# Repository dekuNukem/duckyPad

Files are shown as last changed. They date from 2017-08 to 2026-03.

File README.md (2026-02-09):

# duckyPad: Do-It-All Mechanical Macropad

[Get duckyPad](https://dekunukem.github.io/duckyPad-Pro/doc/landing.html) | [Official Discord](https://discord.gg/4sJCBx5) | [Getting Started](getting_started.md) | [Table of Contents](#table-of-contents)

----

duckyPad is a 15-key **mechanical macropad** for power users who demand **advanced macro scripting and customisation** beyond the shackles of QMK/VIA.

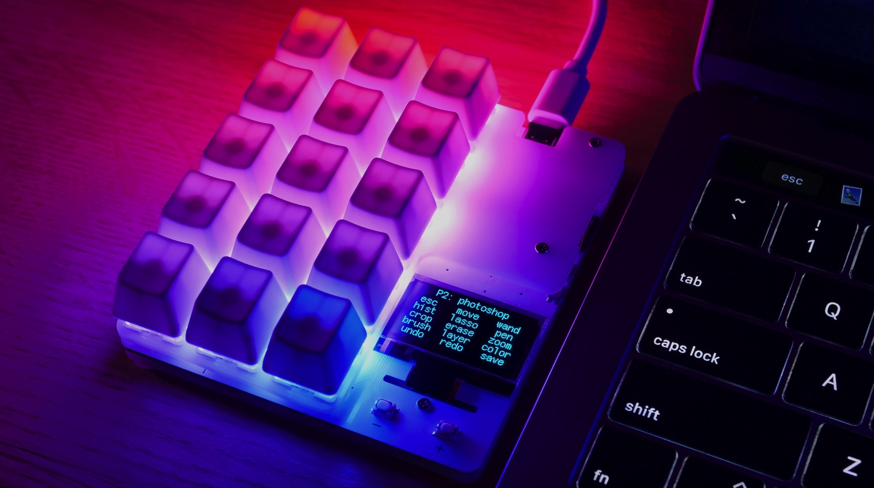
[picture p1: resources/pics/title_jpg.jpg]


Using a [turing-complete scripting language](https://dekunukem.github.io/duckyPad-Pro/doc/duckyscript_info.html), you can automate **any keyboard/mouse input** you want, from **simple combos** to **full-blown programs**.

## Get One

duckyPad was successfully [funded on Kickstarter](https://www.kickstarter.com/projects/dekunukem/duckypad-do-it-all-mechanical-macropad) thanks to the [amazing backers!](kickstarter_backers.md)

* Now Available [on my Tindie Store](https://www.tindie.com/products/dekunukem/duckypad-do-it-all-mechanical-macropad/)

## Highlights

duckyPad has all the basics:

* **Hot-swap**
* Per-key RGB
* Fully **open-source**

But also unique features **not seen anywhere else**:

* Custom **[duckyScript](https://dekunukem.github.io/duckyPad-Pro/doc/duckyscript_info.html)** engine, **NOT QMK/VIA**.
* **Longer and more complex** macros
* **OLED** screen
* **32 profiles** of 15 keys, 480 macros total.
* [Automatic profile switching](https://github.com/dekuNukem/duckyPad-profile-autoswitcher) based on active window.
* microSD storage, move between devices with ease.
* No proprietary drivers, works out-of-box.



## duckyScript vs QMK/VIA

duckyPad uses **duckyScript**, originally designed for [USB Rubber Ducky](https://shop.hak5.org/products/usb-rubber-ducky-deluxe).

Compared to QMK/VIA, you get:

* **Much Longer Macros**
	* [Entire Bee Movie](resources/beemovie.txt) in one macro? Yes please!
	* Up to 480 macros

* **Turing-Complete Scripting**
	* Variables, conditions, loops, functions, and more.
	* Executed on [32-bit Bytecode VM](https://duckypad.github.io/DuckStack/)
	* With **Scratch** and **Non-volatile Memory**

* **Advanced Interactions**
	* Reading Buttons
	* Print to OLED screen
	* Change RGB Color

* **SD Card Storage**
	* Fast Configuration / Backup / Deployment
	* No sketchy drivers or apps
	* No recompiling

While QMK/VIA are great for regular keyboards, they are rather limited at input automations.

duckyScript is a no-brainer for **power users** with more demanding scripting needs.

## 🆕 duckyPad Pro

duckyPad Pro is an updated model with:

* Rotary Encoders
* More Keys
* Bluetooth
* Bigger Display
* More Script Storage
* Expansion Module

👉👉👉 [Purchase Link](https://www.tindie.com/products/37399/) | [More Info](https://dekunukem.github.io/duckyPad-Pro/)

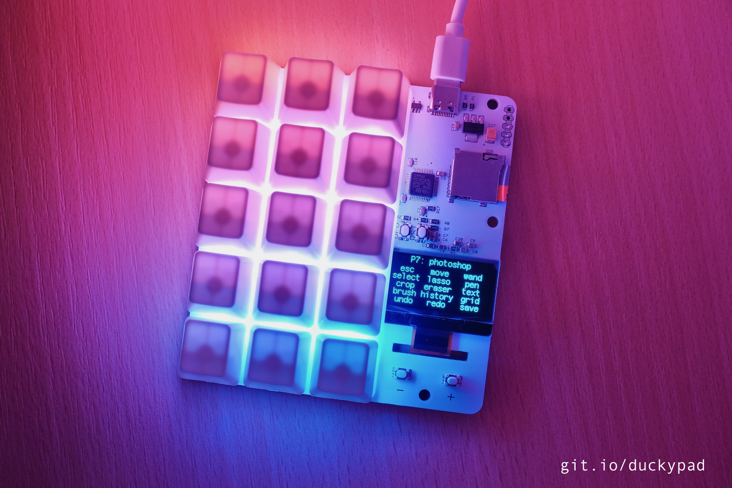
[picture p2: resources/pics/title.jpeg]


## Discord Community

Feel free to join our [Official Discord](https://discord.gg/4sJCBx5) for discussions, questions, sharing scripts, and latest updates!

## How It Works / Showcase

* Create up to **32 profiles**, one for each application.

* Assign up to **15 keys** per profile

* Names are shown on OLED screen

* Write a **duckyScript** for each key

### Easy Start

* **duckyScript** is a language for automating inputs

	* At simplest, you just tell it **what key to press!**

* Such as **key combos** of your favorite app

`CTRL a` , `CTRL +`, etc.



### Up a Notch

* Once familiar, you can write **longer multi-line macros** to further speed up everyday task.

* Such as **filling forms** and typing **boilerplate text** with one keypress.

```
STRING Michael Scott
TAB
STRING United States
ENTER
STRING 5705550100
TAB
STRING michael.scott@dundermifflin.com
TAB
```


Or a simple mouse jiggler:

```
WHILE TRUE
	MOUSE_MOVE $_RANDOM_INT $_RANDOM_INT
	DELAY 100
END_WHILE
```

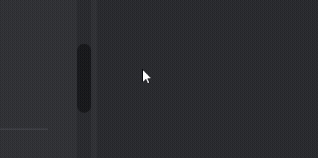
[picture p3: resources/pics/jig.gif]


### Full Potential

* Going all-out, duckyScript is a **Turing-Complete** **general-purpose** language.
* You can use it to:
	* Read Buttons
	* Write to OLED screen
	* Change RGB colors
	* Perform operations with **32-bit variables**, **conditions**, **loops**, **function call**s, and more!
* Write ultra-specific macros for your exact needs

```
RGB_SET 1 128 0 255

OLED_PRINT You are in a maze
OLED_PRINT of twisty little passages

VAR choice = _READKEY

IF choice == 1
    OLED_CURSOR 0 10
    OLED_PRINT It is a dead end.
    OLED_PRINT Something moves
    OLED_PRINT behind you.
END_IF
```

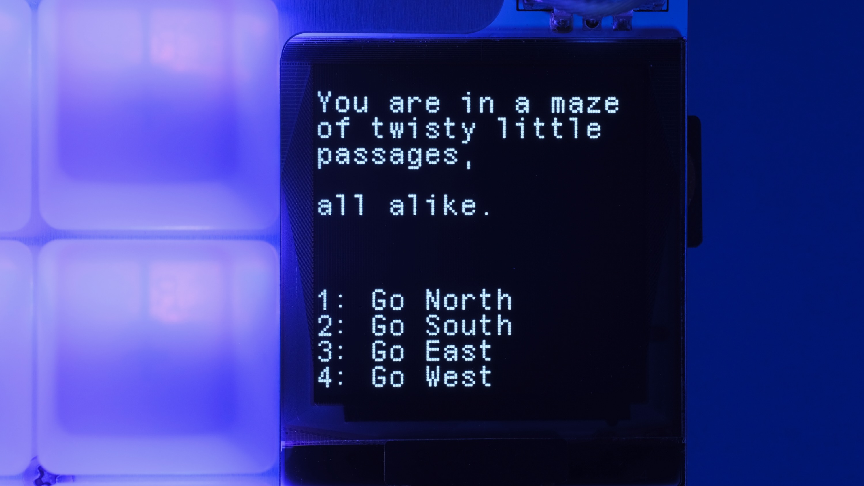
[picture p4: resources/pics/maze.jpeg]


### Hackerman

* Of course, by automating HID inputs, you can take over an entire computer with the push of a button!



* This is known as [BadUSB attack](https://arstechnica.com/information-technology/2014/07/this-thumbdrive-hacks-computers-badusb-exploit-makes-devices-turn-evil/), and was the original purpose of [USB Rubber Ducky](https://shop.hak5.org/products/usb-rubber-ducky-deluxe).

---------

### Nothing Like It

* From **simple shortcuts** to **full-blown programs**, duckyScript can easily achieve what was impossible on QMK/VIA.

* Each macro can contain over **50,000 characters**

* Store **480 macros** in total

* Executed on custom [virtual stack machine](https://duckypad.github.io/DuckStack/)

## Features

### Switches & Keycaps

duckyPad is compatible with Cherry MX-style mechanical switches (3 or 5-pin).

By default, duckyPad comes with blank translucent ABS R4 keycaps:

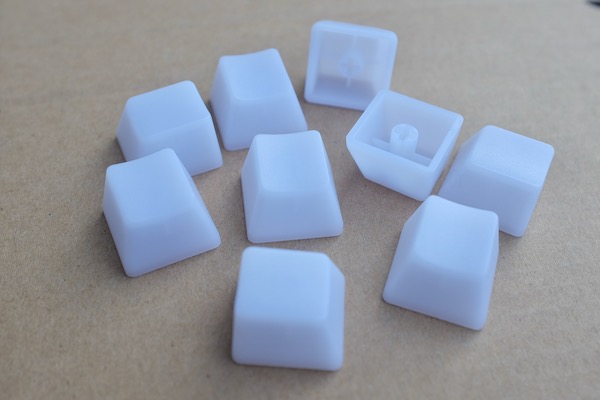
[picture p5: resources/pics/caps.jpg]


You can use your own as well.

### Hot-swap Sockets

duckyPad supports hot-swapping with Kailh sockets.

You can install/remove the switches by hand, **`no soldering needed`**.

### Per-key RGB backlight

Each key on duckyPad has its own RGB backlight. User-configurable colour & brightness.

### OLED screen

duckyPad has an OLED screen. It displays current **`profile and key names`**, so you know what each key does at a glance.

* 128x128
* 1.3 inch
* High contrast with true black
* Burn-in Prevention

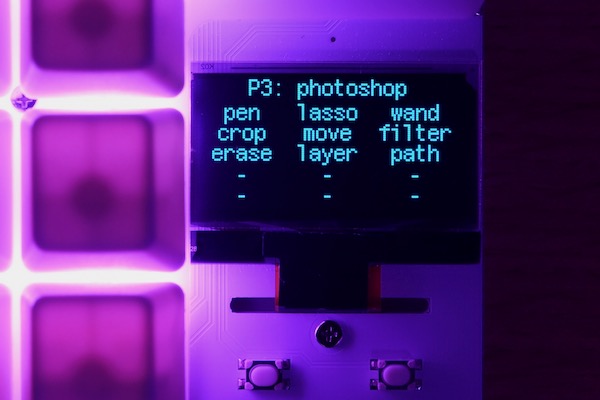
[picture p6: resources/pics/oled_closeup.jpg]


### Companion App

[Use the open-source configurator](https://github.com/duckyPad/duckyPad-Configurator) to set up your duckyPad Pro.

* Windows | Mac | Linux
* No account / subscription needed
* No data collection / telemetry

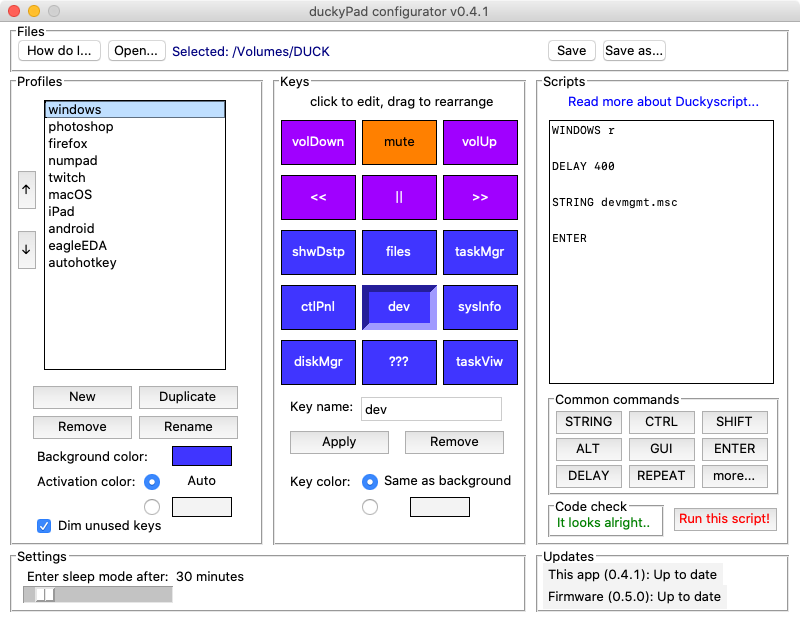
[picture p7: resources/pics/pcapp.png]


## Profile Auto-switching

* [Automatically jump to the appropriate profile](https://github.com/dekuNukem/duckyPad-profile-autoswitcher)
* Based on **current active window**

### USB-C and Device Compatibility

duckyPad uses USB-C connector for maximum device compatibility.

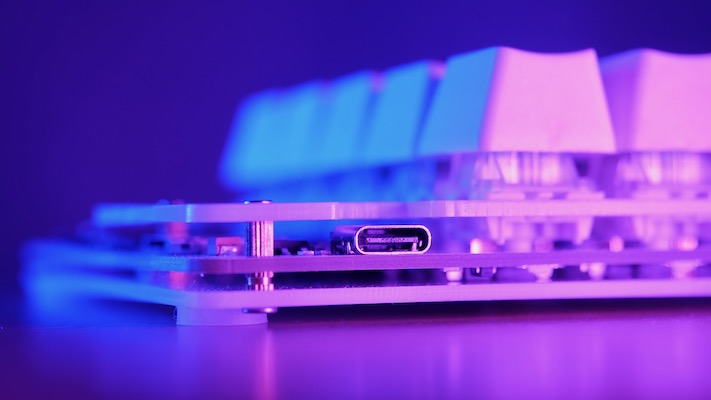
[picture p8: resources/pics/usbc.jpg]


You can use duckyPad out-of-box on pretty much anything that supports USB keyboards, **`no driver needed`**. Examples include:

* PC
* Mac
* Linux
* Raspberry Pi
* iPhone / iPad
* Android phones and tablets
* Chromebooks
* Game consoles

duckyPad’s firmware can also be [easily updated via USB-C](firmware_updates_and_version_history.md) for new features and bug fixes.

### Keyboard Layouts

duckyPad supports multiple keyboard layouts:

* English (US)
* English (UK)
* French
* Belgium
* German
* Dvorak
* ...and more [user-created](keymap_instructions.md) layouts!

### Dimensions

[Click me](pcb/plates) for vector files of front and back plates.

[Click me](resources/pics/dimensions.png) for dimensions drawings.

## Getting Started

Please see [the instruction manual](./getting_started.md) on how to use your duckyPad.

## I Want One!

duckyPad is [now available on Tindie.](https://www.tindie.com/products/21984)

Also consider [joining our discord](https://discord.gg/4sJCBx5) for latest updates and discussions.

## Table of Contents

[Main page](README.md)

[Getting Started Guide](getting_started.md)

[Kit Assembly Guide](kit_assembly_guide.md)

[Using duckyScript](https://dekunukem.github.io/duckyPad-Pro/doc/duckyscript_info.html)

[Common issues / Troubleshooting](troubleshooting.md)

[Firmware Updates and Version History](firmware_updates_and_version_history.md)

[Make Your Own Keymap](./keymap_instructions.md)

[Build a duckyPad Yourself](build_it_yourself.md)

[Kickstarter Backer Acknowledgments](kickstarter_backers.md)

## Questions or Comments?

Please feel free to [open an issue](https://github.com/dekuNukem/duckypad/issues), ask in the [official duckyPad discord](https://discord.gg/4sJCBx5), DM me on discord `dekuNukem#6998`, or email `dekuNukem`@`gmail`.`com` for inquires.

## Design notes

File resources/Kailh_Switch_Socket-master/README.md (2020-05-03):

# Kailh_Switch_Socket
An EAGLE library for the Kailh Switch Socket, allowing you to change your Cherry MX or clone switch from your keyboard without the need of desoldering it.

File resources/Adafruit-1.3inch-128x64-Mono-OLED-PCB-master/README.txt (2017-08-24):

This is the PCB for the Adafruit 128x64 I2C/SPI 1.3" OLED breakout board
Format is EagleCAD schematic and board layout

For more details, check out the product page at

-----> http://www.adafruit.com/products/938

Adafruit invests time and resources providing this open source design, 
please support Adafruit and open-source hardware by purchasing 
products from Adafruit!

Designed by Adafruit Industries.  
Creative Commons Attribution, Share-Alike license, check license.txt for more information
All text above must be included in any redistribution

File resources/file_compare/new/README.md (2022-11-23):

## duckyPad Sample Profiles

To use in duckyPad, copy all the folders here to the root of a FAT32-formatted SD card.

See [this guide](https://github.com/dekuNukem/duckyPad/blob/master/getting_started.md) for more details.

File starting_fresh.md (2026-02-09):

# Starting Fresh with duckyPad (2020)

[Get duckyPad](https://dekunukem.github.io/duckyPad-Pro/doc/landing.html) | [Official Discord](https://discord.gg/4sJCBx5) | [Getting Started](getting_started.md) | [Table of Contents](#table-of-contents)

----

Since its launch in 2020, the original duckyPad has seen several major updates with new features and bug fixes.

This guide shows how to do a **clean upgrade** to the latest version.

## Check Your Duck

This guide is for the **original duckyPad**

* Released in 2020
* Has 15 Keys

## Back up SD Card

* Pop out the SD Card
* Mount on your computer with a card reader
* Copy everything off as-is

## Prepare SD Card

* Format the card in `FAT32`

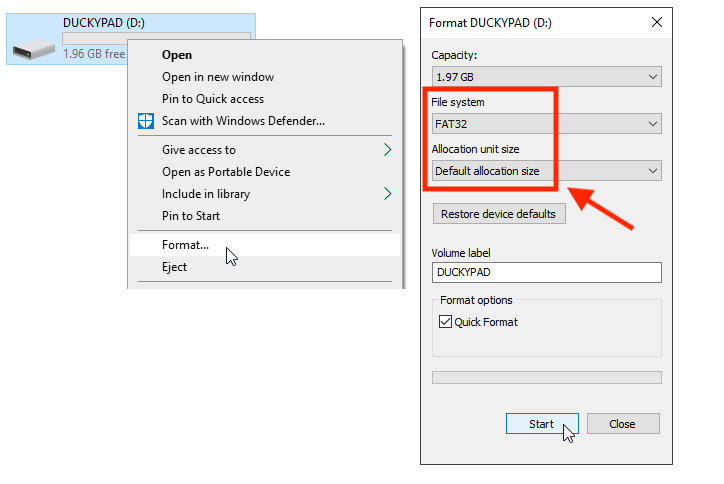
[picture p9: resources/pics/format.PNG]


* Download the [sample profiles](https://github.com/dekuNukem/duckyPad/raw/master/sample_profiles.zip) 

* Unzip and copy everything to the **root of your SD card**:

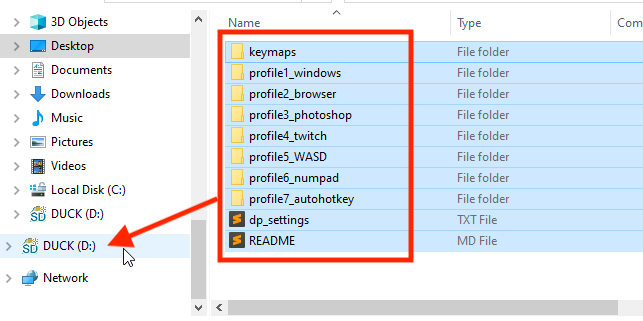
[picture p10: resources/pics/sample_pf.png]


## FW / SW Updates

* Don't touch the SD card for now

* [Follow this guide](https://dekunukem.github.io/duckyPad/firmware_updates_and_version_history.html) to update your duckyPad to latest firmware.

* [Also download the latest configurator](https://github.com/duckyPad/duckyPad-Configurator/releases/latest)

## Try It Out!

* Unmount the SD Card

* Pop it back in duckyPad

* Follow [the latest user guide](https://dekunukem.github.io/duckyPad/getting_started.html) to start using duckyPad again!

## Restore Backup

* If it works with the default sample profiles, you can try to restore the backup.
* Pop out SD card, mount on PC.
* Do another format, copy the backups back.
* Eject, put card back in duckyPad.
* **Load then save again** using the latest configurator.
	* This updates the files on the card
* Try it out!

## Deprecated Commands

If syntax errors pops up, it's likely due to the following changes:

* `HOLD` and `EMUK` command are deprecated
	* Use `KEYDOWN` and `KEYUP` in `on_press` and `on_release` instead.

* [Read more about duckyScript](https://dekunukem.github.io/duckyPad-Pro/doc/duckyscript_info.html)

## How'd It Go?

* If it works, congrats!

* Still wonky? Feel free to ...

	* [Open an issue](https://github.com/dekuNukem/duckypad/issues)
	* Ask in the [official duckyPad discord](https://discord.gg/4sJCBx5)
	* Email `dekuNukem`@`gmail`.`com` .

----

## Table of Contents

[Main page](README.md)

[Getting Started Guide](getting_started.md)

[Kit Assembly Guide](kit_assembly_guide.md)

[Using duckyScript](https://dekunukem.github.io/duckyPad-Pro/doc/duckyscript_info.html)

[Common issues / Troubleshooting](troubleshooting.md)

[Firmware Updates and Version History](firmware_updates_and_version_history.md)

[Make Your Own Keymap](./keymap_instructions.md)

[Build a duckyPad Yourself](build_it_yourself.md)

[Kickstarter Backer Acknowledgments](kickstarter_backers.md)

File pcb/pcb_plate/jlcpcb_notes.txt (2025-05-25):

when making alu PCB:

File top layer is substrate
File bottom layer is bare aluminum

may meed to mirror the design so the correct side is alu

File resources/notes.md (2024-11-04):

http://hackaday.com/2017/05/31/malduino-elite/

15+3+3+4+2+2+1

interrupt add to event queue
main loop get rid of queue item

tangentbord

TODO: TEST 5V LEVEL TRANSLATION OF 74LV125

oh shit the switches might be upside down

card_present low when card is inserted

need to copy hid.c and 2 functions in ff.c

cache profile filename and key filename during load profile

save last profile number to sd card
each key has its own color?

pin 7 should connect to GND
pin 11 BS1 should be high with a resistor
pin 13 15 to GND
add pullup on I2C lines
reset pulled low with resistor

dont forget to add idwg back after everything's done
delay 100ms then reset when card_present changes
tin the under side of the oled ribbon cable

looks like all the probroems were from inconsistent connection between ribbon cable and pcb, tin the pcb thinly as well as the ribbon cable before soldering, use plenty of flux
line up the holes on the pcb with the holes on the ribbon cable, use a small pcb to hold it in place, like exixe 12

i seemlingly solved the ribbon cable connection issue by using low temp solder to wet the underside contacts, remains to be seen how it holds up

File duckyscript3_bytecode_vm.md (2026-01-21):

# duckyScript 3 Bytecode Instruction Set

[Get duckyPad](https://dekunukem.github.io/duckyPad-Pro/doc/landing.html) | [Official Discord](https://discord.gg/4sJCBx5) | [Getting Started](getting_started.md) | [Table of Contents](#table-of-contents)

----
## ⚠️This Page Has Moved!⚠️

👉👉👉👉 [Click Me to See the New Page!](https://dekunukem.github.io/duckyPad-Pro/doc/bytecode_vm.html)

## Table of Contents

[Main page](README.md)

[Getting Started Guide](getting_started.md)

[Kit Assembly Guide](kit_assembly_guide.md)

[Using duckyScript](https://dekunukem.github.io/duckyPad-Pro/doc/duckyscript_info.html)

[Common issues / Troubleshooting](troubleshooting.md)

[Firmware Updates and Version History](firmware_updates_and_version_history.md)

[Make Your Own Keymap](./keymap_instructions.md)

[Build a duckyPad Yourself](build_it_yourself.md)

[Kickstarter Backer Acknowledgments](kickstarter_backers.md)

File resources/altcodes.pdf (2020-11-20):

# ALT CODES REFERENCE SHEET

# Free Download from www.UsefulShortcuts.com (http://www.usefulshortcuts.com/alt-codes)

### Hold down the "Alt" key then enter the code on the numeric keypad with Num Lock on

IM | Numbers | Greek | Currency | ?s and !s | Letters with Accents
Alt 1 | ☺ | Alt 48 - 57 | 0 - 9 | Alt 224 | α | Alt 0164 | ¤ | Alt 33 | ! | Uppercase Lowercase
Alt 2 | ☻ | Basic Operators | Alt 225 | ß | Alt 156 | £ | Alt 19 | ‼ | Alt 0192 À Alt 0224 à
Alt 3 | ♥ | Alt 43 | + | Alt 226 | Γ | Alt 0128 | € | Alt 173 | ¡ | Alt 0193 Á Alt 0225 á
Alt 11 | ♂ | Alt 45 | - | Alt 235 | δ | Alt 36 | $ | Alt 63 | ? | Alt 0194 Â Alt 0226 â
Alt 12 | ♀ | Alt 0215 | × | Alt 238 | ε | Alt 155 | ¢ | Alt 168 | ¿ | Alt 0195 Ã Alt 0227 ã
Alt 13 | ♪ | Alt 0247 | ÷ | Alt 233 | Θ | Alt 157 | ¥ | Brackets | Alt 0196 Ä Alt 0228 ä
Alt 14 | ♫ | Pers | Alt 227 | π | Alt 158 | ₧ | Alt 40 | ( | Alt 0199 Ç Alt 0231 ç
IP | Alt 37 | % | Alt 230 | µ | Alt 159 | ƒ | Alt 41 | ) | Alt 0200 È Alt 0232 è
Alt 0169 | © | Alt 0137 | ‰ | Alt 228 | Σ | Accents | Alt 91 | [ | Alt 0201 É Alt 0233 é
Alt 169 | ® | Bracketing | Alt 229 | σ | Alt 0180 | ´ | Alt 93 | ] | Alt 0202 Ê Alt 0234 ê
Alt 0153 | ™ | Alt Code Symbol | Alt 231 | τ | Alt 0184 | ¸ | Alt 123 | { | Alt 0203 Ë Alt 0235 ë
Filled Arrows | Alt 40 | ( | Alt 232 | Φ | Web Marketing (http://www.profitablewebprojects.com/) | Alt 125 | } | Alt 0204 | Ì | Alt 0236 | ì
Alt 16 | ► | Alt 41 | ) | Alt 237 | φ | by (http://www.profitablewebprojects.com/) | | Editing | | Alt 0205 | Í | Alt 0237 | í
Alt 17 | ◄ | Plus or Minus | Alt 234 | Ω | www.pwp1.com (http://www.profitablewebprojects.com/) | Alt 28 | ∟ | Alt 0206 | Ï | Alt 0238 | î
Alt 254 | ■ | Alt 241 | ± | | | Drawing | | Alt 21 | § | Alt 0207 | Ï | Alt 0239 | ï
Alt 30 | ▲ | Fractions | | Alt 176 | ░ | Alt 200 | ╚ | Alt 20 | ¶ | Alt 165 | Ñ | Alt 164 | ñ
Alt 31 | ▼ | Alt 47 | / | Alt 177 | ▒ | Alt 201 | ╔ | Alt 0134 | † | Alt 0210 Ò Alt 0242 ò
Line Arrows | Alt 0188 | ¼ | Alt 178 | ▓ | Alt 202 | ╩ | Alt 0135 | ‡ | Alt 0211 Ó Alt 0243 ó
Alt 23 | ↨ | Alt 0189 | ½ | Alt 179 | │ | Alt 203 | ╦ | Quotes | Alt 0212 Ô Alt 0244 ô
Alt 24 | ↑ | Alt 0190 | ¾ | Alt 180 | ┤ | Alt 204 | ╠ | Alt 34 | " | Alt 0213 Õ Alt 0245 õ
Alt 25 | ↓ | Alt 46 | . | Alt 181 | ╡ | Alt 205 | ═ | Alt 0139 | ‹ | Alt 0214 Ö Alt 0246 ö
Alt 26 | → | Equality | Alt 182 | ╢ | Alt 206 | ╬ | Alt 0155 | › | Alt 0138 Š Alt 0154 š
Alt 27 | ← | Alt 240 | ≡ | Alt 183 | ╖ | Alt 207 | ╧ | Alt 0145 | ‘ | Alt 0218 Ú Alt 0249 ú
Bullets | Alt 61 | = | Alt 184 | ╕ | Alt 208 | ╨ | Alt 0146 | ’ | Alt 0219 Û Alt 0250 û
Alt 3 | ♥ | Alt 247 | ≈ | Alt 185 | ╣ | Alt 209 | ╤ | Alt 0147 | “ | Alt 0220 Ü Alt 0251 ü
Alt 4 | ♦ | Inequality | Alt 186 | ║ | Alt 210 | ╥ | Alt 0148 | ” | Alt 0217 Ù Alt 0252 ù
Alt 5 | ♣ | Alt 60 | < | Alt 187 | ╗ | Alt 211 | ╙ | Alt 174 | « | Alt 0221 Ý Alt 0253 ý
Alt 6 | ♠ | Alt 62 | > | Alt 188 | ╝ | Alt 212 | ╘ | Alt 175 | » | Alt 0159 Ÿ Alt 0255 ÿ
Alt 7 | • | Alt 242 | ≥ | Alt 189 | ╜ | Alt 213 | ╒ | Alt 0130 | ‘ | Alt 0142 Ž Alt 0158 ž
Alt 8 | ◘ | Alt 243 | ≤ | Alt 190 | ╛ | Alt 214 | ╓ | Alt 0132 | „ | "Extra" Letters
Alt 9 | ○ | Powers | Alt 191 | ┐ | Alt 215 | ╫ | Abbrevs. | Uppercase Lowercase
Alt 10 | ◙ | Alt 251 | √ | Alt 192 | └ | Alt 216 | ╪ | Alt 39 | ' | Alt 0229 å Alt 0197 Å
Alt 11 | ♂ | Alt 252 | ⁿ | Alt 193 | ┴ | Alt 217 | ┘ | Alt 96 | ` | Alt 0140 Œ Alt 0156 œ
Alt 12 | ♀ | Alt 0185 | ¹ | Alt 194 | ┬ | Alt 218 | ┌ | Alt 38 | & | Alt 0254 þ Alt 0222 Þ
Alt 13 | ♪ | Alt 0178 | ² | Alt 195 | ├ | Alt 219 | █ | Alt 64 | @ | Alt 0216 Ø Alt 0248 ø
Alt 14 | ♫ | Alt 0179 | ³ | Alt 196 | ─ | Alt 220 | ▄ | Alt 0198 Æ Alt 0230 æ
Alt 16 | ► | Angles/Trig | Alt 197 | ┼ | Alt 221 | ▌ | Alt 164 | ñ | Alt 165 | Ñ
Alt 17 | ◄ | Alt 227 | π | Alt 198 | ╞ | Alt 222 | ▐ | Alt 0223 ß
Alt 254 | ■ | Alt 248 | ° | Alt 199 | ╟ | Alt 223 | ▀ | Alt 0208 Ð Alt 0240 ð
Alt 30 | ▲ | General Maths | General Punctuation | Coding
Alt 31 | ▼ | Alt 35 | # | Alt 58 | : | Alt 0133 | … | Alt 45 | - | Alt 0166 | ¦ | Alt 92 | \
Alt 23 | ↨ | Alt 236 | ∞ | Alt 59 | ; | Alt 95 | _ | Alt 0151 | — | Alt 40 | ( | Alt 35 | #
Alt 24 | ↑ | Alt 230 | µ | Alt 44 | , | Alt 0175 | ¯ | Alt 22 | ▬ | Alt 41 | ) | Alt 40 | (
Alt 25 | ↓ | Alt 228 | Σ | Alt 46 | . | Alt 124 | | | Alt 42 | * | Alt 94 | ^ | Alt 41 | )
Alt 26 | → | Alt 239 | ∩ | Alt 32 | | Alt 126 | ~ | Alt 47 | / | Alt 60 | < | Alt 64 | @
Alt 27 | ← | | | Alt 255 | | Alt 0168 | ¨ | Alt 92 | \ | Alt 62 | > | Alt 91 | [
Alt 0129 Box | Cardinals | Miscellaneous | Alt 61 | = | Alt 93 | ]
Alt 15 | ☼ | Alt 166 | ª | Alt 65 - 90 | | A to Z | | Alt 249 | · | Alt 42 | * | Alt 123 | {
127 | ⌂ | Alt 167 | º | Alt 97 - 122 | a to z | Alt 250 | · | Alt 47 | / | Alt 125 | }
Alt 18 | ↕ | Interpunct | Alt 244 | ⌠ | Alt 170 | ¬ | Copyright ©2006
Tim Woolfson (http://www.timwoolfson.com/) Alt 29 | ↔ | Alt 0183 | · | Alt 245 | ⌡

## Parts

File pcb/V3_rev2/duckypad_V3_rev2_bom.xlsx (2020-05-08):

Qty | Value | Device | Parts
4 | 1uF | 0805 Capacitor | C3, C4, C6, C28
3 | 2.2uF | 0805 Capacitor | C5, C7, C8
4 | 5.1K | 0805 Resistor | R1, R7, R8, R9
4 | 10K | 0805 Resistor | R2, R4, R5, R17
1 | 47uF | 1210 Tantalum Capacitor | C27
1 |  | 74LVC1G08 | IC3
20 | 100nF | 0805 Capacitor | C1, C2, C9, C10, C11, C12, C13, C14, C15, C16, C17, C18, C19, C20, C21, C22, C23, C24, C25, C29
4 |  | Tactile Switch | SW1, SW2, SW3, SW4
1 | 560K | 0805 Resistor | R3
15 |  | CherryMX-style Key Switch | S1, S2, S3, S4, S5, S6, S7, S8, S9, S10, S11, S12, S13, S14, S15
1 | 3.3V | 1117 Regulator | IC2
1 |  | STM32F072C8T6 | IC1
1 |  | MicroSD Sard Holder | SD1
1 |  | 30 pin FPC Connecter for OLED, Upper Contact | U1
1 |  | USB-C Connector 16Pin | U2
15 |  | SK6812 MINI-E reverse mount RGB LED | LED1, LED2, LED3, LED4, LED5, LED6, LED7, LED8, LED9, LED10, LED11, LED12, LED13, LED14, LED15
15 |  | Kailh Hot-swap Sockets

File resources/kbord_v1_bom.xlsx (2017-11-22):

Part | Value | Device | Package | Description | Link
C1 | 0.1uF | CAP0805 | 0805 | Capacitor
C2 | 0.1uF | CAP0805 | 0805 | Capacitor
C3 | 1uF | CAP0805 | 0805 | Capacitor
C4 | 1uF | CAP0805 | 0805 | Capacitor
C5 | 2.2uF | CAP0805 | 0805 | Capacitor
C6 | 1uF | CAP0805 | 0805 | Capacitor
C7 | 1uF | CAP0805 | 0805 | Capacitor
C8 | 2.2uF | CAP0805 | 0805 | Capacitor
C9 | 0.1uF | CAP0805 | 0805 | Capacitor
C10 | 0.1uF | CAP0805 | 0805 | Capacitor
C11 | 0.1uF | CAP0805 | 0805 | Capacitor
C12 | 0.1uF | CAP0805 | 0805 | Capacitor
C13 | 0.1uF | CAP0805 | 0805 | Capacitor
C14 | 0.1uF | CAP0805 | 0805 | Capacitor
C15 | 0.1uF | CAP0805 | 0805 | Capacitor
C16 | 0.1uF | CAP0805 | 0805 | Capacitor
C17 | 0.1uF | CAP0805 | 0805 | Capacitor
C18 | 0.1uF | CAP0805 | 0805 | Capacitor
C19 | 0.1uF | CAP0805 | 0805 | Capacitor
C20 | 0.1uF | CAP0805 | 0805 | Capacitor
C21 | 0.1uF | CAP0805 | 0805 | Capacitor
C22 | 0.1uF | CAP0805 | 0805 | Capacitor
C23 | 0.1uF | CAP0805 | 0805 | Capacitor
C24 | 0.1uF | CAP0805 | 0805 | Capacitor
C25 | 0.1uF | CAP0805 | 0805 | Capacitor
C27 | 47uF | C-USC1210 | C1210 | Tantalum Capacitor
IC1 | STM32F072C8T6 | STM32F072C8T6 | TQFP48 | ST STM32F072 48pin LQFP
IC2 | REG1117 | REG1117 | SOT223 | LM1117 or AMS1117 or basically any 1117 regulator, 3.3V
IC3 | SN74LVC1G08 | 74LVC1G08 | SOT23-5 | Single 2-input AND gate
JP1 | Pin Header | PINHD-1X5 | 1X05 | PIN HEADER, male, single row
LED1 | SK6812-3535 | SK6812-3535 | LED3535 | SK6812 3535 package
LED2 | SK6812-3535 | SK6812-3535 | LED3535 | SK6812 3535 package
LED3 | SK6812-3535 | SK6812-3535 | LED3535 | SK6812 3535 package
LED4 | SK6812-3535 | SK6812-3535 | LED3535 | SK6812 3535 package
LED5 | SK6812-3535 | SK6812-3535 | LED3535 | SK6812 3535 package
LED6 | SK6812-3535 | SK6812-3535 | LED3535 | SK6812 3535 package
LED7 | SK6812-3535 | SK6812-3535 | LED3535 | SK6812 3535 package
LED8 | SK6812-3535 | SK6812-3535 | LED3535 | SK6812 3535 package
LED9 | SK6812-3535 | SK6812-3535 | LED3535 | SK6812 3535 package
LED10 | SK6812-3535 | SK6812-3535 | LED3535 | SK6812 3535 package
LED11 | SK6812-3535 | SK6812-3535 | LED3535 | SK6812 3535 package
LED12 | SK6812-3535 | SK6812-3535 | LED3535 | SK6812 3535 package
LED13 | SK6812-3535 | SK6812-3535 | LED3535 | SK6812 3535 package
LED14 | SK6812-3535 | SK6812-3535 | LED3535 | SK6812 3535 package
LED15 | SK6812-3535 | SK6812-3535 | LED3535 | SK6812 3535 package
R2 | 10k | RESISTOR0805-RES | 0805 | Resistor
R3 | 560K | RESISTOR0805-RES | 0805 | Resistor
R4 | 10k | RESISTOR0805-RES | 0805 | Resistor
R5 | 10k | RESISTOR0805-RES | 0805 | Resistor
R6 | 300 | RESISTOR0805-RES | 0805 | Resistor
R7 | 4K7 | RESISTOR0805-RES | 0805 | Resistor
R8 | 4K7 | RESISTOR0805-RES | 0805 | Resistor
R17 | 10K | RESISTOR0805-RES | 0805 | Resistor
S1 | MOMENTARY-SWITCH-SPST-LED-PTH-CHERRY | Gateron RGB switch | CHERRY-MX-LED | Momentary Switch (Pushbutton) | https://www.aliexpress.com/store/product/20pcs-Gateron-RGB-Switches-MX-for-DIY-Mechanical-Gaming-Keyboard/914660_32709013852.html
S2 | Gateron RGB switch | Gateron RGB switch | CHERRY-MX-LED | Momentary Switch (Pushbutton)
S3 | Gateron RGB switch | Gateron RGB switch | CHERRY-MX-LED | Momentary Switch (Pushbutton)
S4 | Gateron RGB switch | Gateron RGB switch | CHERRY-MX-LED | Momentary Switch (Pushbutton)
S5 | Gateron RGB switch | Gateron RGB switch | CHERRY-MX-LED | Momentary Switch (Pushbutton)
S6 | Gateron RGB switch | Gateron RGB switch | CHERRY-MX-LED | Momentary Switch (Pushbutton)
S7 | Gateron RGB switch | Gateron RGB switch | CHERRY-MX-LED | Momentary Switch (Pushbutton)
S8 | Gateron RGB switch | Gateron RGB switch | CHERRY-MX-LED | Momentary Switch (Pushbutton)
S9 | Gateron RGB switch | Gateron RGB switch | CHERRY-MX-LED | Momentary Switch (Pushbutton)
S10 | Gateron RGB switch | Gateron RGB switch | CHERRY-MX-LED | Momentary Switch (Pushbutton)
S11 | Gateron RGB switch | Gateron RGB switch | CHERRY-MX-LED | Momentary Switch (Pushbutton)
S12 | Gateron RGB switch | Gateron RGB switch | CHERRY-MX-LED | Momentary Switch (Pushbutton)
S13 | Gateron RGB switch | Gateron RGB switch | CHERRY-MX-LED | Momentary Switch (Pushbutton)
S14 | Gateron RGB switch | Gateron RGB switch | CHERRY-MX-LED | Momentary Switch (Pushbutton)
S15 | Gateron RGB switch | Gateron RGB switch | CHERRY-MX-LED | Momentary Switch (Pushbutton)
S16 | ENCODER-SWITCH | ENCODER-SWITCH | ROTARY_ENC_PLAIN | Rotary Encoder w/ Select Switch
S17 | ENCODER-SWITCH | ENCODER-SWITCH | ROTARY_ENC_PLAIN | Rotary Encoder w/ Select Switch
S19 | TAC_SWITCHSMD | TAC_SWITCHSMD | TACTILE-SWITCH-SMD | Momentary Switch | https://www.sparkfun.com/products/8720
S20 | TAC_SWITCHSMD | TAC_SWITCHSMD | TACTILE-SWITCH-SMD | Momentary Switch
S21 | TAC_SWITCHSMD | TAC_SWITCHSMD | TACTILE-SWITCH-SMD | Momentary Switch
S22 | TAC_SWITCHSMD | TAC_SWITCHSMD | TACTILE-SWITCH-SMD | Momentary Switch
SD1 | MicroSD holder | MicroSD holder | TF-PULL | PUSH-PUSH Micro SD socket | https://www.ebay.co.uk/itm/10pc-8-pin-MICRO-SD-card-TF-Card-Holder-Memory-Card-Slot-Connector-Socket-UK/362049456250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
U1 | OLED | OLED | OLED display | 0.96 or 1.3 inch OLED display with SSD1306 controller, try finding one without a divider in the middle | https://www.ebay.co.uk/itm/0-96-1-3-Inch-IIC-SPI-Serial-128X64-OLED-LCD-Display-SSD1306-Module-for-Arduino/372062929006
X1 | USB-MICROB | USB-MICROB | USB-MICROB | USB Connectors | https://www.mouser.co.uk/ProductDetail/Hirose-Connector/ZX62D-B-5PA830/
 |  |  |  |  | Provided links are for examples only, you dont have to buy from them
 |  |  |  |  | rest of them can be easily found on mouser

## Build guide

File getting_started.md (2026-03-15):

# Getting Started with duckyPad

[Get duckyPad](https://dekunukem.github.io/duckyPad-Pro/doc/landing.html) | [Official Discord](https://discord.gg/4sJCBx5) | [Getting Started](getting_started.md) | [Table of Contents](#table-of-contents)

------

Congratulations on your new toy! Here is a short guide on how to use your duckyPad.

## Join Our Discord!

Feel free to join our [Official Discord](https://discord.gg/4sJCBx5) for discussions, questions, sharing scripts, and latest updates!

## Kit Assembly

👇👇👇👇👇👇👇👇👇👇

[See this guide](./kit_assembly_guide.md) to put your duckyPad together!

☝️☝️☝️☝️☝️☝️☝️☝️☝️☝️

## Quick Start

Plug into your computer, and voilà:

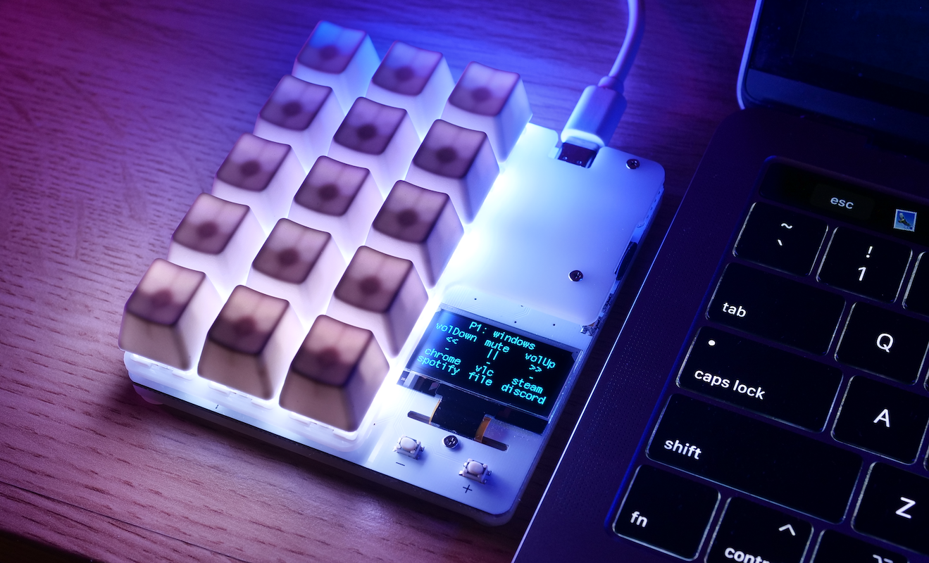
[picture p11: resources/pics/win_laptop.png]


* **`Hold down`** `+` button for settings



* Select the correct **keyboard region**

	* Adjust others to your liking

* To save & exit, **press any unlit key**.

* ⚠️ Start with the `Welcome` profile

	* Press a key to execute script

* Press `+` and `-` to switch profiles.

## Help! It's not working!

Are you using **`AMD motherboard?`** If so, read about the [USB chipset bug here!](https://www.tomshardware.com/uk/news/amd-suggest-possible-fixes-for-usb-connectivity-issues)

Try using a **USB hub**, update chipset drivers, or different ports.

For other issues, check out the [troubleshooting guide](troubleshooting.md).

## Writing Your Own Scripts

After playing with examples and see what duckyPad can do, time to write your own!

### Download Configurator

#### Windows

[Download the latest configurator here](https://github.com/duckyPad/duckyPad-Configurator/releases/latest)

Unzip and launch by clicking `duckypad_config.exe`:



Windows might complain about unsigned app.

Click `More info` and then `Run anyway`.

Feel free to [review the files](https://github.com/duckyPad/duckyPad-Configurator), or run the source code directly with Python.

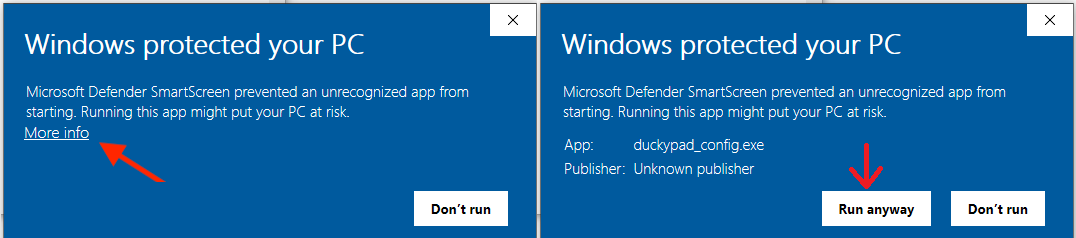
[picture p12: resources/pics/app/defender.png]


#### MacOS & Linux

[See instruction here!](https://dekunukem.github.io/duckyPad-Pro/doc/linux_macos_notes.html)

### Using Configurator

Press the `Connect` button near top left.



Everything should load up in a few seconds.

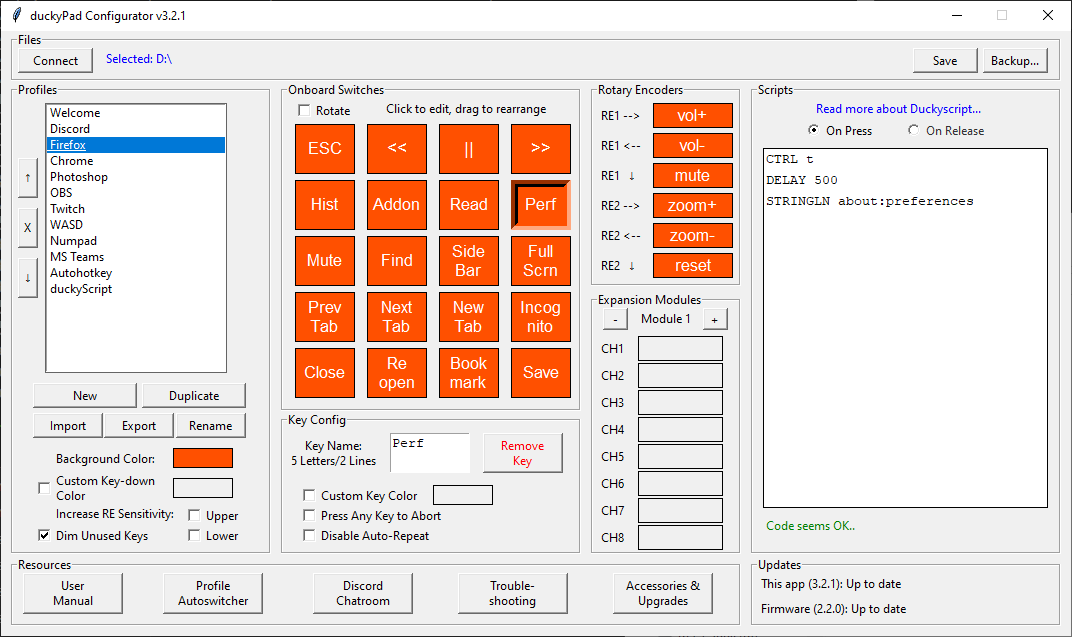
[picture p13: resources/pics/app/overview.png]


It may seem complex at first, let's break it down!

### Profiles

* The leftmost column is for *profiles*.

* You typically create one for **each app** you want to control.

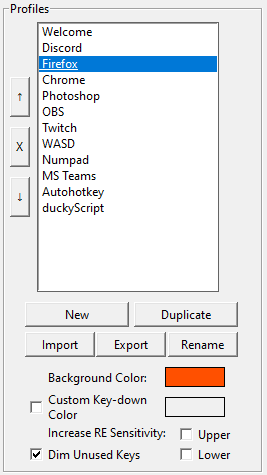
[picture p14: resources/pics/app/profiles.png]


Let's make a new profile!

Click `New` button, give it a name.



* Choose a background color for the RGB backlight.

* Use the `up/down/x` buttons to reorder/delete profiles.

----

* `Keydown color` is the color that a key changes into when you press it.
	* Default is the inverse of background color
	* You can also set your own

### Keys

The middle columns are for *keys*:

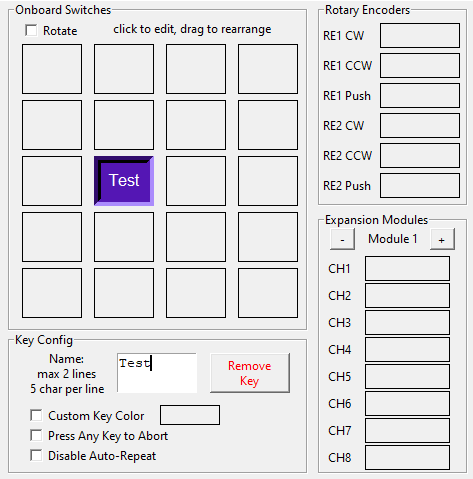
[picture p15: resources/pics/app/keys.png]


* Select an empty key in the `Onboard Switches` section
* Type to give it a name
* Drag to rearrange

---------

* **`Custom Key Color`**: Set an unique color.
* **`Press Any Key to Abort`**: Allow exiting early in long macros.
	* Do not select if you're writing your own button-checking code
* **`Disable Auto-Repeat`**: Macro won't repeat when key is held down.
* Click **`Rotate`** for landscape mode.

### Scripts

Finally, the rightmost column is for *scripts*:

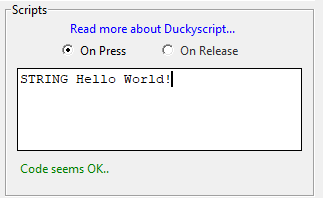
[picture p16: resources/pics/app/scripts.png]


* This shows the **duckyScript** that the key will execute.

	* Can be anything from simple shortcuts to full-blown programs!

	* [**Read about detailed usage here**](https://dekunukem.github.io/duckyPad-Pro/doc/duckyscript_info.html).

	* For this example, put in `STRING Hello World!`

* Separate scripts possible for **On Press** and **On Release**

	* If not sure, just leave **On Release** blank.

* Code check will be performed as you type.

### Remember to Save!

* Press `Save` button to write the changes back to duckyPad.
* Check debug window for progress

### Try It Out!

duckyPad should reboot after saving.

Press `+/-` button to go to the new profile, and press the key.

It should execute the script and type out `Hello World!`:



That's it! Now you know how to customise your duckyPad!

🎉 🎉 Great Job, but we're not done yet!

⚠️⚠️ **Please keep reading** for more useful information!

------------

### Profile Auto-Switching

duckyPad can **switch profiles automatically** based on **current active window**.

[Click me for details](https://github.com/dekuNukem/duckyPad-profile-autoswitcher)

### Careful with Passwords!

It might be tempting to have duckyPad type out passwords, but beware that all scripts are stored as **plain text** on SD card. Not a good idea!

### Automatic backups

* A local backup is created every time you save.
* Press `Backup...` button to access the backups.
* To restore, [format the SD card in FAT or FAT32](resources/pics/app/format.png), then copy everything back.

## Tips and Tricks

### Keyboard Shortcuts

The most obvious use case is putting your commonly used hotkeys on duckyPad!

For many applications, you can find an official list of shortcuts. Just search `app_name shortcuts` on Google. Examples:

[Firefox](https://support.mozilla.org/en-US/kb/keyboard-shortcuts-perform-firefox-tasks-quickly) and [Chrome](https://support.google.com/chrome/answer/157179?co=GENIE.Platform%3DDesktop)

[Windows](https://support.microsoft.com/en-gb/help/12445/windows-keyboard-shortcuts) and [macOS](https://support.apple.com/en-gb/HT201236)

[Word](https://support.microsoft.com/en-us/office/keyboard-shortcuts-in-word-95ef89dd-7142-4b50-afb2-f762f663ceb2), [Excel](https://support.microsoft.com/en-us/office/keyboard-shortcuts-in-excel-1798d9d5-842a-42b8-9c99-9b7213f0040f), [PowerPoint](https://support.microsoft.com/en-us/office/use-keyboard-shortcuts-to-create-powerpoint-presentations-ebb3d20e-dcd4-444f-a38e-bb5c5ed180f4), and other [Office apps](https://support.microsoft.com/en-us/office/keyboard-shortcuts-in-office-e765366f-24fc-4054-870d-39b214f223fd).

[Photoshop](https://helpx.adobe.com/uk/photoshop/using/default-keyboard-shortcuts.html), [Final Cut Pro](https://support.apple.com/en-gb/guide/final-cut-pro/ver90ba5929/mac), and [Premiere Pro](https://helpx.adobe.com/uk/premiere-pro/using/keyboard-shortcuts.html).

### Launching Apps on Windows - Task Bar

Another popular usage is launching apps. The easiest way is using Task Bar:

Find the app, `Right click -> More -> Pin to taskbar`:

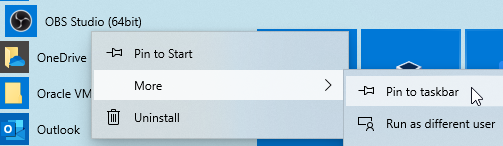
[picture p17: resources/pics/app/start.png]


Now you can use `WIN + number` to launch them:

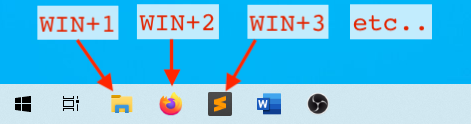
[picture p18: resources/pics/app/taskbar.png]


In duckyScript, it would be `WINDOWS 1`, `WINDOWS 2`, etc.

### Launching Apps on Windows - Shortcuts

This method works with **`ANY FILE`**, not just apps!

`Right click` on any file, select `Create shortcut`.

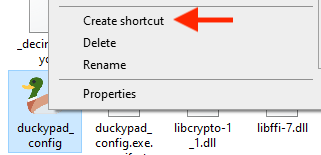
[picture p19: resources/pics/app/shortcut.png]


Find the new shortcut, right click and select `Properties`

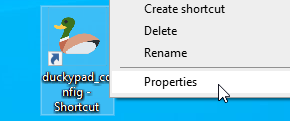
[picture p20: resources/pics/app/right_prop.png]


Set a hotkey in the `Shortcut Key` box:



Then assign the combo on duckyPad!

In this case, the duckyScript would be `CONTROL ALT D`.

### Launching Apps on macOS

Easiest way: Invoke Spotlight and type the application name.

```
COMMAND SPACE
DELAY 500
STRING firefox
ENTER
```

You can also use third-party softwares such as [BetterTouchTool](https://folivora.ai).

### Advanced Scripting with Autohotkey

You can use the free and open-source [Autohotkey](https://www.autohotkey.com) for even more advanced scripting needs.

duckyPad can press a simple combo like `WIN + F1`, which triggers Autohotkey to execute a more complex script on your PC.

* Download and install [Autohotkey](https://www.autohotkey.com)

* Download and save the [sample Autohotkey script](./resources/duckypad_autohotkey_script.ahk) as an `.ahk` file.

* Activate the script by right clicking and select `Run Script`.

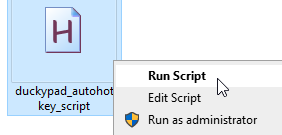
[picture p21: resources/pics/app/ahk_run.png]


* Switch to `Autohotkey` profile, press a key.

* Corresponding message box will appear.

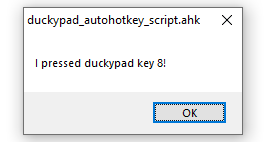
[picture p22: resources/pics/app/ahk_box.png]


* Write your own AHK script!

Check out the [official tutorials](https://www.autohotkey.com/docs/v2/howto/Install.htm), and how to [launch AHK on startup](https://www.autohotkey.com/docs/FAQ.htm#Startup).

## I'm Having Issues!

Please take a look at the [Common issues / Troubleshooting](troubleshooting.md) guide.

If that doesn't help, feel free to contact me by [opening an issue](https://github.com/dekuNukem/duckypad/issues) or ask in the [official duckyPad discord](https://discord.gg/4sJCBx5).

## USB Firmware Updates

You can update duckyPad's firmware for new features and bug fixes. 

[Please see this guide](./firmware_updates_and_version_history.md).

## Table of Contents

[Main page](README.md)

[Getting Started Guide](getting_started.md)

[Kit Assembly Guide](kit_assembly_guide.md)

[Using duckyScript](https://dekunukem.github.io/duckyPad-Pro/doc/duckyscript_info.html)

[Common issues / Troubleshooting](troubleshooting.md)

[Firmware Updates and Version History](firmware_updates_and_version_history.md)

[Make Your Own Keymap](./keymap_instructions.md)

[Build a duckyPad Yourself](build_it_yourself.md)

[Kickstarter Backer Acknowledgments](kickstarter_backers.md)

## Questions or Comments?

Please feel free to [open an issue](https://github.com/dekuNukem/duckypad/issues), ask in the [official duckyPad discord](https://discord.gg/4sJCBx5), DM me on discord `dekuNukem#6998`, or email `dekuNukem`@`gmail`.`com` for inquires.

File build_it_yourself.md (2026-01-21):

# Make a duckyPad Yourself!

[Get duckyPad](https://dekunukem.github.io/duckyPad-Pro/doc/landing.html) | [Official Discord](https://discord.gg/4sJCBx5) | [Getting Started](getting_started.md) | [Table of Contents](#table-of-contents)

------

Unless you have prior experience with PCB assembly and already have the equipments, it is most likely cheaper to just [get one ready-made](https://www.tindie.com/products/21984/), but if you fancy a challenge, read on!

If you are handy with PCBs and surface mount soldering, you can make a duckyPad yourself!

* [PCB files](pcb)

* [BOM](https://docs.google.com/spreadsheets/d/e/2PACX-1vT7gMnYGDWy0Lo6eYjwrsN8QOGCtDGLZ2JMhllytPXIBBvnaAoaImIb5qIXtS9drMGxFIuWi2RhF3QB/pubhtml)

Some things to keep in mind:

## Circuit board

The board is a simple 2-layer board. Don't forget the cutout for the OLED screen in the milling layer!

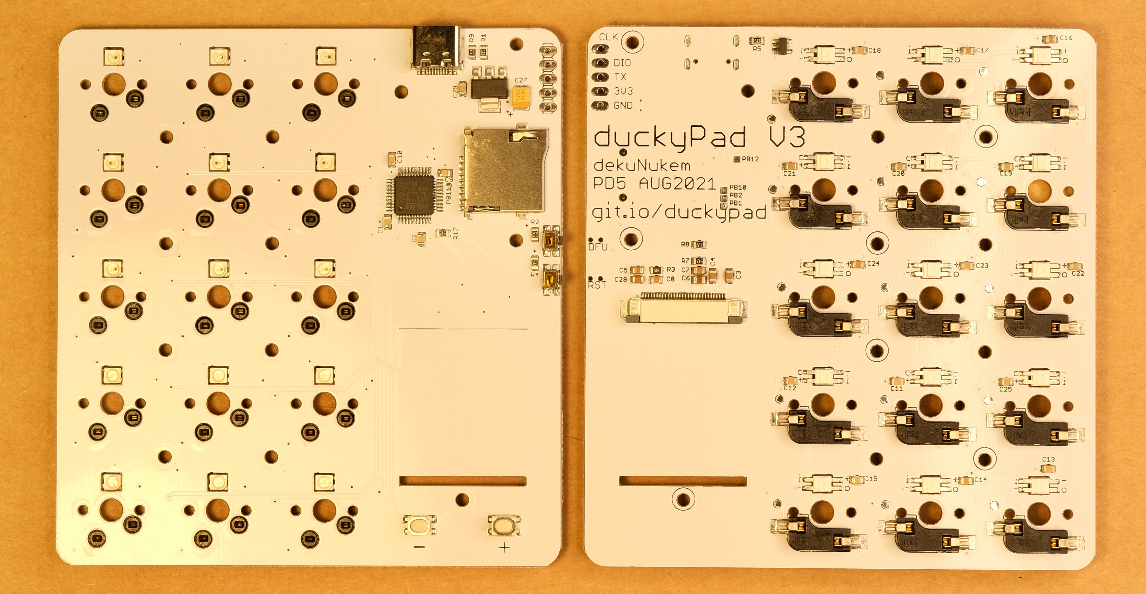
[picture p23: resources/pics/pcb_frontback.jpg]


## RGB LED

The RGB LED is [SK6812 MINI-E](https://hackaday.com/2020/01/28/new-part-day-sk6812-mini-e-a-hand-solderable-neopixel-compatible-led/). 

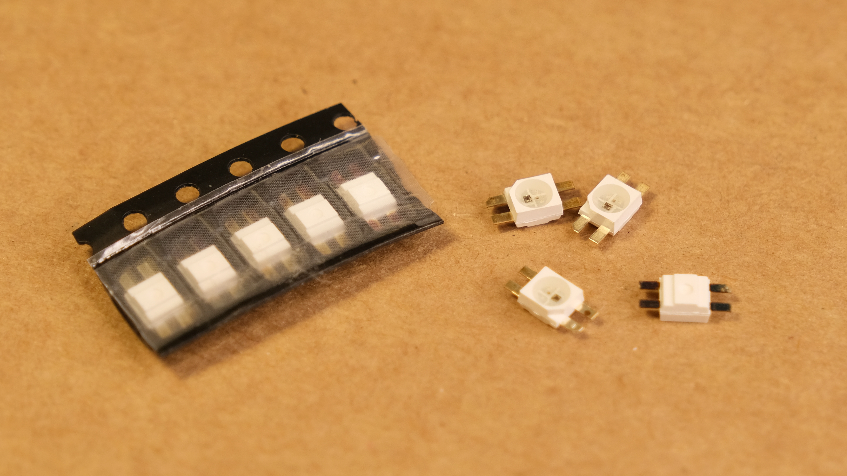
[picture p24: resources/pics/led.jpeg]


It is **reverse mount**, and pay attention to the orientation!

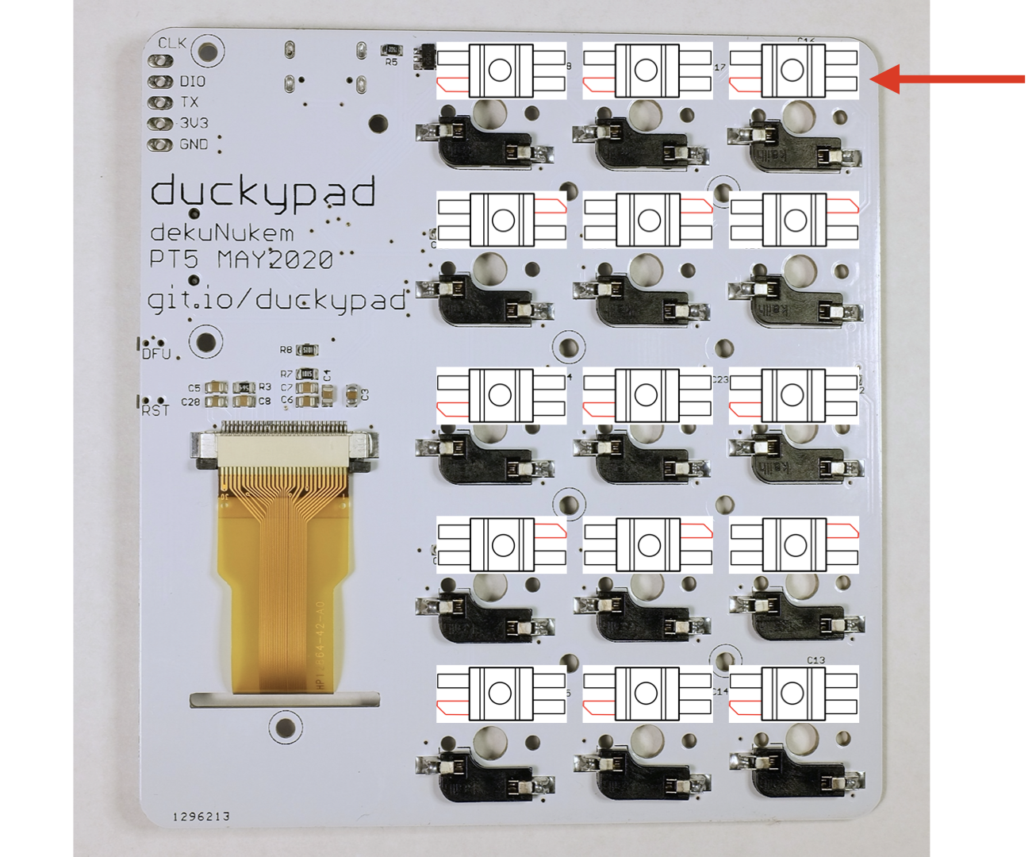
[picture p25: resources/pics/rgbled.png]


## Switches

In theory you can use any cherry MX style switches you like, however, because there are backlights underneath, it's best if you can find one that lets the light shine through.

I've used Gateron RGB and Kalih BOX switches, they are both perfectly designed for this kind of usage, translucent case with large opening for LED. I like them clicky, but there are plenty of colors to choose from.

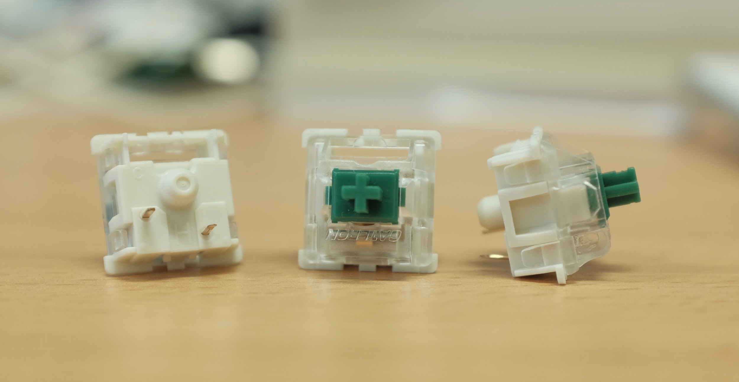
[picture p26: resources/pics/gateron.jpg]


## Hot Swap Sockets

I used Kalih hot-swap sockets for Cherry MX switches:

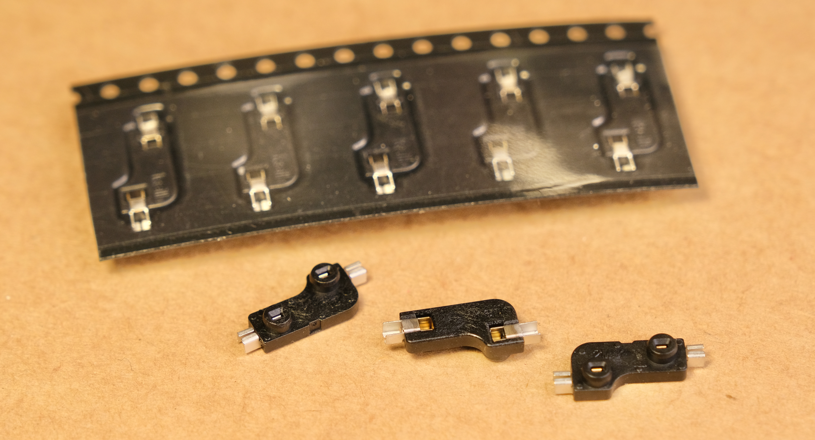
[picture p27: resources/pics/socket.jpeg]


## Mounting Plates

[Click me](pcb/plates) for vector files of front and back plates.

[Click me](resources/pics/dimensions.png) for dimensions drawings.

You can have them made in laser-cut acrylic or metal.

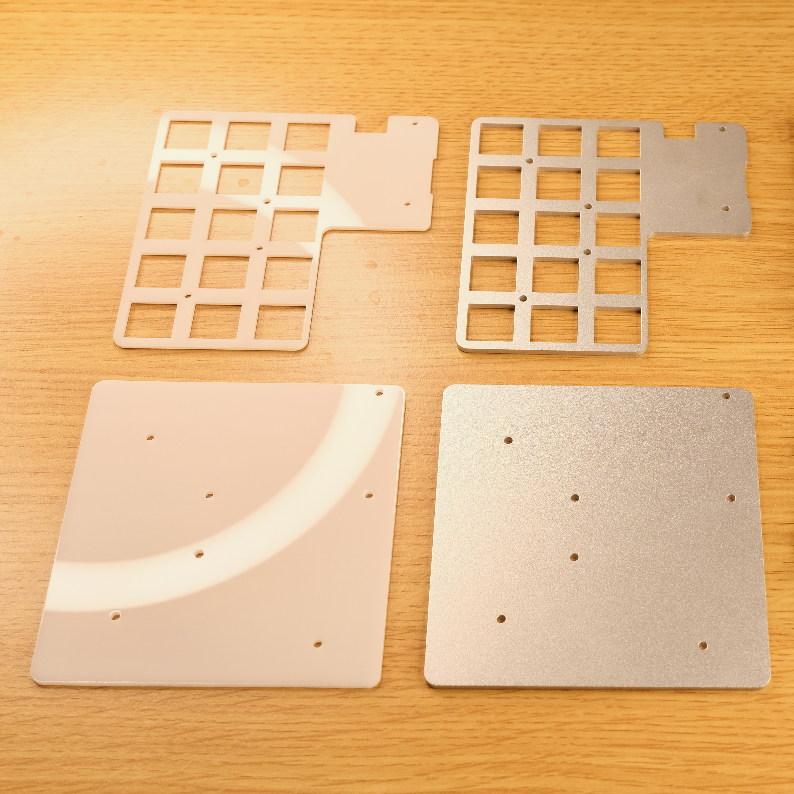
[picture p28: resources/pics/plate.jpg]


## OLED

I used a 1.3 inch OLED display from aliexpress. Make sure the connector is `30pin FPC with 0.5mm pin spacing`.

Note that the FPC connector used here is upper-contact variant. Here are some sample listings (illustration purpose only, you don't have to buy from them):

https://www.aliexpress.com/item/32950730252.html

https://www.aliexpress.com/item/4000350633981.html

Datasheet:

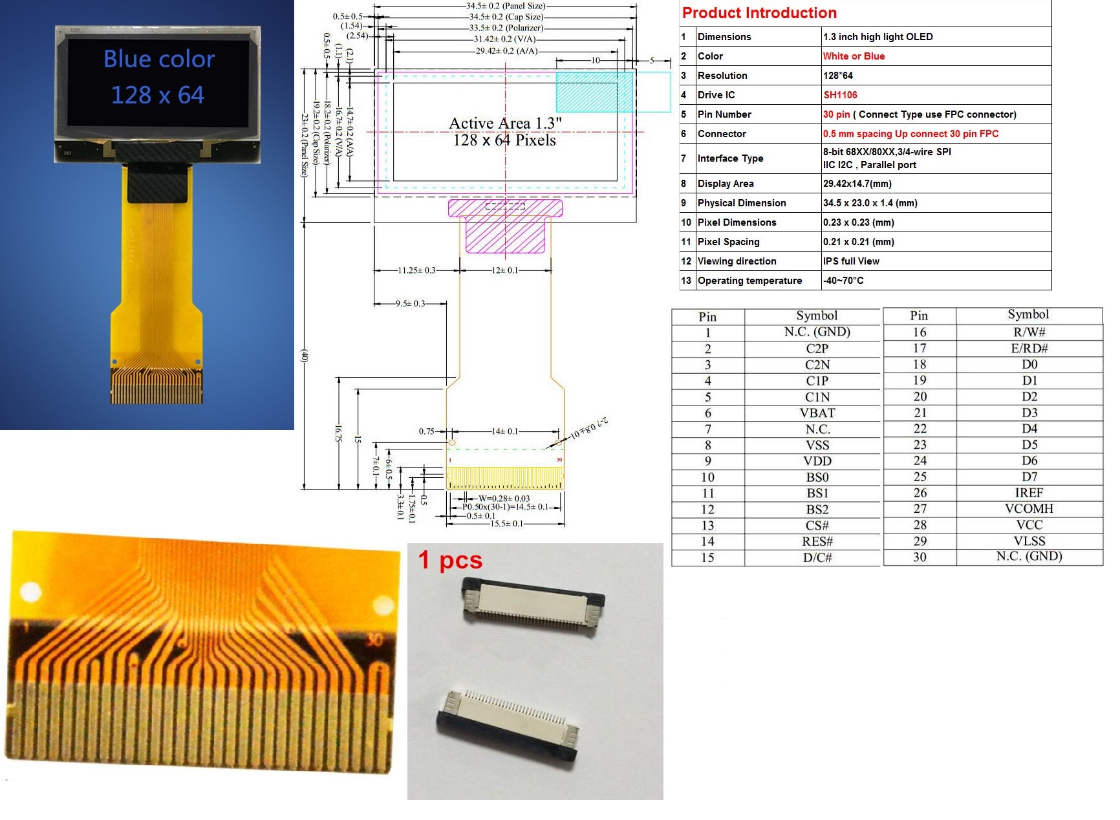
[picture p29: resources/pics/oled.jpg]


## Keycaps

Any Cherry-MX stem keycaps would work.

## USB Type-C connector

Search `USB 16p` on aliexpress for the connector. Should look like this:

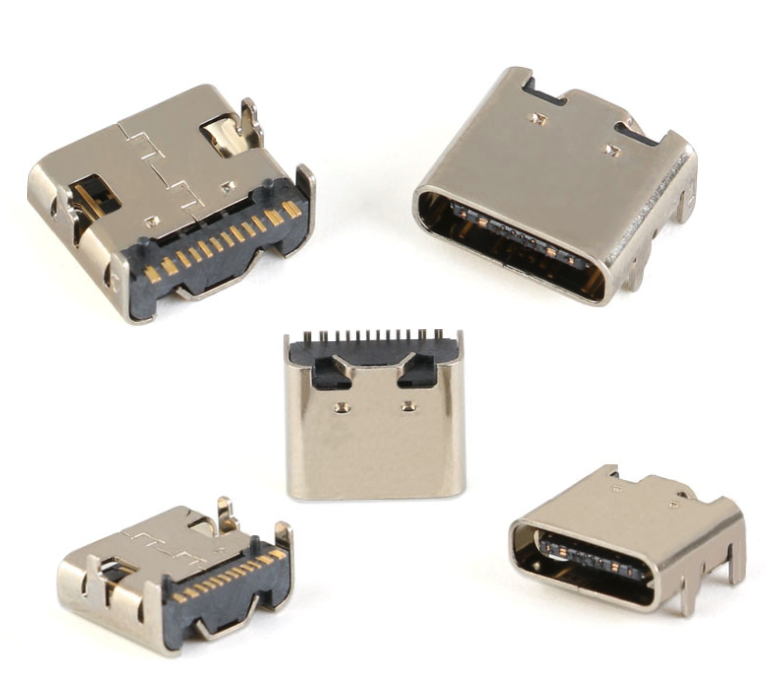
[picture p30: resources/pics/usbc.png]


Datasheet:

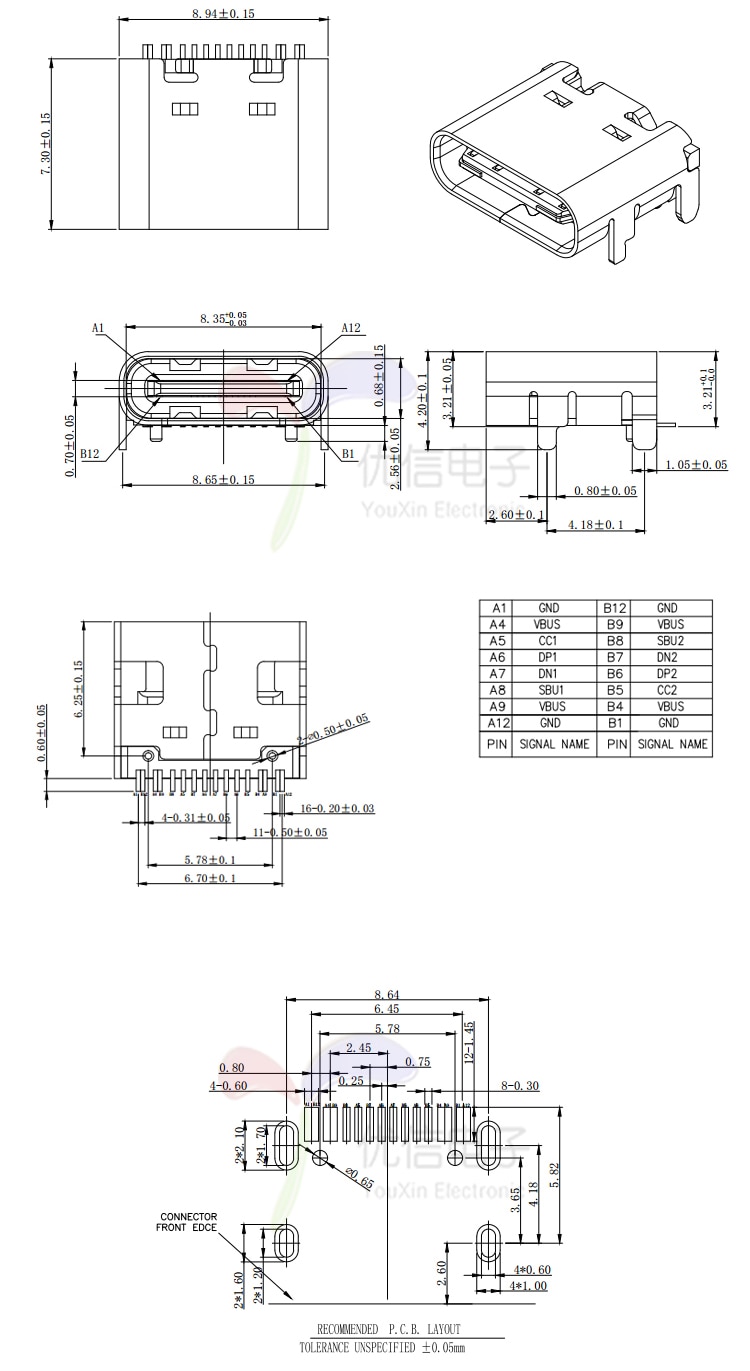
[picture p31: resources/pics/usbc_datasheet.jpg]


## Tactile Buttons

Try searching `3X4X2.5MM White Tactile Button` on aliexpress.

Should look like this:

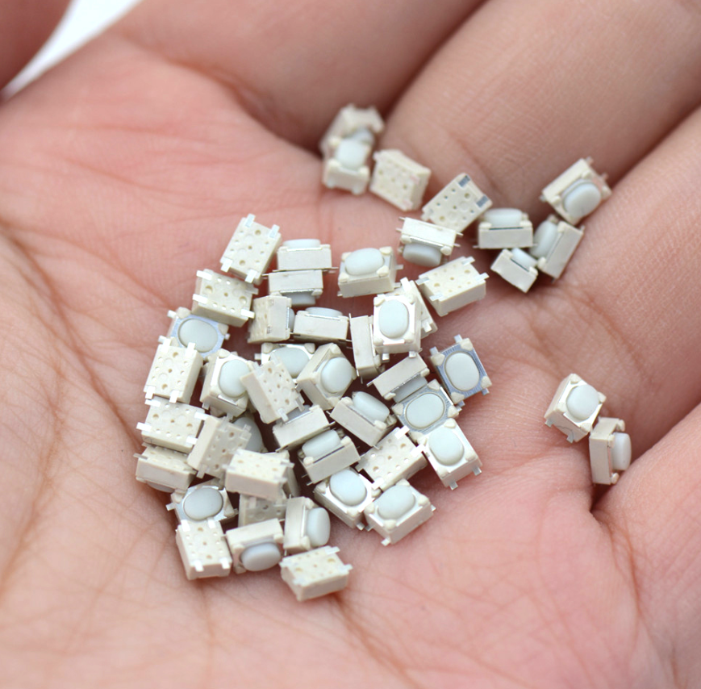
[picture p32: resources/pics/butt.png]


For reset and DFU button, try searching `SMD Side Tact Tactile Push Button`:

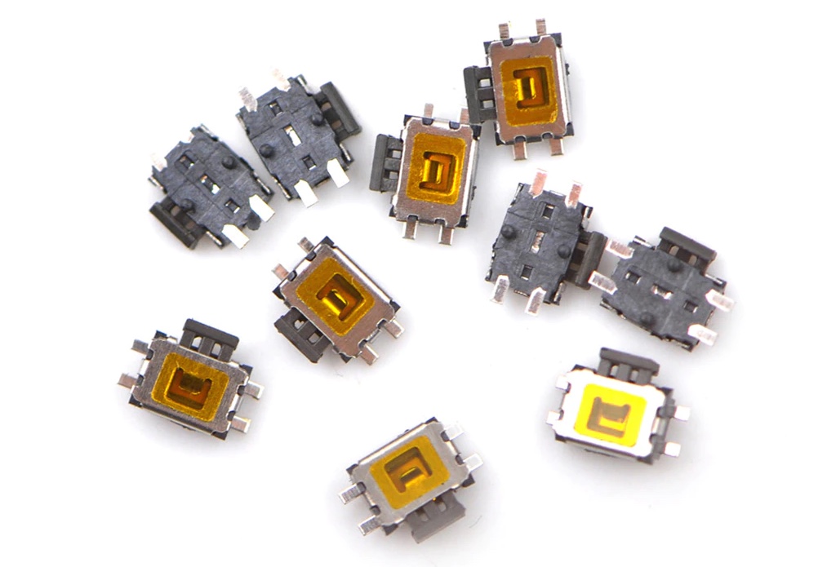
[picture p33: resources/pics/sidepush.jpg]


## Technical notes

The microcontroller used here is a STM32F072C8T6. It is cheaper, has more peripherals, pins, and is faster than any old Aduinos. ST provides a free Keil MDK license for all F0 parts, and there are also completely open source toolchains like arm-gcc.

One interesting design detail is the RGB LED. The WS2812(and its clones) requires a rather high data rate, and Arduino library achieve this by bitbanging in assembly. However the ARM processor in STM32 have some funky pipeline and caches, making asm timing somewhat unreliable. As a result I used SPI for LED control. By selecting the right speed and the right data on the MISO line, you can have the waveform look exactly like what WS2812 requires. In this case sending 0xf8 at 8MHz is bit 1, and sending 0xc0 results in a bit 0. Since SPI is also used by SD card, an AND gate is added to insulate the LED data line when SD card is active.

## Table of Contents

[Main page](README.md)

[Getting Started Guide](getting_started.md)

[Kit Assembly Guide](kit_assembly_guide.md)

[Using duckyScript](https://dekunukem.github.io/duckyPad-Pro/doc/duckyscript_info.html)

[Common issues / Troubleshooting](troubleshooting.md)

[Firmware Updates and Version History](firmware_updates_and_version_history.md)

[Make Your Own Keymap](./keymap_instructions.md)

[Build a duckyPad Yourself](build_it_yourself.md)

[Kickstarter Backer Acknowledgments](kickstarter_backers.md)

## Questions or Comments?

Please feel free to [open an issue](https://github.com/dekuNukem/duckypad/issues), ask in the [official duckyPad discord](https://discord.gg/4sJCBx5), DM me on discord `dekuNukem#6998`, or email `dekuNukem`@`gmail`.`com` for inquires.

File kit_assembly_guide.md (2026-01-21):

# duckyPad Assembly Guide

[Get duckyPad](https://dekunukem.github.io/duckyPad-Pro/doc/landing.html) | [Official Discord](https://discord.gg/4sJCBx5) | [Getting Started](getting_started.md) | [Table of Contents](#table-of-contents)

------

Thanks for getting duckyPad!

Here's how to put everything together.

## Join Our Discord!

Feel free to join our [Official Discord](https://discord.gg/4sJCBx5) for discussions, asking questions, sharing scripts, and latest updates!

## Tools

A small **Phillips-head screwdriver** (`+`shape) should be provided in the package.

A socket bit or **pair of pliers** also helps, but not required.

## Assembly Steps

You should have the following items:

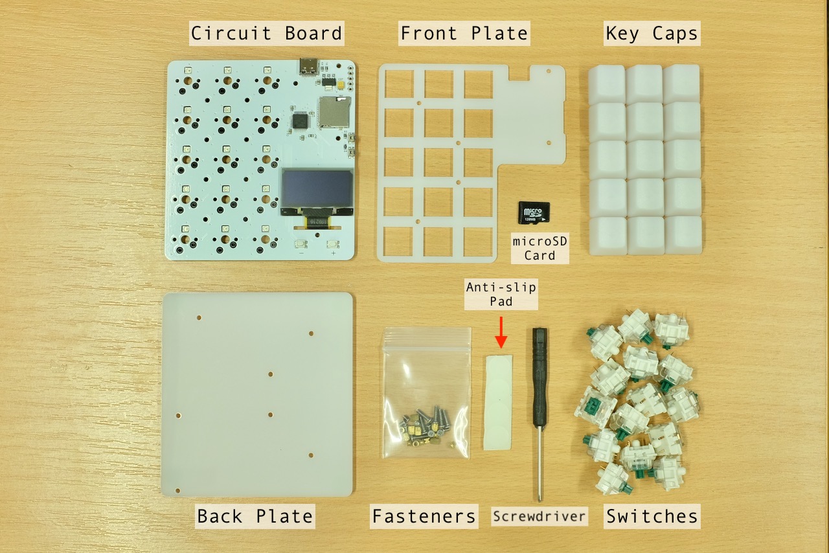
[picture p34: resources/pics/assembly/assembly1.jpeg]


And the following fasteners:

* 6x `8mm Screw`

* 8x `2.8mm Screw`

* 7x `3mm Spacer`

* 6x `4mm Spacer`

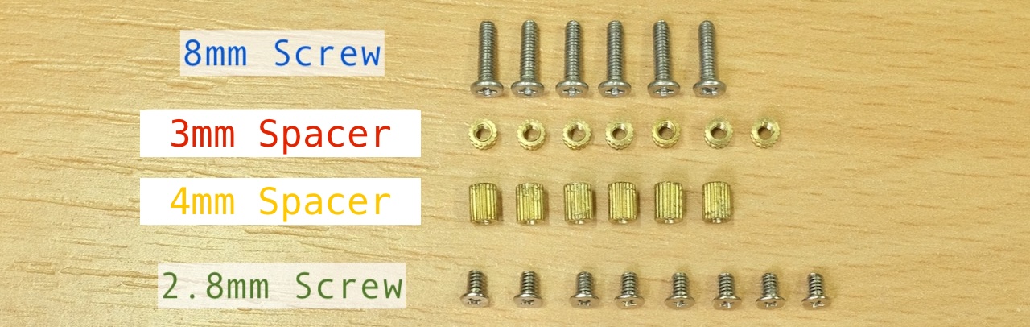
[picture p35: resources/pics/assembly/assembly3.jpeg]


Pay special attention to the **brass spacers**!

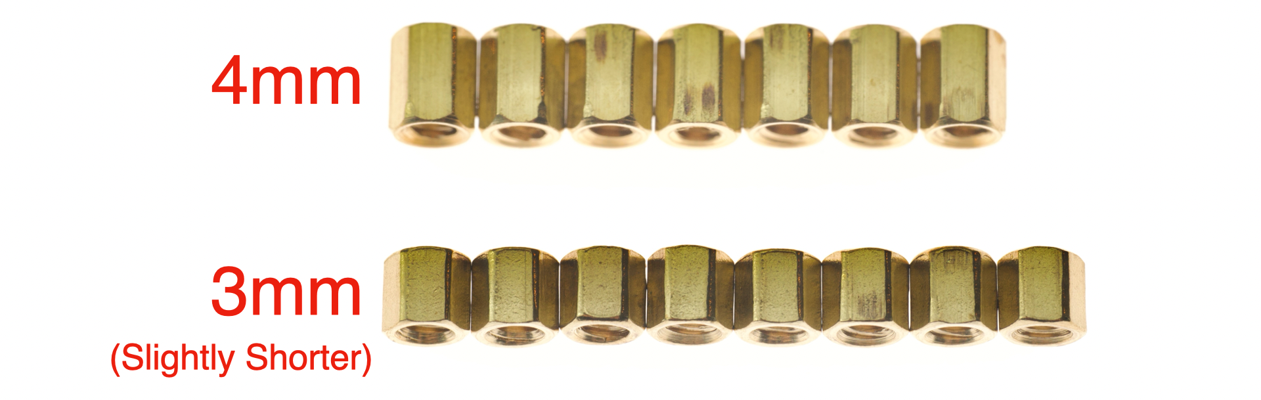
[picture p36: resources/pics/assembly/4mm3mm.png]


* One is **slightly shorter** than the other.

* Separate them out before starting, don't mix them up!

Start by peeling off the protective cover on the front and back plate:

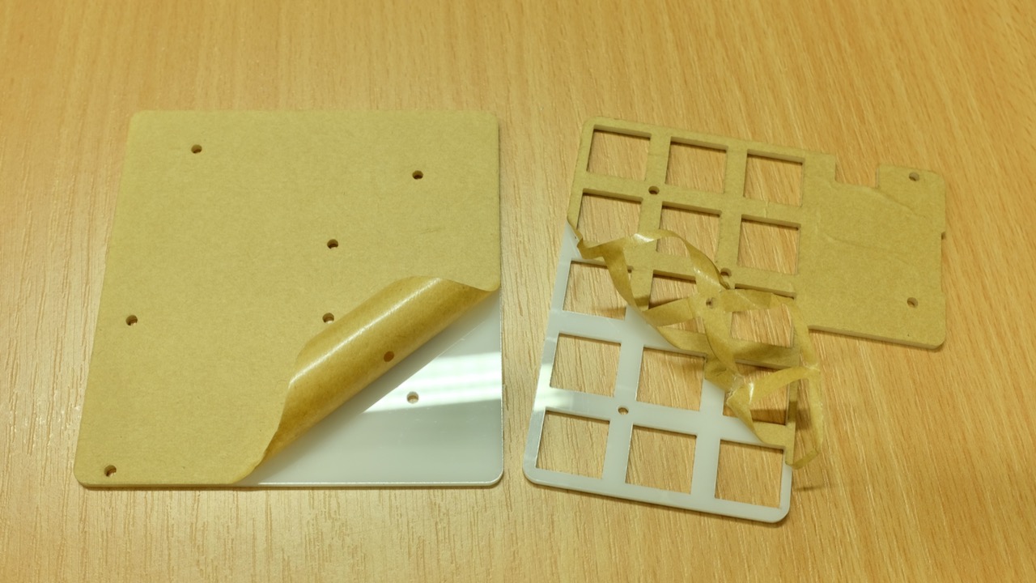
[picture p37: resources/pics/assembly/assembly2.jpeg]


Place the `Back Plate` in front of you like this. Note the orientation of the holes:

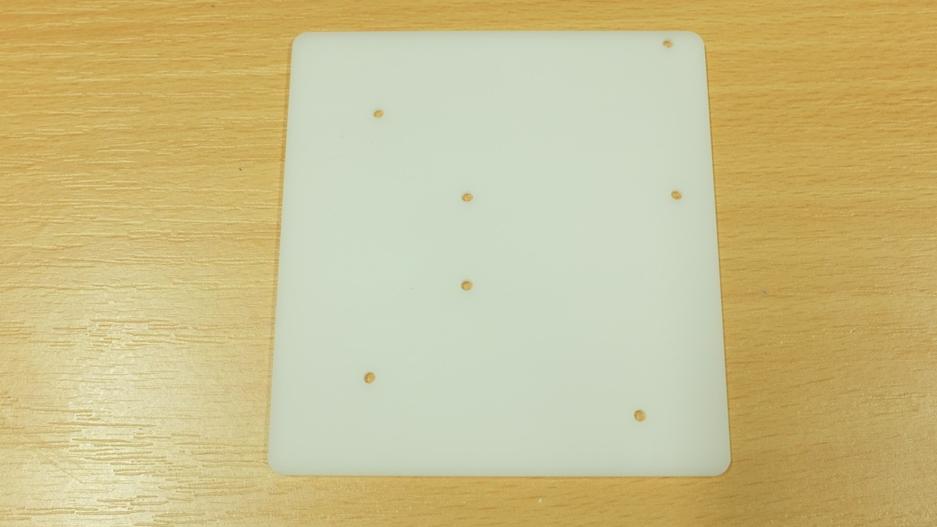
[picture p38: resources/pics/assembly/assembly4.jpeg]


Start from a hole in the middle, put a `8mm Screw` through the back side:

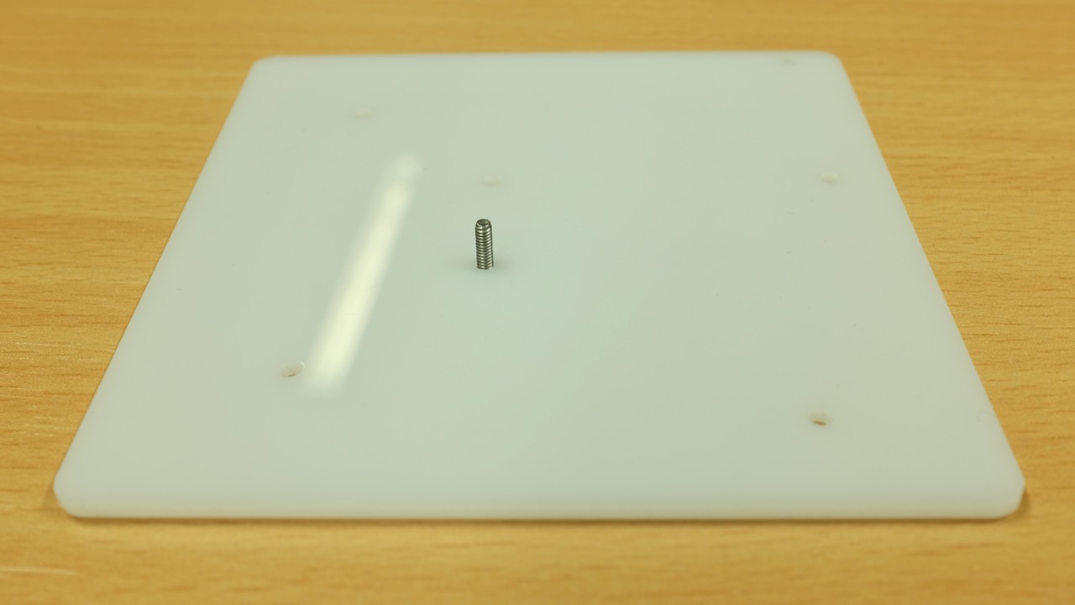
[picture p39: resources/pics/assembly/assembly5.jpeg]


Then screw on the `3mm Spacers`.

Don't over-tighten! Doing so might deform or crack the acrylic plate.

Finger-tight is OK, just make sure it's not loose and doesn't rattle.

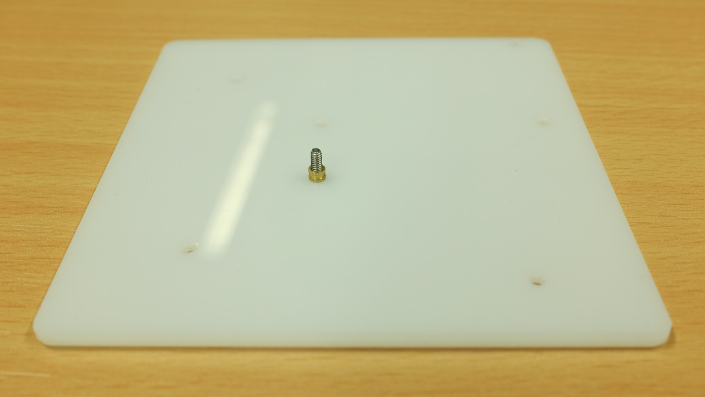
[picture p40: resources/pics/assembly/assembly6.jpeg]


Do the same with all the holes **`EXCEPT the bottom right`**:

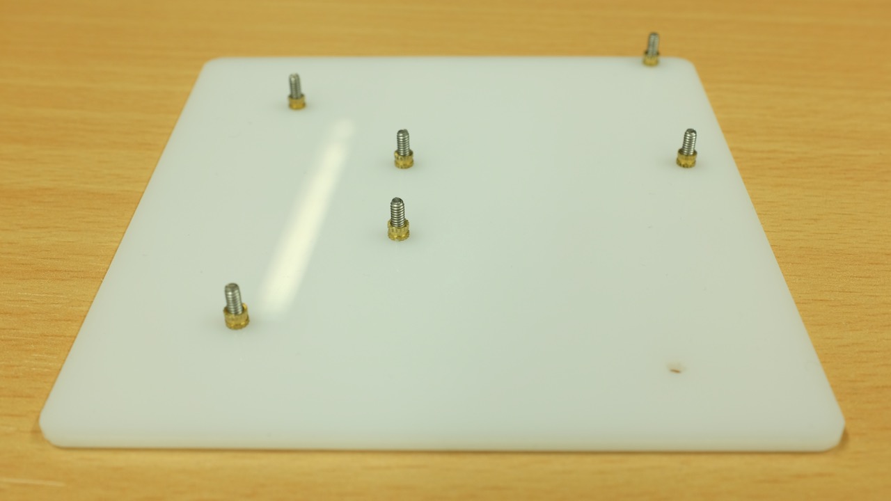
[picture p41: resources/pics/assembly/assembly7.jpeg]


Put a `2.8mm Screw` through that one:

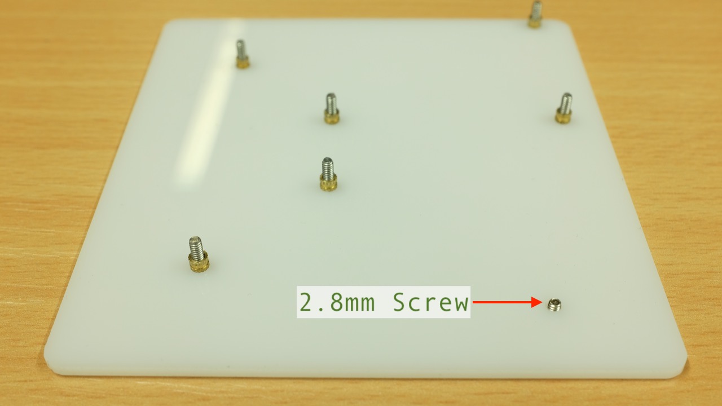
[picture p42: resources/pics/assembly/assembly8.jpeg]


And install the `3mm Spacers`.

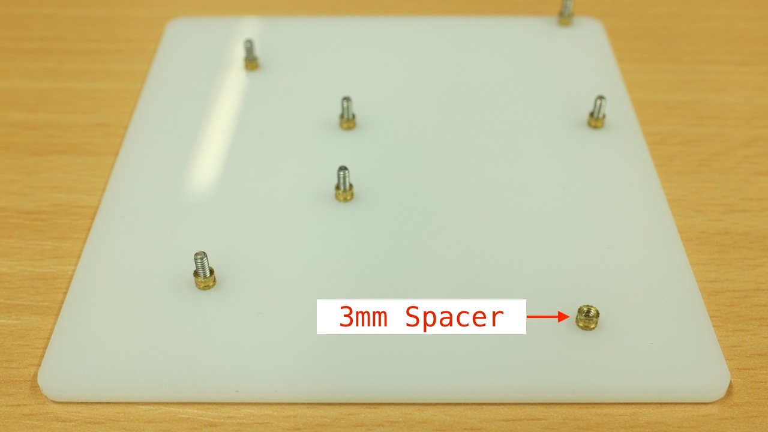
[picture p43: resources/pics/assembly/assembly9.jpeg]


**Wash your hands** to discharge static electricity.

Grab the circuit board by its edge, line up and install as shown:

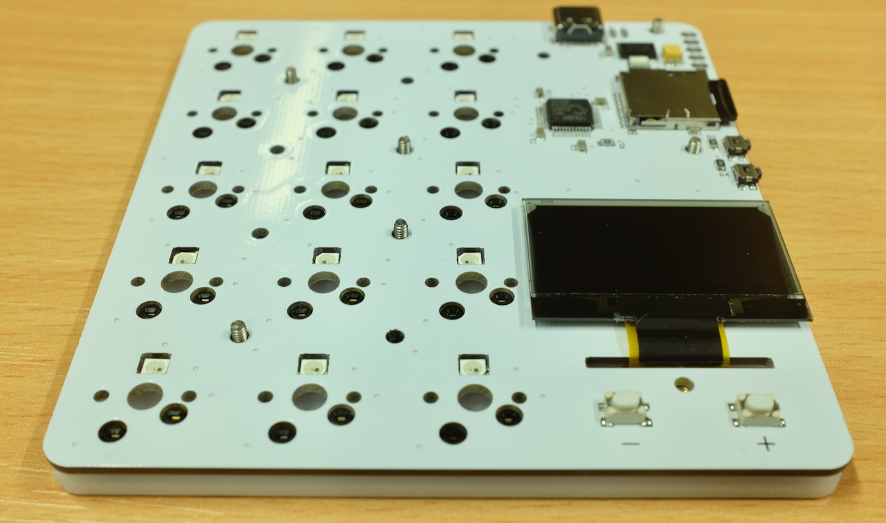
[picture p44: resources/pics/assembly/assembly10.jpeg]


Then install all six `4mm Spacers`, moderately tighten.

Also install the `2.8mm Screw` on the lower right.

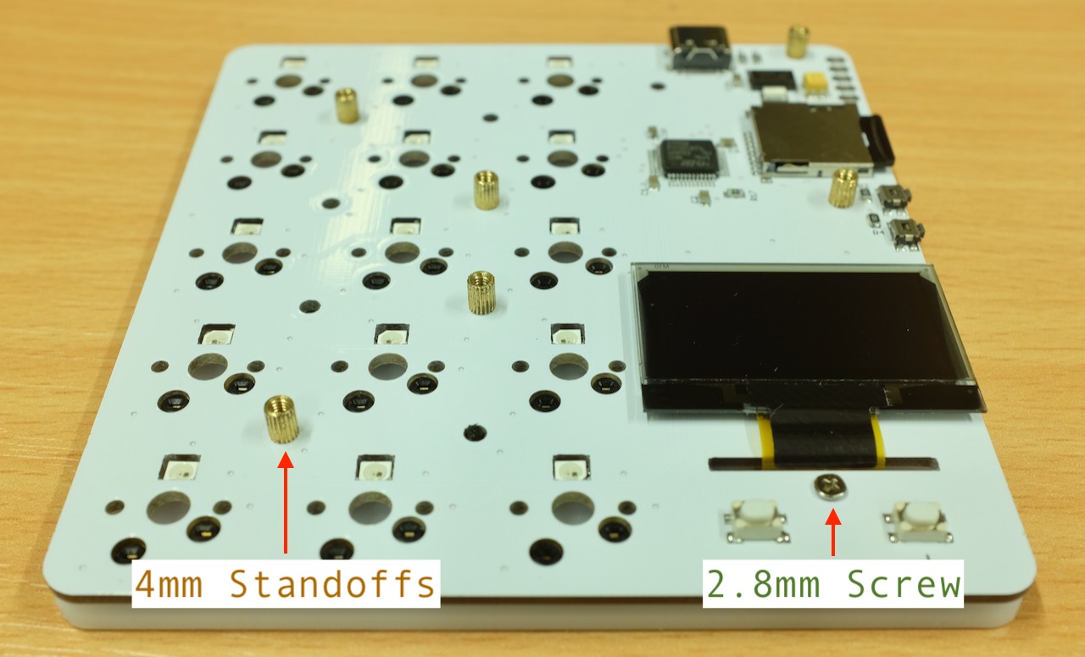
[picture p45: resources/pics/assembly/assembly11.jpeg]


Line up the `Front Plate`, and install the `2.8mm Screws`.

**`DO NOT`** tighten each screw as you install it! Put them all on loosely first, then tighten them one-by-one.

This ensures the plate is properly lined up. Again, don't over-tighten.

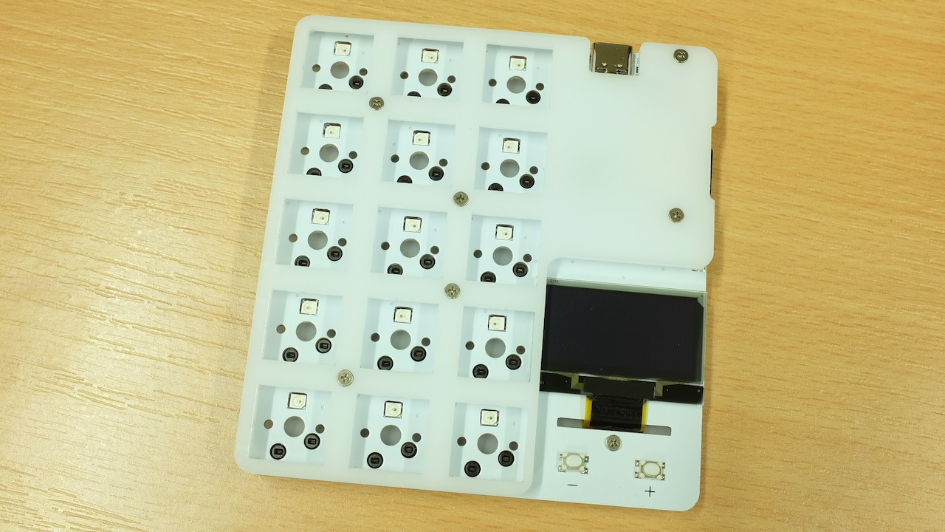
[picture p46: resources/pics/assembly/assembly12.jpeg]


Flip it over, clean the plate with a dry cloth if dirty, and stick on the anti-slip pads on each corner:

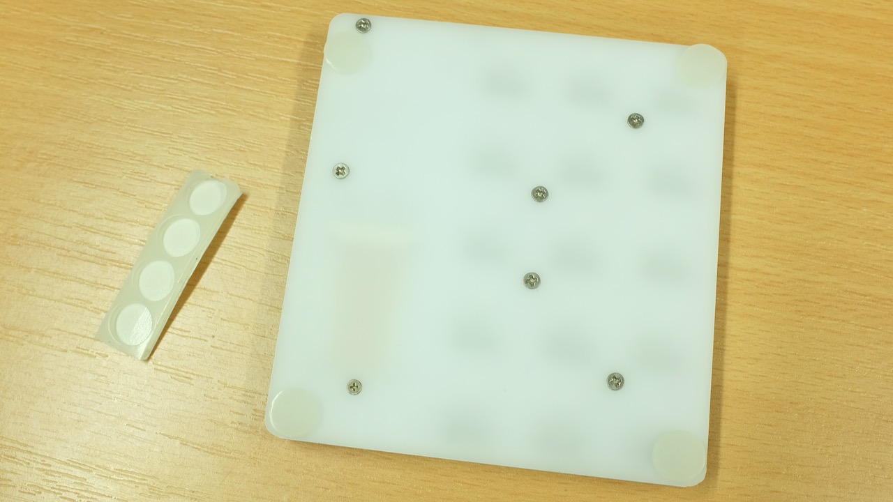
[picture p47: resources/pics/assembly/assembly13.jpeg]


Time to install the switches! duckyPad supports hot-swap, so no soldering is needed. 

* **Make sure the pins are straight!**

* **Make sure the pins are straight!** 

* **Make sure the pins are straight!**, otherwise you might damage the circuit board or the switch itself!

Then **line up with the holes**, and **`gently push straight down`** until it clicks in place:

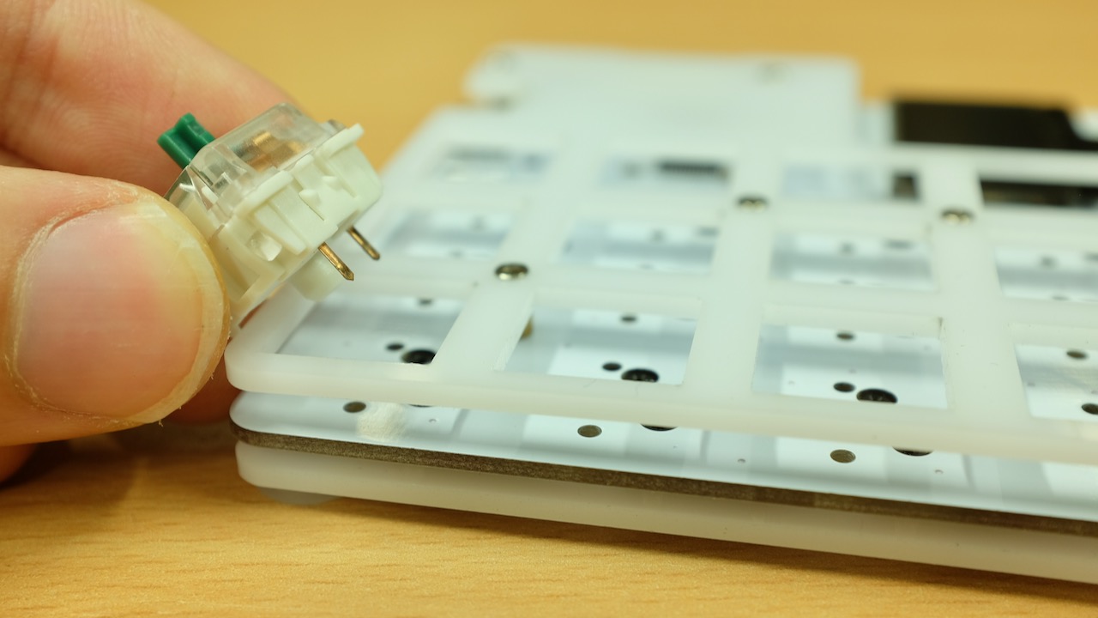
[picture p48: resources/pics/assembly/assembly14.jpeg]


Keycaps next! Note the orientation ("slope" side pointing left in this photo). Just push it down.

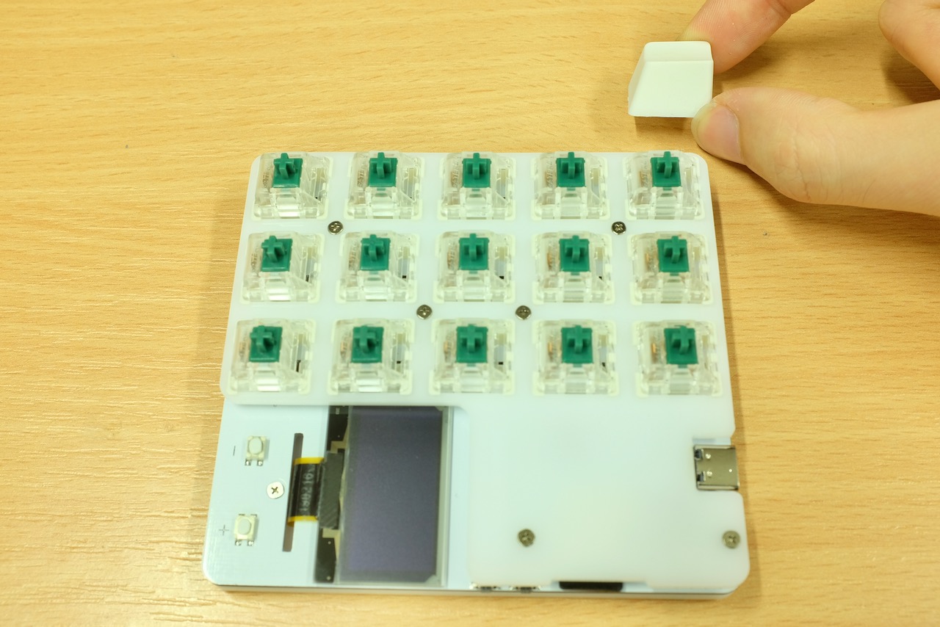
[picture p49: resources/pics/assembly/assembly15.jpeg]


All the keys should be lined up evenly. If not, try push down or wiggle it a little.

Finally, if it hasn't already been done, peel off the protective cover on the OLED screen:

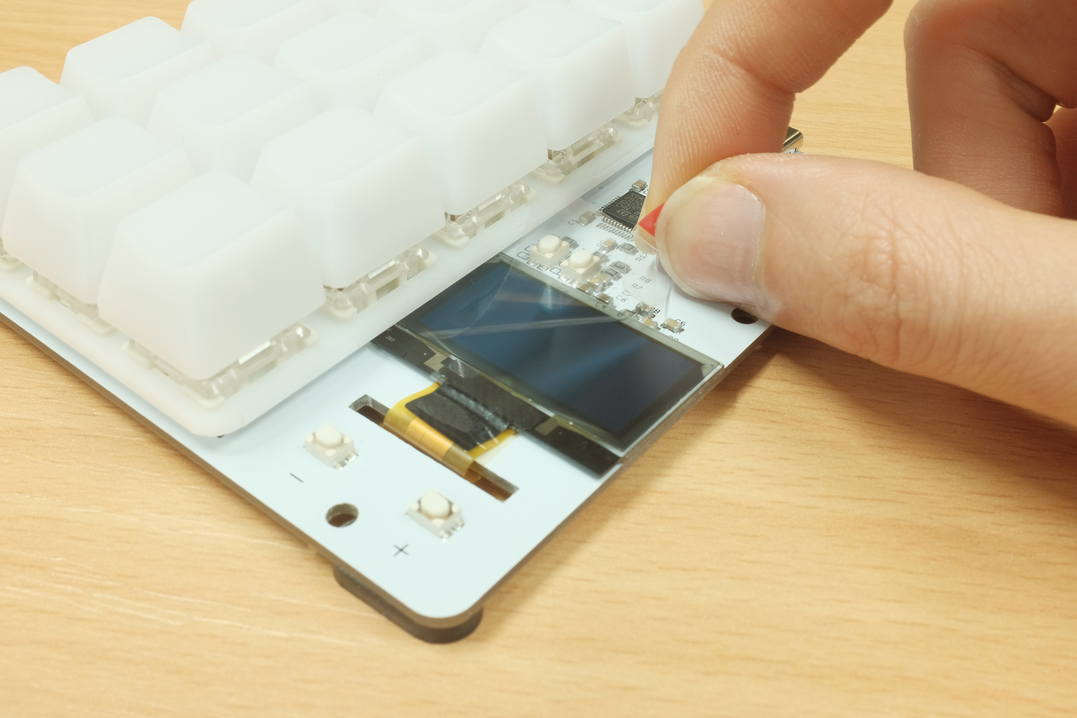
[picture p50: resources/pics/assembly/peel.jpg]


And you're done! Congratulations!

Head on down to the [Quick Start Guide](/getting_started.md) to see how to use it.



## Table of Contents

[Main page](README.md)

[Getting Started Guide](getting_started.md)

[Kit Assembly Guide](kit_assembly_guide.md)

[Using duckyScript](https://dekunukem.github.io/duckyPad-Pro/doc/duckyscript_info.html)

[Common issues / Troubleshooting](troubleshooting.md)

[Firmware Updates and Version History](firmware_updates_and_version_history.md)

[Make Your Own Keymap](./keymap_instructions.md)

[Build a duckyPad Yourself](build_it_yourself.md)

[Kickstarter Backer Acknowledgments](kickstarter_backers.md)

## Questions or Comments?

Please feel free to [open an issue](https://github.com/dekuNukem/duckypad/issues), ask in the [official duckyPad discord](https://discord.gg/4sJCBx5), DM me on discord `dekuNukem#6998`, or email `dekuNukem`@`gmail`.`com` for inquires.

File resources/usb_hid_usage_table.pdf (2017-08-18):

# HID Usage Tables

10/28/2004

### Version 1.12

### Please send comments via electronic mail to: hidcomments@usb.org

# Universal Serial Bus (USB)

©1996-2004 USB Implementers’ Forum—All rights reserved.

ii | Universal Serial Bus HID Usage Tables
Version 1.12 | October 28, 2004

## Contributors

Brian M. Bates – ELO Touchsystems Robert Dezmelyk – LCS/Telegraphics Robert Ingman – Microsoft Corporation Rob Lieb – Symbol Technologies, Inc. Steve McGowan – Intel (Editor)
Kenneth Ray – Microsoft Corporation Steve Schumacher – LCS/Telegraphics Nathan C. Sherman - Microsoft Corporation Don Stern – TV Interactive
Mike Van Flandern – Microsoft Corporation Remy Zimmerman – Logitech International And many others.

Universal Serial Bus HID Usage Tables | iii
Version 1.12 | October 21, 2004

## Revision History

Revision | Issue Date | Comments
1.12rc1 | October 28, 2004 | Incorporate HUT Review Request 20, 21, 22, 23, 24, 25, 27, and 29.
1.11 | June 27, 2001 | Version 1.11 release
1.11rc1 | August 7, 2000 | Incorporate HUT Review Request 1, 2, 3, 4, 5, 6, 7, 8, 9, 11, 13, 14, 15,16, 17, and 18.
1.1 | April 8, 1999 | Version 1.1 release
1.1rc3 | February 16, 1999 | Correct barcode Usage Page ID. Corrected page numbering.
1.1rc2 | January 21, 1999 | Incorporate HID Review Request 51.
1.1rc1 | October 13,1998 | Incorporate Keyboard Usage Table from the 1.0 HID Specification and HID Review Requests 16, 34, 38, 40, 41, 42, 43, 45, 46, 48 and 49.
1.0 | October 30, 1997 | Version 1

iv | Universal Serial Bus HID Usage Tables
| Copyright © 1996-2004, USB Implementers Forum All rights reserved.

INTELLECTUAL PROPERTY DISCLAIMER THIS SPECIFICATION IS PROVIDED “AS IS” WITH NO WARRANTIES WHATSOEVER INCLUDING ANY WARRANTY OF MERCHANTABILITY, FITNESS FOR ANY PARTICULAR PURPOSE, OR ANY WARRANTY OTHERWISE ARISING OUT OF ANY PROPOSAL, SPECIFICATION, OR SAMPLE.
A LICENSE IS HEREBY GRANTED TO REPRODUCE AND DISTRIBUTE THIS SPECIFICATION FOR INTERNAL USE ONLY. NO OTHER LICENSE, EXPRESS OR IMPLIED, BY ESTOPPEL OR OTHERWISE, TO ANY OTHER INTELLECTUAL PROPERTY RIGHTS IS GRANTED OR INTENDED HEREBY.
AUTHORS OF THIS SPECIFICATION DISCLAIM ALL LIABILITY, INCLUDING LIABILITY FOR INFRINGEMENT OF PROPRIETARY RIGHTS, RELATING TO IMPLEMENTATION OF INFORMATION IN THIS SPECIFICATION. AUTHORS OF THIS SPECIFICATION ALSO DO NOT WARRANT OR REPRESENT THAT SUCH IMPLEMENTATION(S) WILL NOT INFRINGE SUCH RIGHTS.
All product names are trademarks, registered trademarks, or service marks of their respective owners.

Please send comments via electronic mail to hidcomments’at’usb.org, us the @ sign for ‘at’.

Universal Serial Bus HID Usage Tables | v

## Table of Contents

vi Universal Serial Bus HID Usage Tables

### 7 SPORT CONTROLS PAGE (0X04) | 45

7.1 | STICK DEVICES | 46
7.2 | EXERCISE MACHINES | 47

### 8 GAME CONTROLS PAGE (0X05) | 48

8.1 | 3D GAME CONTROLLER | 49
8.2 | PINBALL DEVICE | 50
8.3 | GUN DEVICE | 50
8.4 | GAMEPADS | 51
8.4.1 | Gamepad Button Collections | 51

### 9 GENERIC DEVICE CONTROLS PAGE (0X06) | 52

### 10 KEYBOARD/KEYPAD PAGE (0X07) | 53

### 11 LED PAGE (0X08) | 61

11.1 KEYBOARD INDICATORS | 63
11.2 TELEPHONY INDICATORS | 63
11.3 CONSUMER INDICATORS | 64
11.4 MEDIA TRANSPORT INDICATORS | 64
11.5 PRINTER INDICATORS | 65
11.6 GENERAL DEVICE INDICATORS | 65

### 12 BUTTON PAGE (0X09) | 67

### 13 ORDINAL PAGE (0X0A) | 68

### 14 TELEPHONY DEVICE PAGE (0X0B) | 69

14.1 TELEPHONY DEVICES | 71
14.2 TELEPHONY KEY PAD USAGES | 71
14.3 CALL CONTROL | 72
14.4 SPEED DIAL CONTROLS | 73
14.5 VOICE MAIL CONTROLS | 73
14.6 LOCALLY GENERATED TONES | 73

### 15 CONSUMER PAGE (0X0C) | 75

15.1 GENERIC CONSUMER CONTROL DEVICE | 85
15.2 NUMERIC KEY PAD | 85
15.3 GENERAL CONTROLS | 86
15.4 MENU CONTROLS | 86
15.5 DISPLAY CONTROLS | 86
15.6 SELECTION CONTROLS | 87
15.7 TRANSPORT CONTROLS | 88
15.8 SEARCH CONTROLS | 89
15.9 AUDIO CONTROLS | 89
15.9.1 | Volume | 89
15.9.2 | Balance | 90
15.9.3 | Bass | 90
15.9.4 | Treble | 90
15.9.5 | Other | 91
15.10 | SPEED CONTROLS | 91
15.11 | HOME AND SECURITY CONTROLS | 91

Universal Serial Bus HID Usage Tables | vii
15.12 | SPEAKER CHANNELS | 92
15.12.1 | Audio Channels | 92
15.13 | PC THEATRE | 94
15.14 | PROGRAMMABLE BUTTONS | 94
15.15 | APPLICATION LAUNCH BUTTONS | 94
15.16 | GENERIC GUI APPLICATION CONTROLS | 98

### 16 DIGITIZERS (0X0D) | 103

16.1 DIGITIZER DEVICES | 104
16.2 DIGITIZER TRANSDUCER COLLECTION USAGES | 105
16.3 DIGITIZER REPORT FIELD USAGES | 105
16.3.1 | Digitizer-Specific Fields | 105
16.3.2 | Tilt Orientation | 106
16.3.3 | Azimuth-Altitude Orientation | 106
16.4 DIGITIZER SWITCH USAGES | 107

### 17 UNICODE PAGE (0X10) | 108

### 18 ALPHANUMERIC DISPLAY PAGE (0X14) | 109

18.1 ALPHANUMERIC DISPLAY | 111
18.1.1 | Flags | 111
18.1.2 | Display Control | 113
18.1.3 | Scrolling | 114
18.1.4 | Character Transfers | 114
18.1.5 | Display Status | 115
18.1.6 | Cursor Control | 115
18.1.7 | Font Loading | 117
18.1.8 | Character Formats | 118
18.2 BITMAPPED DISPLAY | 120
18.2.1 | Display Attributes Report | 121
18.2.2 | Orientation | 123
18.2.3 | Palette Report | 124
18.2.4 | Blit Report | 125
18.2.5 | Soft Button Report | 125

### 19 MEDICAL INSTRUMENT PAGE (0X40) | 126

19.1 ULTRASOUND DEVICES | 127
19.2 ACQUISITION CONTROLS | 127
19.3 SIGNAL MODULATION | 128
19.4 ACQUISITION AND DISPLAY MODE CONTROLS | 128
APPENDIX A: USAGE EXAMPLES | 130
A.1 | VOLUME CONTROL | 130
A.1.1 | Up/Down Buttons | 130
A.1.2 | Knob | 130
A.2 | TAPE JOG WHEEL | 130
A.3 | RADIO BUTTONS | 131
A.3.1 | Mechanically Linked Radio Buttons | 131
A.3.2 | Radio Buttons with No Mechanical Linkage | 131
A.4 | NAMED ARRAY FIELD | 131
A.5 | MULTIPLE INSTANCES OF A CONTROL | 132
A.6 | MULTIPLE INSTANCES OF A MULTI-MODE LED | 132
A.7 | DESKTOP TABLET EXAMPLE | 134

viii | Universal Serial Bus HID Usage Tables
A.8 | A DEVICE WITH A DISPLAY | 137
A.9 | REMOTE CONTROL | 141
A.10 | TELEPHONE | 142
A.11.1 | Multi-Line Snippet | 145
A.12 | JOYSTICK | 145
A.13 | GAME PAD | 147
A.14 GRAPHIC EQUALIZER | 148
19.5 SAMPLE BITMAPPED DISPLAY DEVICE | 150
19.5.1 Example Bitmapped Display Report Descriptor | 151
APPENDIX B: DELIMITER EXAMPLE | 154
APPENDIX C: PHYSICAL DESCRIPTOR EXAMPLE | 156
USAGE INDEX | 160

Universal Serial Bus HID Usage Tables | ix

## List of Tables

Table 1: Usage Page Summary | 14
Table 2: Usage Types (Controls) | 17
Table 3: Usage Types (Data) | 18
Table 4: Usage Types (Collection) | 20
Table 5: HID Sublanguage IDs | 24
Table 6: Generic Desktop Page | 26
Table 7: Simulation Controls Page | 36
Table 8: VR Controls Page | 43
Table 9: Sport Controls Page | 45
Table 10: Game Controls Page | 48
Table 11: Generic Device Controls Page | 52
Table 12: Keyboard/Keypad Page | 53
Table 13: LED Usage Page | 61
Table 14: Button Usage Page | 67
Table 15: Ordinal Usage Page | 68
Table 16: Telephony Usage Page | 69
Table 17: Consumer Usage Page | 75
Table 18: Digitizer Page | 103
Table 19: Alphanumeric Display Usage Page | 109
Table 20: ASCII Display Character Set | 111
Table 21: Example 7-Segment Font values for Hex digits | 119
Table 22: Medical Instrument Page | 126
Table 23: Graphic Equalizer Usage Descriptors (HID LANGID - 0x04FF) ... 149
Table 24: Example Stereo Graphic Feature Report | 150

x Universal Serial Bus HID Usage Tables

## List of Figures

Figure 1: String Descriptor | 22
Figure 2: LANGID Format | 23
Figure 3: GetDescriptor(String) Request | 23
Figure 4: Usage Data Descriptor | 24
Figure 5: Vendor Defined Descriptor | 25
Figure 6: System Power States | 32
Figure 7: Graphic Equalizer Data Descriptor | 85
Figure 8: Audio Channels | 92
Figure 9: 7-Segment Direct Mapping Data | 112
Figure 10: 14-Segment Direct Mapping Data | 113
Figure 11: Matrix Character Segment Mapping | 118
Figure 12: 7-Segment Character Segment Mapping | 119
Figure 13: 14-Segment Font Data | 120
Figure 14: 14-Segment Character Segment Mapping | 120
Figure 15: Display Orientation and Writing Order | 124
Figure 16: LED Report fields | 133
Figure 17: Example Digitizer 2-Button Stylus Input Report | 136
Figure 18: Example Digitizer 16-Button Puck Input Report | 136
Figure 19: Example Digitizer Pressure Stylus Input Report | 136
Figure 20: Example Display Attributes Feature Report | 139
Figure 21: Example Display Device Input Report | 139
Figure 22: Example Display Device Display Position Feature Report | 140
Figure 23: Example Display Device Character Feature Report | 140
Figure 24: Example Display Device Font Load Output Report | 140
Figure 25: Example Remote Control Input Report | 142
Figure 26: Example Telephony Device Input Report | 144
Figure 27: Example Telephony Device Output Report | 145
Figure 28: Example Joystick Input Device Report | 146
Figure 29: Example Game Pad Input Device Report | 147
Figure 30: Example Display Layout | 151
Figure 31: Joystick Button Layout | 156

Universal Serial Bus HID Usage Tables | 11

## 1 Introduction

Usages are part of the HID Report descriptor and supply an application developer with information about what a control is actually measuring or reporting. In addition, a Usage tag can be used to indicate the vendor’s suggested use for a specific control or group of controls. While most of the items within a Report descriptor describe the format of the data—for example, three 8-bit fields—the Usage tags define what should be done with the data—for example, x, y, and z input. This feature allows a vendor to ensure that the user sees consistent function assignments to controls across applications. It is also the key feature within HID Report descriptors that allows system or application software to know the meaning of data items, or collections of data items, so the data items can be correctly interpreted or routed to the system or application software that consumes them.

## 1.1 Scope

This document is the most current and complete list of currently defined usages. With the exception of the Keyboard/Keypad Page (0x07), this document is a superset of the usages defined in the USB Device Class Definition for Human Interface Devices (HID), also called the HID Specification. Keyboard/Keypad Page usages are listed in the HID Specification, and are not repeated in this document due to length. Usages for other pages listed in the HID Specification (Generic Desktop, LED, and Button pages) are repeated in this document with additional information. In case of a discrepancy, this document takes precedence over the HID Specification for those usages.
Usage definitions for Monitor, Power, Bar Code Scanner, and Point of Sale devices are in process as of this publication date and are not covered in this document. For details about those usages, see the device class specifications for those devices.

## 1.2 Purpose

This document defines constants that can be interpreted by an application to identify the purpose and meaning of a data field in a HID report.
Usages are also used to define the meaning of groups of related data items. This is accomplished by the hierarchical assignment of usage information to collections. Usages identify the purpose of a collection and the items it contains. Each Input, Output, Feature, and/or Collection data item within a Collection item can be assigned a purpose with its own usage item. Usages assigned to a collection apply to the items within the collection.
In some cases a usage applied to a collection can redefine the meaning of the usages it contains. An example of this is the Usage Selected Indicator on the LED page.
Usages are also used to specify the meaning of each element within an Array data item.

### 12 Universal Serial Bus HID Usage Tables

## 1.3 Related Documents

Universal Serial Bus Specification, 1.0 Version (also referred to as the USB Specification)
USB PC Legacy Compatibility Specification
Universal Serial Bus Device Class Definition for Human Interface Devices (HID) (also referred to as the HID Specification)
USB Device Class Definition for Monitor Devices
USB Device Class Definition for Power Devices
USB Device Class Definition for Bar Code Scanners
USB Device Class Definition for Point of Sale Devices
USB Device Class Definition for Physical Interface Devices
Unicode Standard, version 1.1
International Character Encoding Standard, ISO/IEC10646-1 UCS-2 Open Arcade Architecture Device Data Format Specification

## 1.4 Terms and Abbreviations

Application | A software program that consumes the data generated by the HID device Input reports, or that controls the HID device through Feature or Output reports. Applications can be games or other programs used by end users or system software components.
Array field | The bit field created by an Input, Output, or Feature main item which is declared as an Array. An array field contains the index of a usage, not the usage value.
Control | A control is used to operate or regulate a particular aspect of a device. In this document a control refers broadly to the physical entity on the device that the usage identifies.
Field | The Input, Output, and Feature main items create a bit field in a report. The Report Size determines the field’s width and the associated usage determines the field’s purpose. The offset of a field in a report is determined by the fields that are declared before it.
Pad | If a field is marked as a constant and there is no usage associated with it, the field will be treated as pad bits and ignored by host software.
| Note: Fields created by Main items that do not have usages attached to them might not be accessible by applications. Whether such access is possible depends on the implementation of the HID device driver.
Usage | Defines the purpose or meaning of an item.

Universal Serial Bus HID Usage Tables | 13

## 2 Management Overview

This document provides lists of usages and their descriptions that significantly extend the list of usages provided in the HID Specification. A HID usage communicates the intended function or meaning of a particular control. Usages provide a description of the data items in a HID device’s Input, Output, and Feature reports. The existence of a defined usage does not guarantee that system or application software will recognize or utilize the data item. Although usages can be very powerful, there is a potential for misuse. The detail provided in this document will help minimize the misuse or misinterpretation of usages when they are applied by a device developer.
Usages have been organized into pages of related controls. Each usage has a usage ID, usage name and a detailed description. The usage names are mnemonics, not definitions. To avoid misleading interpretations based on the usage name, it is very important that a developer review a usage’s description in detail to ensure that it properly identifies the purpose of the control or device that the usage is attached to.
In theory, a usage can be attached to any type of HID control, variable, array, collection, and so forth. In reality, usages only make sense when they are attached to particular controls and used in certain ways. A relatively small set of usage types have been defined to help the application software developer better understand what to expect when a particular usage is found. Each usage has a usage type associated with it. The usage type identifies the item types, flag settings and bit fields organizations that are found with a particular usage.
Usages can also identify functional devices as a whole, thus providing an easy method for an application to identify devices that provide functions of interest. Such usages are found attached to application collections that are wrapped around all the items that describe a particular functional device, or a particular function in a complex device. Generally an application will query the HID driver for all application collection usages that it knows pertain to it. For example, a gaming device driver might look for Joystick and Game Pad usages, while a system mouse driver might look for Mouse, Digitizer Tablet and Touch Screen usages.
As a general rule, the usages selected by a device developer should be specific enough to dissuade inappropriate use by applications while remaining general enough to allow applications to take advantage of device features if they can. If uncertain, favor the more general usage to encourage broader application support for your device. An alternative is to use delimiters to define multiple usages associated with a single control or a device. For details, see Appendix B, “Delimiter Example.”
Some usage pages that are in the HID Specification are also found in this document. They are included here because either additional text has been provided to clarify how the usages are to be used , new usages have been added to the page, or both. No changes have been made to the usage values assigned in the HID Specification.

### 14 Universal Serial Bus HID Usage Tables

## 3 Usage Pages

The following table lists the currently defined usage pages and the section in this document or the specification where each page is described.

Table 1: Usage Page Summary

Page ID | Page Name | Section or Document
00 | Undefined
01 | Generic Desktop Controls | 4
02 | Simulation Controls | 5
03 | VR Controls | 0
04 | Sport Controls | 7
05 | Game Controls | 8
06 | Generic Device Controls | 9
07 | Keyboard/Keypad | 10
08 | LEDs | 11
09 | Button | 12
0A | Ordinal | 13
0B | Telephony | 14
0C | Consumer | 15
0D | Digitizer | 16
0E | Reserved
0F | PID Page | USB Physical Interface Device definitions for force feedback and related devices.
10 | Unicode | 17
11-13 | Reserved
14 | Alphanumeric Display | 18
15-3f | Reserved
40 | Medical Instruments | 19
41-7F | Reserved
80-83 | Monitor pages | USB Device Class Definition for Monitor Devices
84-87 | Power pages | USB Device Class Definition for Power Devices
88-8B | Reserved
8C | Bar Code Scanner page | USB Device Class Definition for Point of Sale Devices
8D | Scale page
8E | Magnetic Stripe Reading (MSR) Devices
8F | Reserved Point of Sale pages
90 | Camera Control Page | USB Device Class Definition for Image Class Devices

Universal Serial Bus HID Usage Tables | 15
Page ID | Page Name | Section or Document
91 | Arcade Page | OAAF Definitions for arcade and coinop related Devices
92-FEFF | Reserved
FF00-FFFF | Vendor-defined

A bold usage definition in the following sections identifies a collection. Non-bold definitions are specific features related to a device that would be applied to individual controls that generate data. In many cases, specific usages can be used by a number of device types.

## 3.1 HID Usage Table Conventions

Usage ID 0 should always be reserved.
Usage ID 1 through 0x1F are reserved for “top level” collections. These usage IDs are not necessarily application-level but are used to identify general device types.
Usage page values are limited to 16 bits.
Usage ID values are limited to 16 bits.
Usages are 32-bit identifiers, where the high order 16 bits represents the usage page and the low order 16 bits represents the usage ID. To allow more compact Report descriptors, Usage Page items can be declared to specify the high order bits of the Usage item and the Usage items can declare only the ID portion of the usage, as follows:
- If the bSize field of the Usage item equals 1 or 2, the entire 1- or 2-byte data portion of the item is interpreted as a usage ID.
- If the bSize field equals 3, bits 16-31 of the 4-byte data portion of the item are interpreted as a usage page, and bits 0-15 of the data portion are interpreted as a usage ID. This interpretation of usages applies to Usage, Usage Minimum, and Usage Maximum items.
The notation for a 32-bit usage (sometimes called an extended usage) in the examples is
Usage(Usage Page: Usage ID).

## 3.2 Handling Unknown Usages

If a usage is unknown to an application then the application should ignore it.
If the usage attached to a collection is unknown to an application, then the application should ignore the collection and all usages contained in the collection. A collection can be used to modify the meaning of the usages that it contains, therefore “known” usages within an unknown collection may not represent their original meaning. An example of this is the Usage Selected Indicator on the LED page.
System software provides capabilities for parsing HID Report descriptors. In some cases the usage associated with the top level application collection can be used by the system software as a key to load an application-specific driver or a mapping driver for legacy compatibility.

### 16 Universal Serial Bus HID Usage Tables

## 3.3 Usages and Units

For usages that declare data items as a measurement of time, distance, force, and so forth, an application must look at the units to properly interpret the value defined by a usage, unless:
1. The usage specifically declares Units as optional.
2. The usage description defines the units in which the value will be presented.
If Units are set to Optional or set to None (have not been declared) then an application can assume the usage represents a dimensionless value. Any application that ignores Units does so at its own risk.
A usage that declares itself to be a measurement of time would specify whether it was seconds or milliseconds by declaring Units and Unit Exponent prior to the respective Main item declaration. An example of this is the Flash On Time usage on the LED page, which is described as the duration that the indicator is illuminated in flash mode. The duration would be qualified by the values of Units and Unit Exponent.
When declaring Units for a main item, the Logical Minimum, Logical Maximum, Physical Minimum, Physical Maximum, and Unit Exponent items must also be declared.

In many cases the coordinate system assumes that the values can vary both positively and negatively from zero (0).

## 3.4 Usage Types

Usages define a wide variety of device features. However, the way an application treats the data that they generate falls into a relatively small set of categories. This section provides descriptions of frequently used types of usages, primarily to save redundant text throughout this document. This list is not an exhaustive list of the possible usage types. Individual usage pages can declare their own usage types.
Each usage type describes how an application should treat the data generated by the Main item that the usage is attached to.
Usage type names are followed by an abbreviation that is used in the detailed usage description to identify the default type of a usage. In some cases usage types do not apply and the detailed description will identify how the usage is to be interpreted.
There are three basic types of information that are described by usages: controls, collections, and data. In this context, controls are identified with the state of a device (on/off, enable/disable, and so forth), collections group related controls and data together, and data comprises the remaining information that is passed between a device and the host.

Usage types are always considered to be the recommended method of handling a usage. Consult the usage’s definition to determine whether alternative usage types may apply.

Note

Note

Universal Serial Bus HID Usage Tables | 17

### 3.4.1 Usage Types (Controls)

The following table summarizes the control related usage types.

Table 2: Usage Types (Controls)

Control Type | Logical Min | Logical Max | Flags | Signal | Operation
Linear Control (LC) | –1 | 1 | Relative, Preferred State | Edge | 1 increments the control’s value. –1 decrements the control’s value.
| –Min | Max | Relative, Preferred State | Level | n increments the control’s value. –n decrements the control’s value.
| Min | Max | Absolute, Preferred State | N/A | The value reported by the control is used directly by the host.
On/Off Control (OOC) | -1 | 1 | Relative, No Preferred | Edge | 1 asserts an On condition. –1 asserts an Off condition.
| 0 | 1 | Relative, Preferred State | Edge | A 0 to 1 transition toggles the current On/Off state.
| 0 | 1 | Absolute, No Preferred | Level | 1 asserts an On condition. 0 asserts an Off condition.
Momentary Control (MC) | 0 | 1 | Absolute, Preferred State | Level | 1 asserts a condition. 0 deasserts the condition.
One Shot Control (OSC) | 0 | 1 | Relative, Preferred State | Edge | A 0 to 1 transition triggers an event. A 1 to 0 transition must occur before another event can be triggered.
Re-trigger Control (RTC) | 0 | 1 | Absolute, Preferred State | Level | 1 triggers an event. When an event completes, if the value is 1 then the event will be triggered again.

### 3.4.1.1 Linear Control (LC)

In many cases, a control of a linear value is implemented as a pair of increment/decrement buttons, a jog wheel, or a linear control such as a knob or a slide.
When implemented as an increment/decrement control, the two buttons must be translated into a single, 2-bit signed value and declared as a Relative Main item with a Report Size equal to 2, where –1 decrements the value, +1 increments it, and no change occurs when 0 is asserted.
A jog wheel is normally implemented as a spring-loaded knob that returns to a fixed center position when released. This control reports a single value of two or more bits which are reported as a signed value and declared as a Relative Main item where –n decrements the value, +n increments it, and no change occurs when 0 is asserted. A jog wheel control is implemented with a resolution of +/–n, where the offset of the knob from the center position is proportional to the reported value. The Report Size must be declared large enough to contain the signed value n.
When implemented as a linear knob or slide, the control must be declared as an Absolute Main item. For an example, see Section A.1, “Volume Control,” in Appendix A, “Usage Examples.”

### 18 Universal Serial Bus HID Usage Tables

### 3.4.1.2 On/Off Control (OOC)

An On/Off Control can be implemented in any of the following ways:
- Two buttons, On and Off. The two buttons are encoded into a 2-bit signed value and declared as a Relative, No Preferred Main item with Logical Minimum and Logical Maximum of –1 and 1, respectively. The transition from 0 to –1 generates an Off condition and the transition from 0 to +1 generates an On condition. No change occurs when 0 is asserted.
- A single button that toggles the On/Off state each time it is pressed. (single throw momentary switch The single button is encoded into a 1-bit unsigned value and declared as an Relative, Preferred Main item with a Logical Minimum and Logical Maximum of 0 and 1, respectively. The transition from 0 to 1 toggles the current On/Off state. No change occurs on the 1 to 0 transition.
- A toggle switch that maintains the On/Off state mechanically. (toggle switch) This control is encoded into a 1-bit unsigned value and declared as an Absolute, No Preferred Main item with a Logical Minimum and Logical Maximum of 0 and 1, respectively. The assertion of 1 generates an On condition and the assertion of 0 generates an Off condition.

### 3.4.1.3 Momentary Control (MC)

A Momentary Control is a basic push button. A Momentary Control is encoded into a 1-bit value and declared as an Absolute, Preferred Main item with a Logical Minimum and Logical Maximum of 0 and 1, respectively. A value of 1 generates an asserted condition and 0 generates a non-asserted condition. An example is a mouse button.

### 3.4.1.4 One Shot Control (OSC)

A One Shot Control is a push button that triggers a single event or action. A One Shot Control is encoded into a 1-bit value and declared as a Relative, Preferred Main item with a Logical Minimum and Logical Maximum of 0 and 1, respectively. A 0 to 1 transition initiates an event. Nothing occurs on a 1 to 0 transition but it is required before another event can occur. An example is degauss.

### 3.4.1.5 Re-Trigger Control (RTC)

A Re-Trigger Control is a push button that triggers a repeating event as long as it is asserted. A Re-Trigger Control is encoded into a 1-bit value and declared as an Absolute, Preferred Main item with a Logical Minimum and Logical Maximum of 0 and 1, respectively. A 0 to 1 transition initiates the first event. When each event terminates, if the control is still asserted (1) then another event will occur. An example is an auto-repeat fire button.

### 3.4.2 Usage Types (Data)

The following table summarizes the data-related usage types.

Table 3: Usage Types (Data)

Type | Flags | Description
Selector (Sel) | Array | Contained in a Named Array (NAry).
Static Value (SV) | Constant, Variable, Absolute | A read-only multiple-bit value.
Static Flag (SF) | Constant, Variable, Absolute | A read-only single-bit value.
Dynamic Value (DV) | Data, Variable, Absolute | A read/write multiple-bit value.
Dynamic Flag (DF) | Data, Variable, Absolute | A read/write single-bit value.

Universal Serial Bus HID Usage Tables | 19

### 3.4.2.1 Selector (Sel)

Selectors come in three forms:
- One selection of a set. Radio buttons are a mechanically linked set of buttons where one selection is always valid. This is a perfect example of the “one selection of a set” form. A radio button set is defined by a Main item with the Array flag set and the Report Count set to 1. The index returned in the array field corresponds to the pressed button (or selection). A usage must be declared for each selection. The array field never returns an index of NULL because one usage is always valid. An example is Stat Not Ready on the Alphanumeric Display page.
- N selections of a set. More than one selection (button) can be valid at a time. Multiple selections can be returned to the system at one time in a multi-byte array. The “n selections of a set” form is defined by a Main item with the Array flag set and the Report Count set to n, where n is the number of selections that can be reported in a single report. An example is a keyboard.
- Any selection of a set. The control is implemented as a set of bit fields in which each bit represents a single selection. This control is defined by a Main item with the Variable flag set and the Report Size equal to 1. The Report Count will be equal to the number of selections in the set.
Selectors therefore can be implemented in a number of ways: Array[1] (one selection of a set), Array[n] (n selections of a set), or bitmap (any selection of a set).
Optionally, the array field or set can be named by wrapping a set of Selectors in a logical collection with a usage attached to it. For details, see Section 3.4.3.1, “Named Array (NAry).”

### 3.4.2.2 Static Value (SV)

Static values are used to declare a fixed features in a device. They are defined as Constant and treated as read-only information. Therefore, asserting this field in a Set_Report command has no defined effect.

### 3.4.2.3 Static Flag (SF)

Static flags are used to declare the existence of a fixed feature in a device. If a Static Flag usage is found in a Report descriptor then the field must be read to determine whether the feature identified by the flag exists. A value of 1 indicates existence and a value of 0 indicates non-existence. The absence of a Static Flag usage implies that the flag is false or the feature defined by the flag is not supported by the device. A Static Flag must be declared as a Constant. To be accessible by applications, a Static Flag must have a usage assigned to it.
Static Flags are typically declared in a Feature report as a single-bit field where the value is always read as
1. Attempting to modify this field in a Set_Report command has no effect on a Static Flag.

### 3.4.2.4 Dynamic Flag (DF)

Dynamic Flags are used to declare the existence of a host-controllable feature in a device. The absence of a Dynamic Flag usage implies that the flag is false or the feature defined by the flag is not supported by the device.
Dynamic Flags are typically declared in a report as a single-bit field, where a value of 1 returned by the device indicates that the feature is enabled. The assertion of 1 by the host will cause the feature to be evoked and the assertion of 0 indicates that the feature is to be disabled or ignored if the feature is a one-time event (such as Degauss or Clear Display). A Dynamic Flag Main item must be declared as Data.

### 20 Universal Serial Bus HID Usage Tables

### 3.4.2.5 Dynamic Value (DV)

A Dynamic Value is an n-bit field that contains a value associated with a control. The associated Main item will have the Data and Variable flags set. A Dynamic Value Main item must be declared as Data.

More advanced devices may allow a usage declared as a Static type to be Dynamic. Always check the Constant/Data flag in an Input, Output or Feature Main item.

### 3.4.3 Usage Types (Collection)

The following table summarizes the collection-related usage types.

Table 4: Usage Types (Collection)

Type | Collection Type | Definition
Named Array (NAry) | Logical | A collection that encompasses an array definition, naming the array set or the field created by the array.
Application Collection (CA) | Application | Applies a name to a top level collection which the operating system uses to identify a device and possibly remap to a legacy API.
Logical Collection (CL) | Logical | A logical collection of items.
Physical Collection (CP) | Physical | A physical collection of items.
Usage Switch (US) | Logical | Modifies the purpose or function of the usages (controls) that it contains.
Usage Modifier (UM) | Logical | Modifies the purpose or function of the usages (controls) that contains it.

### 3.4.3.1 Named Array (NAry)

To simplify for an application the process of finding a set of selectors, whether defined as an Array Field or a bitmap, the set of selectors can be named by wrapping them in a logical collection and applying a usage to the collection. Usages applied in this way are called Named Array usages. For an example, see Section A.4, “Named Array Field,” in Appendix A, “Usage Examples.”

### 3.4.3.2 Collection Application (CA)

The Collection Application usage type identifies usages that are used only in application-level collections. An application collection identifies a HID device or a functional subset of a complex device. An operating system uses the usage associated with this collection to link the device to its controlling application or driver. Common examples are a keyboard or mouse. A keyboard with an integrated pointing device could contain two different application collections.

Data reports cannot span application collections.

### 3.4.3.3 Collection Logical (CL)

The Collection Logical usage type identifies a usage applied to a logical collection. Logical collections can be used to further define the purpose of the items or controls that they contain.

Note

Note

Universal Serial Bus HID Usage Tables | 21

### 3.4.3.4 Collection Physical (CP)

The Collection Physical usage type identifies a usage applied to a physical collection, usually a collection of axes. A physical collection is used for a set of data items that represent data points collected at one geometric point. This is useful for sensing devices that may need to associate sets of measured or sensed data with a single point. It does not indicate that a set of data values comes from one device, such as a keyboard. In the case of a device that reports the position of multiple sensors, physical collections are used to show which data comes from which sensor.

### 3.4.3.5 Usage Switch (US)

The Usage Switch usage type identifies a usage applied to a logical collection that modifies the purpose of the usages in that collection. An example is indicators. To avoid having to define a usage for every control that could possibly use an indicator (for example, Play/Play Indicator, etc.) a Usage Switch collection can be wrapped around a usage (Play) to create a indicator for the same function. Usage Switches often modify the type of the contained usage as well.

### 3.4.3.6 Usage Modifier (UM)

The Usage Modifier usage type identifies a usage applied to a logical collection. This logical collection is always contained in another logical collection. The purpose and possibly the type of the usage attached to the encompassing collection is modified. For instance the usage attached to the encompassing collection may not normally be defined as a collection. For an example, see Section A.6, “Multiple Instances of a Multi-Mode LED,” in Appendix A, “Usage Examples.”

### 3.4.4 Alternate Types

Usage types are a guide, not the rule. The flags, Logical Minimum and Logical Maximum values, and other Main item attributes must be evaluated by applications and system software to determine the true purpose, meaning, or interpretation of a control.
In many cases, a usage can take on the attributes of a usage type other than its default type. The alternate type can be declared by a collection in which the usage is found or implied by the way it is declared in a Report descriptor. For example, Usage In Use Indicator from the LED page is an example of an alternate usage type being applied to a usage. When a usage is wrapped in a Usage In Use Indicator collection, it becomes an On/Off Control (OOC).
In other cases, a usage can be declared as either a Static Value (SV) or a Dynamic Value (DV). For example, in a screen saver, the Screen Saver Delay might be fixed on one device and variable on another. The same thing can happen with usages declared as Static Flag (SF) or Dynamic Flag (DF).
Another example is a usage that is declared as either an On/Off Control (OOC) or a Selector (Sel). A device that can support a variety of operational modes will declare individual bits as On/Off Controls to identify which modes are enabled. However, when the device is running, only one mode will be in effect at a time. The device would then declare the same usage as a Selector and report this in a Named Array field to identify the mode associated with the current data. For example, a tape transport could have three states: Stopped, Paused, and Playing. This could be implemented as three individual bits where only one bit is true at a time, or as a 2-bit field in which 0 = Stopped, 1 = Paused, and 3 = Playing.

### 22 Universal Serial Bus HID Usage Tables

## 3.5 System Controls

Applications look at the usage applied to top-level application collections to identify devices. System software that supports keyboards, mice, and joysticks follow the same conventions. If a device vendor wants a device to be recognized by the system software as one of these devices, then the device must follow the conventions described in this section.

### 3.5.1 Keyboard

Typical system software will search for application collections tagged with either a Keyboard or a Keypad usage. When found, the usages contained in these collections will be treated as standard system keyboard input. All devices that use these declarations will have their output routed to the same destination. That is, typing on any device will affect the active application.

### 3.5.2 Mice

Typical system software will search for application collections tagged with either a Mouse or a Pointer usage. When found, the usages generated by these collections will be treated as standard system pointer input. All devices that use these declarations will have their output routed to the same destination. That is, moving any mouse will affect the system pointer.

### 3.5.3 Joysticks

Typical system software will search for application collections tagged with either a Joystick or a Game Pad usage. When found, the usages generated by these collections will be treated as standard system joystick (gaming device) input. Devices that use these declarations will have their output routed to separate destinations, allowing multiple-player applications.

## 3.6 HID LANGIDs

This section identifies a set of conventions that allow static data to be associated with individual controls. These conventions are an extension of the string descriptors that can currently be attached to controls.
The first two bytes of a USB string descriptor define the length and type of the descriptor, respectively. The byte wide length field allows a "string" to be up to 253 bytes long. The second byte of a string is always the "String" descriptor type (0x03). These bytes are followed by 16-bit UNICODE characters.

Figure 1: String Descriptor

Part | Offset/Size (Bytes) | Description | Sample Value
bLength | 0/1 | Size of this descriptor in bytes. | 0x06
bDescriptorType | 1/1 | String (assigned by USB). | 0x03
bString | 2/bLength-2 | UNICODE encoded string | 0x0041, 0x0042 = ("AB")

Strings on a HID device are accessed using a Language ID (LANGID) and a string index. The LANGID is a 16-bit value where the low order 10 bits are "Primary Language ID" and the high order 6 bits are the "Sublanguage ID". The Primary Language ID 0xFF has been permanently assigned to the HID class for it's use. The Sublanguage IDs are defined in Table 5. The String Index, String Minimum and String Maximum local items allow string indices to be associated with individual main items.

Universal Serial Bus HID Usage Tables | 23

Figure 2: LANGID Format

15 | 14 | 13 | 12 | 11 | 10 | 9 | 8 | 7 | 6 | 5 | 4 | 3 | 2 | 1 | 0
Sublanguage ID Assigned by HID | | | | | | Primary Language ID 0x0FF (HID)

Individual usages define which HID LANGIDs they support and any support information the LANGID may require.

### Remarks:

- If a device declares LANGID's other than HID LANGID then return an empty string if there is no valid Unicode representation for it.
- All values are transmitted with little-endian byte alignment and in packed structures unless otherwise stated in the Usage description.
HID LANGIDs define how their associated string data is to be interpreted.
String descriptors are global to a device and assumed to be static, therefore cacheable. If a device requires that the Private Data varies as a function Configuration or Interface settings then a device must use non-overlapping indices to ensure that string caches do not need to be invalidated,
To implement HID LANGIDs the following steps are required:
1) String index 0 always defines a list of the LANGIDs supported by the HID device. A HID LANGID must be included in the list.
2) Any main item that utilizes HID LANGIDs must have a string index attached to it, using String Index, String Minimum or String Maximum local items.
3) A "string" must be returned by the device, which contains the data identified by the LANGID.
To access a HID LANGID string associated with a control, the host will send a GetDescriptor(STRING_DESCRIPTOR, HID_LANGID, String Index) request to the device, where STRING_DESCRIPTOR = 0x03, the HID_LANGID is defined in table ??, and the String Index is defined the String local item associated with the control.
Figure 3: GetDescriptor(String) Request
Part | Offset/Size (Bytes) | Description | Sample Value
bmRequestType | 0/1 | Device to Host, Standard, Device | 10000000B
bRequest | 1/1 | GET_DESCRIPTOR | 0x06
WValue (High) | 2/1 | STRING_DESCRIPTOR | 0x03
WValue (Low) | 3/1 | String Index
wIndex | 4/2 | HID(Usage Defined)
wLength | 6/2 | Length of string

See the Consumer Control:Equalizer Gain usage for an example that employs a HID LANGID.

### 24 Universal Serial Bus HID Usage Tables

Table 5: HID Sublanguage IDs
Sublanguage ID | LANGID Name | Description
0x00 | | Reserved
0x01 | Usage Data Descriptor | Allows a usage to define a data structure that is specific to the usage.
0x02 - 0x3B | | Reserved
0x3C | Vendor Defined HID LANGID 1
0x3D | Vendor Defined HID LANGID 2
0x3E | Vendor Defined HID LANGID 3
0x3F | Vendor Defined HID LANGID 4

### 3.6.1 Usage Data Descriptor (0x01)

This HID LANGID allows a usage to define a private descriptors. A usage that requires private data must define the format of the block of data associated with the usage. The first two bytes of the table are identical to those defined in a standard USB string descriptor: bLength and bDescriptorType. The size and number of remaining fields depends on the Usage.

Figure 4: Usage Data Descriptor

Part | Offset/Size (Bytes) | Value | Description
bLength | 0/1 | Number | Size of this descriptor in bytes
bDescriptorType | 1/1 | Constant | String (assigned by USB)
Field 1 | 2/Field 1 size | Usage Dependent | Usage defined fields
Field 2 | Field 1 offset + Field 1 size /Field 2 size | Usage Dependent
Field 3 | Field 2 offset + Field 2 size /Field 3 size | Usage Dependent
… | … | Usage Dependent
Field n | Field n-1 offset + Field n-1 size /Field n size | Usage Dependent

### 3.6.2 Vendor Defined HID LANGID (0x3C - 0x3F)

Four HID LANGIDs are reserved for vendor specific use. The first two bytes of the table are identical to those defined in a standard USB string descriptor, and up to 253 bytes of data can be defined by the vendor. Note that Vendor Defined HID LANGIDs allow a vendor to associate additional data with a standard usage. For Vendor Defined usages, the Usage Descriptor LANGID may also be used, since the definition of the Usage Descriptor depends on the Vendor Defined usage.
The data types supported by Usage Descriptors can expand on those already supported by standard USB descriptors. These can include 64-bit signed and unsigned integers, 32, 64 and 128-bit IEEE format floating

Universal Serial Bus HID Usage Tables | 25

point, etc. The Usage Descriptor defined by the usage will provide detailed information about the data types that are used.
Figure 5: Vendor Defined Descriptor
Part | Offset/Size (Bytes) | Value | Description
bLength | 0/1 | Number | Size of this descriptor in bytes
bDescriptorType | 1/1 | Constant | String (assigned by USB)
Vendor Defined Data | 2/n (n <= 253) | Vendor Defined | Vendor defined fields

### 26 Universal Serial Bus HID Usage Tables

## 4 Generic Desktop Page (0x01)

Table 6: Generic Desktop Page

Usage ID | Usage Name | Usage Type | Section
00 | Undefined
01 | Pointer | CP | 4.1
02 | Mouse | CA | 4.1
03 | Reserved
04 | Joystick | CA | 4.1
05 | Game Pad | CA | 4.1
06 | Keyboard | CA | 4.1
07 | Keypad | CA | 4.1
08 | Multi-axis Controller | CA | 4.1
09 | Tablet PC System Controls | CA | 4.1
0A-2F | Reserved
30 | X | DV | 4.2
31 | Y | DV | 4.2
32 | Z | DV | 4.2
33 | Rx | DV | 4.2
34 | Ry | DV | 4.2
35 | Rz | DV | 4.2
36 | Slider | DV | 4.3
37 | Dial | DV | 4.3
38 | Wheel | DV | 4.3
39 | Hat switch | DV | 4.3
3A | Counted Buffer | CL | 4.6
3B | Byte Count | DV | 4.6
3C | Motion Wakeup | OSC | 4.3
3D | Start | OOC | 4.3
3E | Select | OOC | 4.3
3F | Reserved
40 | Vx | DV | 4.3.1
41 | Vy | DV | 4.3.1
42 | Vz | DV | 4.3.1
43 | Vbrx | DV | 4.3.1
44 | Vbry | DV | 4.3.1
45 | Vbrz | DV | 4.3.1
46 | Vno | DV | 4.3.1
47 | Feature Notification | DV,DF | 4.8

Universal Serial Bus HID Usage Tables | 27
Usage ID | Usage Name | Usage Type | Section
48 | Resolution Multiplier | DV
49-7F | Reserved
80 | System Control | CA | 4.5
81 | System Power Down | OSC | 4.5
82 | System Sleep | OSC | 4.5.1
83 | System Wake Up | OSC | 4.5.1
84 | System Context Menu | OSC | 4.5
85 | System Main Menu | OSC | 4.5
86 | System App Menu | OSC | 4.5
87 | System Menu Help | OSC | 4.5
88 | System Menu Exit | OSC | 4.5
89 | System Menu Select | OSC | 4.5
8A | System Menu Right | RTC | 4.5
8B | System Menu Left | RTC | 4.5
8C | System Menu Up | RTC | 4.5
8D | System Menu Down | RTC | 4.5
8E | System Cold Restart | OSC | 4.5.1
8F | System Warm Restart | OSC | 4.5.1
90 | D-pad Up | OOC | 4.7
91 | D-pad Down | OOC | 4.7
92 | D-pad Right | OOC | 4.7
93 | D-pad Left | OOC | 4.7
94-9F | Reserved
A0 | System Dock | OSC | 4.5.1
A1 | System Undock | OSC | 4.5.1
A2 | System Setup | OSC | 4.5.1
A3 | System Break | OSC | 4.9
A4 | System Debugger Break | OSC | 4.9
A5 | Application Break | OSC | 4.9
A6 | Application Debugger Break | OSC | 4.9
A7 | System Speaker Mute | OSC | 4.5.1
A8 | System Hibernate | OSC | 4.5.1
A9-AF | Reserved
B0 | System Display Invert | OSC | 4.10
B1 | System Display Internal | OSC | 4.10
B2 | System Display External | OSC | 4.10
B3 | System Display Both | OSC | 4.10
B4 | System Display Dual | OSC | 4.10
B5 | System Display Toggle Int/Ext | OSC | 4.10

### 28 Universal Serial Bus HID Usage Tables

Usage ID | Usage Name | Usage Type | Section
B6 | System Display Swap Primary/Secondary | OSC | 4.10
B7 | System Display LCD Autoscale | OSC | 4.10
B8-FFFF | Reserved

## 4.1 Application Usages

Pointer | CP – A collection of axes that generates a value to direct, indicate, or point user intentions to an application.
Mouse | CA – A hand-held, button-activated input device that when rolled along a flat surface, directs an indicator to move correspondingly about a computer screen, allowing the operator to move the indicator freely in select operations or to manipulate text or graphics. A mouse typically consists of two axes (X and Y) and one, two, or three buttons.
Joystick | CA – A manual control or cursor device. A joystick minimally consists of two variable axes (X and Y) and two buttons. A joystick is typically a rotational motion sensor. However, for legacy reasons, it is defined using linear axes.
| Traditionally, a joystick driver applies its own scaling to values returned from a joystick. That is, the driver simply linearizes and translates the range of values generated by the stick into normalized values between 0 and 64K, where 32K is centered. The application (game) then interprets the normalized values as necessary. Because of this, joysticks normally do not declare Units or Physical Minimum and Physical Maximum values for their axes. Depending on the driver, these items may be ignored if they are declared.
Game Pad | CA – A manual control or cursor device. A game pad minimally consists of a thumb-activated rocker switch that controls two axes (X and Y) and has four buttons. The rocker switch consists of four contact closures for up, down, right, and left.
Keyboard | CA – The primary computer input device. A Keyboard minimally consists of 103 buttons as defined by the Boot Keyboard definition. For details, see Appendix A of the HID Specification.
Keypad | CA – Any keyboard configuration that does not meet the minimum requirements of the Boot Keyboard. Keypad often refers to a supplementary calculator-style keyboard.
Multi-axis Controller | CA - An input device used to orient eyepoints and or objects in 3 dimensional space. A Multi-axis Controller typically consists of six, variable axes (X, Y, Z, Rx, Ry and Rz) and is used by CAD/digital content creation applications for model manipulation and visualization in 3D space. The device may incorporate zero or more buttons.
Tablet PC System Controls | CA – System controls on Tablet PCs. This collection is not intended to contain display or audio data nor touchscreen input. Appropriate controls might be buttons, wheels, or simple indicators. This collection is intended to be opened by the operating system in exclusive mode and is not meant for

Universal Serial Bus HID Usage Tables | 29

application developers to open directly.

## 4.2 Axis Usages

For X, Y, Z, Rx, Ry, and Rz, the declaration of Units is optional. If Units is None or not declared, these values should be considered as dimensionless.
X | DV – A linear translation in the X direction. Report values should increase as
the control’s position is moved from left to right.
Y | DV – A linear translation in the Y direction. Report values should increase as
the control’s position is moved from far to near.
Z | DV – A linear translation in the Z direction. Report values should increase as
the control’s position is moved from high to low (Z).
Rx | DV – A rotation about the X axis. Angular position report values follow the
righthand rule.
Ry | DV – A rotation about the Y axis. Angular position report values follow the
righthand rule.
Rz | DV – A rotation about the Z axis. Angular position report values follow the
righthand rule.

## 4.3 Miscellaneous Controls

Slider | DV – A linear control for generating a variable value, normally in the form of
a thumb slide in a slot. Report values should increase as controls are moved from near to far.
Dial | DV – A rotary control for generating a variable value, normally in the form of
a knob spun by the index finger and thumb. Report values should increase as controls are spun clockwise. This usage does not follow the HID orientation conventions.
Wheel | DV – A rotary control for generating a variable value, normally rolled, unlike
a dial. Report values should increase as controls are rolled forward, away from the user. This usage does not follow the HID orientation conventions.
Hat Switch | DV – A specialized mechanical configuration of switches generating a
variable value with a null state. The switches are arranged around a springloaded knob. When the knob is tilted in the direction of a switch, its contacts are closed. A typical example is four switches that are capable of generating information about four possible directions in which the knob can be tilted. Intermediate positions can also be decoded if the hardware allows two switches to be reported simultaneously.
Motion Wakeup | DF – Enables the generation of a USB remote wakeup when the device
detects motion. Motion Wakeup is always enabled after a USB Reset event is detected by the device. Then host can also assume that the state of the Motion Wakeup flag is maintained while the device is suspended.

### 30 Universal Serial Bus HID Usage Tables

For example, a mouse may generate a remote wakeup when a button is pressed or when it is moved. For some implementations, a laptop user may want to disable the wakeup on motion because it draws more power.
Start | OOC - Session start button. Initiates a session within an application .
Select | OOC - Application option select button. Selects application configuration
options.
Resolution Multiplier DV - DV Defines a Resolution Multiplier for a Control

### 4.3.1 Resolution Multiplier

A HID device describes the resolution of a control by using the methods described in the HID Specification, v1.11, section 6.2.2.7 “Global Items – Remarks”. However, the resolution of a control in this model is static. If a device has the capability to vary the resolution of one or more of its controls, the resolution of those controls can be set by defining an associated Resolution Multiplier control.
The Resolution Multiplier control must be contained in the same Logical Collection as the control(s) to which it is to be applied. If no Resolution Multiplier is defined, then the Resolution Multiplier defaults to 1. If more than one control exists in a Logical Collection, the Resolution Multiplier is associated with all controls in the collection. If no Logical Collection is defined, the Resolution Multiplier is associated with all controls in the report.
The Resolution Multiplier is applied after all the normal resolution calculations have been performed for an affected control. The Resolution Multiplier is calculated as below:
( | ) | UnitExponent PMax PMin | PMin

### LMax LMin

RMV LMin EffectiveResolutiuonMultiplier | * | 10*⎟
⎟
⎠

⎞ ⎜
⎜
⎝
⎛ | ⎟ + ⎠
⎞ ⎜
⎝
⎛ | − −

− =

where RMV = Resolution Multiplier Value, LMin = Logical Minimum, LMax = Logical Maximum, PMin = Physical Minimum, and PMax = Physical Maximum
For example, if a Wheel Control is defined as below:
Usage Page Generic Desktop (0x01)
Usage (Wheel) (0x38)
Logical Minimum -127
Logical Maximum 127
Report Count 1
Report Size 8
Input (Data, Var, Rel)

then the Wheel control delivers one count per “detent” via a 1-byte field of an Input Report. However if a Resolution Multiplier feature is included in the report with the Wheel as below: Collection (Logical)
Usage Page Generic Desktop (0x01) Usage Resolution Multiplier (0x48) Logical Minimum 0
Logical Maximum 15
Physical Minimum 1
Physical Maximum 16
Report Size 4
Report Count 1
Feature (Data, Var, Abs)

Universal Serial Bus HID Usage Tables | 31

Usage Page Generic Desktop (0x01) Usage (Wheel) (0x38)
Logical Minimum -127
Logical Maximum 127
Report Count 1
Report Size 8
Input (Data, Var, Rel)
End Collection

...then the Effective Resolution Multiplier for the Wheel may vary from 1 to 16 depending on the setting of the Resolution Multiplier feature. If the Resolution Multiplier feature is set to 7, then the Effective Resolution Multiplier is 8, meaning that the resolution of the Wheel control is 8 counts per detent. Negative Effective Resolution Multipliers may be used to reverse the sense of a control.
Because OS implementations will generally divide the control's reported count by the Effective Resolution Multiplier, designers should take care not to establish a potential Effective Resolution Multiplier of zero. This may be done by ensuring that Physical Min and Physical Max are nonzero and have the same sign. The Resolution Multiplier is a scalar (unitless) multiplier. It may not be used to convert units from one system to another.

## 4.4 Vector Usages

For the usages Vx, Vy, Vz, Vbrx, Vbry, Vbrz, and Vno, Units are always required to determine the meaning of the vector. Rotational vectors are also identified by Units. These usages are used when declaring velocity, acceleration, force, electric field, and similar kinds of vectors in the respective direction and frame of reference.
Vx | DV – A vector in the X direction. Report values should increase as the vector
increases in the positive X direction (from left to right). Negative values represent vectors in the negative X direction.
Vy | DV – A vector in the Y direction. Report values should increase as the vector
increases in the positive Y direction (from far to near). Negative values represent vectors in the negative Y direction.
Vz | DV – A vector in the Z direction. Report values should increase as the vector
increases in the positive Z direction (from high to low). Negative values represent vectors in the negative Z direction.
Vbrx | DV – A vector in the X direction relative to the body of an object. Report
values should increase as the vector increases in the positive X direction (forward). Negative values represent vectors in the negative X direction. X is the “forward” axis for an object.
Vbry | DV – A vector in the Y direction relative to the body of an object. Report
values should increase as the vector increases in the positive Y direction (to the right from an observer facing forward on the object). Negative values represent vectors in the negative Y direction.
Vbrz | DV – A vector in the Z direction relative to the body of an object. Report
values should increase as the vector increases in the positive Z direction (down from an observer facing forward on the object). Negative values represent vectors in the negative Z direction.
Vno | DV– A non oriented vector or value. The units define a physical measurement
not related to a specific axis or orientation. An example would be pressure or

### 32 Universal Serial Bus HID Usage Tables

temperature.

## 4.5 System Controls

System controls are a special category of usages that affect the system as a whole. They are pulled together in a System Control collection to make them easy for system software to identify.
System Control | CA – A application-level collection that contains system-software-specific usages. System software will search specifically for this collection for those controls that affect the system globally.
System Context Menu | OSC – Evokes a context-sensitive menu.
System Main Menu | OSC – Evokes the OS main-level selection menu.
System App Menu | OSC – Displays an application-specific menu.
System Menu Help | OSC – Displays the help menu.
System Menu Exit | OSC – Exits a menu.
System Menu Select | OSC – Selects a menu item.
System Menu Right | RTC – Menu select right.
System Menu Left | RTC – Menu select left.
System Menu Up | RTC – Menu select up.
System Menu Down | RTC – Menu select down.

### 4.5.1 Power Controls

Power controls can step the system through the following states: Full Power, Low Power, and Power Down. The state diagram is shown in the following figure.
Figure 6: System Power States

Power control usages found in a System Control collection affect system level power. Those declared outside of a System Collection affect device level power.

Universal Serial Bus HID Usage Tables | 33
System Power Down | OSC – Asserted when the intended action is to initiate system-wide power down now from Full Power or Sleep states.
System Sleep | OSC – Asserted when the intended action is to initiate system-wide low power mode now. If the system is already in the Low Power state, there is no effect.
System Wake Up | OSC – Asserted when the intended action is to initiate system-wide Full Power state now. If the system is already in the Full Power, there is no effect.
System Cold Restart | OSC – Asserted when the intended action is to restart the system at the most primitive level, similar to at Power Up
System Warm Restart | OSC – Asserted when the intended action is to restart the operating system but not necessarily the lowest level functions such as BIOS enumeration and RAM checks.
System Dock | OSC – Asserted when the intended action is to prepare a portable system for docking with a docking station.
System Undock | OSC – Asserted when the intended action is to prepare a portable system for removal from a docking station.
System Setup | OSC – Asserted when the intended action is to enter the BIOS-level system setup program
System Speaker Mute | OSC – Asserted when the intended action is to mute the system speaker.
System Hibernate | OSC – Asserted when the intended action is to place the system in a "deeper" sleep state than System Sleep

## 4.6 Buffered Bytes

The following usages provide a standard way of defining the operation of a buffered-byte field where the number of valid bytes in the field is less than the total number of bytes in the field and the vendor does not define a NoOp value to mark unused bytes.
When declaring a buffered-byte field, the global item Report Size should always be set to 8 (for byte cells), and the Report Count should be equal to the maximum size of the buffer to be transferred.
Counted Buffer | CL – Used with buffered –byte data to indicate the number of valid bytes in the buffered-byte field. This collection always contains two field declarations: Byte Count and a usage that names the purpose of the buffered-byte field. The Main item associated with the purpose usage will always have the Buffered Bytes attribute set.
Byte Count | DV – Defines a report field that indicates the number of meaningful data bytes in an associated buffered-byte field.

## 4.7 Direction Pads

A Direction Pad or D-Pad control is mechanically identical to a hatswitch, however for legacy reasons their data is interpreted as X and Y axes rather than as an angular direction.
D-pads are typically defined as a pair of X and Y axes that are contained in a logical Pointer collection. There are cases where an application may be interested in the raw D-pad data. The following usages are

### 34 Universal Serial Bus HID Usage Tables

defined in a report descriptor as single bit fields that identify the current state of the position switches in the D-pad.
Note: A device may declare a Pointer collection with X and Y axes, and D-pad usages for the same control. An application can determine which data format best suits it's needs.
D-pad Up | OOC – Indicates that top of a Direction Pad is pressed
D-pad Down | OOC – Indicates that bottom of a Direction Pad is pressed
D-pad Right | OOC – Indicates that right side of a Direction Pad is pressed
D-pad Left | OOC – Indicates that left side of a Direction Pad is pressed

## 4.8 Feature Notifications

It may be useful to alert the host that the contents of a Feature report have changed without redundantly declaring a usage in an Input report, especially is the changes are only occasional. The Feature Notification usages provides a mechanism for doing this.
Feature Notification | DV – This usage is declared in an Input report and is used as a notification to the host that the contents of a specific Feature report has changed.
| If Report IDs are declared in the device's report descriptor then the Report Size of the Feature Notification must be greater than 1, and the Feature Notification field contains the Report ID of the Feature report that whose contents have changed. A zero value indicates that no Feature reports have changed. Multiple Feature report IDs can be reported in a single Input report by declaring the Report Count to be greater than 1.
| If Report IDs are not declared in the device's report descriptor then the Report Size of the Feature Notification equals 1, and the Input report field equals 1 if the Feature report contents have changed. A zero value indicates that no Feature reports have changed.
| When a valid Feature Notification is received, the host must issue a GetReport(Feature) request to the device with the appropriate report ID.

## 4.9 Software Flow Controls

The following usages provide standard controls to break into the current operation of the system.
System Break | OSC – Asserted when the intended action is to acquire the attention of the operating system in order to control applications. This operation could interrupt all running applications.

System Debugger Break OSC - Asserted when the intended action is to break into the operating
| system debugger. If no OS debugger is running, the control is ignored.
Application Break | OSC - Asserted when the intended action is to acquire the attention of an application. This operation interrupts only the foremost running application.

Application Debugger Break
| OSC - Asserted when the intended action is to break into the application debugger. If no application debugger is running, the control is ignored.

Universal Serial Bus HID Usage Tables | 35

## 4.10 System Display Controls

Many systems currently support multiple displays. Of special note are portable systems with captive displays that may be connected to external displays. The following usages provide standard controls for common display control functions:
System Display Invert OSC - Causes the display to render in inverted colors.
System Display Internal OSC - Causes the system to use the captive display as the primary display. System Display External OSC - Causes the system to use the external display as the primary display.
System Display Both | OSC - Causes the system to use both internal and external displays as the primary display
System Display Dual | OSC - Causes the system to use both internal and external displays as primary and secondary displays.

System Display Toggle Int/Ext Mode
| OSC - Causes a system to step between the modes as described above: System Display Internal System Display External System Display Both

System Display Swap Pri/Sec
| OSC - Causes a system using two displays in dual mode to swap the primary and secondary displays.

System Display Toggle LCD Autoscale
| OSC - Causes a system with a non-scaleable geometry, such as an LCD, to scale the display image to fit the physical geometry of the display.

### 36 Universal Serial Bus HID Usage Tables

## 5 Simulation Controls Page (0x02)

This section provides detailed descriptions of the usages employed by simulation devices.

Table 7: Simulation Controls Page

Usage ID | Usage Name | Usage Type | Section
00 | Undefined
01 | Flight Simulation Device | CA | 5.2
02 | Automobile Simulation Device | CA | 5.3
03 | Tank Simulation Device | CA | 5.4
04 | Spaceship Simulation Device | CA | 5.2
05 | Submarine Simulation Device | CA | 5.5
06 | Sailing Simulation Device | CA | 5.5
07 | Motorcycle Simulation Device | CA | 5.6
08 | Sports Simulation Device | CA | 5.1
09 | Airplane Simulation Device | CA | 5.2
0A | Helicopter Simulation Device | CA | 5.2
0B | Magic Carpet Simulation Device | CA | 5.7
0C | Bicycle Simulation Device | CA | 5.6
0D – 1F | Reserved
20 | Flight Control Stick | CA | 5.2
21 | Flight Stick | CA | 5.2
22 | Cyclic Control | CP | 5.2
23 | Cyclic Trim | CP | 5.2
24 | Flight Yoke | CA | 5.2
25 | Track Control | CP | 5.4
26 –AF | Reserved
B0 | Aileron | DV | 5.2
B1 | Aileron Trim | DV | 5.2
B2 | Anti-Torque Control | DV | 5.2
B3 | Autopilot Enable | OOC | 5.2
B4 | Chaff Release | OSC | 5.2
B5 | Collective Control | DV | 5.2
B6 | Dive Brake | DV | 5.2
B7 | Electronic Countermeasures | OOC | 5.2
B8 | Elevator | DV | 5.2
B9 | Elevator Trim | DV | 5.2
BA | Rudder | DV | 5.2
BB | Throttle | DV | 5.2
BC | Flight Communications | OOC | 5.2

Universal Serial Bus HID Usage Tables | 37
Usage ID | Usage Name | Usage Type | Section
BD | Flare Release | OSC | 5.2
BE | Landing Gear | OOC | 5.2
BF | Toe Brake | DV | 5.2
C0 | Trigger | MC | 5.2
C1 | Weapons Arm | OOC | 5.2
C2 | Weapons Select | OSC | 5.2
C3 | Wing Flaps | DV | 5.2
C4 | Accelerator | DV | 5.3
C5 | Brake | DV | 5.3
C6 | Clutch | DV | 5.3
C7 | Shifter | DV | 5.3
C8 | Steering | DV | 5.3
C9 | Turret Direction | DV | 5.4
CA | Barrel Elevation | DV | 5.4
CB | Dive Plane | DV | 5.5
CC | Ballast | DV | 5.5
CD | Bicycle Crank | DV | 5.6
CE | Handle Bars | DV | 5.6
CF | Front Brake | DV | 5.6
D0 | Rear Brake | DV | 5.6
D1-FFFF | Reserved

## 5.1 Sports Simulation Device

Usages employed by Stick Devices and Exercise Machines are defined on the Sports Controls page. For details, see Section 7, “Sport Controls Page (0x04).”
Sports Simulation
Device

CA – This usage definition allows a device to be generally classified as one that uses standard controls found on a sports simulation device.

## 5.2 Flight Simulation Devices

Flight Simulation
Device

CA – This usage definition allows a device to be generally classified as one that uses the standard controls found on an airplane.
Spaceship Simulation
Device

CA – This usage definition allows a device to be generally classified as one that uses standard controls found on a spaceship.
Airplane Simulation
Device

CA – This usage definition allows a device to be generally classified as one that uses standard controls found on an airplane.
Helicopter Simulation
Device

CA – This usage definition allows a device to be generally classified as one that uses standard controls found on a helicopter.

### 38 Universal Serial Bus HID Usage Tables

Aileron | DV – An aileron is one of two movable flaps on the wings of an airplane that can be used to control the plane’s rolling and banking movements. In the zero position the ailerons are centered, positive values will move the right aileron up and the left aileron down, and negative values will have the opposite effect on the ailerons.
Aileron Trim | DV – Allows fine adjustment of the Aileron position. The zero position is the nominal position, positive values will move the right aileron up and the left aileron down, and negative values will have the opposite effect on the ailerons.
Anti-Torque Control | DV – This control mechanically behaves the same as rudder pedals; as one is pushed forward, the other pushes back. In a helicopter, this controls the pitch of the tail blade to spin the helicopter in place. The zero position is centered, positive values rotate right, and negative values rotate left.
Autopilot Enable | OOC – This control enables or disables an airplane’s autopilot. This should be a toggle switch, but it is typically implemented as a pushbutton.
Chaff Release | OSC – Chaff is strips of metal, foil, or glass fiber with a metal content, cut into various lengths and having varying frequency responses. It is used to reflect electromagnetic energy as a radar countermeasure. These materials, usually dropped from aircraft, also can be deployed from shells or rockets. Typically this a pushbutton that initiates a release of a fixed amount of material.
Collective Control | DV – This control is specifically for a helicopter. It controls the vertical acceleration or lift of the helicopter. The zero position is centered (level flight), positive values accelerate up, and negative values accelerate down.
Cyclic Control | CP – This control is specifically for a helicopter. A cyclic control is a stick between the pilot’s legs that moves in two axes. It controls the swash plate, which in turn controls horizontal acceleration of the helicopter. The zero position is centered, positive Y values accelerate forward, and negative Y values accelerate backward. Positive X values accelerate right, and negative X values accelerate left. This collection will contain X and Y axes.
Cyclic Trim | CP – This control is specifically for a helicopter. Cyclic Trim allows fine adjustment of the cyclic position in two dimensions. The zero position is the nominal position, positive values adjust the baseline acceleration right or forward, and negative values adjust the baseline acceleration left or backward, respectively. This collection will contain X and Y axes.
Dive Brake | DV – A flap that can be extended on an aircraft to increase drag and reduce the speed of descent. It is typically implemented as a lever that generates a dimensionless value between no braking (0) and full braking.
Electronic Countermeasures | OOC – A pushbutton that enables electronic countermeasures. This is typically active radar jamming; however Chaff (radar) or Flare (infrared) can be invoked.
Elevator | DV – A movable control surface, usually attached to the horizontal stabilizer of an aircraft, that is used to produce motion up or down. The zero position is centered, positive values raise the elevator, and negative values lower the elevator.

Universal Serial Bus HID Usage Tables | 39
Elevator Trim | DV – Elevator Trim allows fine adjustment of the Elevator position. The zero
position is the nominal position, positive values are elevator offset up, and negative values are elevator offset down.
Flight Communications OOC – In combat aircraft, a communication (comm) button is usually positioned under the index finger. Typically this is a two-position pushbutton where the first position enables communications with the crew and the second position enables the transmitter for communication external to the plane.
Flare Release | OSC – A flare is a device that produces a bright light for signaling,
illumination, identification, or heat for infrared missile countermeasures. Typically this is a pushbutton that releases a fixed number of flares.
Flight Control Stick CA – A Flight Control Stick controls the Pitch and Roll of an airplane. It looks like a joystick. The stick may be pushed forward or pulled back to move the tail elevator down or up, respectively. Pushing forward causes the plane to nose down. Tilting the stick right and left alters the position of the ailerons. In the zero position the ailerons are centered, tilting the stick to the right will move the right aileron up and the left aileron down, and tilting the stick to the left direction will have the opposite effect on the ailerons. Mechanically, a stick presents two degrees of rotational freedom with approximately a +/–45° range. However, these axes are represented as Generic Desktop Page translational axes X (Roll) and Y (Pitch).
Flight Stick | CA – A Flight Stick defines a class of device commonly used for flight
simulator games. For a device to qualify as a Flight Stick, it must support at least two axes (Pitch and Roll), a trigger button, three additional buttons, and a hat switch. A Flight Stick is a functional subset of a Flight Control Stick.
Landing Gear | OOC – A control for raising or lowering an airplane’s landing gear. This
should be a toggle switch, but it is typically implemented as pushbutton.
Rudder | DV – The zero position is centered, positive values turn right, and negative
values turn left.
Toe Brake | DV – A device for slowing or stopping the motion of an airplane when it is
on the ground. Typically, Toe Brakes consist of two foot pedals that affect the left and right brakes, respectively. Control of the Toe Brakes can allow steering of the plane as well as braking when it is on the ground. An analog Toe Brake generates a dimensionless value between 0 and full scale. In some implementations, the Toe Brake can simply be a pushbutton (full on or off).
Throttle | DV – A valve that regulates the flow of a fluid, such as the valve in an
internal-combustion engine that controls the amount of vaporized fuel entering the cylinders. A lever or pedal controlling such a valve generates a dimensionless value between 0 and full scale.
Trigger | MC – A lever pressed by the finger to release or activate a mechanism,
typically used to discharge a firearm. However, a Trigger can be used for many devices. In combat airplanes the Trigger is usually positioned under the thumb; for a gun it would be positioned under the index finger. Typically this is implemented as a pushbutton.
Weapons Arm | OOC – This device is normally a covered toggle switch that must be selected
to enable the weapons system.

### 40 Universal Serial Bus HID Usage Tables

Weapons Select | OSC – This device can either be a pushbutton that steps through the available weapons or a radio button that selects them individually.
Wing Flaps | DV – Wing flap controls are usually powered either hydraulically or by electric motors, and are used for low-speed control of an airplane. A flap generates a value between 0 and full extension.
Flight Yoke | CA – A flight yoke (also called a control wheel) controls the pitch and roll of an airplane. It looks like a bow tie grasped by both hands. The yoke at which the pilot sits may be pushed forward or pulled back to move the tail elevator down or up, respectively. In the zero position the elevator is centered for level flight. Pushing forward on the yoke causes the plane to nose down and generates negative values. Pulling back on the yoke causes the plane to nose up and generates positive values.
| Rotating the yoke alters the position of the ailerons. In the zero position the ailerons are centered. Rotating the yoke in a clockwise direction will move the right aileron up and the left aileron down and generate incrementing values. Rotating the yoke in the counterclockwise direction will have the opposite effect on the ailerons and generate decrementing values.

## 5.3 Automobile Simulation Devices

Automobile Simulation Device | CA – This usage definition allows a device to be generally classified as one that uses the standard controls found in an automobile or truck.
Accelerator | DV – A device, especially the gas pedal of a motor vehicle, for increasing speed. An Accelerator is a dimensionless single degree-of-freedom dynamic value, where the range of values is from zero to maximum acceleration.
Brake | DV – A device for slowing or stopping motion, as of a vehicle, especially by contact friction. A Brake can be an On/Off Control or a dimensionless single degree-of-freedom dynamic value, where the range of values is from zero to maximum braking.
Clutch | DV – A device for disengaging the transmission of a vehicle to allow shifting of gears. A Clutch can be a generic button or a dimensionless single degree- of-freedom dynamic value, where the range of values is from zero to maximum clutch actuation.
Shifter | DV – A device for shifting gears in a vehicle. A Shifter is a specialized mechanical configuration of a radio button. A zero value is returned when the shifter is in the neutral position. Positive values indicate the forward gear and negative values indicate the reverse gear that the device is in.
Steering | DV – A steering wheel is a single degree-of-freedom device that rotates about an axis. The zero position is always the neutral or “straight ahead” position, with positive values turning clockwise and negative values turning counterclockwise. If the Coordinate Values Wrap attribute is set, the steering wheel can be turned past 360 degrees.

Universal Serial Bus HID Usage Tables | 41

## 5.4 Tank Simulation Devices

Tank Simulation
Device

CA – This usage definition allows a device to be generally classified as one that uses standard controls found in a tank or a treaded vehicle.
Track Control | CP – A device for controlling the direction and velocity of a vehicle that is
driven by tracks. There can be either two sticks with one degree of freedom or a single stick with two degrees of freedom:
In the two-stick case, the neutral position is when the stick is centered (zero). Pushing the stick forward causes forward acceleration (positive values), and pulling it back causes reverse acceleration (negative values). The righthand and lefthand controls will affect the corresponding side of the vehicle.
In the one-stick case, forward/backward acceleration works the same as in the two-stick case. However, right or left movement of the stick determines the amount of power applied to the respective track. When the stick is centered horizontally, equal amounts of power are applied to both tracks, generating a zero output value. Moving the stick to the right will generate positive values, and moving the stick to the left will generate negative values. A Tank Track Control is a dimensionless analog entity.
Turret Direction | DV – This control determines the right-to-left positioning of the tank turret. A
value of zero maintains the current orientation of the turret. A positive value turns the turret to the right and a negative value turns the turret to the left.
Barrel Elevation | DV – This control determines the elevation of the gun barrel in a turret. A
value of zero maintains the current orientation of the barrel. A positive value raises the barrel and a negative value lowers the barrel.

## 5.5 Maritime Simulation Devices

Submarine Simulation
Device

CA – Allows a device to be generally classified as one that uses the standard controls of a submarine.
Dive Plane | DV – Dive planes control the vertical ascent or descent of the submarine
under power. A zero value indicates level travel. Positive values indicate ascent, and negative values indicate descent. A Dive Plane is a dimensionless analog entity.
Ballast | DV – Ballast controls the vertical ascent or descent of the submarine. A zero
value indicates level travel. Positive values indicate ascent, and negative values indicate descent. A Ballast is a dimensionless analog entity.
Sailing Simulation
Device

CA – Allows a device to be generally classified as one that uses the standard controls of a sailboat.

### 42 Universal Serial Bus HID Usage Tables

## 5.6 Two-wheeled Simulation Devices

Motorcycle
Simulation Device

CA – Allows a device to be generally classified as one that uses the standard controls of a motorcycle.
Bicycle Simulation
Device

CA – Allows a device to be generally classified as one that uses the standard controls of a bicycle.
Bicycle Crank | DV – A foot-operated assembly of pedals attached to a crank that is used for powering a bicycle. The reported value is the rate that the crank turns per minute.
Handle Bars | DV – A steering control, held in both hands, for a motorcycle or bicycle. A zero output value indicates that the direction of travel is straight ahead. Pulling back on the right side turns the vehicle to the right and generates a positive output. Pulling back on the left side turns the vehicle to the left and generates a negative output.
Front Brake | DV – Engages the front brake of the motorcycle to slow the vehicle. A Front Brake can be a generic button or a dimensionless single degree-of-freedom analog entity, where the range of values is from zero to maximum braking.
Rear Brake | DV– Engages the rear brake of the motorcycle to slow the vehicle. A Rear Brake can be a generic button or a dimensionless single degree-of-freedom analog entity, where the range of values is from zero to maximum braking.

## 5.7 Miscellaneous Simulation Devices

Magic Carpet Simulation Device | CA – Allows a device to be generally classified as one that uses the standard control of a magic carpet. This control is a bar, grasped by both hands, that controls the Yaw, Pitch and Roll of the carpet.
| The bar, at which the pilot sits, may be pushed forward or pulled back to cause the carpet to dive or rise, respectively. In the zero position, the carpet is in level flight. Pushing forward on the bar causes the carpet to nose down and generates negative values. Pulling back on the bar causes the carpet to nose up and generates positive values.
| Turning the bar turns the carpet. In the zero position, the carpet travels straight ahead. Pulling back on the right side turns the carpet to the right and generates positive values. Pulling back on the left side turns the carpet to the left and generates negative values.
| Rotating the bar rolls the carpet. In the zero position, the carpet travels level. Rotating the bar in a clockwise direction rolls the carpet to the right and generates positive values. Rotating the bar in the counterclockwise direction rolls the carpet to the left and generates negative values.

Universal Serial Bus HID Usage Tables | 43

## 6 VR Controls Page (0x03)

Virtual Reality controls depend on designators to identify the individual controls. Most of the following are usages are applied to the collections of entities that comprise the actual device.

Table 8: VR Controls Page

Usage ID | Usage Name | Usage Type
00 | Unidentified
01 | Belt | CA
02 | Body Suit | CA
03 | Flexor | CP
04 | Glove | CA
05 | Head Tracker | CP
06 | Head Mounted Display | CA
07 | Hand Tracker | CA
08 | Oculometer | CA
09 | Vest | CA
0A | Animatronic Device | CA
0B-1F | Reserved
20 | Stereo Enable | OOC
21 | Display Enable | OOC
22-FFFF | Reserved
Belt | CA – A Belt wraps around the user’s waist. A tracker would be centered in the small of the user’s back to identify the orientation of the user’s hips.
Body Suit | CA – Generally classifies a device as one that uses the standard controls found in a Body Suit. A Body Suit typically has a large number of position sensors typically fixed to the major joints of the body, such as the ankles, knees, hips, shoulders, elbows, wrists and head, for measuring the angle and movement of the wearer’s joints and limbs.
Flexor | CP – A Flexor describes the angle of bend of a joint or limb in the body. The designator is used to determine which joint a specific Flexor entity represents.
Glove | CA – A Glove reports the positions of the fingers. Up to 20 angular values can be reported. Designators are used to determine the degrees of freedom that the Glove device is capable of reporting.
Head Tracker | CP – A Head Tracker represents the position and/or orientation of the head in space. The axes are oriented such that, in the zero position, the user is looking from the positive Z axis to the negative Z axis. The positive Y axis is extends vertically from the top of the user's head.
Head Mounted Display | CA – A Head Mounted Display (HMD) presents the following parameters to the user: Vbrx, Vbry, and Vbrz. Stereo Enable and Display Enable are optional usages that can be included in an HMD collection.

### 44 Universal Serial Bus HID Usage Tables

Stereo Enable | OOC – Selects the display mode of the HMD. A value of 0 selects monoscopic mode and 1 selects stereoscopic mode.
Display Enable | OOC – Enables the HMD video output. A value of 0 turns off the display and 1 turns it on.
Hand Tracker | CA – A Hand Tracker represents the position of the hand in space. A Hand Tracker attaches to the back of the hand. In the zero position, it is assumed that the hand is held upright with the extended thumb parallel to the Y axis and the fingers pointing in the negative Z direction
Oculometer | CA – An Oculometer identifies the direction in which the eye is looking in rotation about the X and Y axes. The designator for an Oculometer is always Eye.
Vest | CA – A Vest wraps around the user’s chest and abdomen. A tracker would be placed on the user’s back between the shoulder blades.
Animatronic Device | CA – An input device for the animation of mechanical or Computer Graphic Image “electronic” puppets. An animatronic device is engineered to fit a puppeteer’s or performer’s body (and/or head and/or face) and comfortably allow a wide range of physical freedom.
| An Animatronic Device measures the angle and movement of the wearer’s joints and limbs, which are then translated into the motion of a puppet, allowing the puppet to mimic the wearer’s movements. There is not necessarily a 1:1 mapping of human to puppet controls. A puppeteer’s arm may be used to control the movement of an elephant’s trunk, or hand controls may be used to control facial expressions. Designators are used to determine which puppeteer joint is being tracked. The controlling application will map these inputs to the electronic or mechanical device.

Universal Serial Bus HID Usage Tables | 45

## 7 Sport Controls Page (0x04)

Table 9: Sport Controls Page

Usage ID | Usage Name | Usage Type | Section
00 | Unidentified
01 | Baseball Bat | CA | 7.1
02 | Golf Club | CA | 7.1
03 | Rowing Machine | CA | 7.2
04 | Treadmill | CA | 7.2
05-2F | Reserved
30 | Oar | DV | 7.2
31 | Slope | DV | 7.2
32 | Rate | DV | 7.2
33 | Stick Speed | DV | 7.1
34 | Stick Face Angle | DV | 7.1
35 | Stick Heel/Toe | DV | 7.1
36 | Stick Follow Through | DV | 7.1
37 | Stick Tempo | DV | 7.1
38 | Stick Type | NAry | 7.1
39 | Stick Height | DV | 7.1
3A-4F | Reserved
50 | Putter | Sel | 7.1
51 | 1 Iron | Sel | 7.1
52 | 2 Iron | Sel | 7.1
53 | 3 Iron | Sel | 7.1
54 | 4 Iron | Sel | 7.1
55 | 5 Iron | Sel | 7.1
56 | 6 Iron | Sel | 7.1
57 | 7 Iron | Sel | 7.1
58 | 8 Iron | Sel | 7.1
59 | 9 Iron | Sel | 7.1
5A | 10 Iron | Sel | 7.1
5B | 11 Iron | Sel | 7.1
5C | Sand Wedge | Sel | 7.1
5D | Loft Wedge | Sel | 7.1
5E | Power Wedge | Sel | 7.1
5F | 1 Wood | Sel | 7.1
60 | 3 Wood | Sel | 7.1
61 | 5 Wood | Sel | 7.1

### 46 Universal Serial Bus HID Usage Tables

Usage ID | Usage Name | Usage Type | Section
62 | 7 Wood | Sel | 7.1
63 | 9 Wood | Sel | 7.1
64-FFFF | Reserved

## 7.1 Stick Devices

Stick devices are used in applications in which the user swings one object to make contact with another. Typical examples are a baseball bat and a golf club. These devices sense various quantities at the point of impact to determine the direction that the target (struck) object will go. The target object is a sphere. The Stick usages Speed, Face Angle, Heel/Toe, Follow Through, Tempo, and Height identify the measurement quantities.
Baseball Bat | CA – Primary input device for baseball simulation applications. Normally consists of a collection of Stick usages.
Golf Club | CA – Primary input device for golf simulation applications. Normally consists of a collection of Stick usages.
Stick Speed | DV – The velocity with which the stick strikes the target object. This can be expressed as collection of velocity values to provide a direction, or as an absolute magnitude where the Stick Face Angle provides the direction.
Stick Face Angle | DV – The direction in which the stick strikes the target object. In a golf simulation, this will be the horizontal angle and the vertical angle will be determined by the Stick Type. For Baseball Bats and other stick devices the direction is expressed as a three-dimensional vector.
Stick Heel/Toe | DV – Identifies the contact point relative to the striking surface. This helps to identify the “sweet spot.” This is reported as a relative value where zero is the sweet spot, positive values are away from the user, and negative values are towards the user.
Stick Follow Through | DV – In a golf simulation, the user strikes the ball, swings the club forward over the shoulders, then brings the club back to the tee. Stick Follow Through is a measure of the time that this process takes. Other stick devices may provide this parameter as well.
Stick Tempo | DV – In a golf simulation, the user starts the swing at the ball, swings the club back over the shoulders, then strikes the ball. Stick Tempo is a measure of the time that this process takes. Other stick devices may provide this parameter as well.
Stick Type | NAry – An array that identifies the type of golf club used.
Irons 1 – 11, Woods 1, 3, 5, 7, 9, Sand Wedge, Loft Wedge, Power Wedge, and Putter | Sel – Golf club stick types. Stick type determines the stick face angle.
Stick Height | DV – Height of contact point above the ground for stick device.

Universal Serial Bus HID Usage Tables | 47

## 7.2 Exercise Machines

Bicycles can be found in Section 7.1 .

Rowing Machine | CA – An exercise device that simulates rowing a boat. Usages typically found
in this collection are Oars and Rate. Rate is typically expressed in strokes per minute.
Oar | DV – Rowing repetition rate in strokes per minute. Left, right and two-
handed oars are distinguished with designators.
Treadmill | CA – An exercise device consisting of an endless moving belt on which a
person can walk or jog while remaining in one place. Usages typically found in this collection are Slope and Rate. The Rate is typically expressed in strokes per minute.
Rate | DV – Rate in miles per hour.
Slope | DV – Slope is measured in degrees. Positive angles are uphill, negative
angles are downhill, and 0° is level.

### 48 Universal Serial Bus HID Usage Tables

## 8 Game Controls Page (0x05)

Table 10: Game Controls Page

Usage ID | Usage Name | Usage Type | Section
00 | Undefined
01 | 3D Game Controller | CA | 8.1
02 | Pinball Device | CA | 8.2
03 | Gun Device | CA | 8.3
04-1F | Reserved
20 | Point of View | CP | 8.1
21 | Turn Right/Left | DV | 8.1
22 | Pitch Forward/Backward | DV | 8.1
23 | Roll Right/Left | DV | 8.1
24 | Move Right/Left | DV | 8.1
25 | Move Forward/Backward | DV | 8.1
26 | Move Up/Down | DV | 8.1
27 | Lean Right/Left | DV | 8.1
28 | Lean Forward/Backward | DV | 8.1
29 | Height of POV | DV | 8.1
2A | Flipper | MC | 8.2
2B | Secondary Flipper | MC | 8.2
2C | Bump | MC | 8.2
2D | New Game | OSC | 8.2
2E | Shoot Ball | OSC | 8.2
2F | Player | OSC | 8.2
30 | Gun Bolt | OOC | 8.3
31 | Gun Clip | OOC | 8.3
32 | Gun Selector | NAry | 8.3
33 | Gun Single Shot | Sel | 8.3
34 | Gun Burst | Sel | 8.3
35 | Gun Automatic | Sel | 8.3
36 | Gun Safety | OOC | 8.3
37 | Gamepad Fire/Jump | CL | 8.4.1
39 | Gamepad Trigger | CL | 8.4.1
3A-FFFF | Reserved

Universal Serial Bus HID Usage Tables | 49

## 8.1 3D Game Controller

The following controls support first-person games or those that are played through the eyes of the character that represents the player in the 3D world.
3D Game Controller | CA – A collection of 3D movement usages.
Point of View | CP – A collection of rotational axes (Rx, Ry, and Rz) that represent the
orientation of the user’s head in 3D space. If applied to a Hat Switch, only the Rz (Yaw) axis will be controlled.
Turn Right/Left | DV – Identifies the horizontal facing direction of the player’s hips (Rz =
Yaw). Turn Right/Left is a relative value where 0° is straight ahead, positive values turn right, and negative values turn left. The rate of rotation is determined by the application.
Pitch
Forward/Backward

DV – Identifies the vertical facing direction of the player’s hips (Rx = Pitch). Pitch Right/Left is a relative value where 0° is a vector pointing up from the players hips to the players head, positive values bend back, and negative values bend forward. The rate of rotation is determined by the application.
Roll Right/Left | DV – Identifies the vertical facing direction of the player’s hips (Ry = Roll).
Roll Forward/Backward is a relative value where 0° is a vector pointing up from the players hips to the players head, positive values lean left, and negative values lean right. The rate of rotation is determined by the application.
Move Right/Left | DV – This control allows the player to sidestep or move right and left without
changing the orientation of the hips. Move Right/Left is a relative value where 0 is no lateral motion, positive values move right, and negative move left. The rate of movement is determined by the application.
Move
Forward/Backward

DV – This control allows the player to move forward and backward in the direction (yaw) the hips are facing. Move Forward/Backward is a relative value where 0 is no motion, positive values move backward, and negative move forward. ¹ The rate of movement is determined by the application.
Move Up/Down | DV – This control allows the player to move up and down. It is assumed that
the player can fly, is swimming, or is at a ladder or a climbable wall. Move Up/Down is a relative value where 0 is no motion, positive values move down, and negative move up.¹
The rate of movement is determined by the application.
Lean Right/Left | DV – This control allows the player to lean right and left from the hips,
without changing the orientation of the hips, for example, to look around a corner. Lean Right/Left is a relative value where 0 is no lateral motion, positive values move right, and negative move left. The rate of movement is determined by the application.
Lean
Forward/Backward

DV – This control allows the player to lean forward and backward from the hips in the direction (yaw) the hips are facing. Lean Forward/Backward is a relative value where 0 is no motion, positive values move backward, and negative move forward.¹
The rate of movement is determined by the application.

1
These directions may appear counter-intuitive but they are consistent with the HID orientation conventions.

### 50 Universal Serial Bus HID Usage Tables

Height of POV | DV – This control allows the player to stand, squat, and crawl. Height of POV is a relative value where 0 is the normal standing position and positive values lower the player’s Point Of View. The maximum value as indicated by Logical Maximum is the crawling position, the median positive value is the squatting position, and negative values indicate the player is standing on tiptoes or flying. ¹

## 8.2 Pinball Device

Pinball is a game played on a device in which the player operates a plunger to shoot a ball down or along a slanted surface that has obstacles and targets.
Pinball Device | CA – A collection of usages representing the controls of a pinball game.
Flipper | MC – A button that actuates a bar that swings around a pivot to change the direction of the ball. A pair of right and left flippers normally resides at the near end of the table.
Secondary Flipper | MC – A button that actuates a bar that swings around a pivot to change the direction of the ball. Secondary flippers normally reside on the sides halfway up the table.
Bump | MC – A control that indicates that the flipper assembly has been shoved by the player to change the direction of the ball. This can be as simple as a switch or as complex as a 3D force vector.
New Game | OSC – A button that terminates any current game and reinitializes for a new game.
Shoot Ball | OSC – A control that indicates that the player has placed the ball into play. This can be as a switch or a force vector.
Player | OSC – A button that cycles through the number of players supported by the game.
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

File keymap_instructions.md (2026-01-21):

# Making Your Own Keymap

[Get duckyPad](https://dekunukem.github.io/duckyPad-Pro/doc/landing.html) | [Official Discord](https://discord.gg/4sJCBx5) | [Getting Started](getting_started.md) | [Table of Contents](#table-of-contents)

This guide describes how keymap works, and how to write your own.

Note that I'm no expert on keyboard technicalities, I barely got this thing to work! So [feel free to correct me](#questions-or-comments) if you spot anything wrong.

## (Short Story of) HID Usage ID

When you press a key, the keyboard sends a **`USB HID Usage ID`** to the computer, to let it know which key was pressed.

Each key has a unique HID Usage ID, you can [find a list here](https://gist.github.com/MightyPork/6da26e382a7ad91b5496ee55fdc73db2).

duckyPad works by acting as a regular USB keyboard, and sending HID Usage IDs to simulate keypresses.

## Keyboard Layouts

The kicker is, HID Usage ID corresponds to the `PHYSICAL LOCATION` of a key on the keyboard, NOT what it says on the key itself!

For example, here is a `ANSI QWERTY keyboard (US)`, popular in US and other parts of the world.

* The red number is the HID Usage ID (in hexadecimal) that will be sent when pressed.



Now let's see what happens on a `Dvorak (US layout)` keyboard:



Notice how the **HID Usage ID stays the same** while **labels on the key change!**

Therefore, it is important to understand that the keyboard only tells `WHERE` a key is pressed, and it's **`up to the operating system`** to determine **`what character`** the key should produce.

In modern OSs, you can set multiple keyboard layouts:



## Keymap Madness

This creates an issue when it comes to input automation on duckyPad. Consider this command:

`STRING fox`

duckyPad will simply types out `fox`, but *what code should it send?*

Remember that HID Usage ID (red numbers) corresponds to the `PHYSICAL LOCATION` of a key. So if we assume `English (US)` layout, it should send out `0x09, 0x12, 0x1b`:



However, if the OS is set to `Dvorak`, it will interpret `0x09, 0x12, 0x1b` as the keys at the `SAME LOCATION`, which comes out as `URQ`. Not good!



To type `fox` on `Dvorak`, duckyPad needs to send `0x1c, 0x16, 0x05` instead:



See the problem here? We now need to send **different codes** for the **same characters**! And there are *dozens* of keyboard layouts, each with their own minute quirks and differences.

To make sure everything works, we need a way to **`map a character to its HID Usage ID`** (and therefore the physical location on the keyboard) so duckyPad knows what code to send for different keyboard layouts.

And thus, the keymap is born.

## duckyPad Keymaps

Keymap for duckyPad is a simple text file mapping **`256 ASCII characters to HID Usage Codes`**.

### Examples

I have written a few myself, so [check it out here](sample_profiles/keymaps).

Here is a snippet from [`Dvorak (US)`](sample_profiles/keymaps/dpkm_Dvorak%20(US).txt) keymap:

```
.........
0x61 0x0004 // a
0x62 0x0011 // b
0x63 0x000c // c
0x64 0x000b // d
0x65 0x0007 // e
.........
```

### Basic Rules

* The file name must start with `dpkm_` and end with the extension of `.txt`.

* Inside, it should contain lines of **two hexadecimal numbers** (plus optional comments) like above.

* The first **2-digit hexadecimal number** is the [ASCII code of a character](https://www.ascii-code.com/).

* The second **4-digit hexadecimal number** is called a `duckcode`, explained below.

### duckcode

duckcode is an `unsigned 16-bit number` containing the HID Usage Code and some other information:



* The `lower 8 bits` is the `HID Usage ID` of the key that you want to press.
	* Shown on the [keyboard diagrams above](#keyboard-layouts)
* `Bit 8` is `SHIFT`, set to 1 to press it alongside the key.
	* For upper-case and symbols.
* `Bit 9` is `Alt Gr`, produces additional characters on European keyboards.
	* Works the same way.
* `Top 4 bits` are for `Dead Keys`.
	* They do nothing on their own, but adds accents on the base keys.



## Making Your Own Keymap: Step-by-Step

### Download the templates

A good idea would be starting from templates.

[Click me to download the svg template](resources/keyboard_layout_graphics/ANSI_template.svg) for ANSI-style keyboard:



[Click me to download the svg template](resources/keyboard_layout_graphics/ISO_template.svg) for ISO-style keyboard:



* You can use [Inkscape](https://inkscape.org/) to open and edit svg files.

* There are multiple layers in the svg file, you can show or hide them.

* There are a few more svg files of different layouts, [check them out here](resources/keyboard_layout_graphics).

### Overlay the template

You can probably find a diagram of your desired keyboard layout [on Wikipedia](https://en.wikipedia.org/wiki/Keyboard_layout).

When you do, overlay the template over the layout to visualise the HID Usage Codes.

Let's say you want to make a keymap for `AZERTY Belgium` layout:



### Modify keymap entries

You can start from an [empty keymap](https://raw.githubusercontent.com/dekuNukem/duckyPad/master/sample_profiles/keymaps/keymap_template_empty.txt), or from the [default `English (US)` keymap](https://raw.githubusercontent.com/dekuNukem/duckyPad/master/sample_profiles/keymaps/keymap_template_eng_us.txt), or from a [similar existing layout](sample_profiles/keymaps). Either way, download and open in a text editor.

For this example, we'll be starting from [`English (US)` keymap](https://raw.githubusercontent.com/dekuNukem/duckyPad/master/sample_profiles/keymaps/keymap_template_eng_us.txt).

Start from the top left key:



In `AZERTY Belgium` layout, when we press this key, it will print out `²` character.

Now we need to find it in the keymap file, and map it to the corresponding HID code.

Search `²` in the file, we find it at [line 194](sample_profiles/keymaps/keymap_template_eng_us.txt#L194). Its ASCII code is `0xb2`, and right now it looks like this:

`0xb2 0x0000 // ²`

The duckcode here is 0x0000, which means unmapped, since we don't have this key on US keyboards.

To map `²` to this key, make a duckcode as [described above](#duckcode). In this case, the HID code is `0x35` (shown on the key), and we don't need anything else, so the duckcode is `0x0035`. Change the line into:

`0xb2 0x0035 // ²`

That's it for this character!

---

However, we're not done yet! When you press this key with `SHIFT`, `³` is printed out.

As before, find `³` in the file, which is at [line 195](sample_profiles/keymaps/keymap_template_eng_us.txt#L195):

`0xb3 0x0000 // ³`

It is also unmapped. Since we need to press `SHIFT` to get this character, the second digit should be `1`, so the duckcode would be `0x0135`. Note how the HID Usage ID part stays the same.

So we change the line into:

`0xb3 0x0135 // ³`

Now this key is done! We mapped two characters to HID Usage IDs. Now duckyPad will know what code to send when it encounters those characters.

---

As another example, let's move on to the next key:



When you press this key, `&` will be printed out. Yes that's right, it is inverted in this layout!

It should be clear that duckcode for `&` is `0x001e`.

As usual, go find `&` in the file, and set the duckcode:

`0x26 0x001e // &`

When you press this key with `SHIFT`, `1` is printed out. Therefore its duckcode should have the `SHIFT` set, which is `0x011e`. The line therefore should be:

`0x31 0x011e // 1`

However, we have a *third* character on this key! `|` is printed by pressing the `AltGr` key. So we need to set the `AltGr` in duckcode for this character, which would be `0x021e`.

Again, find the line and update the duckcode:

`0x7c 0x021e // |`

---

That's pretty much it! Now you just have to go through each key and check and modify the keymap lines!

Don't forget to set `SHIFT` bit for letter keys too, to distinguish between upper and lower cases.

### Dead Keys

To further complicate things, a lot of european keyboards include `Dead Keys`. They don't generate a character by themselves, but modify the appearance of the character typed immediately after.

In our Belgium keyboard example, there are 4 dead keys, identified with `red marking`.



If you press the top-left key marked with `^`, nothing will happen, but if you then press letter `a`, `â` will be generated instead.

If you want duckyPad to type characters with dead keys, you can specify them in the beginning of the keymap file like this:

```
dk_grave_accent 0x0232
dk_acute_accent 0x0234
dk_circumflex 0x002f
dk_tilde 0x0238
dk_diaeresis 0x012f
dk_cedilla 0x0000
```

The hexadecimal number is the duckcode for the dead key, and some of them will need `SHIFT` or `AltGr`.

If a dead key doesn't exist, set it to 0x0000.

Afterwards, [set the dead key in duckcode](#duckcode) with HID code of regular letters to get those letters with accents: 

```
0xd2 0x1112 // Ò
0xd3 0x2112 // Ó
0xd4 0x3112 // Ô
0xd5 0x4112 // Õ
0xd6 0x5112 // Ö
.....
0xf2 0x1012 // ò
0xf3 0x2012 // ó
0xf4 0x3012 // ô
0xf5 0x4012 // õ
0xf6 0x5012 // ö
```

To type symbols on the dead keys themselves, set the appropriate dead key along with HID code `0x2c` (space):

```
0x60 0x102c // `
0xb4 0x202c // ´
0x5e 0x0223 // ^
0x7e 0x402c // ~
0xa8 0x502c // ¨
```

Note that `^` has its own key, so you can use that instead.

You can take a look at the [completed `AZERTY Belgium` keymap here](sample_profiles/keymaps/dpkm_Belgium.txt).

## Test It Out!

Here are some duckyScript to test if your keymap is working properly.

Make sure to set the same keyboard layout on both duckyPad and your OS!

Check to see if duckyPad types everything out **exactly as it appears in the script**. If not, you might have made a mistake on that particular character.

### Letters and Numbers

```
STRING the quick brown fox jumps over the lazy dog
ENTER
STRING THE QUICK BROWN FOX JUMPS OVER THE LAZY DOG
ENTER
STRING 0123456789
ENTER
```

### ASCII Symbols

```
STRING !"#$%&'
ENTER
STRING ()*+,-./
ENTER
STRING :;<=>?@
ENTER
STRING [\]^_`
ENTER
STRING {|}~
ENTER
```

### Extended ASCII Characters

```
STRING €¡¢£¤¥¦§¨©ª«¬­®¯°±²³´µ¶·¸¹º»¼½¾¿ÀÁÂÃÄÅÆÇÈÉÊËÌÍÎÏÐÑÒÓÔÕÖ×ØÙÚÛÜÝÞßàáâãäåæçèéêëìíîïðñòóôõö÷øùúûüýþÿ
ENTER

```

Only characters that exists on the current keyboard layout will be typed out.

For example, if you run this on default `English (US)` layout, nothing will appear. Since none of those characters are on that keyboard layout.

## Good luck!

If you made a keymap for a new keyboard layout, feel free to sumbit a pull request or [contact me](#questions-or-comments), and I'll add it for everyone to use!

## Table of Contents

[Main page](README.md)

[Getting Started Guide](getting_started.md)

[Kit Assembly Guide](kit_assembly_guide.md)

[Using duckyScript](https://dekunukem.github.io/duckyPad-Pro/doc/duckyscript_info.html)

[Common issues / Troubleshooting](troubleshooting.md)

[Firmware Updates and Version History](firmware_updates_and_version_history.md)

[Make Your Own Keymap](./keymap_instructions.md)

[Build a duckyPad Yourself](build_it_yourself.md)

[Kickstarter Backer Acknowledgments](kickstarter_backers.md)

## Questions or Comments?

Please feel free to [open an issue](https://github.com/dekuNukem/duckypad/issues), ask in the [official duckyPad discord](https://discord.gg/4sJCBx5), DM me on discord `dekuNukem#6998`, or email `dekuNukem`@`gmail`.`com` for inquires.

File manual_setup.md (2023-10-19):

# Configure duckyPad Manually

[Get duckyPad](https://www.tindie.com/products/21984/) | [Official Discord](https://discord.gg/4sJCBx5) | [Getting Started](getting_started.md) | [Table of Contents](#table-of-contents)

------

If you don't trust or unable to run the software, you can also configure duckyPad manually with a text editor.

### Step 1: Preparing Profiles

A *Profile* contains a group of scripts corresponding to the keys on the duckyPad. Usually you want to set up one profile per program you want to control.

Profiles are created as folders at the **root level** of the SD card. They have naming conventions like `profile#_name`, where `#` is the profile number, and `name` being the name of the profile.

If you mount the SD card on your computer, you might see some examples like these:



[Existing examples](https://github.com/dekuNukem/duckypad/raw/master/sample_profiles.zip) are an excellent starting point of making your own profiles and scripts.

Up to 32 profiles are supported.

### Step 2: Preparing Scripts

Now you're ready to write some scripts inside the profile folders. The script used in this project is Duckyscript, [read more about it here](duckyscript_info.md).

Each key has its own script file, named like `key#.txt`, where `#` is the key number(top left is 1, bottom right is 15). 

Here are some examples:



* Might be helpful to take a look at the [sample profiles](https://github.com/dekuNukem/duckypad/raw/master/sample_profiles.zip) before writing your own

### Step 3: Key Names and Optional Parameters

Create a file named `config.txt` in a profile folder like this:



#### Key Names

In the `config.txt`, list the names of your keys like this:

```
z1 prev
z2 next
z3 close
z4 reopen
....
z15 save
```
* The screen will only display the **first 7 characters** of the key name, so keep it short!

#### Loop Flag

If a key uses [`LOOP` command](https://github.com/dekuNukem/duckyPad/blob/master/duckyscript_info.md#loop-experimental), add a line like this:

`s4 3`

In this case, `4` is the key number, and `3` is the total number of actions. This tells duckyPad to look for the `LOOP` command instead of executing the script right away.

#### Backlight Colors

To set your custom background color, add the following line:

```
BG_COLOR 255 100 0
```

The number should be between 0 and 255, in the order of R-G-B.

* Can't decide? Use [this website](https://www.w3schools.com/colors/colors_picker.asp) to try some out. Use the `rgb()` value of each colour.

If unspecified, the default background color would be light purple.

#### Key-down Colors

To set the color of a key to change into when pressed, add the following line in `config.txt`:

```
KEYDOWN_COLOR 100 0 255
```

If unspecified, the default key-down color would be the inverse of background color.

#### Dim Unused Keys

By default unused keys are dimmed. If you want everything to light up, add the following line in `config.txt`:

```
DIM_UNUSED_KEYS 0
```

#### Individual Key Colors

You can also assign colors to individual keys, this will override the background color above.

Just add lines in `config.txt` for the keys you want like this:

```
SWCOLOR_1 148 0 211
SWCOLOR_2 148 0 211
SWCOLOR_3 148 0 211
SWCOLOR_4 0 0 255
SWCOLOR_5 0 0 255
SWCOLOR_6 0 0 255
SWCOLOR_7 0 255 0
SWCOLOR_8 0 255 0
SWCOLOR_9 0 255 0
SWCOLOR_10 255 255 0
SWCOLOR_11 255 255 0
SWCOLOR_12 255 255 0
SWCOLOR_13 255 0  0
SWCOLOR_14 255 0  0
SWCOLOR_15 255 0  0
```

### Step 4: Run it!

Just like before, make sure the SD card is in FAT32 format, copy all the profile folders to the root of the SD card (if they are not already there), insert it in your duckyPad, and power on.

duckyPad should start up and display the profile names and key names, as well as the background color.

Press the corresponding keys to execute the scripts, if there is an error it will show up on the screen.

Press +/- button to change profiles.

## Table of Contents

[Main page](README.md)

[Getting Started Guide](getting_started.md)

[Kit Assembly Guide](kit_assembly_guide.md)

[Using duckyScript](duckyscript_info.md) | [duckyScript 3 Info](duckyscript3_instructions.md)

[Common issues / Troubleshooting](troubleshooting.md)

[Firmware Updates and Version History](firmware_updates_and_version_history.md)

[Make Your Own Keymap](./keymap_instructions.md)

[Build a duckyPad Yourself](build_it_yourself.md)

[Kickstarter Backer Acknowledgments](kickstarter_backers.md)

## Questions or Comments?

Please feel free to [open an issue](https://github.com/dekuNukem/duckypad/issues), ask in the [official duckyPad discord](https://discord.gg/4sJCBx5), DM me on discord `dekuNukem#6998`, or email `dekuNukem`@`gmail`.`com` for inquires.

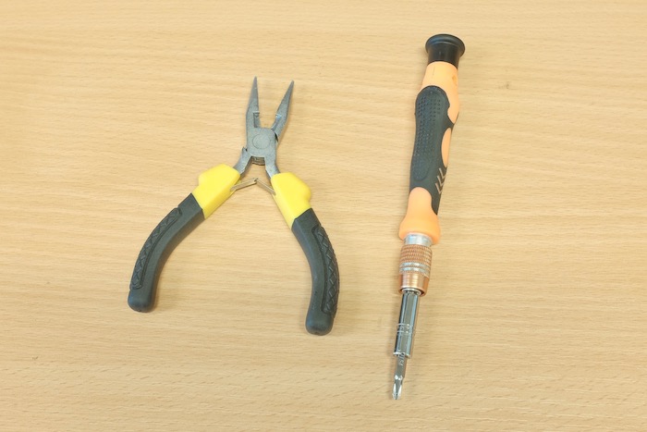
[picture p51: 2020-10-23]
resources/pics/assembly/tools.jpg

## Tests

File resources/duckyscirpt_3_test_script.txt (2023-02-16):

DEFAULTCHARDELAY 25
DEFAULTDELAY 25

WINDOWS R
DELAY 1000
STRINGLN notepad
DELAY 1000

STRINGLN Welcome to duckyScript 3 beta test!
STRINGLN Here's a quick demo.
ENTER

STRINGLN Variables and operations:
VAR $spam = 10
$spam = $spam * 4 + 2
STRINGLN     Spam is: $spam
ENTER

//---------------
STRINGLN Conditions and loops:

$spam = 0
$_RANDOM_MIN = 1
$_RANDOM_MAX = 10

WHILE $spam < 4
    VAR $this_number = $_RANDOM_INT
    STRING     Random number: $this_number

    IF $this_number > 5 THEN
        STRINGLN , it's more than 5!
    ELSE IF $this_number == 5 THEN
        STRINGLN , exactly 5!
    ELSE
        STRINGLN , it's less than 5!
    END_IF

    $spam = $spam + 1
END_WHILE
ENTER

//--------OLED screen--------

STRINGLN Printing to OLED screen
STRINGLN Look at the screen!

// fill all LED with color
SWC_FILL 128 0 255

OLED_CLEAR
OLED_CURSOR 20 0
OLED_PRINT Hello World!
OLED_CURSOR 20 12
OLED_PRINT Press a key!
OLED_CURSOR 10 52
OLED_PRINT Press + to exit
OLED_UPDATE

WHILE 1
    VAR $this_key = $_READKEY

    OLED_CURSOR 10 31
    IF $this_key != 0 THEN
        OLED_PRINT I pressed key $this_key!
    ELSE
        OLED_PRINT                           
    END_IF

    IF $this_key == 17 THEN
        LBREAK
    END_IF

    OLED_UPDATE
    DELAY 50
END_WHILE

//------- mini menu ----------

OLED_CLEAR
OLED_CURSOR 5 20
OLED_PRINT You can use it to
OLED_CURSOR 0 32
OLED_PRINT make mini sub-menus!
OLED_UPDATE
DELAY 4000

SWC_FILL 0 0 0
SWC_SET 1 128 0 0
SWC_SET 2 128 0 0
SWC_SET 3 128 0 0
SWC_SET 4 128 0 0
SWC_SET 5 128 0 0

BCLR

OLED_CLEAR
OLED_CURSOR 10 0
OLED_PRINT Example Sub-Menu
OLED_CURSOR 5 12
OLED_PRINT Action 1
OLED_CURSOR 5 22
OLED_PRINT Action 2
OLED_CURSOR 5 32
OLED_PRINT Action 3
OLED_CURSOR 5 42
OLED_PRINT Action 4
OLED_CURSOR 5 52
OLED_PRINT Action 5
OLED_UPDATE

WHILE 1
    VAR $selection = $_READKEY

    IF $selection > 0 && $selection <= 5 THEN
        LBREAK
    END_IF

    DELAY 50
END_WHILE

OLED_CLEAR
OLED_CURSOR 0 30
IF $selection == 1 THEN
    OLED_PRINT I selected Option 1!
ELSE IF $selection == 2 THEN
    OLED_PRINT I selected Option 2!
ELSE IF $selection == 3 THEN
    OLED_PRINT I selected Option 3!
ELSE IF $selection == 4 THEN
    OLED_PRINT I selected Option 4!
ELSE IF $selection == 5 THEN
    OLED_PRINT I selected Option 5!
END_IF
OLED_UPDATE
DELAY 3000

//------- light show ---------

OLED_CLEAR
OLED_CURSOR 10 20
OLED_PRINT Bonus lightshow!
OLED_CURSOR 15 35
OLED_PRINT Anykey to exit
OLED_UPDATE

BCLR

VAR $red = 0
VAR $green = 0
VAR $blue = 0

VAR $count = 0

DEFINE UP 0
DEFINE DOWN 1

VAR $direction = UP
WHILE 1

    IF $_READKEY != 0 THEN
        LBREAK
    END_IF

    IF $direction == UP && $count == 250 THEN
        $direction = DOWN
    ELSE IF $direction == DOWN && $count == 0 THEN
        $direction = UP
    END_IF

    $red = $count / 3
    $green = $count / 2
    $blue = $count 

    SWC_FILL $red $green $blue
    DELAY 2

    IF $direction == UP THEN
        $count = $count + 1
    ELSE IF $direction == DOWN THEN
        $count = $count - 1
    END_IF

END_WHILE

// restore all RGB LED to default colors
SWC_RESET 99

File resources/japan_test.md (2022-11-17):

# duckyPad JIS Keyboard Layout Test

## Install new firmware

* **[Updated 2022-11-17]**[Click me to download the beta 0.20.5 firmware](https://github.com/dekuNukem/duckyPad/raw/master/firmware/beta_0.20.5.dfu)

* [Follow this guide](firmware_updates_and_version_history.md) to flash it into your duckyPad, use the above file.

## Set up SD card

* Pop out the SD card, mount it on the computer with the included card reader

* [If you want] Copy everything off to make a backup

* Format the card in FAT32 or FAT



* Download this [zip file](https://github.com/dekuNukem/duckypad/raw/master/japan_test.zip), copy everything inside to the **root** of SD card

* Eject the card and put it back in duckyPad

## Try it out

* **Make sure your system is in Japanese input mode**

* Try the sample profiles and see if everything works

* Especially **Profile 4: Japan**

* Try the top six input mode keys and see if they work

* Open a text editor, and try the bottom 3 keys.

* It will type out some texts and symbols

* The `letter` and `symb` key output should look EXACTLY like below. Let me know if it doesn't.

```
the quick brown fox jumps over the lazy dog
THE QUICK BROWN FOX JUMPS OVER THE LAZY DOG
0123456789

!"#$%&'
()*+,-./
:;<=>?@
[\]^_`
{|}~
```

* `more` key should type out some extended ASCII symbols. Let me know how it looks!

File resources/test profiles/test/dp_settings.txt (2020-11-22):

sleep_after_min 25
bi 4
kbl dpkm_English (UK).txt

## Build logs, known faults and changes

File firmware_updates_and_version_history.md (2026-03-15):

# duckyPad Firmware Updates and Version History

[Get duckyPad](https://dekunukem.github.io/duckyPad-Pro/doc/landing.html) | [Official Discord](https://discord.gg/4sJCBx5) | [Getting Started](getting_started.md) | [Table of Contents](#table-of-contents)

-----

## Latest Firmware

### v3.0.4

15 Mar 2026

* 🐞 Increased Anykey-to-Abort Check Frequency
* 🆕 **"Turing Complete" Mega-update**
	* 👉 [**Full Details**](https://dekunukem.github.io/duckyPad-Pro/doc/beta_test.html)

----------

👇👇👇👇👇👇👇👇👇👇

* [Download Firmware](https://github.com/dekuNukem/duckyPad/raw/master/firmware/duckypad_v3.0.4.dfu)

☝️☝️☝️☝️☝️☝️☝️☝️☝️☝️☝️

## USB Firmware Update

### Enter DFU Mode

Locate the **`DFU`** button:

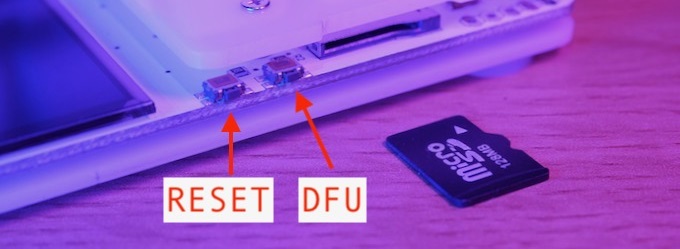
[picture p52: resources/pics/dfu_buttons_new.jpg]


* Make sure duckyPad is unplugged.

* **`Hold down DFU button`** while plugging it into a computer.

* Once plugged in, you can release the button.

If it went well, **the backlight and display should stay off**.

### Windows

Download and install the [STM32 DfuSe tool](resources/en.stsw-stm32080_stm32_DfuSe.zip) from this repo.

(Also available from [official website](https://www.st.com/en/development-tools/stsw-stm32080.html), but requires account sign-up.)

Launch `DfuSeDemo`:

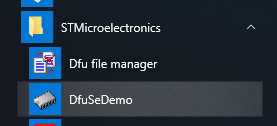
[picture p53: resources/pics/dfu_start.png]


In `Available DFU Devices`, you should see a `STM Device in DFU Mode`.

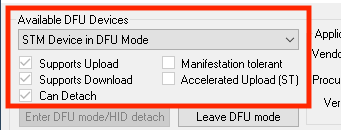
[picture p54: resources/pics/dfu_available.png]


* **⚠️ If nothing shows up**, you might need to install a driver.

	* [Click me for details](https://github.com/dekuNukem/daytripper/blob/master/dfu_driver_install.md)

* Press `Choose...` button

* Select the firmware file you just downloaded. Shoud be in `.dfu` format .



Press `Upgrade` button to start uploading.

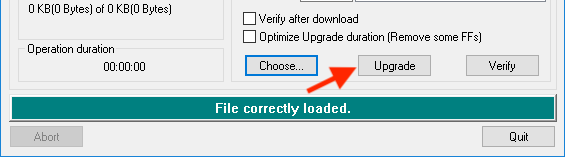
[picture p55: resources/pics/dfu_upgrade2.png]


**It should only take a few seconds!** **`Try using a USB hub`** if it is particularly slow.



After completion, press **`RESET`** button (or power-cycle) to start using the new firmware. 

### macOS / Linux

Using terminal, install [dfu-util](http://dfu-util.sourceforge.net/) with a package manager. For macOS you can use [Brew](https://brew.sh/):

`brew install dfu-util`

Hold DFU button and connect duckyPad, then run:

`dfu-util --device ,0483:df11 -a 0 -D /path/to/duckypad_firmware.dfu`

After completion, press **`RESET`** button (or power-cycle) to start using the new firmware. 

---------------------

## Firmware Version History

### v3.0.3 (5 Mar 2026)

* 🐞 Fixed `GOTO_PROFILE` not working

### v3.0.2 (Feb 9 2026)

* 🆕 **"Turing Complete" Mega-update**
	* **32-bit** Overhaul
	* Proper **Function Calls**
	* **Print Format** Specifiers
	* **Horizontal** Mouse Scrolling
	* **New Commands**, Bug Fixes, and much more!
* 👉 [**Full Details & Changelog**](https://dekunukem.github.io/duckyPad-Pro/doc/beta_test.html)

### 2.3.2 (July 9 2025)

🆕 Increased Persistent Global Variable count to 32

🆕 Added support for **reading and writing PGVs from a computer**. [Details](https://github.com/duckyPad/duckyPad-Profile-Autoswitcher/blob/master/HID_details.md)

🐞 Fixed a bug that caused PGVs to not work

🐞 Fixed a bug where HID buffer was not properly cleared causing ghost inputs

🐞 Fixed a bug that increased chance of SD card corruption

### 2.1.0 (May 24 2025)

🆕 Reduced latency by caching recent keypresses

⚠️ Make sure to use the [Latest Configurator](https://github.com/duckyPad/duckyPad-Configurator/releases/latest)

### 2.0.0 (Apr 7 2025)

🆕 Backported **all new firmware features/improvements** from [duckyPad Pro](https://dekunukem.github.io/duckyPad-Pro/) to OG duckyPad (2020)!

🆕 Unified Configurator that works with BOTH models

🆕 Improved data transfer protocol that reduces read/write time

⚠️ Make sure to **load & save** with the [Latest Configurator](https://github.com/duckyPad/duckyPad-Configurator/releases/latest)

⚠️ `EMUK` command has been deprecated, use `KEYDOWN` and `KEYUP` in `on_press` and `on_release` panels.

### 1.3.3 (Dec 2 2024)

🐞 Fixed a bug where RGB brightness gets dimmer after reloading

🐞 Fixed a bug where `MOUSE_WHEEL` command can be unresponsive

### 1.3.0 (July 2 2023)

🆕 Added `_TIME_S` reserved variable

🐞 Fixed laggy `EMUK`

🐞 Fixed `EMUK` n-key rollover not working

🐞 Fixed crashing when changing profile under certain circumstances

### 1.2.0 (May 3 2023)

🆕 **duckyScript 3** support! 

🆕 Variables, IF statements, WHILE loops, functions, and more.

🆕 Print to OLED screen

🆕 Read button status

🆕 Improved performance

🐞 Assorted bug fixes

💭 As usual, [Let me know](#questions-or-comments) if you encounter any issues.

### 0.21.0 (Nov 23 2022)

🆕 Renamed `HOLD` to `EMUK` for compatibility with duckyScript 3

🆕 Added Japanese input mode keys

🆕 Added JIS keymap

🐞 Minor bug fixes

### 0.20.2 (Oct 28 2022)

🆕 Added `STRINGLN` command. Same as `STRING` but presses enter key at the end.

🐞 Fixed a bug that causes unresponsive keys.

### 0.20.1 (Jul 21 2022)

🆕 `LOOP` state and RGB LED color is now persistent across profile switches and reboots!

🆕 Added `LCR` command to reset loop counter.

🆕 Shortened profile switching animation even more!

### 0.19.8 (Dec 23 2021)

🆕 Shortened profile switching animation, feels much more snappy now!

🆕 Added sleep status byte in [HID info packet](https://github.com/dekuNukem/duckyPad-profile-autoswitcher/blob/master/HID_details.md#info-0x00).

🆕 Added a [new HID command](https://github.com/dekuNukem/duckyPad-profile-autoswitcher/blob/master/HID_details.md#sleep-0x15) to put duckyPad to sleep

🐞 Fixed a configuration error that prevented F13-F24 keys from working under Linux.

### 0.19.1

🆕 Configure duckyPad via USB **WITHOUT taking out SD card!** [Click me for details.](https://github.com/dekuNukem/duckyPad/blob/master/getting_started.md#using-duckypad-configurator)

🆕 Added `KEYUP` and `KEYDOWN` commands for holding keys

### 0.18.0

🆕 **Mouse support!** [Click me for details.](https://github.com/dekuNukem/duckyPad/blob/master/duckyscript_info.md#mouse-buttons)

🆕 **Profile auto-switching** support! [Switch profiles automatically](https://github.com/dekuNukem/duckyPad-profile-autoswitcher) based on currently active window!

🆕 [Two-way HID communication](https://github.com/dekuNukem/duckyPad-profile-autoswitcher/blob/master/HID_details.md) support! Write your own software to control duckyPad!

### 0.17.0

* `LOOP` counter will no longer reset during sleep.

* Key colour changes will also now persist through sleep.

* `MENU` key now works properly.

### 0.16.0

* Added `COMMAND` and `OPTION` aliases for macOS. 

* Added support for right-side modifier keys, such as `RCTRL`, `RSHFIT`, `RALT`, etc.

* [Click me](https://github.com/dekuNukem/duckyPad/blob/master/duckyscript_info.md#special-keys) to learn more.

### 0.15.0

* Added `DP_SLEEP` command to make duckyPad to go sleep.

* Added `PREV_PROFILE`, `NEXT_PROFILE`, and `GOTO_PROFILE` commands for profile switching.

* Fixed a bug, `F13 - F24` keys should work properly now.

### 0.14.0

* Added attributions and metadata in keymap files, updated firmware to handle them.

* Added support for cedilla deadkey in keymaps.

### 0.13.0

* Added `SWCOLOR` command to change the colour of a key inside a script.

* Read about its usage [here](https://github.com/dekuNukem/duckyPad/blob/master/duckyscript_info.md#swcolor-experimental).

### 0.12.1

* Fixed an issue of key sticking with `HOLD` command.

### 0.12.0

* Added an **experimental** `LOOP` command, allowing cycling through different actions on the same key.

* Read about its usage [here](https://github.com/dekuNukem/duckyPad/blob/master/duckyscript_info.md#loop-experimental).

### 0.11.3

* Fixed a bug that prevented `HOLD` command from working on the very first press.

### 0.11.2

* Fixed a bug in keymap parser to allow `SHIFT` and `AltGr` to be pressed simultaneously.

### 0.11.1

* Increased maximum simultaneous key presses to 6.

* Now you can type [alt codes](resources/altcodes.pdf) like `ALT KP_0 KP_1 KP_9 KP_7`.

* Using duckyPad as a WASD gamepad with [`HOLD` command](https://github.com/dekuNukem/duckyPad/blob/master/duckyscript_info.md#hold-experimental) becomes more viable too.

### 0.11.0

🆕 Added keymap file support for multiple keyboard layouts.

* Instead of hard-coded keyboard layouts, you can now download up to 8 keymap files to the SD card and use them on duckyPad.

* See [the updated guide](https://github.com/dekuNukem/duckyPad/blob/master/getting_started.md#using-the-duckypad-configurator) about loading keymaps to your duckyPad.

* See [this guide](https://github.com/dekuNukem/duckyPad/blob/master/keymap_instructions.md) about making your own keymaps.

🆕 Added extended ASCII character support.

* Now `STRING` command can type out characters like `§²µ¤³°ß` if they exist on the current keyboard layout.

🆕 Added support for dead keys.

* `STRING` command can now also use dead keys to type out characters with accents such as `òóôõö`.

🆕 Added German keyboard layout.

🆕 Added `F13` to `F24` keys.

🆕 Added `POWER` key.

### 0.10.0

* Improved `HOLD` command performance

### 0.9.0

* Added profile quickswitching

* **`Hold down`** `+` button and jump between profiles

### 0.8.0

* Added `HOLD` command, where duckyPad will hold a key when you press it, and release only when you release it.

* See [this guide](https://github.com/dekuNukem/duckyPad/blob/master/duckyscript_info.md) for details. 

* This command makes it behave more like a traditional keyboard.

* You can use this command to turn duckyPad into a WASD game pad for example.

* Adjusted configuration file structure. You might need to set your keyboard layout again.

### 0.7.0

* Added support for numpad keys. See [this guide](https://github.com/dekuNukem/duckyPad/blob/master/duckyscript_info.md) for details. 

### 0.6.0

* Added support for `AZERTY (French)`, `AZERTY (Belgium)`, and `Dvorak` layout.

* **`HOLD DOWN TOP LEFT KEY`** while **`PLUGGING IT IN`** to switch layouts.

* Some behind-the-scene optimisation

### 0.5.0

* Added RGB LED brightness adjustment

* Hold down +/- button to change brightness

### 0.4.0

* Added support media keys (volume up/down, play/pause, mute, prev/next track, etc)

* [More details](duckyscript_info.md).

### 0.3.0

* Added support for `MENU` key (the 'right click' key on windows keyboard that no one uses).

* Increased max number of profiles to 32.

### 0.2.1

* duckyPad now store its firmware version on SD card, so PC app can check for updates.

### 0.2.0

Major update. New features and optimisations.

* You can now use symbols like `?*<>/\` in key names.

* Significantly increased profile switching speed.

* Added sleep mode. Your duckyPad can now turn off after a configurable delay. Press any key to wake it up.

* Other minor fixes

### 0.1.0

Initial Release

## Table of Contents

[Main page](README.md)

[Getting Started Guide](getting_started.md)

[Kit Assembly Guide](kit_assembly_guide.md)

[Using duckyScript](https://dekunukem.github.io/duckyPad-Pro/doc/duckyscript_info.html)

[Common issues / Troubleshooting](troubleshooting.md)

[Firmware Updates and Version History](firmware_updates_and_version_history.md)

[Make Your Own Keymap](./keymap_instructions.md)

[Build a duckyPad Yourself](build_it_yourself.md)

[Kickstarter Backer Acknowledgments](kickstarter_backers.md)

## Questions or Comments?

Please feel free to [open an issue](https://github.com/dekuNukem/duckypad/issues), ask in the [official duckyPad discord](https://discord.gg/4sJCBx5), DM me on discord `dekuNukem#6998`, or email `dekuNukem`@`gmail`.`com` for inquires.

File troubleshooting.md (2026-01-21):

# Common Issues / Troubleshooting

[Get duckyPad](https://dekunukem.github.io/duckyPad-Pro/doc/landing.html) | [Official Discord](https://discord.gg/4sJCBx5) | [Getting Started](getting_started.md) | [Table of Contents](#table-of-contents)

----

A couple of commonly encountered issues are explained here.

Click a question below to jump to the answer!

* [I press a key and nothing happens!](#i-press-a-key-and-nothing-happens)
* [Letters and symbols come out wrong!](#letters-and-symbols-come-out-wrong)
* [F13 - F24 keys doesn't work!](#f13---f24-keys-doesnt-work)
* [My duckyPad stopped working on latest firmware!](#my-duckypad-stopped-working-on-latest-firmware)
* [My script behaves inconsistently!](#my-script-behaves-inconsistently)
* [I want to use my own SD card!](#i-want-to-use-my-own-sd-card)
* [RGB backlight is flickering slightly](#rgb-backlight-is-flickering-slightly)
* [RGB backlight is too bright](#rgb-backlight-is-too-bright)
* [The OLED screen isn't working properly!](#the-oled-screen-isnt-working-properly)
* [Numpad keys doesn't work!](#numpad-keys-doesnt-work)
* [SD Card doesn't work on mac!](#sd-card-doesnt-work-on-mac)
* [USB configuration / Autoswitcher isn't working on macOS!](#usb-configuration--autoswitcher-isnt-working-on-macos)

## Join Our Discord!

If you have some issues that's not in this list, feel free to join our [Official Discord](https://discord.gg/4sJCBx5) to ask about it! We also have discussions, script sharing, and latest updates!

----

## I press a key and nothing happens!

First, make sure the key has a valid script mapped to it. If in doubt, use one of the sample profiles.

### Just updated firmware?

Use the [latest configurator](https://github.com/dekuNukem/duckyPad/releases/latest), press `Connect` to load up the data, then press `Save` button to save it back. It should work afterwards.

### If *none* of the keys work

* Check that the cable is plugged all the way in.

* Try a different cable.

* Try a different USB port.

* Try plugging it directly into a computer instead of through a USB hub.

* Try a different computer.

### If a certain key doesn't work

Take off the switch and inspect the pins, chances are one of them is bent:

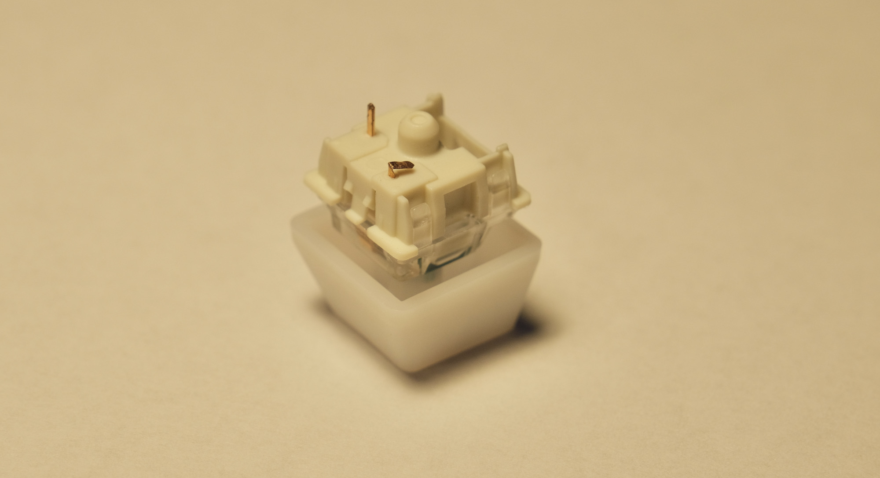
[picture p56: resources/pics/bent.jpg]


If so, straighten it up with a pair of pliers, then insert again. Make sure the **pins are straight** and aim for hot-swap socket holes.

## Letters and symbols come out wrong!

You need select the correct keyboard layout.

* **`HOLD DOWN TOP LEFT KEY`** while **`plugging it in`**.

* Select a keyboard layout.

* Read more about [adding keyboard layouts](getting_started.md#keyboard-layouts) and [writing keymaps](keymap_instructions.md).

## F13 - F24 Keys doesn't work!

Please [update your duckyPad to the latest firmware](https://github.com/dekuNukem/duckyPad/blob/master/firmware_updates_and_version_history.md) to fix this issue.

## My duckyPad stopped working on latest firmware!

If your duckyPad fails to work after updating to latest firmware (0.18.0+), you are most likely affected by a USB chipset bug on recent AMD motherboards.

[Take a look at this article for possible solutions](https://www.tomshardware.com/uk/news/amd-suggest-possible-fixes-for-usb-connectivity-issues). You can also plug it in through a USB hub, which should work.

## My script behaves inconsistently!

duckyPad might be typing too fast for your computer.

You can slow it down by using `DELAY` commands.

* `DELAY n` adds an arbitrary delay in milliseconds.

* `DEFAULTDELAY n` sets the amount of time to wait between **`each line`** of command.

* `DEFAULTCHARDELAY n` sets the amount of time to wait between **`each keystroke`**.

* [More info here](duckyscript_info.md#defaultdelay)

## I want to use my own SD card!

* (Optional) Make a backup of the contents of the original SD card.

* Format the new SD card in `FAT or FAT32`:



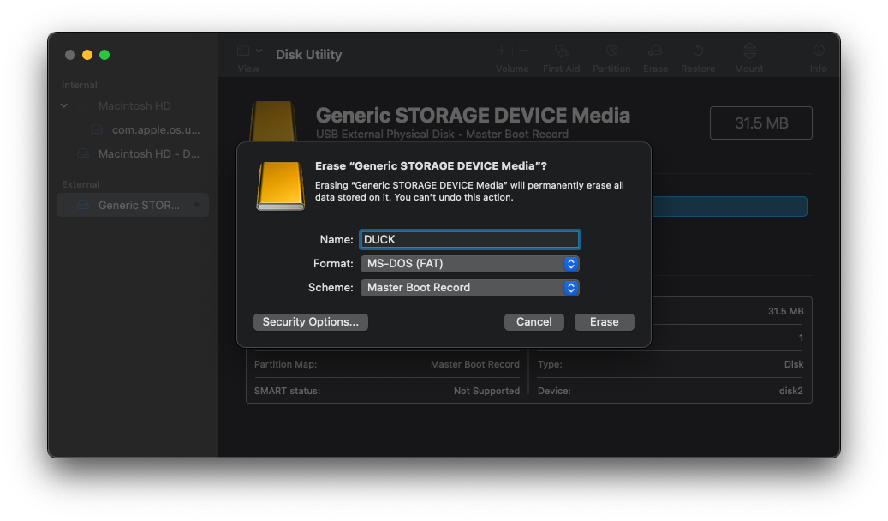
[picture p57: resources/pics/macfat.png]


* Copy all the files back.

* You can also download the [sample profiles](https://github.com/dekuNukem/duckyPad/raw/master/sample_profiles.zip) and copy everything to the **root of your SD card**:



## RGB backlight is flickering slightly

* Make sure the USB port can provide enough power.

* Try plugging it directly into the computer, instead of through a USB hub.

* Also try a different cable if possible.

## RGB backlight is too bright

* You can adjust the brightness by **holding down `-` button**.

## The OLED screen isn't working properly!

If your OLED screen is acting weird, you might want to try to re-seat its ribbon cable.

* Disassemble until you can remove the circuit board. You can [follow this in reverse](kit_assembly_guide.md).

* Locate the tabs on the ribbon cable connector:

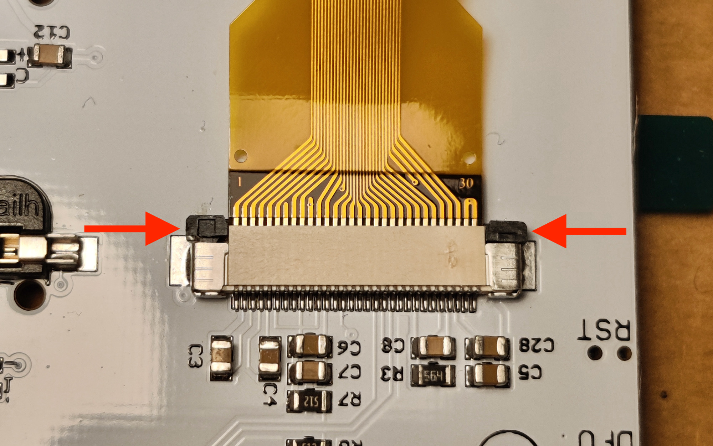
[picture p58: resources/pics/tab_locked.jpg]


* Push it outwards **gently** to loosen the tab:

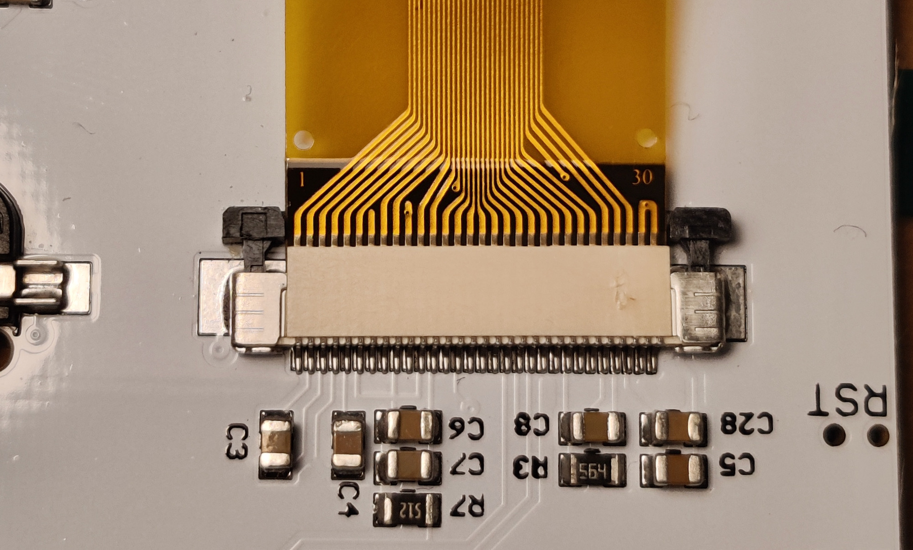
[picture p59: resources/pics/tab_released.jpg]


* Pull out the ribbon cable, and wipe the golden contacts with a dry cloth.

* Use a **DRY** toothbrush (or similar) and gently clean the pins on the connector. 

* Insert the ribbon cable back, make sure it is even and all the way in. Look at the above photos for reference.

* Push the tab back in to lock in place.

* Try it out, if it still doesn't work, [let me know](#questions-or-comments)!

## Numpad keys doesn't work!

Make sure your `NUM LOCK` is on.

## SD Card doesn't work on mac!

If macOS doesn't like your SD card, you can reformat it in FAT/FAT32 in macOS itself, then it should work.

Click `Initialize...`:

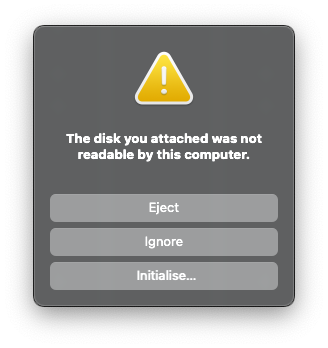
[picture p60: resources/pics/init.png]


In `Disk Utility`, select `Erase`, then `MS-DOS (FAT)`:



Now the card should be readable in both macOS and duckyPad.

If you want, you can copy the [sample profiles](https://github.com/dekuNukem/duckyPad/raw/master/sample_profiles.zip) back to the root of the SD card.

## USB configuration / Autoswitcher isn't working on macOS!

[See instruction here!](https://dekunukem.github.io/duckyPad-Pro/doc/linux_macos_notes.html)

## Table of Contents

[Main page](README.md)

[Getting Started Guide](getting_started.md)

[Kit Assembly Guide](kit_assembly_guide.md)

[Using duckyScript](https://dekunukem.github.io/duckyPad-Pro/doc/duckyscript_info.html)

[Common issues / Troubleshooting](troubleshooting.md)

[Firmware Updates and Version History](firmware_updates_and_version_history.md)

[Make Your Own Keymap](./keymap_instructions.md)

[Build a duckyPad Yourself](build_it_yourself.md)

[Kickstarter Backer Acknowledgments](kickstarter_backers.md)

## Questions or Comments?

Please feel free to [open an issue](https://github.com/dekuNukem/duckypad/issues), ask in the [official duckyPad discord](https://discord.gg/4sJCBx5), DM me on discord `dekuNukem#6998`, or email `dekuNukem`@`gmail`.`com` for inquires.

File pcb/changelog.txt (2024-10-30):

PD4 May 2021

slightly increased LED cutout size 
slightly increased LED pin length
added test points for unused pins
updated silkscreen
adjusted FPC connector trace

---------------

PD5 2021-08-17

Added test point for each key
increased trace width from socket to test point
updated silkscreen
adjusted FPC restrict areas

-----------
duckyPad(2020) v4
2024 10 28

removed PCB mounting hole between +/- buttons
removed unused screw hole
changed +/- button to more sturdy kind
adjusted trace routing
added vias on hot swap pads for more strength
added spare header for BOOT0 button

---------------

8 M2 2.8mm flathead screw
6 M2 4mm standoff
7 M2 2mm standoff
6 M2 8mm flathead screw

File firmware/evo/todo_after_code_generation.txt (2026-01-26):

USBD_CUSTOMHID_OUTREPORT_BUF_SIZE set to 63
CUSTOM_HID_EPIN_SIZE set to 63
CUSTOM_HID_EPOUT_SIZE set to 64

1000hz polling:
CUSTOM_HID_HS_BINTERVAL to 0x04
CUSTOM_HID_FS_BINTERVAL to 0x01

32.768KHz instead of 40KHz
hrtc.Init.AsynchPrediv = 99;
hrtc.Init.SynchPrediv = 399;
---------

go into Middlewares\ST\STM32_USB_Device_Library\Class
replace customHID files

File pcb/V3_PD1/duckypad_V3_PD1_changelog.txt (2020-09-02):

adjust silkscreen
adjusted resistor values to reduce parts count

8 M2 2.8mm flathead screw
6 M2 4mm standoff
7 M2 2mm standoff
6 M2 8mm flathead screw

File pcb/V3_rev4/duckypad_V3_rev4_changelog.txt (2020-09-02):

lined up exposed screws
adjust copper cutout area for screwheads
slightly enlarged reverse-mount LED cutout and hot-swap socket holes for easier machine assembly
moved the screen down 2mm
moved OLED passives to the backside
rerouted FPC GND traces so it's easier to spot solder bridges
added markers on screw holes
updated plate design

assembly layout:

2.8mm screw
top plate
4mm standoff
pcb
2mm standoff
bottom plate
8mm screw

smaller screwdriver

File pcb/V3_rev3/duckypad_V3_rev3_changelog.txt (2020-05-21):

added key plate mounting points, moved Reset / DFU buttons to side. designed new mounting plate that cover more of the circuit board.

curved corners:
https://graphicdesign.stackexchange.com/questions/27465/breaking-polygons-into-paths-in-inkscape

https://graphicdesign.stackexchange.com/questions/111047/inverse-round-corners-with-inkscape

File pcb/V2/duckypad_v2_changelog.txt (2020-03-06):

DONE:
moved header to board edge for easier programming
the 5-pin header is compatible with daytripper pogo board
removed rotary encoder
added gate enable signal pulldown to prevent LED flickering during programming
moved SD card inwards and upwards
added OLED ribbon cable connector, no need to solder the flexible PCB anymore
changed to USBC connector
small button for RST and DFU
moved the screen up a bit
OLED_RESET is now on PA0
BUTTON1 and BUTTON2 are now on PA1 and PA2 respectively
added stabilizer holes to cherry MX switch footprints
used a new button with plastic cap to prevent ESD
cleaned up error screens, print project url on error screen
added instruction on error screen
might have fixed bad boot
use the same white button of DFU/RST for plus minus
remember last selected profile
dim OLED after 2 minutes to prevent burn-in
key aliases in ducky script now supported
no longer needs back plate, rubber feet on PCB, insulating tape over OLED ribbon cable
changed name to duckyPad

reboots when SD card is inserted or removed while powered on
turns off all backlights when starting
repeats the script if key is held down
fixed a few parsing bugs
added dim unused keys option
added individual key colors option
added inverte colour keydown by default

TODO:
add APP/MENU button support
find a logo to put on the front of PCB
find blank keycap with indent?

NOTES:
oled socket midpoint: 7.25mm
oled socket pos (mil): 2860 1890

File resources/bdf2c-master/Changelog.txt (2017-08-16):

User johns
Date Fri Sep 24 15:55:08 CEST 2010

    Initial official release.

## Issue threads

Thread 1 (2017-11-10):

Purchase kit or maybe online bill of materials

sammcj, 2017-11-10:
Neat project!

Not a big fan of the LEDs but love the design.

Any chance of selling some kits with everything needed to make one?

I’d not - perhaps one of those fancy online sites where you could enter the bill of materials and people then links to a cart to buy the parts from somewhere?

Thanks!

nicopastorello, 2017-11-10:
I could buy this kit, I found it incredible

RBM-PITT, 2017-11-12:
What is the budget for the project? Where can i get details on the stencil/oven for soldering - I do not have background in that and need some guidance.

dekuNukem, 2017-11-13:
Well currently I'm not planning to produce kits of this project, it's a lot of work and I don't have time at this moment. However I do still have some empty PCBs left over so if any of you want I can sell one to you. I'll also put together a BOM and put it in the repo this week.

RBM-PITT, 2017-11-14:
I'd like a board. how much?

Cabalist, 2017-11-15:
I'd also like a board.  :)

dekuNukem, 2017-11-15:
I dug around the pile of leftovers a bit, and put together this:

https://i.imgur.com/aqwWSpI.jpg

* one empty circuit board
* one translucent diffuser keyboard plate
* one clear acrylic back plate(it looks translucent because of the protective cover, peel it off and it's clear)
* M3 nuts, screws and standoffs 10 each
* 4 anti slip rubber foot

I'm thinking about $20 for the lot, and I have 3 of those bundles available.

It's not an easy undertaking though. You will need to source the other components, and know how to do surface mount soldering to put them together. Technically you can upload the firmware through USB DFU mode without a programmer by holding down the DFU button while plugging it in. Though it's nice to have a st-link programmer just in case, and some experience with Keil STM32 development would be helpful as well.

Anyway, if you still want to go ahead please contact me on dekunukem gmail com and I'll mail them out once payment is received.

Ill finish writing the BOM before the end of this week.

Cabalist, 2017-11-17:
Hey I sent you an email.  Would love to get your kit* if it is still available.

* Fully aware of the limitations and requirements. :)

sammcj, 2018-02-24:
I take it that by closing the issue - the kit isn’t available?

dekuNukem, 2018-02-26:
I closed this issue as part of my GitHub housekeeping. Currently I don't have a plan for a complete kit, but I do have one last partial set as described in my comment above.

Closed 2018-02-24.

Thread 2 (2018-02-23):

How to load firmware

killboxalpha, 2018-02-23:
In the video you show some jumpers on the header and a loading bar. Could you elaborate? I have build one and I've hit a wall on how to load anything on the chip. This is the first time I've programmed a chip outside of some Atmegas and I just use a arduino board with a socket.

dekuNukem, 2018-02-23:
I did write a short guide on how to upload firmware in another repo, take a look:

https://github.com/dekuNukem/exixe/blob/master/making_some.md

Closed 2018-02-23.

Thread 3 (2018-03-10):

Unexpected error

killboxalpha, 2018-03-10:
After fighting with the cheaper ST-link V2 i bought the proper one and can connect to the board. I see the memory of the STM32 and it is all blank, but when ever I try to program it i get a "unexpected error" and the board resets.

problems with the hex files?

killboxalpha, 2018-03-11:
we used the VDD instead of VDP

Closed 2018-03-11.

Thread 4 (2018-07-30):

I would like to order PCB's for this project

Avery17, 2018-07-30:
I'm trying to order PCB's so I can build this myself. I went to order through OSH Park but it says someone else owns the project files and has not shared them. Would you be able to share them so I can order them for print?

Thanks

dekuNukem, 2018-07-30:
I haven't used oshpark myself, but to me it looks like you just need to upload the [.brd](https://github.com/dekuNukem/kbord/blob/master/pcb/lul.brd) file on its main page. Anyway, personally I use https://jlcpcb.com/ for all my PCBs, they are faster and much cheaper at the same time.

Right now you can get 10 PCBs for $2 made in 2 days, a much better deal than oshpark.

Avery17, 2018-07-30:
I tried to upload the .brd file but it seems to have some copy protection built in and won't let me order it since it seems someone else has already. I'll try jlcpcp though! Thanks!

Closed 2018-08-01.

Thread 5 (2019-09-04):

Rotary Encoders does not work.

barbaroskucuk, 2019-09-04:
I could not get rotary encoders to work. I believe its software related. Any help?

dekuNukem, 2019-09-04:
Hi barbaroskucuk:

You're right, I didn't find rotary encoder particularly useful in my usage, so I didn't write code for it in the firmware. They were removed in the new board revision too.

Still, they are connected to the microcontroller, so if you want you can write something yourself, there are many tutorials on this subject, here's one:

https://howtomechatronics.com/tutorials/arduino/rotary-encoder-works-use-arduino/

Best Regards,

Allen

barbaroskucuk, 2019-09-04:
Thanks so much for the quick response. While you are here i want to ask another question too. Is it possible to change the language in the firmware. What i mean is when my keyboard language is set to english it works perfectly but when i switch to turkish, it does not work properly.

dekuNukem, 2019-09-05:
when you say "not work properly", what does it do that's wrong?

barbaroskucuk, 2019-09-30:
Since i have Turkish layout in my physical keyboard, for example i have " ç " but in English layout its a different letter or a symbol so it does " :" instead of " ç ".  What i'm guessing is that ASCII characters are different for English and Turkish. Is there any way to change the characters or make it language changeable?

LordMayonyies, 2020-08-06:
> I could not get rotary encoders to work. I believe its software related. Any help?

Hii! Did you manage to make it work? I'm looking forward to buy one and I would like to put a pair of rotary encoders. If you manage to make it work, can you share some info please? Thanks in advance!

Closed 2020-09-12.

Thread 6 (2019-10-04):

Build details

disfenoid, 2019-10-04:
Hi, i would like to try to build kbord. As i can see, version described in readme is different from current version of the board. So i have a few questions:
* Is current version of the board is working, or i should use version from specific commit?
* I noticed that now usb type-c used instead of micro, is there any other changes in BOM?
* I'm not a big fan of rgb, will the board work if i will just not solder them?

dekuNukem, 2019-10-04:
Hi disfenoid:

The new version of the board is fully working, I have been using one myself.

As for the BOM, USB connector is different, the four pushbuttons are different, and rotary encoders are removed. I think everything else is the same. I'll take a photo of the new board and update the BOM later today.

The board will work fine if you don't solder the RGB LEDs

dekuNukem, 2019-10-04:
Here are the photos of the current version:

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

I'll update the BOM tomorrow.

disfenoid, 2019-10-05:
Great, thank you!

dekuNukem, 2019-10-05:
BOM is here: https://github.com/dekuNukem/kbord/blob/master/pcb/kbord_v2_bom.xlsx

NeverMinde, 2019-11-13:
> BOM is here: https://github.com/dekuNukem/kbord/blob/master/pcb/kbord_v2_bom.xlsx

Hi, I am trying to build kbord but I got some questions about oled screen connector in 2nd version of your PCB. The 30pin wire bus of 0.96" oled screen have  got 1mm step but PCB pads have got 0.5mm step. So finally question:
How do you solve this problem?
Can you attach some photo of backside with connected screen?

disfenoid, 2019-11-21:
@Ep1quell, I ordered this display and connector: aliexpress.com/item/4000375678671.html, but didn't try yet (still waiting for delivery).

Ep1quell, 2019-11-22:
@disfenoid , with your help I found one more link, here it is: https://s.click.aliexpress.com/e/bd6hKgeO
The main difference is driver IC. In first version of BOM deku said that he using oled with ssd1306 so I think that this will be better cause there is SH1106 in your link

dekuNukem, 2019-11-22:
This one looks like the OLED that I used:

https://www.aliexpress.com/item/32950730252.html

1.3 inch, 30pin FPC connecter, SSH1106 controller.

dekuNukem, 2019-11-22:
this listing comes with the FPC connector as well, and also detailed drawings:

https://www.aliexpress.com/item/4000350633981.html

make sure the 30-pin FPC connector is top-contact type,

kow, 2020-01-10:
do you have any details on the new buttons and usb connector?

dekuNukem, 2020-01-14:
you can find it here:

https://github.com/dekuNukem/kbord/blob/master/build_it_yourself.md

I significantly updated build details today, hope that helps!

Closed 2020-01-14.

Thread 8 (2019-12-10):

switch plate thickness

irongu, 2019-12-10:
Hi, I'm trying to build a kbord, how thick material should I use when making the switch plate?

And I noticed that you changed the model of oled in version 2, but the new model was not described in the bom, which made me buy the wrong oled. After I got the parts, I found there was a problem, and I didn't know the information of the new oled until I came back to see issues. So I hope to add a description of the new oled in the bom so that the people behind will not make mistakes again. Thank you.

ftrrarr, 2020-01-14:
MX plates are usually 1.5 mm

dekuNukem, 2020-01-14:
I used a 2mm acrylic plate and it's fine. I guess 1.5mm works too.

dekuNukem, 2020-01-14:
I have also updated the documentation significantly today with much more build details, hope that helps!

Closed 2020-01-14.

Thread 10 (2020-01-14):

kbord does not work if 3.3V pin not connected to STLink

ftrrarr, 2020-01-14:
I had a board made, flashed it using the instructions and I get nothing from connecting it to USB C, but if I connect the 3.3V Stlink pin, it works fine. What could be going on here?

dekuNukem, 2020-01-14:
I would make sure that the pins on the USB connecter are properly soldered and not touching each other. Also make sure all the pins on the microcontroller is properly soldered and has contact with the pad, sometimes they look like they are soldered but isn't actually touching.

And if there is nothing when plugged into USBC but works when 3.3V is provided, there might be something going on with the power regulator, so check that it is getting power and outputting the proper voltage, also check the decoupling capacitors are not soldered backwards.

ftrrarr, 2020-01-15:
What are the designators for the decoupling capacitors? That's probably the culprit since I thought SMD capacitors were unpolarized.

dekuNukem, 2020-01-15:
The smaller 0805 ceramic capacitor are unpolarized, however the big tantalum capacitor is.

It is C27 near the top right corner:

https://raw.githubusercontent.com/dekuNukem/kbord/master/resources/pics/pcb_front.jpg

The side with a brown band is the positive side.

ftrrarr, 2020-01-15:
Can you link to one like that? I am having trouble finding one with the specs on the BOM. I am so close.

dekuNukem, 2020-01-15:
Here's one:

https://www.ebay.com/itm/20pcs-1210-25V-22uF-226E-B-type-3528-SMD-tantalum-capacitors/292219373942

You can search "1210 tantalum capacitors" on ebay and there are a bunch of them.

ftrrarr, 2020-01-15:
I think there's something wrong on the BOM? It says 47 uF 1220 tantalum cap but I think it should be 22uF 1210 tantalum cap?

dekuNukem, 2020-01-15:
The exact value of C27 doesn't matter that much, anything above 10uF would do. Its just to stabilize the input to the regulator, you might even be able to leave it off, but it's not recommended.

The 1220 is indeed a typo though, should be 1210.

ftrrarr, 2020-01-15:
I've removed the cap but I still have the same problem where I can't get it to work without connecting the 3.3V pin. Would adding the polarized one fix it or is there other troubleshooting I can do?

dekuNukem, 2020-01-15:
Take a look at the pinout of the 1117 voltage regulator (page 3):

http://www.ti.com/lit/ds/symlink/lm1117.pdf

if you have a multimeter, measure the input and output voltage of the regulator. The input should be at USB voltage of 5V, and output should be 3.3V.

ftrrarr, 2020-03-05:
I finally got to measure the regulator, the input gives me 4.77 V which should be fine? But the output is reading at 1.26 V.  One with C27 removed is 1.26V but one with an unpolarized cap on C27 gives me 1.5 V as the output. Is this due to the lack of the tantalum cap? Or what could be the issue? I used REG1117 for the voltage regulator

dekuNukem, 2020-03-05:
Are you sure the 1117 regulator is a 3.3V variant? They have all kinds of different output voltages and 1.2V is one of them.

ftrrarr, 2020-03-11:
That was it. It works now. This was fun! thanks for the project and the help, it's very much appreciated.

Closed 2020-03-11.

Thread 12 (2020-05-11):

Internationalization

simonCor, 2020-05-11:
duckyPad works fine - as long as you have an english keyboard layout. The problem is briefly discussed here: https://github.com/dekuNukem/duckyPad/issues/5

The problem is, that the OS assumes a keyboard layout (and that the USB HID spec not just allows UTF-8). Therefore when e.g. a german keyboard layout is set, the scancodes are interpreted differently.

The keyboard firmware QMK has already a solution in place for this, see https://github.com/qmk/qmk_firmware/blob/master/quantum/keymap_extras/

It is a bit clumsy because then it is necessary to configure the layout used in the firmware but IMHO it is the most practicable solution.
I suggest to modify keyboard.c/.h and to port the QMK solution to duckyPad.

Any comments on that? Others already working on that?

simonCor, 2020-05-20:
This shows the first attempt on my blackpill port:
https://github.com/simonCor/poor-mans-ducky-pad/commit/cd960a5336f6534f1f1e5d817e6d8283d3e78115

Should be useable 1:1 on the original.

This only fixes the ascii characters in different languages - adding more non-ascii characters (äöüß) is not as trivial - then we also have to discuss input format (e.g. UTF-8) and how far we want to go by translating this to keycodes...

dekuNukem, 2020-10-22:
I have added support for AZERTY and Dvorak keyboard layout in a recent update, thanks for the tip!

dekuNukem, 2021-08-19:
Let me do some testing and report back. Do you have a sample script that you would like me to test with?

M-14K, 2021-08-20:
of course, i will let you my profile test examples

[example.txt](https://github.com/dekuNukem/duckyPad/files/7021878/example.txt)

[dp_settings.txt](https://github.com/dekuNukem/duckyPad/files/7021884/dp_settings.txt)
[dp_stats.txt](https://github.com/dekuNukem/duckyPad/files/7021885/dp_stats.txt)
[README.md](https://github.com/dekuNukem/duckyPad/files/7021886/README.md)
[key2.txt](https://github.com/dekuNukem/duckyPad/files/7021887/key2.txt)
[config.txt](https://github.com/dekuNukem/duckyPad/files/7021888/config.txt)

dekuNukem, 2021-08-21:
It seems to work fine on mine, here's a short video:

https://www.youtube.com/watch?v=0jcJJhw7vBk

I would suggest make sure Windows 10 is set to French keyboard layout, and also select French layout on duckyPad, make sure it is on [latest firmware](https://github.com/dekuNukem/duckyPad/blob/master/firmware_updates_and_version_history.md) too.

M-14K, 2021-08-21:
I tryied to downgrade and then upgrade to the last firmware, changed the software too..

My set is on french layout only but i tryed to add us and sadly the error stil persist

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

i took a shot to show you how it works in both of my 3 operating systems... ( all on french only)
https://youtu.be/qBAS8buCyC8

dekuNukem, 2021-08-22:
I seem to remember another user with similar issue solved by using a different USB port for some reason.

It would be helpful if you can test it out on a different computer as well, just to rule it out.

dekuNukem, 2021-08-22:
You can also try clear the keymaps:

Mount the SD card on the PC, delete the `keymaps` folder.

With the SD card still mounted, launch config app, load the SD card, select keymap again, and save. See if it works.

dekuNukem, 2021-08-22:
you can also give this beta firmware a try:

https://github.com/dekuNukem/duckyPad/raw/master/firmware/beta_0.19.6.dfu

I adjusted how keystrokes are sent, so it might be a bit more compatible.

M-14K, 2021-08-22:
"You can also try clear the keymaps:
Mount the SD card on the PC, delete the keymaps folder.
With the SD card still mounted, launch config app, load the SD card, select keymap again, and save. See if it works."

It works but there is a catch, i dont know why but after doing this step i just mounted the SD card again
I created a new profile test and wrote " STRING Câble" to test the "â"  letter.
It worked, but when i just put the old profiles on the SD card the problem apears again i dont lnow why..
Some of them just apeard blank

I guess that i will need to build the profiles 1 by 1 again to bypass this issue

Anyway thanks for your precious time, at least i know that i can make it work again :)

Closed 2020-10-22.

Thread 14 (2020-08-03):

Link to BOM 404's

nsapse, 2020-08-03:
Please fix link or re-upload BOM.

dekuNukem, 2020-08-03:
done

Closed 2020-08-03.

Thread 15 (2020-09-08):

duckypad configurator 0.13 Linux compatibility

simonCor, 2020-09-08:
Hi i just tried the configurator on linux.

It almost works. The only problem is, that you use the color name "SystemButtonFace".

This is not available on Linux. Therefore the only thing you have to be linux compatible is either replace by e.g. "grey" or use a os switch on linux.

Regards

dekuNukem, 2020-09-09:
Thanks for letting me know! Should be a quick fix, I'll do it this week.

dekuNukem, 2020-09-12:
done

Closed 2020-09-12.

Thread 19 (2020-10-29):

Instructions for flashing duckypad on macOS/linux etc

madwort, 2020-10-29:
The duckypad can now be flashed from macOS using http://dfu-util.sourceforge.net/ which can be installed using https://brew.sh/

```bash
$ brew install dfu-util
```

hold DFU button & connect duckypad, then run:

```bash
$ dfu-util --device ,0483:df11 -a 0 -D /path/to/duckypad_v0.8.0.dfu
```

dekuNukem, 2020-10-30:
thanks for the contribution! I'll add it later today.

Closed 2020-10-30.

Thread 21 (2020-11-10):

Keys using HOLD getting stuck on

madwort, 2020-11-10:
Having some issues with the `HOLD` functionality - if I hold for a brief period it works great, if I hold for a longer time it appears to key wedged on. It doesn't seem to be a mechanical issue - unplugging & replugging the duckypad resets it and the key is no longer held on. Using firmware `0.8.0`.

EDIT: also happening with firmware `0.9.0`

dekuNukem, 2020-11-10:
Thanks for letting me know. I'll look into this and do more testing.

madwort, 2020-11-10:
Thanks!

dekuNukem, 2020-11-10:
A couple of quick questions 😅

Does the `HOLD` command issue happens with every key?

How long do you have to hold it for the issue to appear?

Which operating system are you using?

Could you provide a sample script?

madwort, 2020-11-10:
The `HOLD` issue happens with at least two keys, I haven't tested any others yet.

I don't have to hold very long for it to appear.

This was whilst using macOS. However, the button in question is yellow normally and goes blue when I press it (then fades back to yellow). When it gets stuck the light is also stuck on blue, which makes me think the duckypad is stuck not the OS.

This issue was observed with these two scripts:

`HOLD MK_VOLDOWN`
`HOLD MK_VOLUP`

madwort, 2020-11-10:
Hmm, weird - it reproduced consistently earlier, but now I can't get it to reproduce!

madwort, 2020-11-10:
Weird, I could trigger this issue consistently earlier, but I'm trying again now & I can't make it do it.

dekuNukem, 2020-11-10:
Actually I was able to reproduce with volume up/down. Those media keys have different hold and release mechanisms, and maybe I missed something. I'll look into it.

In the meantime, don't use `HOLD` with media keys.

You can invoke them regularly and hold the key down. It will still repeat.

dekuNukem, 2020-11-10:
Check discord for new firmware.

madwort, 2020-11-11:
Loaded `0.10.0`, now to see if I can make it break...

madwort, 2020-11-11:
I've not managed to make it stick, hopefully it's sorted! Thanks!

dekuNukem, 2020-11-11:
That's great to hear! If you have time try out the other profiles and keys as well, hopefully I didn't break something else.

Closed 2020-11-11.

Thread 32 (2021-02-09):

Doesnt turn on

Chieis, 2021-02-09:
I was leaving my macropad to chill and then it suddenly turned off. I tried plugging the USB-C connector to different slots and they all produced the same results. TLDR; it wont turn on.

dekuNukem, 2021-02-10:
Hi Chieis:

Try using a different cable, also try power it on without the SD card and see if the screen lights up.

If it was indeed the hardware I can send you another one.

Allen

Chieis, 2021-02-20:
I have tried to do these but it still doesnt turn on.

Ive used the cable provided in my backing and another one that my friend had owned as well. It does not turn on.

Can you provide your email so I can send you my address?

Thank you.

dekuNukem, 2021-02-21:
sure! it's dekunukem gmail com

Closed 2021-04-04.

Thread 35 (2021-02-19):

LOOP: Lost of counter increment after waking up from sleep mode

TheBigFudge, 2021-02-19:
Hey @dekuNukem

I received my DuckyPad from the Kickstarter campaigna few days ago and I am really excited. I only noticed one small problem:

Currently I using the experimental LOOP function to track if the button was pressed the first time or the second time. To trigger different actions each time.
Unfortunately I noticed that after the DuckyPad was in sleep mode, the counter for the loop starts again at 0 and does not keep the last value.

Is it possible to reload or keeping the old counter value for the loop after waking up?

dekuNukem, 2021-02-19:
Nicely spotted! It does reset everything once it goes to sleep, I'll look into this issue in the next firmware update.

TheBigFudge, 2021-02-22:
Great to hear that :)
the same thing seems to happen when you switch between profiles. But I don't know if it is possible here to save the counter variable persistently, when you are switching between modes

dekuNukem, 2021-04-04:
fixed in the latest firmware update, feel free to try it out!

TheBigFudge, 2021-04-06:
seems to work very well. Thanks a lot :)

Closed 2021-04-04.

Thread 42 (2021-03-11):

Switching profile based on focused application

harryjubb, 2021-03-11:
Hi, really cool project!

Wanted to ask if it is possible to switch the selected profile based on the active application?

A use case example:

> As a programmer, I want duckyPad to be able to switch to a specific profile for VSCode snippets when I switch to VSCode, so that I can instantly have access to the macros that I need to insert snippets

dekuNukem, 2021-03-12:
Not at the moment, but I do want to look into it in the near future.

It would be a bit tricky programming-wise, and there isn't much space left on the microcontroller, but I'll see what I can do.

dekuNukem, 2021-06-01:
Added! try it out here:

https://github.com/dekuNukem/duckyPad-profile-autoswitcher

harryjubb, 2021-06-01:
Amazing! Will do: thank you!

Closed 2021-06-01.

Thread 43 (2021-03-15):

DuckyPad won't turn on

MorganaMan, 2021-03-15:
My duckypad decided to just randomly turn off today and it won't turn back on. I unplugged it and plugged it back in, nada. I've tried a bunch of different cables but no luck. Except, it did flicker on for a second but then went back to not working again

MorganaMan, 2021-03-15:
Don't mind all the errors lmao, I hit enter on accident which was kinda awkward but shh

dekuNukem, 2021-04-04:
It sounds like the cable, maybe try a different one, and I can give you a partial refund if thats the case :)

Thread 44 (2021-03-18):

Temporary layer keys

jasonmhite, 2021-03-18:
Would it be possible to add something that behaves like `GOTO_PROFILE` but it returns to the original layer after the next  (subsequent) key press? This would let us emulate having something like QMK layers so that we could quickly switch between different groups of shortcuts for complicated apps that have a lot of shortcuts.

I'm thinking something like my IDE with a ton of complicated hotkeys. I would have a primary profile with the most common shortcuts, and on that maybe the bottom row of keys are mapped to swap to different profiles with more specialized commands. I could press a swap key and it would shift to the specialized profile, then I press the command I want and it would return to the original layer. This would be a very powerful addition, I think.

I know you're busy and thank you for all the work thus far!

jose1711, 2023-03-11:
You may achieve similar feature with the current beta firmware, note however that in fact you will not be switching to a profile but instead emulating it inside duckyscript. Upon execution DP will show a legend for upper row, then it will start listening on a subsequent keypress. As soon as a user input is detected it executes the action.
```
VAR $k = 0
OLED_CLEAR
OLED_CURSOR 0 0
OLED_PRINT foo    bar    baz
OLED_UPDATE
WHILE $k == 0
    $k = $_READKEY
    DELAY 50
END_WHILE

IF $k == 1 THEN
  STRINGLN foo
ELSE IF $k == 2 THEN
  STRINGLN bar
ELSE IF $k == 3 THEN
  STRINGLN baz
END_IF
```

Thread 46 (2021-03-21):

Bug in dpkm_german.txt

ExitThroughTheWire, 2021-03-21:
Hi,
I had some issues with the character ö and the german keyboard layout. It seems to be a little bug in line 260 of the dpkb_german.txt.

https://github.com/dekuNukem/duckyPad/blob/5889e752dba7bbff93237c88db0a680a2631baf3/sample_profiles/keymaps/dpkm_German.txt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

The correct duckcode for `0xf6` should be `0x0033`, as it is a standad character of the german keyboard layout.
May you'd like to update it in the next version.

And by the way, thanks for this really cool project!

Edit
Some typos

dekuNukem, 2021-03-27:
Well spotted! I have updated it :)

Closed 2021-03-27.

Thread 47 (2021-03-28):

Difficulty updating firmware on Mac

elstamey, 2021-03-28:
Similar to #45, but I am using the correct path.

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

I followed the DFU boot instructions.  But the dfu-util doesn't see it at the address in the command provided.  I don't know how to find it.

When I boot normally, there is no attached ducky, so I don't know where to direct the configurator to test any change.  Am I supposed to do this with the micro sd reader?  the leds respond when I press keys, but even characters like numbers and letters do not type.  I would like to update the firmware to see if that fixes it.

dekuNukem, 2021-03-29:
Sorted in discord, turned out to be a faulty USB cable :)

Closed 2021-03-29.

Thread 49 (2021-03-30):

WIN10 home "Unknown USB Device"

Olfried2, 2021-03-30:
Hallo,
after the update yesterday, windows doesn't like the duckypad anymore. In device manager the pad will be (not) recocgnized
as "Unknown USB Device (Device descriptor request failed)"
OS-Info
Version 2004
OS build 19041.867
Experience Windows feature experience pack 120.2212.551.0

Duckypad FW 0.16.0

Any ideas how to get it back to work ?
Thanks in advance

dekuNukem, 2021-03-30:
Hi there! It looks more like a cable issue than the pad itself. Here's a few things to try out:

* Try a different USB cable

* Make sure it's plugged in all the way

* Plug it directly into the computer instead of through a USB hub

* Try it on a different computer

Let me know how it goes!

dekuNukem, 2021-03-30:
By the way, it is not possible to brick the device, so you can always go through the procedure flash any version of the firmware you like.

Olfried2, 2021-03-30:
It seems that a different cable will do the job, I'll investigate further behaviour.

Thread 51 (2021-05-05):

Single key port doesn't work (not bent pins)

dayne, 2021-05-05:
I have a single key that doesn't work on the DuckyPad I recently received.

I double/triple checked for bent pins and swapped keys even.  Decided to by-pass the whole "switch" and jump the contacts with a wire.  I verified the working keys work with the contact jump method but the single key does not work that way.

Any insight on where to begin the next phase of debugging would be apricated.

dekuNukem, 2021-05-05:
Hi there! Have you tried jumping the metal parts of the hot-swap socket from the backside like this?

https://i.imgur.com/GkvqPQW.png

If it works, the socket should be fine. If not, the check if the socket has lifted from its pad. let me know how it goes.

dayne, 2021-05-18:
@dekuNukem Thanks for the response. Sorry for lag on my side.

Finally dug out the keypad and tried this test at those specific metal parts of the hotswap socket section. Sadly still didn't work.

Recommendations for next steps?  I was thinking getting out the soldering iron but I want to make sure I'm point in a healthy direction before messing up something that can be easily fixed.

dekuNukem, 2021-05-18:
hey no problem! If that's the case I can send you another circuit board, feel free to DM me on [duckyPad discord](https://discord.gg/4sJCBx5), or email dekuNukem^gmail com, and we can discuss the details.

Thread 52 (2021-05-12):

DuckyPad config v0.12.0 win10 failed to start

DikUl, 2021-05-12:
v0.11.0 working great, v0.12.0 doesn't start at all.

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

dekuNukem, 2021-05-12:
I just fixed it 😅 try 0.12.1:

https://github.com/dekuNukem/duckyPad/releases/tag/0.12.1

DikUl, 2021-05-12:
> I just fixed it 😅 try 0.12.1:
>
> https://github.com/dekuNukem/duckyPad/releases/tag/0.12.1

That was quick 😅

Closed 2021-05-12.

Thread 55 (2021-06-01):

OLED out

jeaous21, 2021-06-01:
Suddenly my OLED screen went out.
The key backlight works, a works, and the DFU function works.
(I updated firmware)
I tried changing the cables and it still doesn't work.
What can I do? (Can I fix it? or replace new OLED?)

dekuNukem, 2021-06-01:
Hi there! Give this a try if you haven't already: https://github.com/dekuNukem/duckyPad/blob/master/troubleshooting.md#the-oled-screen-isnt-working-properly

If that doesn't work, I can arrange a replacement :)

TheBigFudge, 2021-06-21:
Had the same issue, after using it a couple of months. But re-seating the OLED ribbon cable solved the issue for me :)

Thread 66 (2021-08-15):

Windows 10 + Zen 3 not recognising FW 18.0 or higher

amck1nnon, 2021-08-15:
I have kind of fixed this issue for myself now, but I thought I should probably document that here since there was a fair bit of trial and error - and the solution was different for two machines. Apologies for the stream-of-consciousness style. Between the two machines, there was a decent amount of work to figure out what was going on.

This _might_ be related to the B550/X570 USB issues listed in the release notes... But as far as I can see
- that doesn't seem to have an open issue thread already
- troubleshooting associated with the fix *might have* worked on one of the machines, but it did not contain hardware that is known to be affected by the reported USB chipset bugs
- the issue itself wasn't really consistent with the other AMD chipset/USB issues experienced by myself and others on the internet, wherein there seems to be some kind of sporadic signalling issues that cause devices to occasionally stutter/drop out etc. In my case the device failed to be recognised by Windows in any way - it acted as if it was not plugged in at all

Machine 1: Asus ROG Flow X13 - Ryzen 7 5800H (Zen 3 Mobile)
- Device functioned as expected on firmware 17.0
- No longer lit up or powered on at all following upgrade to 18.0, and Windows did not even seem to acknowledge something had even been plugged in
- Issue not resolved by BIOS update (to be expected - I don't believe any AGESA updates are being issued to address this for Zen 3 Mobile, as it doesn't seem to be affected. As noted above, the most common theory is that it's PCIe 4.0 related - which the mobile variant of Zen 3 doesn't support)
- Appeared resolved following AMD chipset driver update, device then recognised and functioned as expected - but in hindsight (troubleshooting on each device was easily at least 2-3 weeks apart) and considering how it was fixed for my other machine - it may have actually been the change from a USB A port to a USB C port, which presumably the laptop may treat as a different hub?

Machine 2: Asus ROG Strix X570 - Ryzen 7 5800X (Zen 3)
- Device functioned as expected on firmware 17.0
- No longer lit up or powered on at all following upgrade to 18.0, and Windows did not even seem to acknowledge something had even been plugged in
- Issue not resolved by BIOS update (latest beta revision for my motherboard contains AGESA 12.0.3B)
- Issue not resolved by latest AMD chipset drivers
- Issue not resolved by the first of two USB hubs I tried (in this case - the hub built into my monitor. Standard USB 2.0 hub)
- Issue not resolved by disabling all PCIe 4.0 support, disabling global C States, disabling XHCI handoff
- NOTE: is was about here amongst the many reboots I noticed that it still worked perfectly in the BIOS, and would turn off partway through the Windows loading screen
- Issue not resolved by disabling driver signature enforcement, safe mode or a Windows repair
- Issue not resolved by trying other USB ports (front panel, CPU controlled, chipset controlled etc)
- Issue finally resolved by plugging into a more advanced USB 3.0 hub with HDMI/Ethernet/other junk; at which point Windows notified me that it was installing drivers for 'duckyPad(2020)' and then functioned as expected
- Following the detection by Windows and the installation/updating of drivers, the device is now detected and functional without the hub, on all USB ports, regardless of AGESA version and the other settings (have since rolled back to last non-beta version)

I don't know enough about USB to say for sure, but having now flicked through everything; it seems like it might come down to some kind of Zen 3 + Windows 10 specific USB driver/configuration issue?

LeoBoost, 2021-09-12:
Working fine here with Firmware 0.19.1, running on a Ryzen 7 5800X on an ASUS Prime X470-Pro - I don't know what kind of conclusions one could draw from that, but I also never encountered the other USB related bugs with this setup.

vdcorduroy, 2022-01-12:
I had same the issue as amck1nnon with Ryzen 3700x & MSI x570 MPG Edge, running Windows 10 on NVME drive with PCIE 4.0.
I tried all of the mentioned as OP, the only thing that finally helped was trick with USB hub. Connecting DuckyPad through hub triggered installation of drivers and it was recognized almost immediately.

Closed 2023-05-08.

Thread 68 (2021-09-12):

Unicode Support

kj4ezj, 2021-09-12:
## What
With duckyPad firmware `v0.19.1` and duckyPad Configurator `v0.13.3`, [Unicode](https://en.wikipedia.org/wiki/Unicode) is not supported.

Specifically, I am unable to:
1. Set a profile name with Unicode characters
   - Example: [`pīnyīn`](https://en.wikipedia.org/wiki/Pinyin)
1. Set a key name with Unicode characters
   - Example: `ˉ`, a [macron](https://en.wikipedia.org/wiki/Macron_(diacritic))
1. Send Unicode characters using the `STRING` operator in duckyScript
   - Example:
     ```duckyscript
     STRING ā
     ```

From the host computer's perspective, non-ASCIII<sup>[1]</sup> characters are stripped from the string. In cases where that results in an empty string, the operation fails or is a no-op. If you inspect the contents of the SD card then you'll find the Unicode characters from the macros are in the `*.txt` config files, but they are not sent to the host.

Worse more, there is no mention of Unicode (or lack thereof) in the [README](https://github.com/dekuNukem/duckyPad/blob/ea8681f502395711e48f4435a333ae9958318c29/README.md), [Kickstarter](https://www.kickstarter.com/projects/dekunukem/duckypad-do-it-all-mechanical-macropad), [Tindie](https://www.tindie.com/products/dekuNukem/duckypad-do-it-all-mechanical-macropad), [Writing duckyScript](https://github.com/dekuNukem/duckyPad/blob/ea8681f502395711e48f4435a333ae9958318c29/duckyscript_info.md), or [Common Issues / Troubleshooting](https://github.com/dekuNukem/duckyPad/blob/ea8681f502395711e48f4435a333ae9958318c29/troubleshooting.md) pages.

## Why
[All languages](https://stackoverflow.com/questions/702899/need-a-list-of-languages-that-are-supported-completely-by-ascii-encoding) besides _maybe_ English and traditional Latin require non-ASCII characters. Even English speakers rely on Unicode to type emoji, arrows, mathematical symbols, and other special characters. For the duckyPad to be inclusive and useful, Unicode support is crucial.

## How
There would be three parts to this work:
1. Supporting Unicode in duckyScript
1. Supporting Unicode on the OLED
1. Supporting Unicode in the "configurator" app

Adding support for the [UTF-8](https://en.wikipedia.org/wiki/UTF-8) Unicode would probably be easiest and make the most sense due to backwards-compatibility and filesystems support. Using UTF-8 string libraries adding maps to `font.c`, and UTF-8 strings in duckyScript would get us much of the way there. I wondered if it is even possible for a keyboard to send Unicode characters to a host, but [QMK seems to have figured it out](https://beta.docs.qmk.fm/using-qmk/software-features/feature_unicode), so the answer must be "yes."

### Memory
This might be more work than I thought when I started writing this issue. -_-

The biggest obstacle is the memory of the STM32F072C8T6 micro [we're using](https://github.com/dekuNukem/duckyPad/blob/ea8681f502395711e48f4435a333ae9958318c29/build_it_yourself.md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). [Digikey](https://www.digikey.com/en/products/detail/stmicroelectronics/STM32F072C8T6/5051281) and [Mouser](https://www.mouser.com/ProductDetail/STMicroelectronics/STM32F072C8T6?qs=4b8myOmUP%252BsnybMOCvNZeA%3D%3D) spec the SoC out at 16 kB RAM and 64 kB ROM, which is not enough for full Unicode support. The font map alone would be 2<sup>21</sup> * 6 * 10 = 120 MB if all codepoints were supported and used. We could cut it down to 4 MB or so to support languages using the first 16 bits, plus all emoji.

We could:
1. Page in Unicode fonts from the SD card
1. ~~Try to compress the font map~~
1. Use the configuration tool to load only the Unicode characters in-use by the OLED for the current set of profiles onto the micro, since most characters won't be used by any given customer profile set, but this will make manual configuration harder
1. Bump the SoC to something that has enough RAM for future orders, but this won't help existing customers

### OLED
I spent a brief amount of time making sure the OLED supports Unicode. I can't read German, but an OLED equivalent to the one [we use](https://github.com/dekuNukem/duckyPad/blob/ea8681f502395711e48f4435a333ae9958318c29/build_it_yourself.md#oled) for sale on [Adafruit](https://www.adafruit.com/product/5228) supports writing arbitrary characters or pixels. In the code, it looks like [`print_keymap()`](https://github.com/dekuNukem/duckyPad/blob/ea8681f502395711e48f4435a333ae9958318c29/firmware/code/Src/my_tasks.c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) is calling [`ssd1306_WriteString()`](https://github.com/dekuNukem/duckyPad/blob/ea8681f502395711e48f4435a333ae9958318c29/firmware/code/Src/ssd1306.c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), which calls [`ssd1306_WriteChar()`](https://github.com/dekuNukem/duckyPad/blob/ea8681f502395711e48f4435a333ae9958318c29/firmware/code/Src/ssd1306.c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), which is capable of [writing arbitrary pixel arrays](https://github.com/dekuNukem/duckyPad/blob/ea8681f502395711e48f4435a333ae9958318c29/firmware/code/Src/ssd1306.c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) given as fonts. We're passing [`Font_6x10`](https://github.com/dekuNukem/duckyPad/blob/ea8681f502395711e48f4435a333ae9958318c29/firmware/code/Src/my_tasks.c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) from [`font.c`](https://github.com/dekuNukem/duckyPad/blob/ea8681f502395711e48f4435a333ae9958318c29/firmware/code/Src/fonts.c), so adding new characters to this map should be sufficient to support UTF-8.

## Notes
1. Technically the subset of ASCII characters listed in [fonts.c](https://github.com/dekuNukem/duckyPad/blob/ea8681f502395711e48f4435a333ae9958318c29/firmware/code/Src/fonts.c).
1. **Why can't you use duckyScript to enter Unicode characters as shortcuts?**
   I can, but this isn't portable. Furthermore, not all hosts support this for any given character I might want to type. For example, macOS does not seem to support writing all characters needed for [pīnyīn](https://en.wikipedia.org/wiki/Pinyin) without changing keyboard layouts.
1. **Why don't you compile the project with a font map including all the characters _you_ are trying to use?**
   I probably will, I haven't gotten that far. But that isn't a realistic solution for most people.
1. I am very exited about my duckyPad as-is, grateful for an opportunity to contribute by opening an issue, and hopeful that I can contribute code soon.

## See Also
- [Issue 12](https://github.com/dekuNukem/duckyPad/issues/12) - Internationalization
- [The Absolute Minimum Every Software Developer Absolutely, Positively Must Know About Unicode and Character Sets (No Excuses!)](https://www.joelonsoftware.com/2003/10/08/the-absolute-minimum-every-software-developer-absolutely-positively-must-know-about-unicode-and-character-sets-no-excuses/)

I look forward to hearing feedback on this.

dekuNukem, 2021-09-13:
Hi there!

Thank you very much for the feedback! I do agree that unicode support is very important to the internationalization of duckyPad. However, as you pointed out, it would be quite a lot of work to get it implemented properly. And I have a few observations of my own:

* On the current firmware, the RAM is 98% full, and ROM is 85% full, so there probably won't be too much new features to squeeze in without extensive rewrite and optimization.

* duckyPad OLED support the first 128 ASCII characters, and duckyScript itself supports the full 256 extended ASCII characters. The vast majority of duckyPad users are in North America and Europe, where this coverage is sufficient.

* duckyPad emulates a regular USB keyboard and send scan codes to emulate key presses, and I don't think there are unicode keys on keyboards. You can type them out with ALT codes and other shortcuts, but you can do it with duckyScript too.

* I took a look at the QMK support, and it’s a bit clunky to be honest. You’ll need to change the configuration file, edit the source code, re-compile, and still have to do system-level changes to get it to work. Different systems handle unicode inputs differently, so that's another thing to worry about.

In the end, I feel that unicode is a rabbit hole that I'm a bit reluctant to go down at the moment. Although it might be a good idea to add an option in the configurator to convert unicode characters to ALT codes should the user want. It is definitely on the table should I make an updated version of duckyPad with a more powerful processor though.

uckfayer, 2022-03-12:
Due to the USB HID Spec sending actual Unicode characters is impossible and the only workaround is using an OS specific Input Method like Alt Codes or the Compose Key.
One helpful workaround could be a script, website, or modification to the Configuratior to automatically convert Unicode characters to Duckyscript for the the equivalent Alt Code.

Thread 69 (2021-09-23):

Feature request: random input

tnorthcutt, 2021-09-23:
First off: I _love_ my duckyPad! It's fantastic and saves me tons of time.

One of my common use cases is for manual UI testing while I'm doing software development. In these situations, it would be very useful to have some way of randomizing the typing – for instance, I often need to fill out the same form over and over, but with a different name, email address, or other details each time.

In one software application I've used in the past that provides text expansion triggered by a shortcut, I've accomplished this by having it type the current UNIX timestamp, for instance, as a unique string.

Is it possible to expand duckyScript to allow for some sort of random character output, or executing user-defined functions, or something else that would solve this use case?

dekuNukem, 2021-10-03:
Hi there! Random input is a bit of a niche feature, so it's not very high on my to-do list right now. However, you can easily use a input scripting tool like autohotkey or pyautogui to achive what you want, and use a hotkey on duckyPad to trigger it.

tnorthcutt, 2021-10-04:
@dekuNukem That certainly makes sense, thank you for the suggestion! Leaving this open in case you want it as a placeholder for the feature request but I understand if you choose to close it.

Closed 2023-02-07.

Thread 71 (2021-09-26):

Is it possible to press alpha keys simultaneously?

Nascentes, 2021-09-26:
Trying to create a macro that combines various alpha keys but cannot get them to register as simultaneous presses without millisecond delays.

I've tried:

```
DEFAULTDELAY 1
STRING a b
```

```
DEFAULTDELAY 1
KEYDOWN a b
KEYUP a b
```

Not really sure how else to try it.

dekuNukem, 2021-09-26:
First of all, `DEFAULTDELAY` is the number of milliseconds to wait between **each line** of code. 1ms is way too short for the computer to catch up, the default is around 18ms, and it's better to stick to that for now.

I think `KEYDOWN` and `KEYUP` only work with one key, so try this

```
KEYDOWN a
KEYDOWN b
KEYUP b
KEYUP a
```

Let me know how it goes!

Nascentes, 2021-09-26:
Wow that was quick! No joy on that. Heck, even if I test using modifiers and do...

`CTRL RCTRL` for inputs, it still registers CTRL prior to RCTRL and not simultaneously

dekuNukem, 2021-09-26:
I tried out `CTRL RCTRL` on mine, and it seems to work fine, here is the key history in autohotkey:

```
A2  01D         d    2.61    LControl
A3  11D         d    0.01    RControl
A3  11D         u    0.02    RControl
A2  01D         u    0.03    LControl
```
I think on a keyboard it's not possible to press two keys "simultaneously", there's always a first and second, just with a tiny delay in between. The computer acts when the second key is pressed while the first is still held down.

Anyway, if you want, feel free to tell me more about what you want to achieve, and maybe I can see what is the best approach.

Nascentes, 2021-09-26:
That makes sense to me. I'll see about pursuing some other options. Mostly trying to set up an accessibility profile for a friend to be able to play some fighter games on PC. May need to pursue using a virtual controller and/or AHK

Nascentes, 2021-09-26:
Can confirm I was able to accomplish this via AHK. Just in case anyone else Googles upon this, here is what ended up working for AHK & DuckyPad:

```
#NoEnv
; #Warn
SendMode Input
^1::
  {
	Send, {a down}{b down}
	Sleep, 20
	Send, {a up}{b up}
  }
return
```

With my Duckypad key being simply `CTRL 1`

Closed 2021-09-26.

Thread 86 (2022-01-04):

Problem with a key color

mobily, 2022-01-04:
Hello @dekuNukem! I found a pretty strange issue, one key has a different color, it's green, but in the duckyPad configurator, it's set to red. Do you know what may cause this problem?

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

dekuNukem, 2022-01-04:
That's very strange indeed!  I wonder if the red element of that RGB LED is damaged, maybe try a few more colours and see if there is any red element on that LED at all. Maybe try a different SD card too to rule out the possibility of file corruption too.

If it is indeed a hardware issue, I can arrange a replacement.

mobily, 2022-01-04:
@dekuNukem it started working correctly again, apparently, an SD card reformat has helped 🚀 thank you, keep it up, I love duckyPad! ❤️

mobily, 2022-01-04:
@dekuNukem it seems to be a problem with the red element of that RGB LED, and yes, it might be damaged 😢

- works when the color is set to cyan:

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

- works when it's set to blue:

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

- works when the color is to green:

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

- doesn't work when the color is set to white, brown, purple, or red:

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

dekuNukem, 2022-01-04:
yeah that does look like the case, let me know your order number and I can send you another one for free.

mobily, 2022-01-04:
thank you so much, I really appreciate that! ❤️ here's the order number: 300063

dekuNukem, 2022-01-04:
Sure! I'll send it out tomorrow :) Same address?

mobily, 2022-01-04:
yup, same address 😊 thank you once again!

dekuNukem, 2022-01-06:
I have dropped it off, and it should arrive in the usual time :)

mobily, 2022-01-19:
hey @dekuNukem, I got the new board you sent me, thanks for that! ❤️ however, seems it might be broken as well, after connecting to my mac, the SD card isn’t visible, as well as `dfu-util` doesn’t see it, keys don’t react on pressing, and the RGB backlight doesn’t work too

I have tried to use a different either USB-C cable or USB port, and literally, nothing works 😢 although, it boots up!

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

dekuNukem, 2022-01-19:
Hi there! Sorry to hear about the issue, it is rather unusual to have 2 of them be faulty in a row. I would suggest try holding `+` button on the duckyPad, it should go into quickswitch mode, and LEDs should be all white, see if that works. You can also try [re-formatting the SD card and copy back the sample profiles](https://github.com/dekuNukem/duckyPad/blob/master/troubleshooting.md#i-want-to-use-my-own-sd-card), or even try one of your own SD cards. It would also be helpful to try it on a different computer, a PC perhaps, or even a phone or tablet.  Let me know how it goes!

mobily, 2022-01-19:
> it is rather unusual to have 2 of them be faulty in a row.

that's what I initially thought as well, it's simply impossible to have that bad luck 😆

the old board → seems everything works fine, I can connect with the board via the configurator app, `dfu-util` recognizes the device, the RGB backlight works as well (excluding that one key backlight) and when I press a key, a specific action is performed on my mac

the new board → I can't connect with the board via the configurator app, `dfu-util` doesn't recognize the device, the RGB backlight is off all the time, nothing happens when I press a key, however, I can switch profiles with `+` and `-` buttons and go into the quickswitch mode

both boards are using FW 0.19.8, is there any other way to flash FW if `dfu-util` doesn't recognize the device?

(here's the photo with both boards, the old board is on the left side, the new one is on the right)

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

mobily, 2022-01-19:
the new board isn't listed in the connected HID devices
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
and the old one:
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

dekuNukem, 2022-01-20:
It seems that the new duckyPad isn't getting data through, that's why it is not recognised by the PC. Perhamp you can try cleaning the pins on the USB connector as well as the pins on the microcontroller chip using a dry clean toothbrush or somthing, make sure nothing is stuck between the pins. Maybe try a different able too, but I'm sure you already did that.

Anyway, I can keep sending you more boards until it works 😅 but let's make sure first

Closed 2022-01-04.

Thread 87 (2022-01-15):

HOLD works only one time correctly

benjaminaigner, 2022-01-15:
Dear @dekuNukem ,

I got a duckyPad as a present from my colleague and now I'm adapting it to my personal needs.

Following behaviour I noticed with the HOLD functionality:

**Expected**
I want to switch between windows via `ALT+TAB` (opening the overview), step through the windows
with `LEFT` / `RIGHT`. To keep the selection opened, `ALT` should be hold with the one button, switching
the windows is done with two other buttons.
Following script is used for the `ALT+TAB`:
```
HOLD ALT
TAB
```

**Current behaviour**
The first time it is working, `ALT` is pressed, `TAB` is pressed & released, `ALT` is released on button release.
But the second time, the `ALT` key is still hold, but no `TAB` is sent.

THX for this nice piece of hardware!

dekuNukem, 2022-01-15:
Hi there! Please use `KEYUP` and `KEYDOWN` for this use case. You can [read more about it](https://github.com/dekuNukem/duckyPad/blob/master/duckyscript_info.md#KEYDOWN--KEYUP) here.

benjaminaigner, 2022-01-16:
@dekuNukem

THX for your suggestion, but I'm not sure if this works as expected:

```
KEYDOWN ALT
TAB
KEYUP ALT
```
Would be my suggestion to use KEYUP/DOWN. Unfortunately, this doesn't work.
To open the window overview, the firmware should press the ALT key as long as I hold the button.

Each time I switch the profile, it works with HOLD as expected, but only one time. Then a profile switch is needed to have it working again.

dekuNukem, 2022-01-16:
`HOLD` command makes a key behave like a regular keyboard key, aka it stay pressed when you press it, and releases only when you release. It can be used for push-to-talk, or WASD gamepad and the like.

`HOLD` command is supposed to be only used by itself, and only with one or two keys. Mixing this command with others will cause unintended behaviour as you mentioned.

What happens is that `HOLD` command caches the key into memory so it won’t have to read the SD card every time you press the key, reducing the latency. So it goes through the script the first time, then it executes from cache only from then on.

For what you want to do, you can probably try something like this:

```
KEYDOWN ALT
KEYDOWN TAB
LEFT
LEFT
KEYUP TAB
KEYUP ALT
```

Might need some delay inbetween, but that should be the gist of it, feel free to try it out and let me know how it goes!

benjaminaigner, 2022-01-17:
THX for the clarification!

Maybe another way to implement this key combination:
Would it be possible to introduce a `WAIT_RELEASE` command which stops the button script execution until the button is released again?
(just a suggestion)

In this case, a script could look like:
```
KEYDOWN ALT
TAB
WAIT_RELEASE
KEYUP ALT
```
Anyway, I will try different ways to solve my problem.

benjaminaigner, 2022-11-23:
@dekuNukem THX, I'll update my pad!

Closed 2022-11-23.

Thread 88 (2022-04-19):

No timeout set on firmware/release check

Nick-Watton, 2022-04-19:
Hello!

OS: Windows 10
Using included USB-C cable

Today there was an issue with GitHub codespaces, which impacted the duckyPad configurator application.
Upon clicking Connect, the application would hang for 2 minutes while it checked for new releases and firmware, I assume a default of 1 minute per call.
Once the timeouts had finished, I was able to configure as normal. However saving changes proved a bit problematic - it did update the pad but I also encountered this error during saving.
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

I see you implemented a timeout in `is_internet_available()`  in `check_update.py` but not for the GitHub checks.
I would say the same probably needs to be implemented for these other checks so that the application can function normally without GitHub if necessary.

dekuNukem, 2022-04-19:
good catch! I didn't really expect github would go down like this. I'll add it.

As for the error, looks like it didn't find duckyPad. Was it able to connect and load profiles in the first place?

Nick-Watton, 2022-04-19:
After the timeouts it loaded the profiles correctly, yes.
Saving did not immediately update the board. It went though "Saving.." to "Saved!" in the text next to the connect button, but the board did not update for ~55 seconds after initially clicking save (and only sometimes throws the save-error). Only then did the text update to "done". I'm not sure if there are more calls to GitHub during the autobackup (I can see one [here](https://github.com/dekuNukem/duckyPad/blob/master/pc_software/duckypad_config.py#L1261) but I haven't thoroughly checked the impl), but I think it's probably related to the GitHub issues and would likely be resolved by implementing a timeout on those calls.
Thank you for such a prompt response!

Closed 2022-11-23.

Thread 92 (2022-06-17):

DIY not connecting to pc

VelocityK9, 2022-06-17:
I decided to go to DIY route and made one myself. After soldering everything and plugging into the pc to flash it nothing happens. Holding the dfu button on powerup by my testing just sets the TX and clk to 3.3V

dekuNukem, 2022-06-23:
Hi there! Make sure the chip is in the correct orientation, and all the pins are connected with no solder bridges between them.

If you have a ST-Link programmer you can try hooking it up to the header on top-right of the PCB and see if it connects. Steps are below:

https://github.com/dekuNukem/STM32_tutorials/tree/master/lesson0_intro_blinkLED#hookup

Also, if you got the STM32F072C8T6 chip from ebay or aliexpress or similar, it might have been re-badged from a similar but different part. I once had a STM32F072C8T6 that is actually STM32F071C8T6, which is almost the same but does not have USB functionality, and therefore does not work with USB DFU.

VelocityK9, 2022-06-26:
I'll order a ST-Link and see if I can do anything with it. Since it was ordered from Aliexpress theres a high chance its a "fake". If so do you know where I can buy them in eu or salvage them from boards similar to [this](https://www.aliexpress.com/item/1005003880238896.html?).

dekuNukem, 2022-11-23:
Cleaning up the issues, let me know if you have any further questions!

Closed 2022-11-23.

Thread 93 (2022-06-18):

DuckyPad OLED screen freezed when starting up PC

SnailMango, 2022-06-18:
Hello! My DuckyPad started having this issue since a couple of months.
When I startup my PC, it lights up normally, but when I try to switch profile using the - and + buttons, the screen is freezed on the first functions list. In order to make it work again, I have to disconnect and reconnect the USB cable. If I push the reset button on the side, the screen turns off and it won't work anymore if I don't disconnect and re-connect the cable.
I already tried re-flashing latest firmware and changing cable but the problem is still the same.
What can I do? I'm attaching a video of the problem.

https://user-images.githubusercontent.com/64862343/174437614-ad5e09dc-cf4d-406d-bfab-43790c2fdb29.MOV

dekuNukem, 2022-06-18:
Hi there! Looks like the OLED screen is acting up a bit, re-seating the ribbon cable usually fixes it, you can find the instruction here:

https://github.com/dekuNukem/duckyPad/blob/master/troubleshooting.md#the-oled-screen-isnt-working-properly

let me know how it goes!

SnailMango, 2022-10-26:
Sorry for the super old reply but I just logged back into Github and realized I forgot to reply! However it really looks that reseating the ribbon cable fiexd the screen text problem! Thanks!

Closed 2022-10-26.

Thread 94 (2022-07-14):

Closing duckypad config while saving causes partial shortcut loss

fechu, 2022-07-14:
Hi all,

I just had the case where I was saving scripts to the duckypad via duckypad config. I thought I had moved my focus to the browser where I wanted to close the current tab with CMD+W. That closed duckypad config. After opening again and loading the config part of the scripts are missing now.

Suggested solution:
Show confirmation dialog when closing duckypad config if a saving operation is running.

@dekuNukem If you think this is a good improvement I'm happy to dig into the code and implement it. What do you think?

null0byte, 2022-07-15:
+1 up vote for this fix. I closed the Config app forgetting it was saving and lost some minor changes. No massive issue but good UI fix if implemented.

dekuNukem, 2022-11-23:
added in the latest update

Closed 2022-11-23.

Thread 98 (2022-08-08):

Duckypad OLED went out suddenly (FW 0.20.1)

Kaos9111, 2022-08-08:
I had a strange problem today:

While I was changing the profile several times (minus button), the display suddenly went off. the buttons still worked (plus, minus and the macro buttons).

I had restarted the duckypad several times using the reset button and the usb cable. - without success

I then checked the display cable. I also unplugged it and plugged it back in. - without success

I then flashed the frmware 0.20.1 again. without success

I thought the ducky pad was broken :(

So I flashed the firmware 0.20.0 and the display suddenly went back on. after the update to 0.20.1 everything is ok.

I have tried several times to reproduce the error, I have not succeeded.

dekuNukem, 2022-11-23:
The OLED ribbon cable sometimes gets loose, re-seating it usually fix the problem. No need to do anything if it is working though!

Closed 2022-11-23.

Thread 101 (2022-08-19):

DEFAULTCHARDELAYFUZZ doesn't run correctly on duckyPad configurator v0.13.3 (Windows)

conceptual-perception, 2022-08-19:
Trying this script:

```
DEFAULTCHARDELAYFUZZ 1000
STRING Stuff I want to type
```

Testing it with "Run This script!" the inter-character-delay isn't modified.

conceptual-perception, 2022-08-19:
Looks like this isn't implemented.

https://github.com/dekuNukem/duckyPad/search?q=defaultchardelayfuzz

```
pc_software/autogui.py

DEFAULTDELAYFUZZ = "DEFAULTDELAYFUZZ ";
DEFAULTCHARDELAYFUZZ = "DEFAULTCHARDELAYFUZZ ";

ignored_but_valid_commands = ["UARTPRINT ", "LCR", DEFAULTDELAYFUZZ, DEFAULTCHARDELAYFUZZ, cmd_HOLD, cmd_REM, "SWCOLOR_", "SWCOLOR ", 'DP_SLEEP', 'PREV_PROFILE', 'NEXT_PROFILE', 'GOTO_PROFILE ']
```

Closed 2022-11-23.

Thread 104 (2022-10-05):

Middle key not working after profile switch

EthanDarling8, 2022-10-05:
- Issue:
    - After switching between my two profiles the middle key quits working completely.
    - No other key has this issue, only the middle key (3rd row from the top and 2nd column from the left).
    - Currently the hotkey is ALT KP_7. Usually when using a numpad hotkey with duckypad it will type a symbol into any text input. I noticed that when the issue happens no symbol is typed; other keys that use numpad hotkeys will type a symbol.
- What I have tried:
    - Changing the hotkey that that middle key runs.
    - Checking that the key is seated correctly and the pins are not bent.
    - Switching profiles manually and switching profiles using auto switcher. Both have the same results.
    - Adding delay in various ways.
    - Updating to the latest firmware, updating the duckypad config application, and updating the duckypad auto profile switcher.
- What seems to fix it:
    - Not using the middle key. This is obviously not a good fix.
    - After switching profiles and seeing that the middle key is not working if the reset button is pressed (the 2nd button down on the right side of the duckypad) the middle key starts working again. This is not a good fix because the reset button has to be pressed every time a profile is switched.

Any help is appreciated, let me know if you need more information.

dekuNukem, 2022-10-05:
Hi there! That's a rather strange behaviour, since the middle key works on the first try, I think there’s nothing wrong with the hardware.

I would suggest reformat the SD card and copy the files back. If you have a spare SD card try using it just to make sure.

[See this guide](https://github.com/dekuNukem/duckyPad/blob/master/troubleshooting.md#i-want-to-use-my-own-sd-card) for steps. "I want to use my own SD card!" Section.

Let me know how it goes!

spants, 2022-10-14:
i had a middle key problem but noticed that one contact leg on the key was shorter than the other. I must have broken when installed. I soldered a short wire on that leg and it works again!

EthanDarling8, 2022-10-14:
Thanks for the help. I tried reformatting the SD card and also tried using a different SD card. Still getting the same behaviour. It's definitely not hardware related, even put in a different switch to test that. Maybe getting rid of the profile and making a new one will fix it. I will try that.

dekuNukem, 2022-10-14:
Actually, you can also try going back to an eariler firmware, maybe it was a bug in the new firmware.

The instructions are below, scroll down and use the 0.19.8 version.

https://github.com/dekuNukem/duckyPad/blob/master/firmware_updates_and_version_history.md

EthanDarling8, 2022-10-14:
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

I'll give that a shot as well.

EthanDarling8, 2022-10-21:
Downgrading to 0.19.8 fixed the issue. I'll try upgrading to 0.20.1 just to verify that it is the new firmware but it seems to be fixed now.

dekuNukem, 2022-10-28:
I was able to reproduce the bug, and it was (hopefully) fixed in the latest firmware.

EthanDarling8, 2022-10-30:
> I was able to reproduce the bug, and it was (hopefully) fixed in the latest firmware (0.20.2).
>
> Try it out here: https://github.com/dekuNukem/duckyPad/blob/master/firmware_updates_and_version_history.md

Awesome, thanks! I'll give it a go and let you know if it works.

EthanDarling8, 2022-10-31:
Looks like the 0.20.2 release fixed it. Thanks!

Closed 2022-10-31.

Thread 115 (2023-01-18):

Duckypad not working on Windows 11 - RESOLVED - seems to be an AMD issue, try EVERY USB port.

V22rook, 2023-01-18:
I recently purchased a Duckypad and have it working on a computer with Windows 10. However, when I connect it to a computer running Windows 11, it doesn't power on. It will occasionally flash "Please insert SD CARD", even though the card is fully seated. If I plug it back into the Windows 10 computer, it works immediately. Can anyone provide any advice?

V22rook, 2023-01-18:
Additional Information: While restarting the Windows 11 computer, the duckypad came alive (all profiles, switches glowing, etc), but as soon as Windows 11 booted up, the duckypad went dark again. So it's not an issue with the pad or USB port... it's definitely something with Windows 11.

V22rook, 2023-01-18:
Post by amck1nnon helped resolve the issue. https://github.com/dekuNukem/duckyPad/issues/66

My computer with Windows 11 is a Corsair One with an AMD chipset, a Ryzen 9 5950X.

I had already tried plugging the duckypad into all of the front USB ports, and the rear upper USB 3.0 and USB-C 3.2 ports. No joy. After reading amck1nnon's post I tried the other USB ports on the back. I don't know why but it worked- the duckypad came to life. The computer didn't seem to be loading any drivers, but I left it a lone for a few minutes. After giving it some time, I unplugged it, and swapped it to the other USB ports, which now all work fine. No problems recognizing the pad.

Everything seems to be working fine now

Closed 2023-01-18.

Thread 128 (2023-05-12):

Issue Updating to Firmware 1.2.0

nokternlix, 2023-05-12:
I downloaded the latest firmware version 1.2.0 from github and followed the instructions on how to update. I put the duckypad into DFU Mode. I used the command dfu-util --device ,0483:df11 -a 0 -D /path/to/duckypad_firmware.dfu (changing the path of course) and it went through fine. No errors parsing the file and dfu-util said everything completed successfully. I unplugged the USB-C cable and plugged it back in to reboot the device. The keypad lit up and it showed my profiles. i could even cycle through the profiles and the screen changed appropriately along with the colors of the keypad. the problem was, none of the script files that were bound to the keys actually executed. There were no errors, just nothing happened. I verified that dfu-util could see my duckpad. It showed the same usb device id that is listed in the update command.

This happened both times i tried to update the firmware on my duckpad

I'm running Linux Mint 21.1 with all the updates dfu-util version 0.9-1.

dekuNukem, 2023-05-12:
hi there! this major update changed how script is executed, so you need to use the latest configurator to load and then save again. then it should work!

you can find it here: https://github.com/dekuNukem/duckyPad/releases/tag/1.3.0

nokternlix, 2023-05-12:
welp, i feel pretty dumb. i guess i was too impatient to let the configurator detect the duckypad as it didn't appear to be doing anything and i couldn't click on the 'connect' button at the time. i apologize for bothering you with my stupidity. thank you for your  quick response though, i really appreciate your help.

dekuNukem, 2023-05-12:
no problem! glad it's sorted out!

lukasgierth, 2023-07-03:
I was just updating my duckypad and am running into the same problem. Is there a way to resave the script without the configurator app? I'm using Fedora Silverblue and using the configurator is not really an easy option, i'm doing all configuration by hand in the text files. So what exactly needs to be done?
@dekuNukem

dekuNukem, 2023-07-06:
Hi there! Duckyscript 3 introduced a lot of advanced features such as variables and flow control statements, so with the new update, the scripts are now now compiled into a binary file to be executed on a virtual machine on duckyPad itself.

First of all, if you don't need the new features, you can always go back to [0.21.0](https://github.com/dekuNukem/duckyPad/blob/master/firmware_updates_and_version_history.md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), and everything would be like before.

However, if you do want to use the new features, you'll need to compile the scripts into `.dsb` files and include them along with the original `.txt` files. The [instructions are here](https://github.com/dekuNukem/duckyPad/blob/master/duckyscript3_bytecode_vm.md), and you can take a look at the [sample profiles](https://github.com/dekuNukem/duckyPad/raw/master/sample_profiles.zip) as an example.

That does mean you'll need to execute a python script though. If it's not possible on your distro, then you would need to use a different comptuer.

lukasgierth, 2023-07-07:
Thanks for your answer! I see, ok.
Then i will for now keep using the old version without DS3 support and maybe upgrade later when i want to use the newer functions (and compile the dsb files manually).

Yeah,  it's not that convenient to run the python configurator in Silverblue. Fedora Silverblue has an immutable root filesystem so i either need to overlay the needed extra python modules or install them locally with pip. And tkinter is the culprit here since the version installed with pip doesnt work as intended and i dont want to overlay it only for the configurator to configure my stuff once ;) But the manual dsb file creation works for me just fine.

Closed 2023-05-12.

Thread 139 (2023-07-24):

Ducky stopped working?

dekiblue, 2023-07-24:
Hi,
After being disconnected for a few months my Ducky stopped working but weirdly, it light up, the LED display shows all the text I configured but whichever key I press nothing happens.
It's updated to latest firmware 1.30 and when I connect it to latest configurator I have to configure it via micro SD card, it does not see the device.
I tried it on 2 other PC's and it's the same,
What can I do?

EDIT: I tried other USB cables, various ports and computers. I only haven't changed the micro SD card

dekiblue, 2023-07-24:
Solved... well have 3 USB-C cables that DuckyPad does not like. With the 4th cable all is good.

Closed 2023-07-24.

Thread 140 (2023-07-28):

Converting to wireless

rafcio39, 2023-07-28:
is it possible to convert it to wireless control? adding a battery and the ability to charge it?

mpieper, 2023-08-24:
This details just the basics to get a wireless solution

https://www.youtube.com/watch?v=o-wbPVkkyWg

To actually fork the project over to wireless would involve a uC port to a different stm-chip w/ bluetooth, some reconsiderations over battery consumption / display selection, adding lipo-charging circuitry and some semblance of short circuit protection / fire mitigation, redoing the casing / enclosure, and then firmware changes for pairing / interfacing with the bluetooth module.  That's a good (squints, licks thumb and holds it at contractor's arms length) 3 months worth of work if you know what you're doing.  A veritable purgatory if you don't.

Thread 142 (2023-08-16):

No keys working on my duckypad

IcyPenguinCube, 2023-08-16:
I updated the firmware to version 1.3.0, and the app on my computer to version 1.4.0, and my duckypad no longer functions when i press a key. If i change it to a firmware that is 0.9.0 or older, it works, but a lot of the keys give error messages that did not used to.

dekuNukem, 2023-08-16:
Hi there! Use the latest firmware and configurator, load up the profiles in the configurator, then click `Save` to write it back.

It will write some new files to duckyPad and make it work again!

IcyPenguinCube, 2023-08-16:
I am currently using the newest of both, and clicking save crashes the configurator. Thanks

dekuNukem, 2023-08-16:
does it print out debug messages in the terminal window when it crashes?

IcyPenguinCube, 2023-08-16:
it says "first pass OK!
second pass OK!" but then stops

IcyPenguinCube, 2023-08-16:
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
Here are the images of the configurator and terminal windows.

dekuNukem, 2023-08-16:
hmm that's strange, looks like it completely hangs. it's 5am in UK right now, so I'll be going to bed soon and get back to it later today.

In the meantime, maybe you can try making a backup by copying everything off the SD card, and format it in FAT/FAT32, and start fresh, see if it works that way.

IcyPenguinCube, 2023-08-16:
ok, thanks. I will try that and let you know if it works.

IcyPenguinCube, 2023-08-16:
I backed up all of the files, wiped the drive, added them back with a FAT format, and the keys on my duckypad still do nothing.

IcyPenguinCube, 2023-08-16:
clicking the save button gives the same result in the configurator. I tried using the FAT32 format, and nothing happens. I am still able to cycle through the different profiles, but the animations are gone, and pressing a key does nothing.

dekuNukem, 2023-08-16:
i meant making a backup, format the card, don't copy anything back and start fresh. See if the configurator works this way.

IcyPenguinCube, 2023-08-17:
it works after i did that. I will add all of my profiles back. Thanks!

IcyPenguinCube, 2023-08-17:
I copied and pasted a profile from the old backup, then it stopped working again. I wiped the SD card and formatted it again, but now the configurator crashes whenever i click connect, and leaves nothing in the terminal.

dekuNukem, 2023-08-17:
Are you using AMD motherboard by any chance? they have rather buggy USB chipsets.

If so, try using a USB hub, or try a few different USB ports. Also maybe try a different cable or a different comptuer as well with the empty SD card.

IcyPenguinCube, 2023-08-17:
My laptop has an Intel chip, so i dont think so. I have tried using it on another computer and with a different cable and i get the exact same results.

dekuNukem, 2023-08-17:
in that case the final possiblity is that the SD card might have corrupted. if you have a spare micro SD card, try format it the same way and see if it works.

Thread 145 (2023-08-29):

Add Multiple key support back in EMUK (or reviving the HOLD)

jupiterbjy, 2023-08-29:
## Suggestion

Either of this suggestions would make my duckypad usable again, or I might need to downgrade firmware (hope it works!)

1. Add back `HOLD`'s 2 (or more the better) key support in `EMUK`
    - Might break compatibility?

3. Allow use of multiple `EMUK` lines in single button

5. Revive deleted `HOLD`

---

## Encountering issue

I was delaying update of firmware and just recently updated, and found out `HOLD SHIFT SPACE` is now `EMUK SHIFT SPACE` and syntax is no longer valid.

Previously `HOLD` command could held up to 2 keys:
https://github.com/dekuNukem/duckyPad/blob/a2531bf4b8fe2d8dca877a265897d728ad84f521/duckyscript_info.md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

Now, since `EMUK` don't support this and even worse there can't be 2 `EMUK` in a button, I have no way of setting `Shift` + `Space` hold down hotkey for arbitrary canvas rotation action, which looks like this:

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

One could edit the hotkey in software they use but there's some softwares that does not allow this - and it doesn't sounds right to rely on AutoHotkey to reassign it just to make it reassigned on duckypad.

---

## Attempted workaround

Since now Variables are added, I tried using variable & loop:
```
KEYDOWN SHIFT
KEYDOWN SPACE

WHILE $_READKEY != 0
    DELAY 50
END_WHILE

KEYUP SHIFT
KEYUP SPACE
```

Which actually does not work, as issue indicated on #144 I can't maintain the loop.

jesusfchavarro, 2024-09-13:
a little late but you can assign a button to do:
```
KEYDOWN SHIFT
KEYDOWN SPACE
```
and other to do
```
KEYUP SHIFT
KEYUP SPACE
```

jupiterbjy, 2024-09-14:
@jesusfchavarro sadly but surely that isn't an option.

Try using shift key like that in everyday use, using one key as press and other key as unpress or making it as toggle button - it will be fairly obvious you can't unconsciously use it. This hotkey, is just as frequent, short bursted thing that should only work during pressed.

dividium, 2024-09-17:
I second this. In my case I would like to use PowerToy's Push-to-talk and it requires (in my config) WINDOWS SHIFT Z.

I've tried this:
```
KEYDOWN WINDOWS
KEYDOWN SHIFT
KEYDOWN Z
EMUK Z
KEYUP Z
KEYUP SHIFT
KEYUP WINDOWS
```
But the commands beyond the EMUK do not run. After the first press (that behaves correctly), subsequent presses treat is as just Z.

I also tried using a WHILE loop, but it seems as though the script repeats anyways if the key is held down.

A nice flexible approach would be the ability to switch to running one script on KEYDOWN and another on KEYUP. That method would afford a lot of flexibility and might be easier to implement? Might also need the ability to disable key repeat.

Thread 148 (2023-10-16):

Release 1.6.1 does not support macOS ARM

noinfo, 2023-10-16:
The latest release shows "INTEL" and "x86" for macOS architectures. That should be the same and "ARM" is missing...

...or it is just named wrong.

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

dekuNukem, 2023-10-17:
good catch! I have changed the name

Closed 2023-12-06.

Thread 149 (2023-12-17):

Can't connect to DuckyPad on Windows 10 - duckyPad configurator shows "Not responding" after pressing Connect button

raleighlittles, 2023-12-17:
I just assembled my duckyPad and connected it to my Windows 10 PC via the USB-c cable. The screen turns on and shows the message:

> Please Insert SD Card
> For instructions, see duckyPad.com
> FW V1.3.0

(I found this to be odd since there's already a microSD card in the device, as I installed it when I was assembling it.)

 I then downloaded duckyPad configurator v1.63 (the latest), then clicked "Connect" in the application. Nothing happens after several seconds and the window shows "Not responding". The debug log also doesn't show anything.

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

dekuNukem, 2023-12-17:
Hi there! If the screen shows "please insert SD card", then it means the SD card isn't detected.

I would suggest use the SD card reader and give the card a full format and see if it is recongised.

You can also use your own SD card if you have a spare.

For detailed steps, please take a look at `I want to use my own SD card!` section of this guide:

https://github.com/dekuNukem/duckyPad/blob/master/troubleshooting.md#i-want-to-use-my-own-sd-card

raleighlittles, 2023-12-17:
@dekuNukem Thank you for the quick response, I'll try formatting the SD card and then re-running the steps.

Also just a heads up, there is a small issue with the Linux installation script, it looks like the file endings were corrupted by Windows:

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

This is the error I got when I tried to run the script on Linux.

> zsh: ./linux_install.sh: bad interpreter: /bin/bash^M: no such file or directory

After running `dos2unix` on the file, it was fixed.

raleighlittles, 2023-12-17:
@dekuNukem Formatting the SD card worked, so I'll close the issue now, thank you!

Closed 2023-12-17.

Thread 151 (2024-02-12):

Duckypad won't connect

harkfujow, 2024-02-12:
My Duckypad has stopped working. The screen says "Please insert SD Card" and the firmware is V1.3.0. I have the exact same issue as in [#149 ](https://github.com/dekuNukem/duckyPad/issues/149l). I think the SD card is dead. I tried reformatting it, but it failed in Windows and it's detected at all in Linux.  Replacing it with a new, and freshly formatted card didn't work. On Linux (Manjaro), it might as well not be connected. On Windows 10, the card is detected in the configuration app, but the Duckypad itself remains inaccessible. I've replaced the cable and also connected the Duckpad directly to the Linux PC and the Windows PC. No dice. I'm now at a loss as to how to proceed.

dekuNukem, 2024-02-12:
Sorry to hear about the issue, is the duckypad not recognising the new SD card? What does the screen say with the new card inserted?

harkfujow, 2024-02-12:
It says the same thing as if the old card or no card was inserted: "Please insert SD Card. For instructions, see duckyPad.com. FW V1.3.0"

dekuNukem, 2024-02-12:
Make sure it is formatted in FAT32, see the "I want to use my own SD card" section here: https://github.com/dekuNukem/duckyPad/blob/master/troubleshooting.md#i-want-to-use-my-own-sd-card

duckypad might be a bit picky as well, try a few different card if you have some.

let me know how it goes!

harkfujow, 2024-02-12:
Well, I can't format the spare card. There are two partitions on the 128GB card. My options are NTFS and exFAT on the larger partition and FAT16 on the smaller one. Looks like I'm buying a new card.

harkfujow, 2024-02-13:
So, nothing is working. I tried manually re-flashing the firmware. I was able to do so. Unfortunately, it made no difference. The duckypad is still stuck on "Please Insert SD Card." I'm at a loss and thinking the duckypad is irreparably broken.

dekuNukem, 2024-02-13:
I would suggest try a few different SD cards first, lower capacity (under 32GB), one partition in FAT/FAT32. If that doesn't work, I'm happy to send you a new circuit board for free!

harkfujow, 2024-02-13:
Unfortunately, I have only one spare 32GB card, and that is the original card from my pi-hole. I kept it as backup in case my pi-hole SSD bites the dust. The card that came with the duckypad appears to be dead. It doesn't show up when I plug the adaptors (I have a few) into the PC. My other spare cards are 128GB+. Looks like I'm headed to Amazon for lower capacity cards.

dekuNukem, 2024-02-13:
sure, go for 8 or 16gb if its not too expensive. if that works i can reimburse you the cost. if still doesn’t work, i can send you a new circuit board.

harkfujow, 2024-02-20:
No luck. I tried multiple SD cards to no avail. I think it's dead.

dekuNukem, 2024-02-20:
well, I can send you a new PCB then! Let me know your tindie order number. Same address as last time?

harkfujow, 2024-02-20:
It was order #421914. No change to my address. Thanks!

dekuNukem, 2024-02-20:
I'll send it out later today!

harkfujow, 2024-02-20:
Thanks!

harkfujow, 2024-02-28:
I received the new board and everything seems to be working. I copied one of my backups onto the SD card and we're good to go. I will say that the LEDs seem brighter.

Thanks for all of your help.

Closed 2024-02-28.

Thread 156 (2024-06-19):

PC does not see duckypad as an input device.

poonmelissa, 2024-06-19:
Hi, I was trying to use Duckypad on my new Laptop and it only sees Duckypad as other devices, not an input device.
Under device manager, Duckypad is under Universal Serial Bus Devices, can not find STM32 Bootloader.

Not sure what is missing for the Duckpad to work.
Please help.

Thanks
Melissa

dekuNukem, 2024-06-19:
Hi Melissa! Does it work on other PCs? Try a few different ports and cables. Also does the RGB backlight change when you press a key?

poonmelissa, 2024-06-19:
I have not been updating the firmware since I brought it years ago, V0 19 1
Tried to update but not successful with DfuSe , STM32 ....
I followed what was on your post but not successful

dekuNukem, 2024-06-19:
i do think it's a good idea to update it to the latest firmware. the guide is here:

https://github.com/dekuNukem/duckyPad/blob/master/firmware_updates_and_version_history.md

When you plug it in DFU mode, the light and screen should stay off, is that the case?

if so, what shows up in the device manager?

poonmelissa, 2024-06-19:
Not showing up on the Device Manager.

poonmelissa, 2024-06-19:
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

poonmelissa, 2024-06-19:
I have a USB Card reader for the SD card, Can you send me updated files and I tried to upload to the card and  let me know what am I missing on my laptop to it to recognise the duckypad as an input device,
I am not sure if I messed up anything when I tried to use DfuSE Demo to update firmware and it got frozen not responding and I had to restart to get out of that.

dekuNukem, 2024-06-19:
it does show up, so that means it is working.

Here are the sample profiles:

https://github.com/dekuNukem/duckyPad/raw/master/sample_profiles.zip?raw=1

mount the SD card on PC, copy files off if you want, do a format in FAT32, unzip and copy the sample profiles to the card, see if it works better.

if Dfuse demo doesn't work on your laptop, maybe try a different computer if possible, also make sure to enter DFU mode properly, the screen and RGB LED should be off.

poonmelissa, 2024-06-20:
did all that and was sure it si in DFU Mode, led is off. After hitting upgrade the operation duration started to count but no movement on the progress bar

dekuNukem, 2024-06-20:
ah, I've heard that before, usually happens with AMD motherboards.

Try plug it in through a cheap USB hub, that usually fixes it.

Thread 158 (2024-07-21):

Duckypad worked two years ago - but no longer

dabrams, 2024-07-21:
I last used my Duckypad in 2022.  I hooked it up again today and it just displays "Please insert SD card..."  My USB manager shows it as USB device but neither the 0.13.3 or 1.6.3 configurator can connect.  I tired to flash the firmware - it goes into STM Bootloader mode just fine - but the "Available DFU Devices" dropdown is empty.  Windows says I have the latest driver.  I have tried three different USB ports and three different USB cables.  I also rewrote the SD card from my last good back up and also tried rewriting the SD card with the original data.  Not sure what to try next?

David
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

dekuNukem, 2024-07-21:
there has been a lot of updates since 2022, so it is a good idea to update to the latest firmware!

Have you tried reinstalling the driver? Take a look at this guide: https://github.com/dekuNukem/daytripper/blob/master/dfu_driver_install.md

dabrams, 2024-07-22:
> Have you tried reinstalling the driver? Take a look at this guide: https://github.com/dekuNukem/daytripper/blob/master/dfu_driver_install.md

Yes, I removed the driver and reinstalled it as well.

dabrams, 2024-07-22:
Ok, I was able to update the firmware to 1.3.0 but still not able to get it working. The duckyPad is seen as a USB Input Device by Windows so it is there.

I tried a different micro SD card but that made no difference.  It acts as though it cannot see the SD card and just sits there with the "Insert SD Card" message. The configuration utility (V1.6.3) never connects (it doesn't time out but the connect button stays down and nothing happens) but if I remove the SD card it pops up a "duckyPad not found" error dialog" so the board is aware when the SD card is removed.  My computer gives a USB dis/connect beep when I remove the SD card as well.

Anything else I can try?

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

dekuNukem, 2024-07-22:
that's good progress! Take a look at the `I want to use my own SD card` section of this guide: https://github.com/dekuNukem/duckyPad/blob/master/troubleshooting.md#i-want-to-use-my-own-sd-card

Maybe try a few different card too! Let me know how it goes

dabrams, 2024-07-23:
I have tried several SD cards with no luck.  Does the error message mean the software does not detect an SD card or that the card does not have the correct files on it/cannot read them ?

dekuNukem, 2024-07-23:
that message means the firmware can't detect a valid SD card. A different message is shown if it detects the card but the card is empty.

i would suggest try some smaller capacity cards (under 16GB), and make sure they are formatted in FAT32.

Also try it on a different PC if possible, some AMD motherboards have USB compatibility issues.

Maybe also clean out the slot with some compressed air, something might have gotten inside.

If nothing works, then it might be a hardware issue, and I'm happy to send you a new PCB!

dabrams, 2024-07-24:
Thanks.   I cleaned the SD slot with contact cleaner a few days ago and I just blew it out with compressed air with no change.  It does not seem to be PC motherboard related, since it occurs also when plugged into a USB C power adapter.  (I also tried it with my surface which is an Intel microprocessor.)  I will try to find a smaller SD card (everything I have tried so far is 32g or larger - but they are formatted w/ FAT32) and let you know how it goes.

dabrams, 2024-07-24:
Thanks. I cleaned the SD slot with contact cleaner a few days ago and I just blew it out with compressed air with no change. (I looked in SD slot with a light and magnifier and the contacts look clear.) It does not seem to be PC motherboard related, since it occurs also when plugged into a USB C power adapter.

I found a 2Gig microSD, formatted it for FAT32 and copied the sample_profiles to it, then tried it in my Surface which has a Intel i7 processor.  Still shows the “Insert SD” message and the config utility cannot connect to it. I also reflashed the firmware with verify checked just to be sure.

Happy to pay for a new PCB, I just would prefer not to buy a whole kit again.

Just so you know, the reset button is broken but I checked and the pullup on the reset side (NRST) is at 3.3V (and I would assume the error message would not display if reset was asserted).

David

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

dekuNukem, 2024-07-24:
Looks like a hardware issue then!

I'm happy to send you a new PCB for free, no need to pay! Let me know your Tindie order number so I can look it up.

dabrams, 2024-07-24:
Well, that doesn’t seem fair.  I bought it more than two years ago. I should pay something.

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

dekuNukem, 2024-07-25:
don't worry about it! it's my hobby project so I dont have to nickel and dime the customers! let me know the order number and I'll send you a new PCB!

dabrams, 2024-07-26:
#304973 <https://www.tindie.com/orders/purchases/304973/>

04 Jan 2022

DuckyPad: Do-It-All Mechanical Macropad <https://www.tindie.com/products/dekunukem/duckypad-do-it-all-mechanical-macropad/>

Review Now <https://www.tindie.com/reviews/create/dekunukem/duckypad-do-it-all-mechanical-macropad/>

Shipped
2022/01/06
Royal Mail (No Tracking)

$98.96

Ok, Thanks.

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

dekuNukem, 2024-07-26:
I have dropped it off! It should arrive in the usual time!

dabrams, 2024-07-26:
Thanks – do you want the  old one back?

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

Closed 2024-07-26.

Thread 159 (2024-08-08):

traceback error on save

msx2plus, 2024-08-08:
i'm currently having an issue with the duckypad configurator in which the first profile seems to write all of its files before throwing a catastrophic error that corrupts the SD card. i've attached a screenshot of the error since i'm not sure if there's a log saved.

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

dekuNukem, 2024-08-08:
hi there! was the pad working before or is it like this out of the box?

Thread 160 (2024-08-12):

Please Insert SD Card

fisherbt, 2024-08-12:
My DuckyPad just started showing and Error to Please Insert SD Card, but I tested the SD card on another DuckyPad on the same computer and it works fine. Trying the SD card from the other DuckyPad in the suspect DuckyPad does resolve the issue. I'm on the latest firmware 1.3.0. Is there a hard reset or anything I can do to get this working again?

dekuNukem, 2024-08-12:
Hi there! I would try giving the SD card a full format in FAT32 and copy the files back.

You can also try your own SD card if you have a spare.

See `I want to use my own SD card!` section of this guide: https://github.com/dekuNukem/duckyPad/blob/master/troubleshooting.md#i-want-to-use-my-own-sd-card

fisherbt, 2024-08-12:
Dang, okay, yep. That worked. Thanks for the help.

fisherbt, 2024-08-15:
Unfortunately, this issue is back.  I've even purchased a new SD card formatted it and added my files to it. It will work for a little while after the card has been formatted and then it will go back to saying "Please Insert SD Card" it seems like something beyond the SD card. What else can I try?

dekuNukem, 2024-08-15:
hmm thats unusual. how many times has that happened? maybe I can send you a new PCB if it keeps happening.

fisherbt, 2024-08-15:
It's been happening a couple times per day for the last few days, since I opened the original issue.

dekuNukem, 2024-08-15:
no problem, I'll send you a new PCB with some extra SD cards for free! Let me know your Tindie order number.

fisherbt, 2024-08-15:
Thanks, so much! My order number is 441920.

dekuNukem, 2024-08-15:
Got it! Same address as before?

fisherbt, 2024-08-15:
Yes, thanks. I appreciate you handling this.

dekuNukem, 2024-08-16:
I have dropped it off! it should arrive in the usual time.

fisherbt, 2024-08-16:
Thank you so much for taking care of this.

Closed 2024-08-12.

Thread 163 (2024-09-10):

Feature Request: Ability to revert to a backup version via DuckyPad Configurator

richardgaunt, 2024-09-10:
At the moment the only way to restore a backup is to connect the SD micro card to your computer and then manually copy across the backup. This is a problem for me as I don't have a SD Card reader.

I would like to know whether it would be possible to implement this via the application.

Optimally it would be great to see changes between the different versions even if that means the actual macro are stored as text strings of their actual commands rather than the number sequences they are currently (not sure what format).

dekuNukem, 2024-09-10:
A workaround is:

* Connect to duckyPad on the configurator
* Press `x` button and delete all the existing profiles
* Press `import` button, go to backup folder, and select the backup you want
* It will load it up, then you can write it back

An SD card reader should be included in the package as well, maybe see if its still there?

richardgaunt, 2024-09-11:
Nice thanks that is a great workaround appreciate it

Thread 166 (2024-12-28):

Hotkey combination from PC keyboard to change profiles

pingusix, 2024-12-28:
Hi, I've managed to snap off the buttons on my duckypad (crammed in awkwardly into a small pouch on a work trip).
Is there any way to assign a hotkey combination on my laptop keyboard to cycle through keyboard profiles? Alternatively could anyone point me at a code sample to try to knock something up? Cheers

dekuNukem, 2024-12-28:
Hi there! You can use `PREV_PROFILE` and `NEXT_PROFILE` command to cycle through profiles, assign to one of the mechanical switches and it should work just like before!

pingusix, 2024-12-28:
Thanks! I did try that but when when I moved to the next/prev profile it obviously didn't have the binding any more so I'd need to add it to all profiles which is a loss of two keys on each one which is a shame. I may have a look at the profile auto-switcher code otherwise I may just have to dust off the soldering iron and get a couple of micro-switches as a worst case.

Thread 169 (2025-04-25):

No/unstable connection with FW 2.0.0 for DP 2020

wellmeyer, 2025-04-25:
After flashing 2.0.0 onto DP 2020 it looks fine and working on the DP screen, but there are major connection problems.
Directly connected to a Windows 11 laptop the new configurator (3.1.0) found it one time and was able to load the profiles.
Also, the Autoprofile 1.0.0 works from time to time, but pressing keys on DP 2020 has no effect.

When connected via a dock nothing works. DP 2020 shows the profiles on the display, but both configurator and autoprofile don't find it and also here pressing keys has no effect.

After I flashed back to 1.3.3 everything again works as expected, directly connected and also via the same dock as above.

The DP Pro works fine with the new FW and the the new programs.

Would be great if this could be solved some when. Thank you.

dekuNukem, 2025-04-25:
that's a bit strange, the 2.0.0 firmware is bascially a total re-write with most of the code backported from the DPP, and there are a lot of differences under the hood.

Ideally you should load the profile in the latest configurator and then write it back for everything to work. maybe try it on a different PC? I hope it's not like that on every computer, it seems to work fine on my 2 PCs and 1 mac.

wellmeyer, 2025-04-27:
Hi dekuNukem,
I have an update for you after trying again, paying attention to load and save (after removing EMUKs) in configurator 3.1.0.
I've (probably) the same results as before, but now more detailed:
It works connected via USB C to USB C cable, both directly and via the dock (after switching to dock (or between TB/USB C ports on the dock), sometimes I have to press reset to get it working).
It works directly connected via USB A to USB C cable to the laptop.
It doesn't work connected via USB A to USB C cable to the dock (same cable).

Please note that I tried different USB A ports on the dock and that with FW 1.3.3 it works flawlessly with the same cable and same port and did it from the beginning. So it's definitely FW 2.0.0 that makes the difference.
BTW, DPP is working fine with same USB A to USB C cable at the same port on the dock.
It's a Lenovo TB4 dock (40B00135).

Now that DP 2020 works connected to the dock, it's less urgent, but it would be great getting back the original cable configuration eventually, just because of my personal cable and port availability.

That said, still I want to thank you for the great work that you did with both DPs!

Have a nice weekend.

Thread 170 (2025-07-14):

Issues with FW >= 2.x and new/dedicated configurator app

4ch1m, 2025-07-14:
Hi there,

I'm a happy duckyPad user for about four years now. It's an indispensable time-saver. Thanks! :+1:

In the past, all firmware (and configurator app) updates worked without a flaw.

However, with the latest update(s) my duckyPad refuses to work. :cry:

Until recently I was running FW `1.2.0` and the ["old" configurator app](https://github.com/dekuNukem/duckyPad/tree/master/resources/duckyscript%201%20fw%20and%20app/duckyscript1) from the main repo.

Once I found out that the configurator app now moved to a dedicated [repo](https://github.com/duckyPad/duckyPad-Configurator), I just gave it a try.

* I followed the provided [instructions for Linux](https://dekunukem.github.io/duckyPad-Pro/doc/linux_macos_notes.html); and successfully started the new app. :heavy_check_mark:
* A connection to the duckyPad seems to have been established; and I was informed that I had to upgrade to firmware greater/equal `2.0` in order to use the new app. ✔️
* So, as usual, I downloaded the latest firmware ([2.3.2](https://github.com/dekuNukem/duckyPad/blob/master/firmware/duckypad_v2.3.2.dfu)); and flashed it to the duckyPad. No errors. :heavy_check_mark:

After turning the duckyPad off/on the display stated that there are no profiles present.
And after closing/re-opening the new configurator app (and clicking the connect button) I just got this message on the display:

```
FATAL ERROR: 10
```

Using the "old" configurator app with the new firmware also didn't work. (It simply wouldn't connect to the duckyPad anymore.)

I've tried several things (completely wiping/initializing the sd-card, etc.).
Without success.

After downgrading the firmware to `1.3.3` and using the "old" configurator everything is working back again. :relieved:

I hope these issues with the new FW/configurator can be resolved.
Let me know if there's anything I can provide for debugging.

Thanks.

dekuNukem, 2025-07-14:
Hi there! Sorry to hear about the issue. Please try out this guide and let me know how it goes!

https://dekunukem.github.io/duckyPad/starting_fresh.html

4ch1m, 2025-07-17:
Thanks for the response.

Unfortunately the issues still remain.

I closely followed the instructions ("Starting Fresh with duckyPad (2020)"):

* unplugged the duckypad
* removed the SD card
* formatted another fresh SD card with FAT32; copied all files from `sample_profiles.zip` to it
* updated the firmware (as described to) v2.3.2
* put the SD card into the duckypad
* unplugged/replugged the duckypad

As for these steps, imho everything worked just fine.
The duckypad boots; all profiles appear on the screen and are switchable/usable.

However, the new configurator-app seems to have issues.

I'm using this (custom) `run.sh` script to directly run the app:

```
#!/bin/bash
cd "$(dirname $(realpath "${0}"))" && \
  python3 -m venv .venv && \
  source .venv/bin/activate && \
  pip install -r src/requirements.txt && \
DUCKYPAD_UI_SCALE=2 \
python src/duckypad_config.py
```

The app starts without a problem.

But once I hit the "CONNECT" button, I get this error dialog:

```
Empty HID response!

Try a different USB Port Or a USB Hub
```

The stdout shows this:

```
user selected: {'fw_version': '2.3.2', 'dp_model': 20, 'serial': '********', 'hid_path': b'1-8:1.0', 'hid_msg': [4, 0, 0, 2, 3, 2, 20, 30, 111, 40, 120, 1, 0, 0, 0, 0, 0, 0, 0, 0, 0, 0, 0, 0, 0, 0, 0, 0, 0, 0, 0, 0, 0, 0, 0, 0, 0, 0, 0, 0, 0, 0, 0, 0, 0, 0, 0, 0, 0, 0, 0, 0, 0, 0, 0, 0, 0, 0, 0, 0, 0, 0, 0, 0]}
DP20 this: (2, 3, 2)
remote: (2, 3, 2)
```

And the duckypad-screen shows this:
```
File Access Mode
```

Note:
When downgrading the firmware to < 2.x (and using the "old" configurator app) everything works again; with the same hardware-setup.

Any clues?

Can anyone confirm that the "classic duckypad" still works with FW 2.3.2 and the new configurator app **on Linux**?

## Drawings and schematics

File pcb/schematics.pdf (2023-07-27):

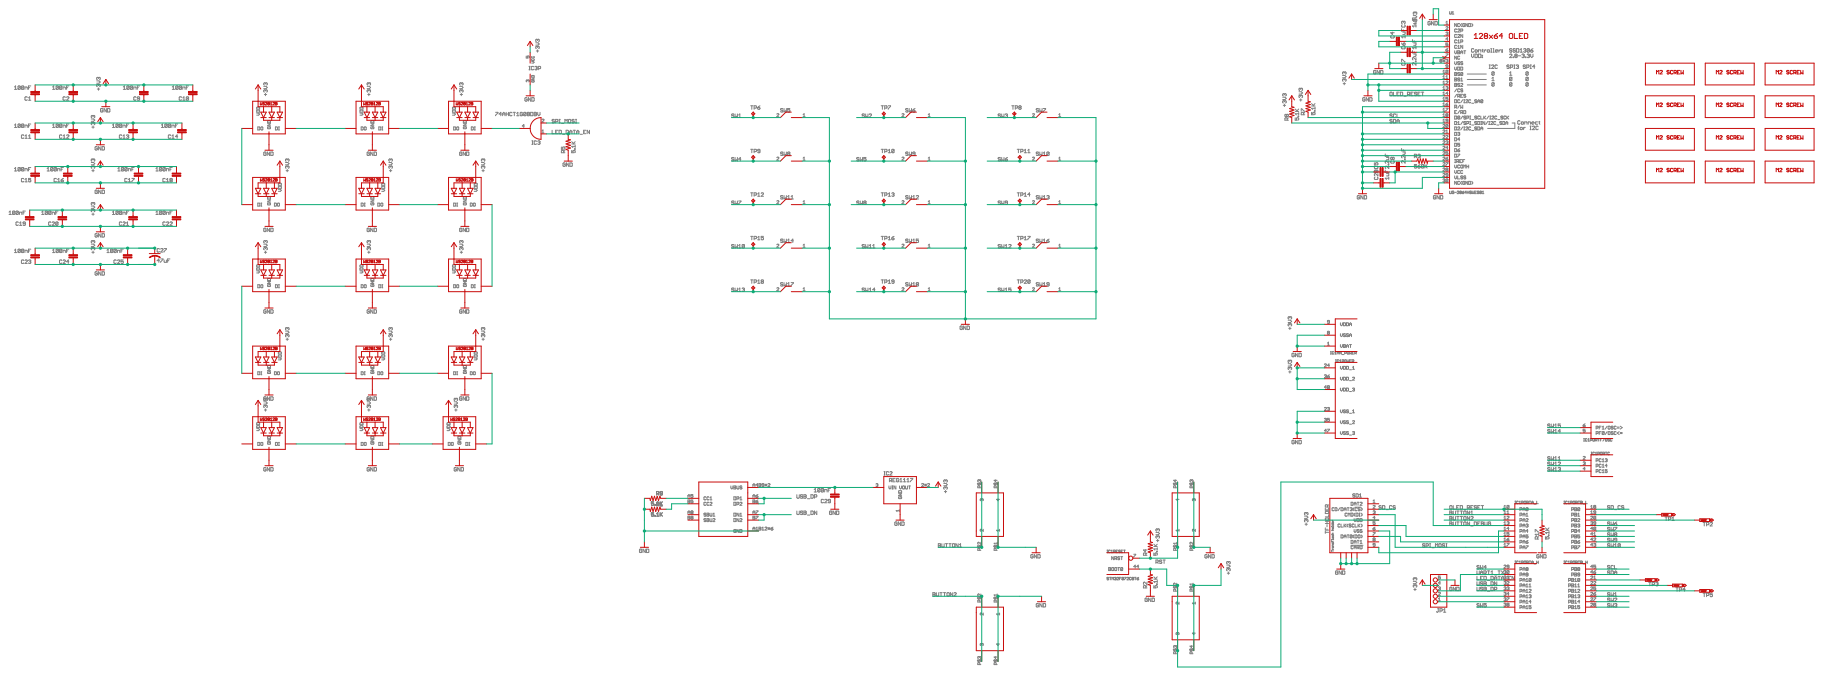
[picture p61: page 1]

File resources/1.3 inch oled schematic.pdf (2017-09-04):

# 淘宝地址：http://shop73023976.taobao.com/?spm=a1z10.1.0.0.byBTLt&v=1

# 中景园电子1.3寸OLED显示屏模块原理图

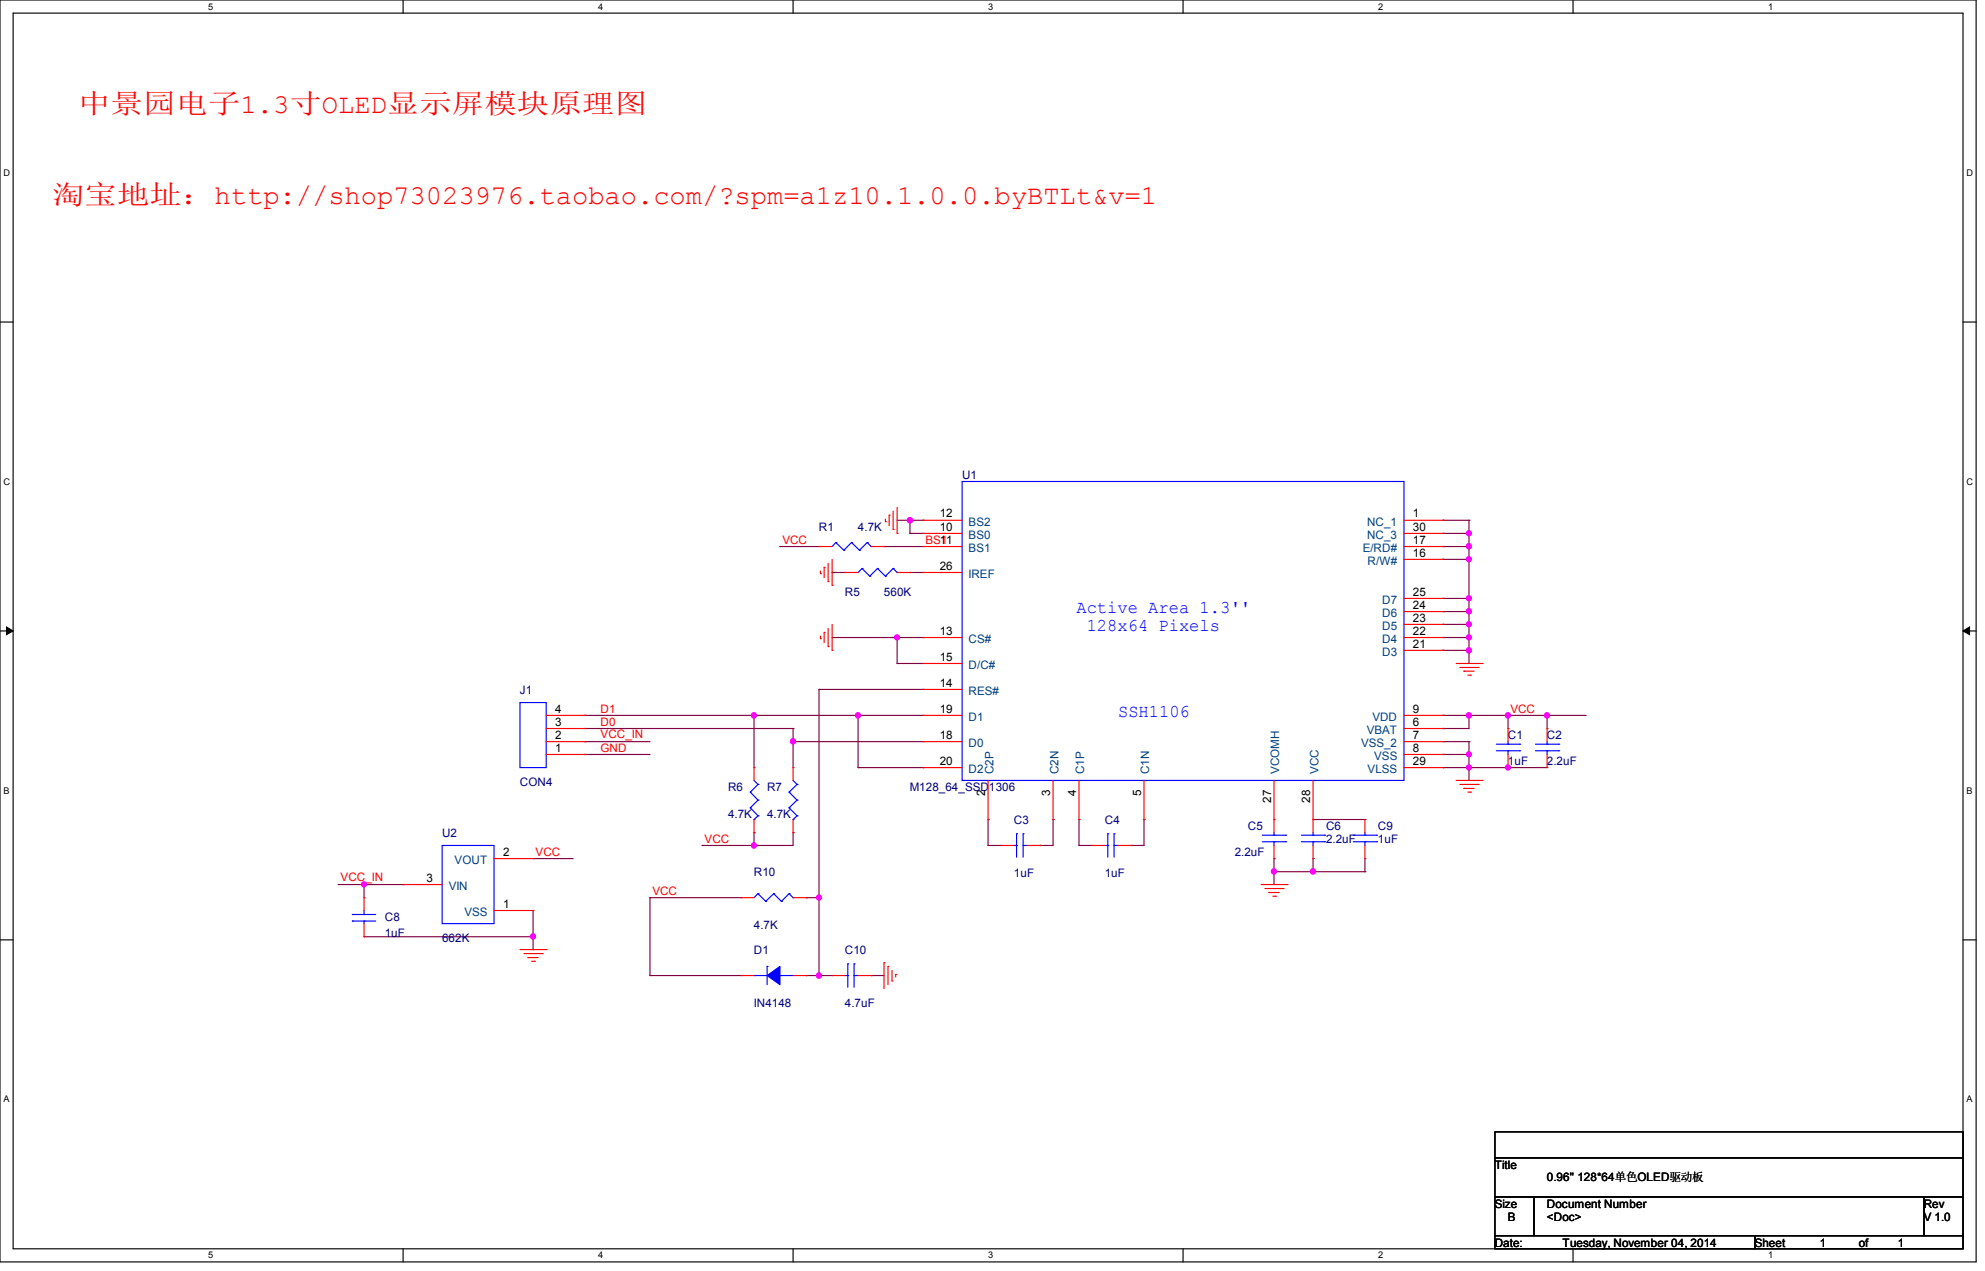
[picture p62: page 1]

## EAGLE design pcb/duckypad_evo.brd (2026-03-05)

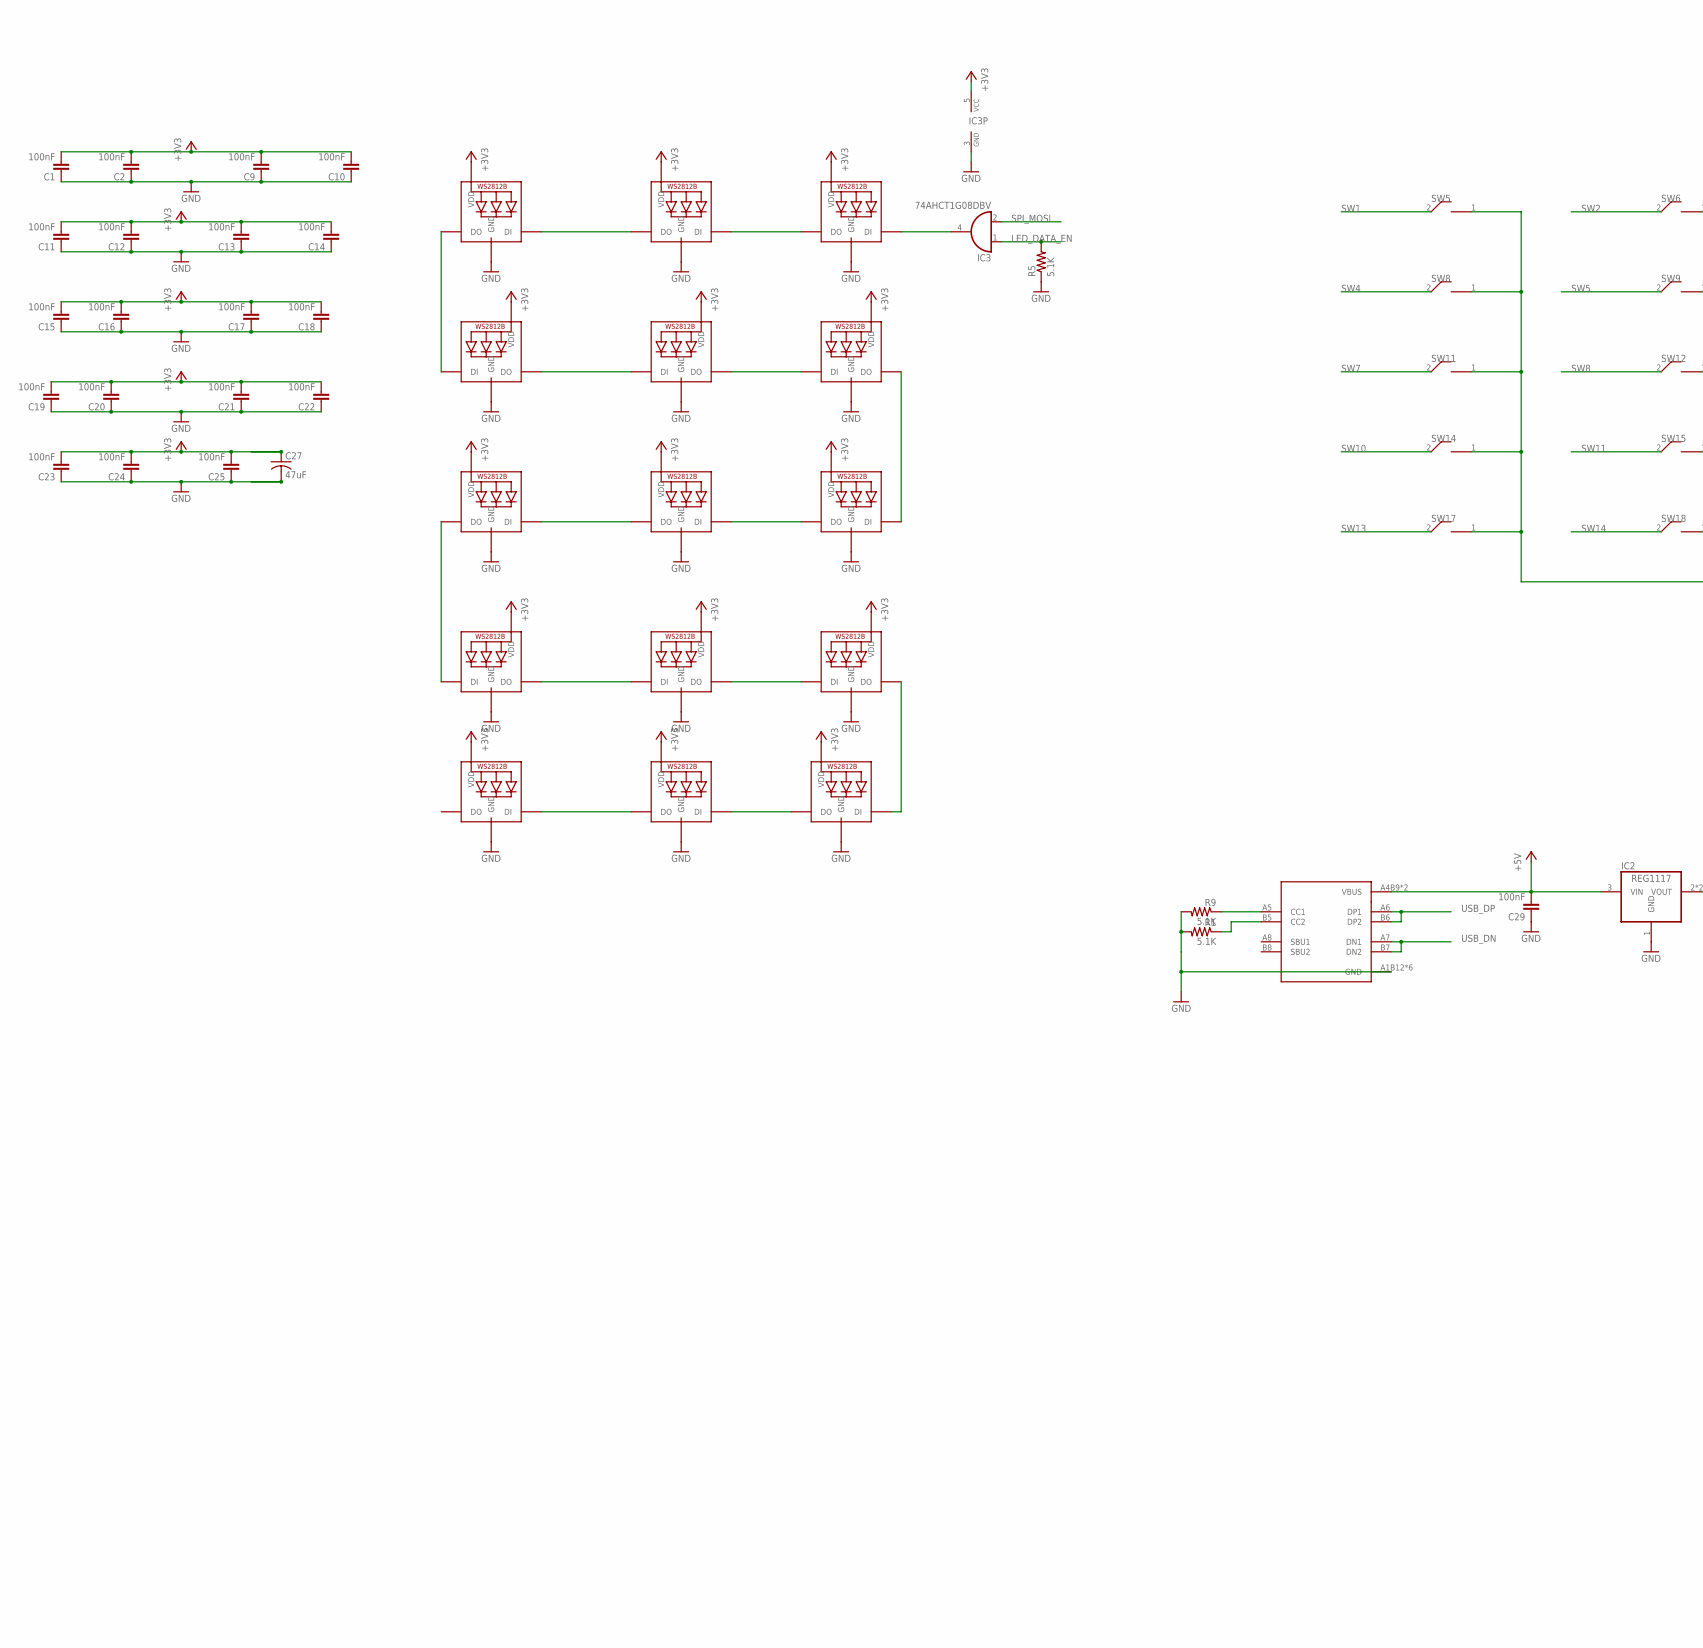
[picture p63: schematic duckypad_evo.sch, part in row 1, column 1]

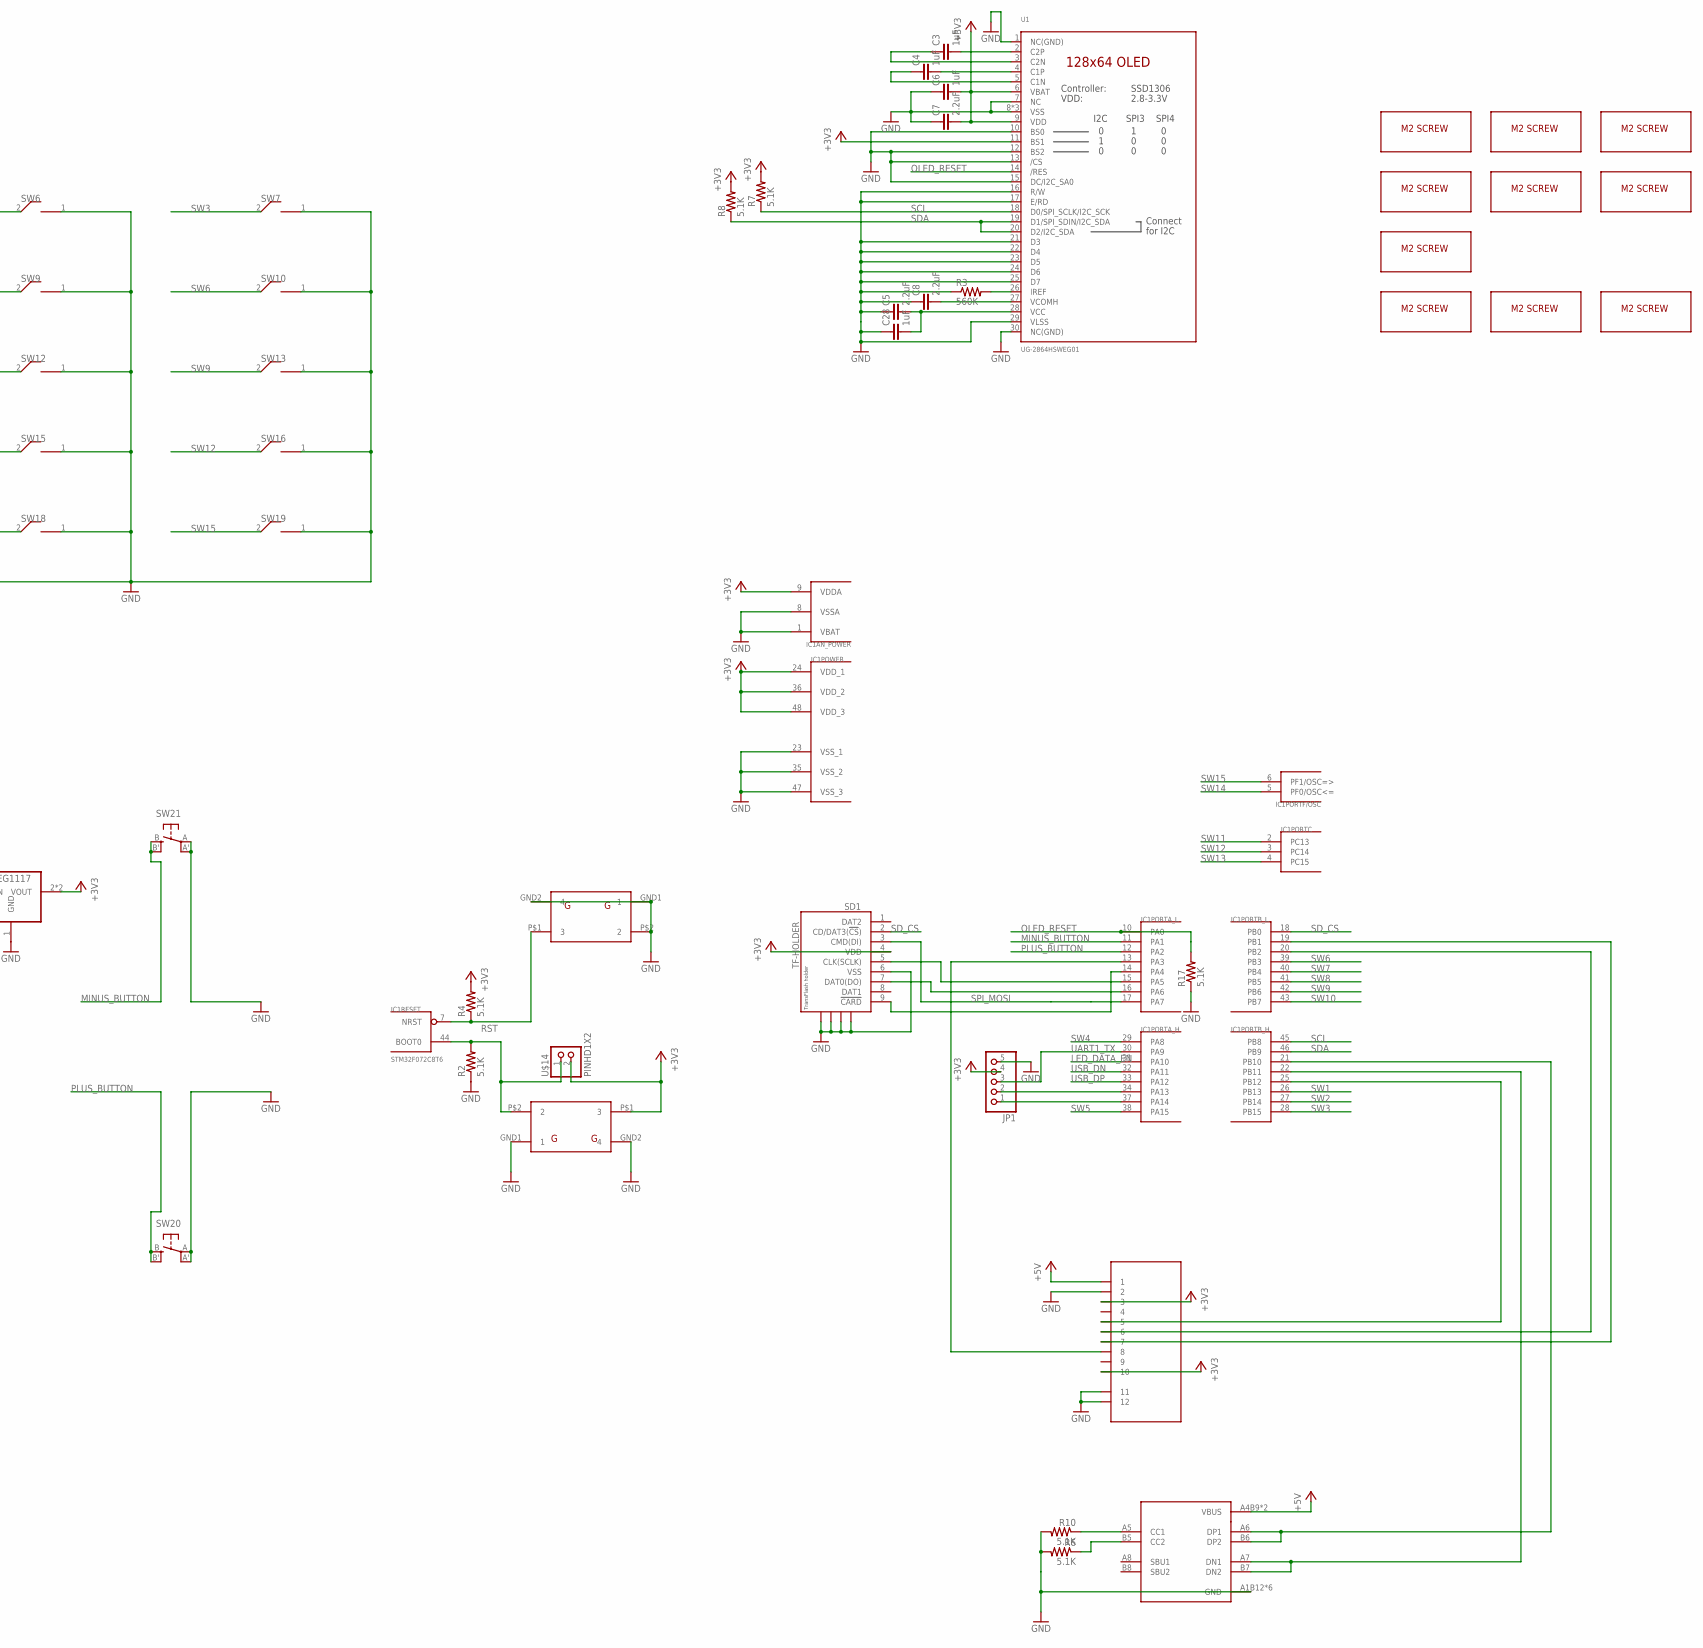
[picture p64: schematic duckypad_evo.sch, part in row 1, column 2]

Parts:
C1, C2, C9, C10, C11, C12, C13, C14, C15, C16, C17, C18, C19, C20, C21, C22, C23, C24, C25, C29: 100nF; 0805@1
C3, C4, C6, C28: 1uF; 0805@1
C5, C7, C8: 2.2uF; 0805@1
C27: 47uF; C1210
IC1: STM32F072C8T6; TQFP48
IC2: REG1117; SOT223
IC3: 74AHCT1G08DBV; SOT23-5
JP1: PINHD-1X5; 1X05
LED1, LED2, LED3, LED4, LED5, LED6, LED7, LED8, LED9, LED10, LED11, LED12, LED13, LED14, LED15: WS2812B; REVERSE_MNT
R1, R2, R4, R5, R6, R7, R8, R9, R10, R17: 5.1K; 0805
R3: 560K; 0805
SD1: TF-HOLDER; TF-PULL
SH1: SH10P; DUCKYPAD_SM12B-SSR-H-TB
SW3, SW4: 3POS_SLIDE_SWITCH_324_SW; SIDEPUSH
SW5, SW6, SW7, SW8, SW9, SW10, SW11, SW12, SW13, SW14, SW15, SW16, SW17, SW18, SW19: KAILH_SWITCH_SOCKET_KAILH_SWITCH_SOCKET; KAILH_SWITCH_SOCKET_SWITCH_SOCKET
SW20, SW21: SPST_TACT-EVQQ2; EVQ-Q2
U1: UG-2864HSWEG01; LUL_UG-2864HSWEG01_1.3_WRAPAROUND
U2, U3: USBC_16P; USBC_16P_FOOT
U$7, U$8, U$9, U$10, U$11, U$12, U$13, U$15, U$16, U$23: M2_SCREW_DEV; M2_SCREW_FOOT
U$14: PINHD1X2; 1X02

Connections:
+3V3: C1.2, C2.2, C6.2, C7.2, C9.2, C10.2, C11.2, C12.2, C13.2, C14.2, C15.2, C16.2, C17.2, C18.2, C19.2, C20.2, C21.2, C22.2, C23.2, C24.2, C25.2, C27.1, IC1.9 (VDDA), IC1.24 (VDD_1), IC1.36 (VDD_2), IC1.48 (VDD_3), IC2.2 (VOUT), IC2.4 (VOUT), IC3.5 (VCC), JP1.4, LED1.VDD, LED2.VDD, LED3.VDD, LED4.VDD, LED5.VDD, LED6.VDD, LED7.VDD, LED8.VDD, LED9.VDD, LED10.VDD, LED11.VDD, LED12.VDD, LED13.VDD, LED14.VDD, LED15.VDD, R4.2, R7.2, R8.2, SD1.4 (VDD), SH1.3, SH1.10, SW4.P$1 (3), U1.6 (VBAT), U1.9 (VDD), U1.11 (BS1), U$14.2
+5V: C29.2, IC2.3 (VIN), SH1.1, U2.A4B9 (VBUS), U2.B4A9 (VBUS), U3.A4B9 (VBUS), U3.B4A9 (VBUS)
BUTTON_DEBUG: IC1.44 (BOOT0), R2.2, SW4.P$2 (2), U$14.1
GND: C1.1, C2.1, C5.1, C6.1, C7.1, C8.1, C9.1, C10.1, C11.1, C12.1, C13.1, C14.1, C15.1, C16.1, C17.1, C18.1, C19.1, C20.1, C21.1, C22.1, C23.1, C24.1, C25.1, C27.2, C28.1, C29.1, IC1.1 (VBAT), IC1.8 (VSSA), IC1.23 (VSS_1), IC1.35 (VSS_2), IC1.47 (VSS_3), IC2.1 (GND), IC3.3 (GND), JP1.5, LED1.GND, LED2.GND, LED3.GND, LED4.GND, LED5.GND, LED6.GND, LED7.GND, LED8.GND, LED9.GND, LED10.GND, LED11.GND, LED12.GND, LED13.GND, LED14.GND, LED15.GND, R1.2, R2.1, R3.1, R5.1, R6.2, R9.2, R10.2, R17.1, SD1.6 (VSS), SD1.S1, SD1.S2, SD1.S3, SD1.S4, SH1.2, SH1.FIT@1 (11), SH1.FIT@2 (12), SW3.GND1 (1), SW3.GND2 (4), SW3.P$2 (2), SW4.GND1 (1), SW4.GND2 (4), SW5.1 (2), SW6.1 (2), SW7.1 (2), SW8.1 (2), SW9.1 (2), SW10.1 (2), SW11.1 (2), SW12.1 (2), SW13.1 (2), SW14.1 (2)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
LED_DATA_EN: IC1.31 (PA10), IC3.1 (I0), R5.2
MINUS_BUTTON: IC1.11 (PA1), SW21.B (S), SW21.B' (S1)
unnamed: R6.1, U3.B5 (CC2)
unnamed: IC1.20 (PB2), SH1.6
unnamed: R3.2, U1.26 (IREF)
unnamed: C3.2, U1.2 (C2P)
unnamed: C3.1, U1.3 (C2N)
unnamed: C4.2, U1.4 (C1P)
unnamed: C4.1, U1.5 (C1N)
unnamed: IC1.15 (PA5), SD1.5 (CLK(SCLK))
unnamed: LED2.DIN (DI), LED3.DOUT (DO)
unnamed: IC1.16 (PA6), SD1.7 (DAT0(DO))
unnamed: C5.2, C28.2, U1.28 (VCC)
unnamed: C8.2, U1.27 (VCOMH)
unnamed: IC1.19 (PB1), SH1.7
unnamed: IC1.14 (PA4), SD1.9 (!CARD)
unnamed: LED1.DIN (DI), LED2.DOUT (DO)
unnamed: IC1.22 (PB11), U3.A7 (DN1), U3.B7 (DN2)
unnamed: LED1.DOUT (DO), LED4.DIN (DI)
unnamed: LED4.DOUT (DO), LED5.DIN (DI)
unnamed: LED5.DOUT (DO), LED6.DIN (DI)
unnamed: LED6.DOUT (DO), LED9.DIN (DI)
unnamed: LED8.DIN (DI), LED9.DOUT (DO)
unnamed: LED7.DIN (DI), LED8.DOUT (DO)
unnamed: LED7.DOUT (DO), LED10.DIN (DI)
unnamed: LED10.DOUT (DO), LED11.DIN (DI)
unnamed: LED11.DOUT (DO), LED12.DIN (DI)
unnamed: LED12.DOUT (DO), LED15.DIN (DI)
unnamed: LED14.DIN (DI), LED15.DOUT (DO)
unnamed: LED13.DIN (DI), LED14.DOUT (DO)
unnamed: IC3.4 (O), LED3.DIN (DI)
unnamed: IC1.21 (PB10), U3.A6 (DP1), U3.B6 (DP2)
unnamed: R1.1, U2.B5 (CC2)
unnamed: IC1.37 (PA14), JP1.1
unnamed: R9.1, U2.A5 (CC1)
unnamed: IC1.34 (PA13), JP1.2
unnamed: IC1.25 (PB12), SH1.5
unnamed: R10.1, U3.A5 (CC1)
unnamed: IC1.13 (PA3), SH1.8
OLED_RESET: IC1.10 (PA0), R17.2, U1.14 (/RES)
PLUS_BUTTON: IC1.12 (PA2), SW20.B (S), SW20.B' (S1)
RST: IC1.7 (NRST), R4.1, SW3.P$1 (3)
SCL: IC1.45 (PB8), R7.1, U1.18 (D0/SPI_SCLK/I2C_SCK)
SDA: IC1.46 (PB9), R8.1, U1.19 (D1/SPI_SDIN/I2C_SDA), U1.20 (D2/I2C_SDA)
SD_CS: IC1.18 (PB0), SD1.2 (CD/DAT3(!CS!))
SPI_MOSI: IC1.17 (PA7), IC3.2 (I1), SD1.3 (CMD(DI))
SW1: IC1.26 (PB13), SW5.2 (1)
SW2: IC1.27 (PB14), SW6.2 (1)
SW3: IC1.28 (PB15), SW7.2 (1)
SW4: IC1.29 (PA8), SW8.2 (1)
SW5: IC1.38 (PA15), SW9.2 (1)
SW6: IC1.39 (PB3), SW10.2 (1)
SW7: IC1.40 (PB4), SW11.2 (1)
SW8: IC1.41 (PB5), SW12.2 (1)
SW9: IC1.42 (PB6), SW13.2 (1)
SW10: IC1.43 (PB7), SW14.2 (1)
SW11: IC1.2 (PC13), SW15.2 (1)
SW12: IC1.3 (PC14), SW16.2 (1)
SW13: IC1.4 (PC15), SW17.2 (1)
SW14: IC1.5 (PF0/OSC<=), SW18.2 (1)
SW15: IC1.6 (PF1/OSC=>), SW19.2 (1)
UART1_TX: IC1.30 (PA9), JP1.3
USB_DN: IC1.32 (PA11), U2.A7 (DN1), U2.B7 (DN2)
USB_DP: IC1.33 (PA12), U2.A6 (DP1), U2.B6 (DP2)

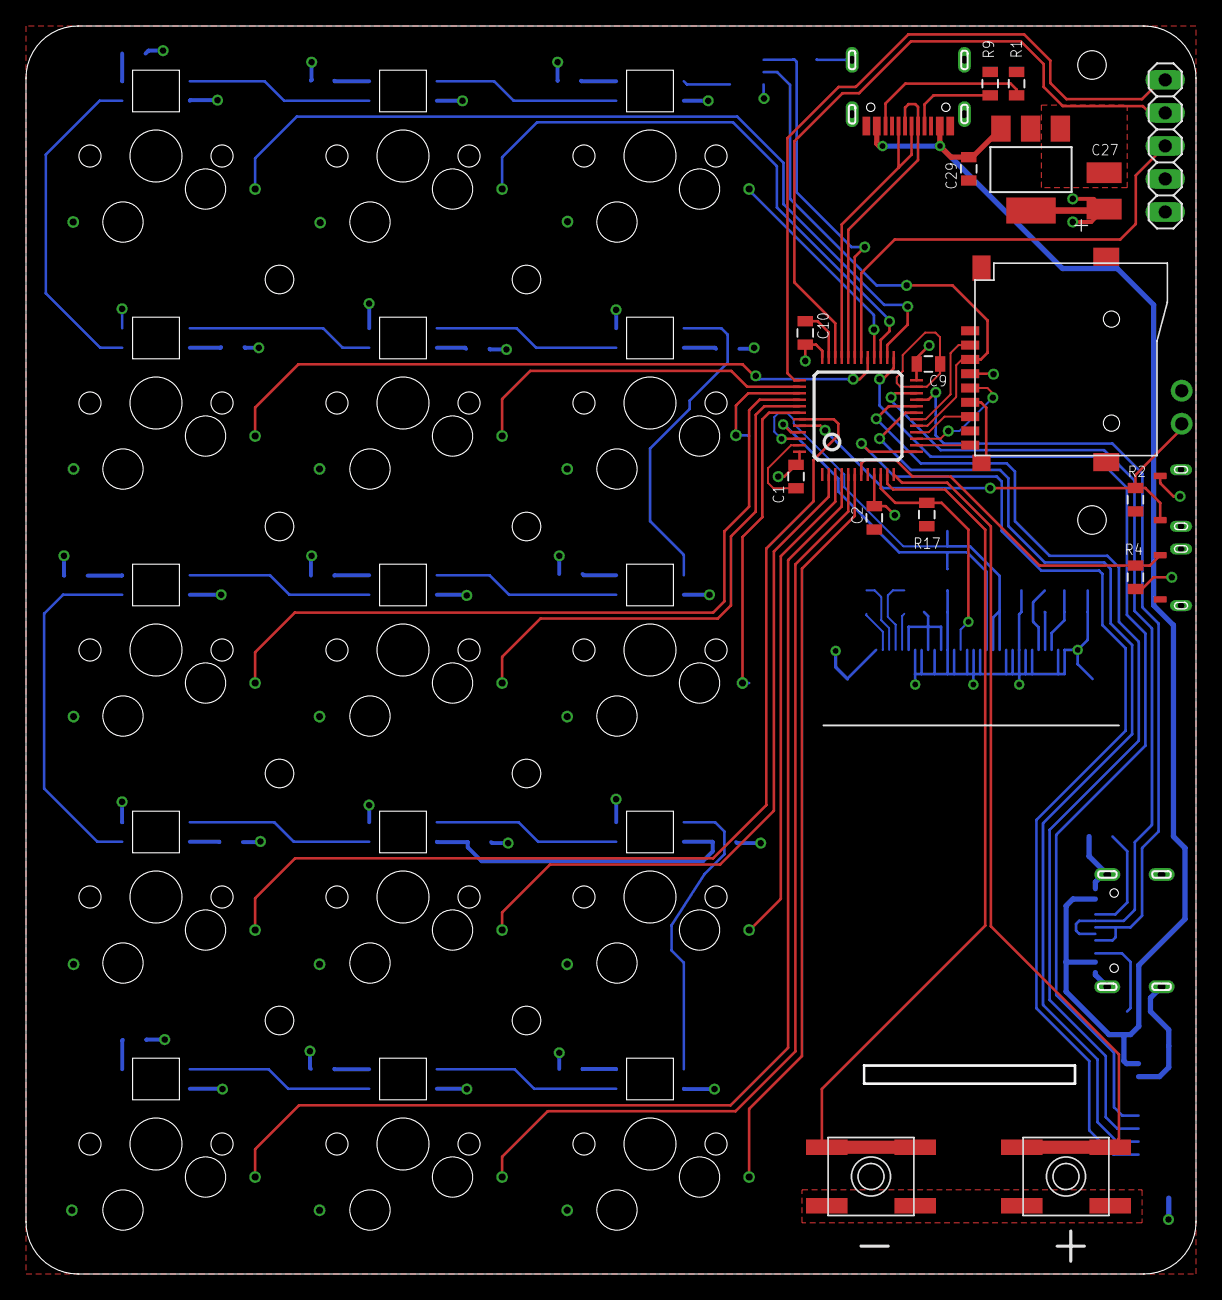
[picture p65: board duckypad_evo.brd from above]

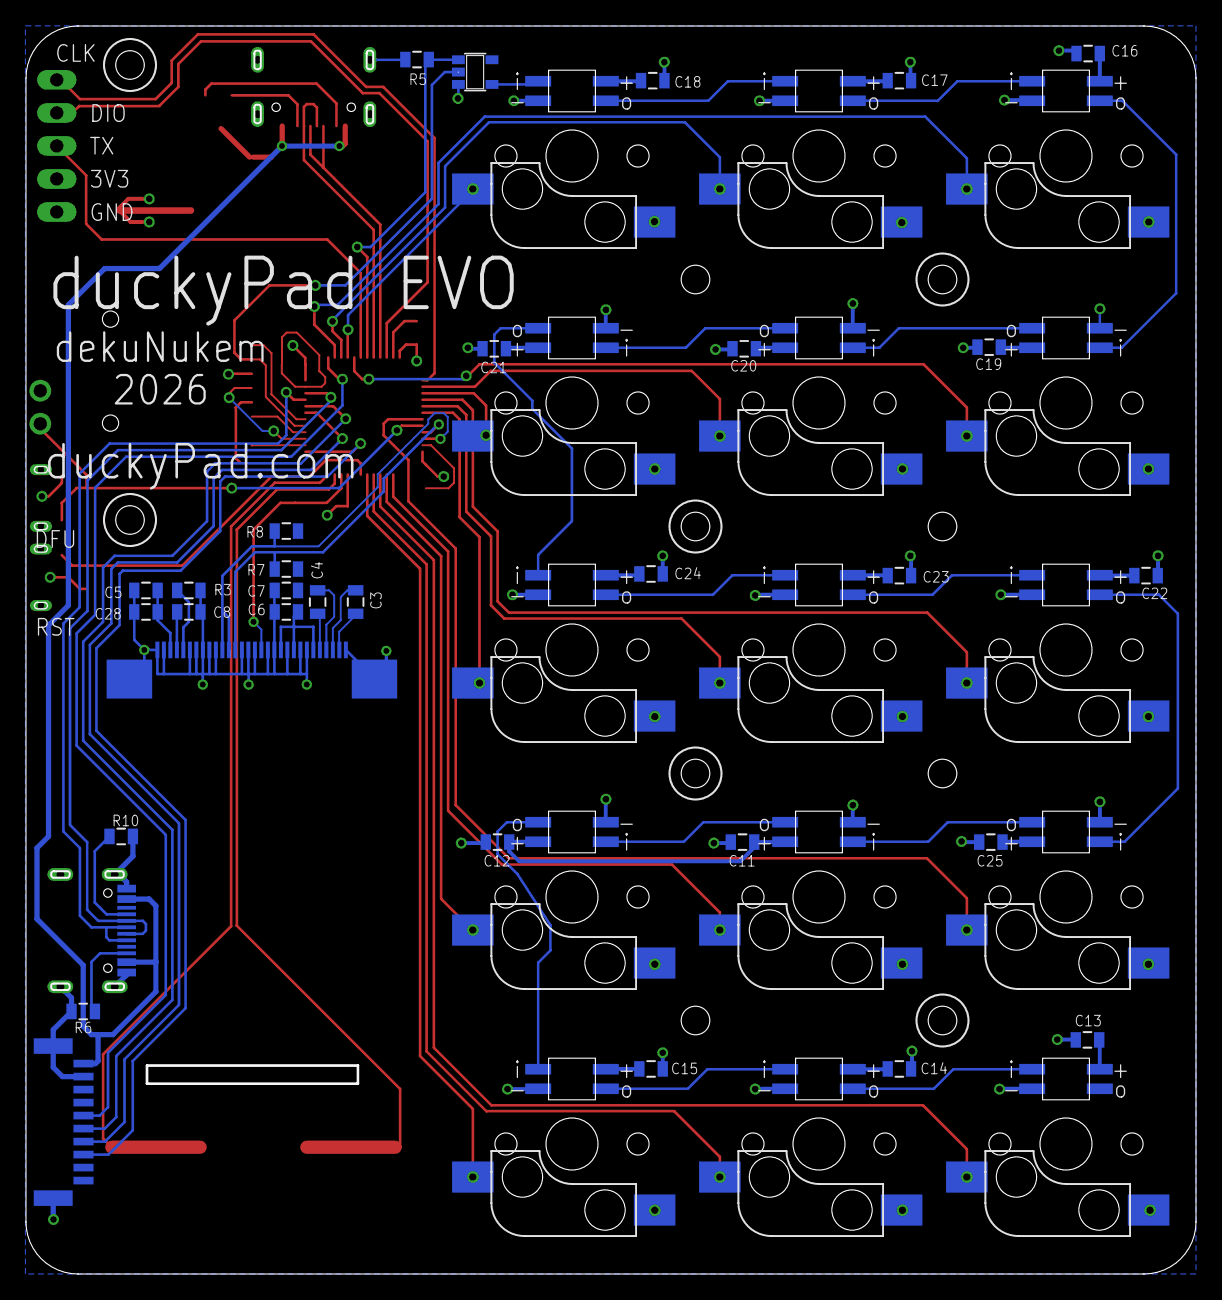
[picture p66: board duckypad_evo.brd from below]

Board: 2 copper layers, 90.0 x 96.0 mm, 93 parts (31 on the bottom side), 68 nets.

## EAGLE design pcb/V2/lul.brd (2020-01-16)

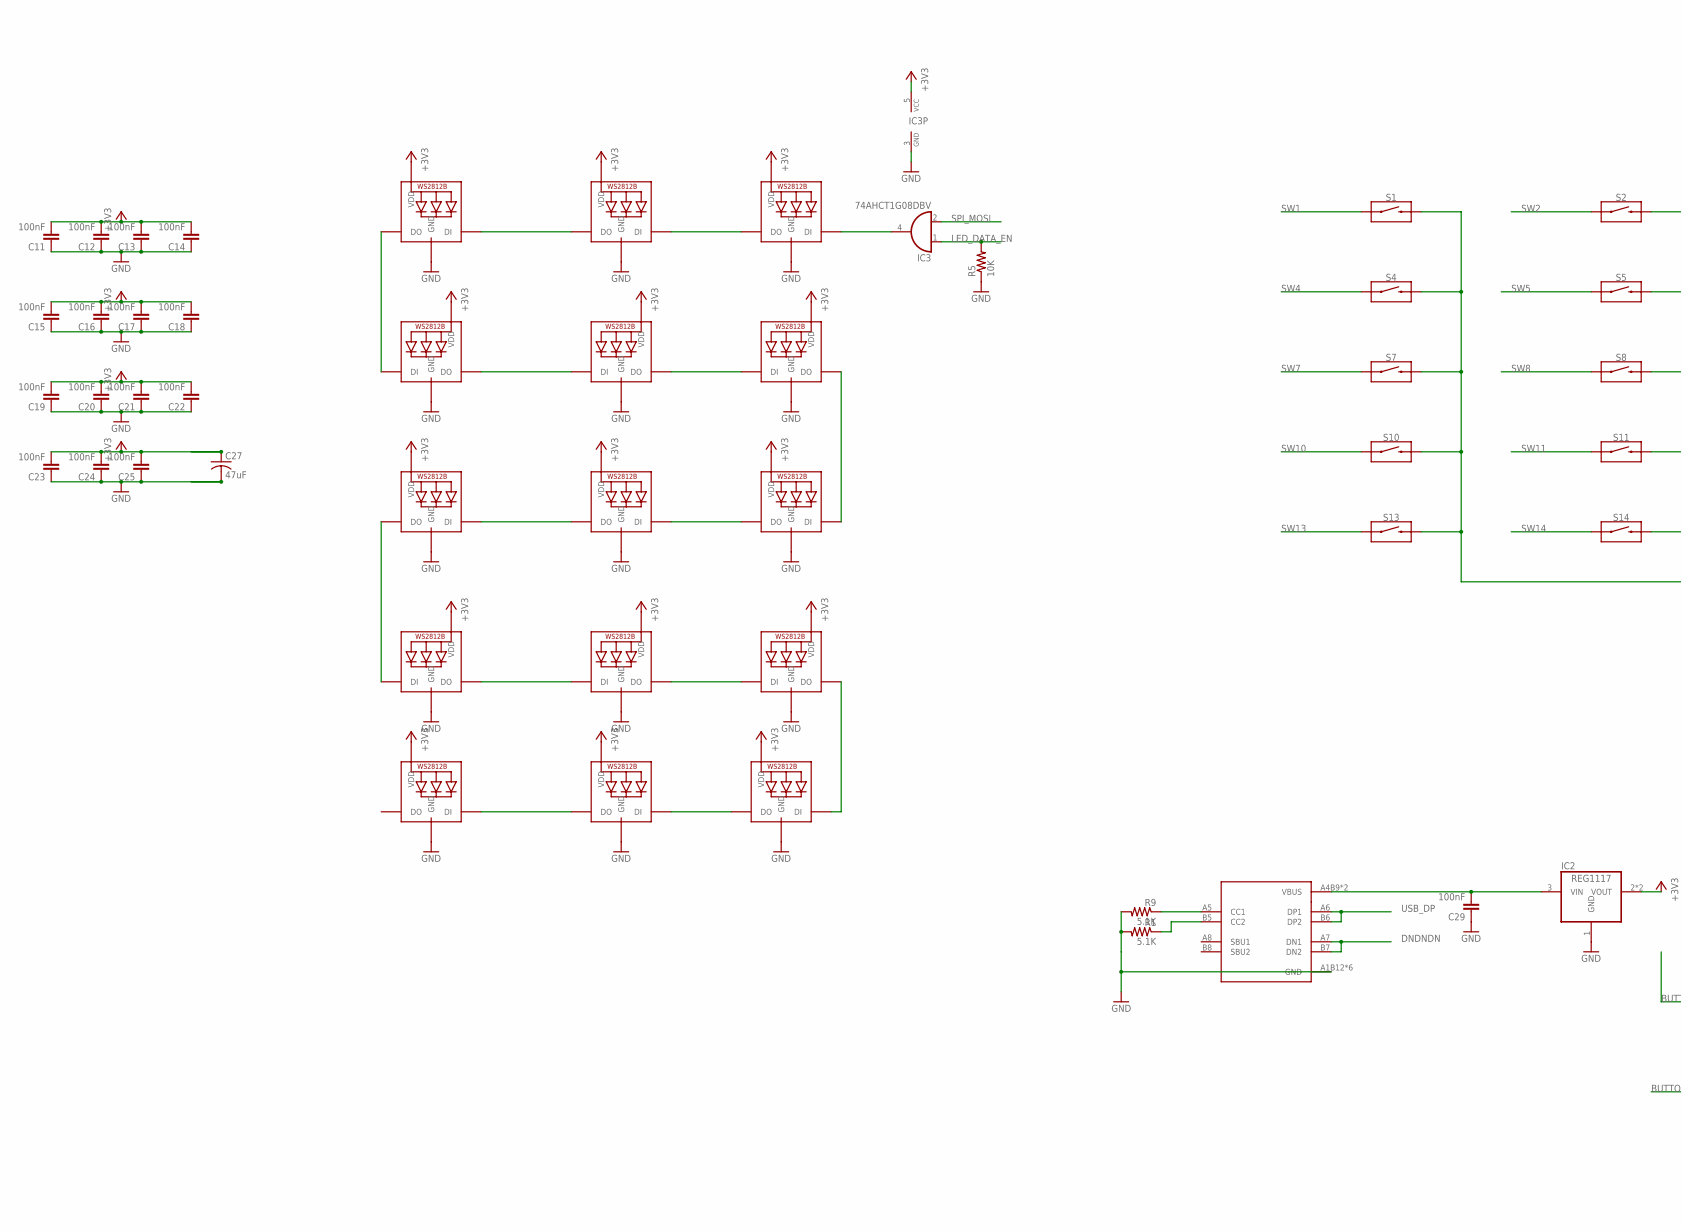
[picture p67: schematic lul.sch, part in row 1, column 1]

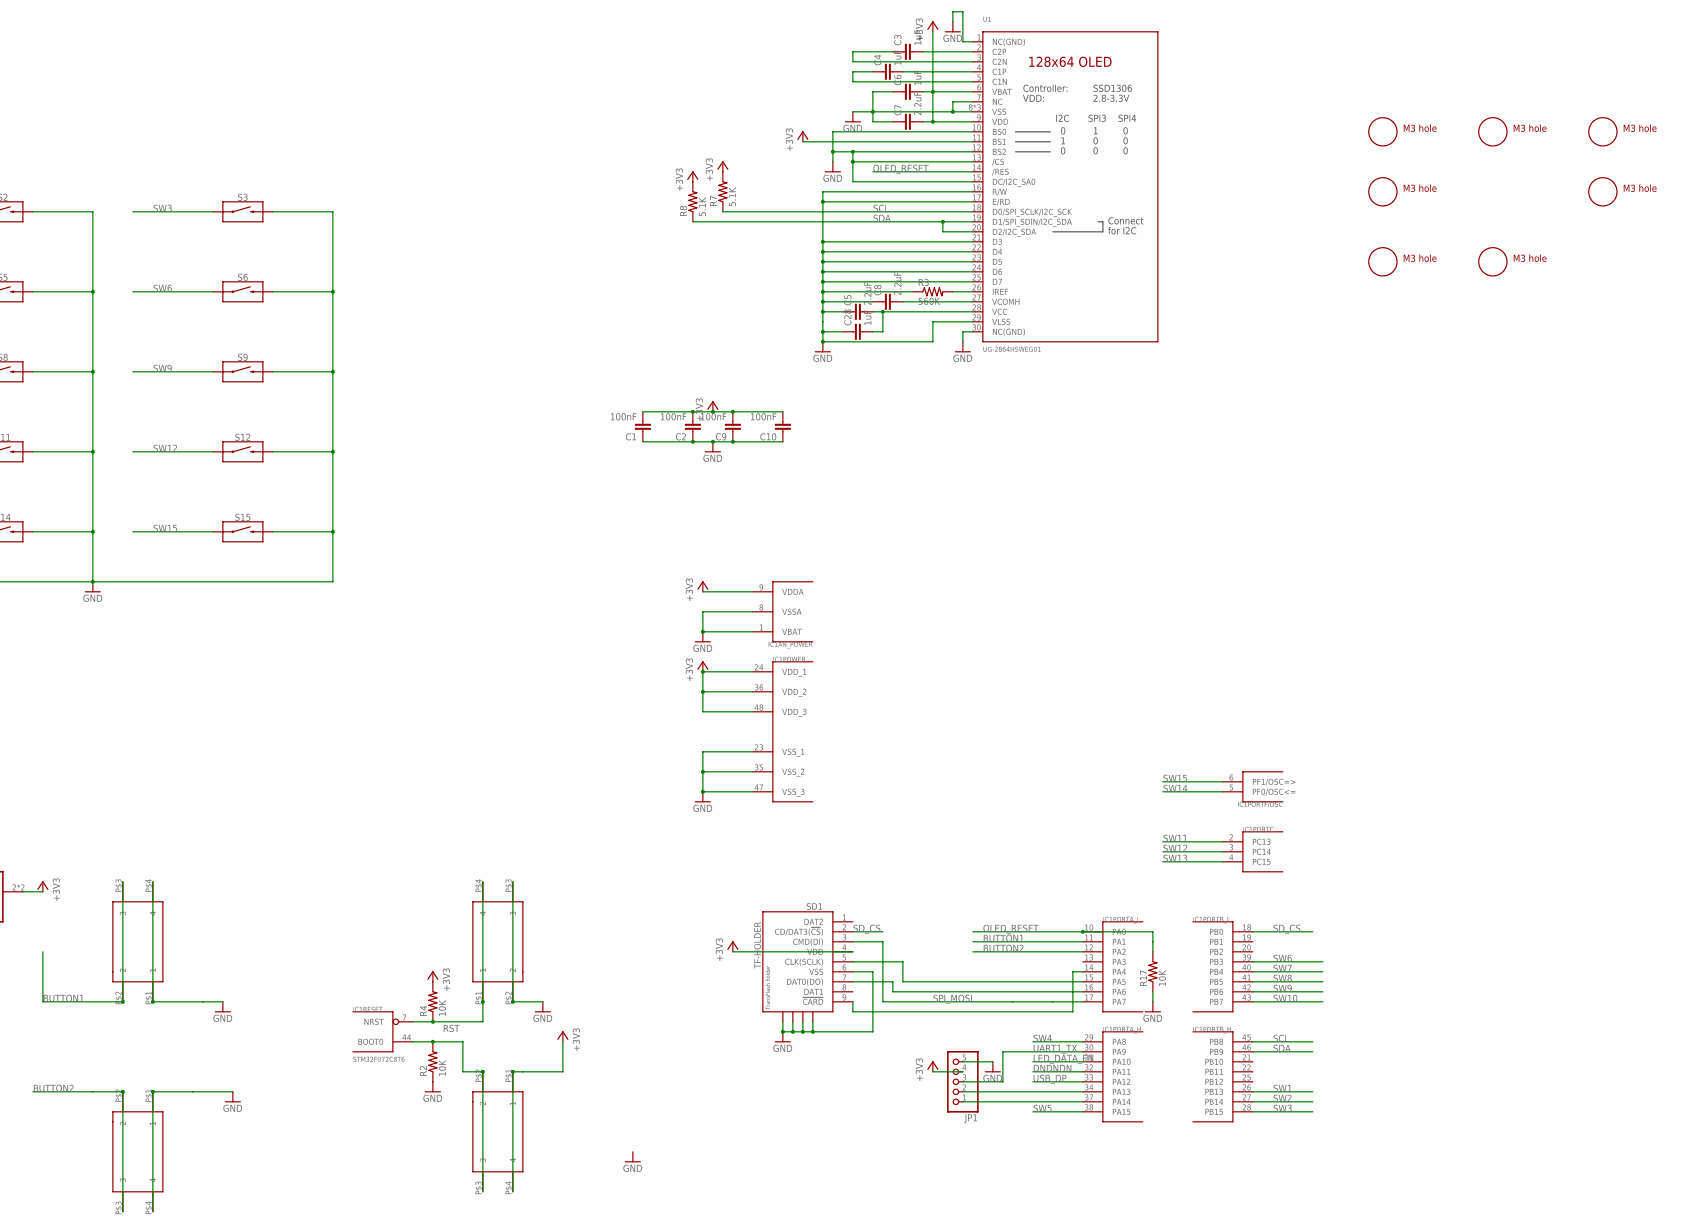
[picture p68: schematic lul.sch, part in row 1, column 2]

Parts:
C1, C2, C9, C10, C11, C12, C13, C14, C15, C16, C17, C18, C19, C20, C21, C22, C23, C24, C25, C29: 100nF; 0805@1
C3, C4, C6, C28: 1uF; 0805@1
C5, C7, C8: 2.2uF; 0805@1
C27: 47uF; C1210
IC1: STM32F072C8T6; TQFP48
IC2: REG1117; SOT223
IC3: 74AHCT1G08DBV; SOT23-5
JP1: PINHD-1X5; 1X05
LED1, LED2, LED3, LED4, LED5, LED6, LED7, LED8, LED9, LED10, LED11, LED12, LED13, LED14, LED15: WS2812B3535; LED3535
R1, R7, R8, R9: 5.1K; 0805
R2, R4, R5, R17: 10K; 0805
R3: 560K; 0805
S1, S2, S3, S4, S5, S6, S7, S8, S9, S10, S11, S12, S13, S14, S15: CHERRY-MX-LED
SD1: TF-HOLDER; TF-PULL
SW1, SW2, SW3, SW4: 324_SW324_SWITCH_FOOT_HOLE; 342_SWICH_FOOT_HOLE
U1: UG-2864HSWEG01; LUL_UG-2864HSWEG01_1.3_WRAPAROUND
U2: USBC_16P; USBC_16P_FOOT
U$7, U$9, U$10, U$11, U$14, U$15, U$16: M3_MOUNTING_HOLE; M3_MOUNTING_HOLE_PACK

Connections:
+3V3: C1.2, C2.2, C6.2, C7.2, C9.2, C10.2, C11.2, C12.2, C13.2, C14.2, C15.2, C16.2, C17.2, C18.2, C19.2, C20.2, C21.2, C22.2, C23.2, C24.2, C25.2, C27.1, IC1.9 (VDDA), IC1.24 (VDD_1), IC1.36 (VDD_2), IC1.48 (VDD_3), IC2.2 (VOUT), IC2.4 (VOUT), IC3.5 (VCC), JP1.4, LED1.2 (VDD), LED2.2 (VDD), LED3.2 (VDD), LED4.2 (VDD), LED5.2 (VDD), LED6.2 (VDD), LED7.2 (VDD), LED8.2 (VDD), LED9.2 (VDD), LED10.2 (VDD), LED11.2 (VDD), LED12.2 (VDD), LED13.2 (VDD), LED14.2 (VDD), LED15.2 (VDD), R4.2, R7.2, R8.2, SD1.4 (VDD), SW1.P$1 (1), SW1.P$4 (4), U1.6 (VBAT), U1.9 (VDD), U1.11 (BS1)
BUTTON1: IC1.11 (PA1), SW3.P$2 (2), SW3.P$3 (3)
BUTTON2: IC1.12 (PA2), SW4.P$2 (2), SW4.P$3 (3)
DNDNDN: IC1.32 (PA11), U2.A7 (DN1), U2.B7 (DN2)
GND: C1.1, C2.1, C5.1, C6.1, C7.1, C8.1, C9.1, C10.1, C11.1, C12.1, C13.1, C14.1, C15.1, C16.1, C17.1, C18.1, C19.1, C20.1, C21.1, C22.1, C23.1, C24.1, C25.1, C27.2, C28.1, C29.1, IC1.1 (VBAT), IC1.8 (VSSA), IC1.23 (VSS_1), IC1.35 (VSS_2), IC1.47 (VSS_3), IC2.1 (GND), IC3.3 (GND), JP1.5, LED1.4 (GND), LED2.4 (GND), LED3.4 (GND), LED4.4 (GND), LED5.4 (GND), LED6.4 (GND), LED7.4 (GND), LED8.4 (GND), LED9.4 (GND), LED10.4 (GND), LED11.4 (GND), LED12.4 (GND), LED13.4 (GND), LED14.4 (GND), LED15.4 (GND), R1.2, R2.1, R3.1, R5.1, R9.2, R17.1, S1.S2, S2.S2, S3.S2, S4.S2, S5.S2, S6.S2, S7.S2, S8.S2, S9.S2, S10.S2, S11.S2, S12.S2, S13.S2, S14.S2, S15.S2, SD1.6 (VSS), SD1.S1, SD1.S2, SD1.S3, SD1.S4, SW2.P$2 (2), SW2.P$3 (3), SW3.P$1 (1), SW3.P$4 (4), SW4.P$1 (1)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
LED_DATA_EN: IC1.31 (PA10), IC3.1 (I0), R5.2
unnamed: C29.2, IC2.3 (VIN), U2.A4B9 (VBUS), U2.B4A9 (VBUS)
unnamed: IC1.44 (BOOT0), R2.2, SW1.P$2 (2), SW1.P$3 (3)
unnamed: R3.2, U1.26 (IREF)
unnamed: C3.2, U1.2 (C2P)
unnamed: C3.1, U1.3 (C2N)
unnamed: C4.2, U1.4 (C1P)
unnamed: C4.1, U1.5 (C1N)
unnamed: IC1.15 (PA5), SD1.5 (CLK(SCLK))
unnamed: LED2.1 (DI), LED3.3 (DO)
unnamed: IC1.16 (PA6), SD1.7 (DAT0(DO))
unnamed: C5.2, C28.2, U1.28 (VCC)
unnamed: C8.2, U1.27 (VCOMH)
unnamed: IC1.14 (PA4), SD1.9 (!CARD)
unnamed: LED1.1 (DI), LED2.3 (DO)
unnamed: LED1.3 (DO), LED4.1 (DI)
unnamed: LED4.3 (DO), LED5.1 (DI)
unnamed: LED5.3 (DO), LED6.1 (DI)
unnamed: LED6.3 (DO), LED9.1 (DI)
unnamed: LED8.1 (DI), LED9.3 (DO)
unnamed: LED7.1 (DI), LED8.3 (DO)
unnamed: LED7.3 (DO), LED10.1 (DI)
unnamed: LED10.3 (DO), LED11.1 (DI)
unnamed: LED11.3 (DO), LED12.1 (DI)
unnamed: LED12.3 (DO), LED15.1 (DI)
unnamed: LED14.1 (DI), LED15.3 (DO)
unnamed: LED13.1 (DI), LED14.3 (DO)
unnamed: IC3.4 (O), LED3.1 (DI)
unnamed: R1.1, U2.B5 (CC2)
unnamed: IC1.37 (PA14), JP1.1
unnamed: R9.1, U2.A5 (CC1)
unnamed: IC1.34 (PA13), JP1.2
OLED_RESET: IC1.10 (PA0), R17.2, U1.14 (/RES)
RST: IC1.7 (NRST), R4.1, SW2.P$1 (1), SW2.P$4 (4)
SCL: IC1.45 (PB8), R7.1, U1.18 (D0/SPI_SCLK/I2C_SCK)
SDA: IC1.46 (PB9), R8.1, U1.19 (D1/SPI_SDIN/I2C_SDA), U1.20 (D2/I2C_SDA)
SD_CS: IC1.18 (PB0), SD1.2 (CD/DAT3(!CS!))
SPI_MOSI: IC1.17 (PA7), IC3.2 (I1), SD1.3 (CMD(DI))
SW1: IC1.26 (PB13), S1.S1
SW2: IC1.27 (PB14), S2.S1
SW3: IC1.28 (PB15), S3.S1
SW4: IC1.29 (PA8), S4.S1
SW5: IC1.38 (PA15), S5.S1
SW6: IC1.39 (PB3), S6.S1
SW7: IC1.40 (PB4), S7.S1
SW8: IC1.41 (PB5), S8.S1
SW9: IC1.42 (PB6), S9.S1
SW10: IC1.43 (PB7), S10.S1
SW11: IC1.2 (PC13), S11.S1
SW12: IC1.3 (PC14), S12.S1
SW13: IC1.4 (PC15), S13.S1
SW14: IC1.5 (PF0/OSC<=), S14.S1
SW15: IC1.6 (PF1/OSC=>), S15.S1
UART1_TX: IC1.30 (PA9), JP1.3
USB_DP: IC1.33 (PA12), U2.A6 (DP1), U2.B6 (DP2)

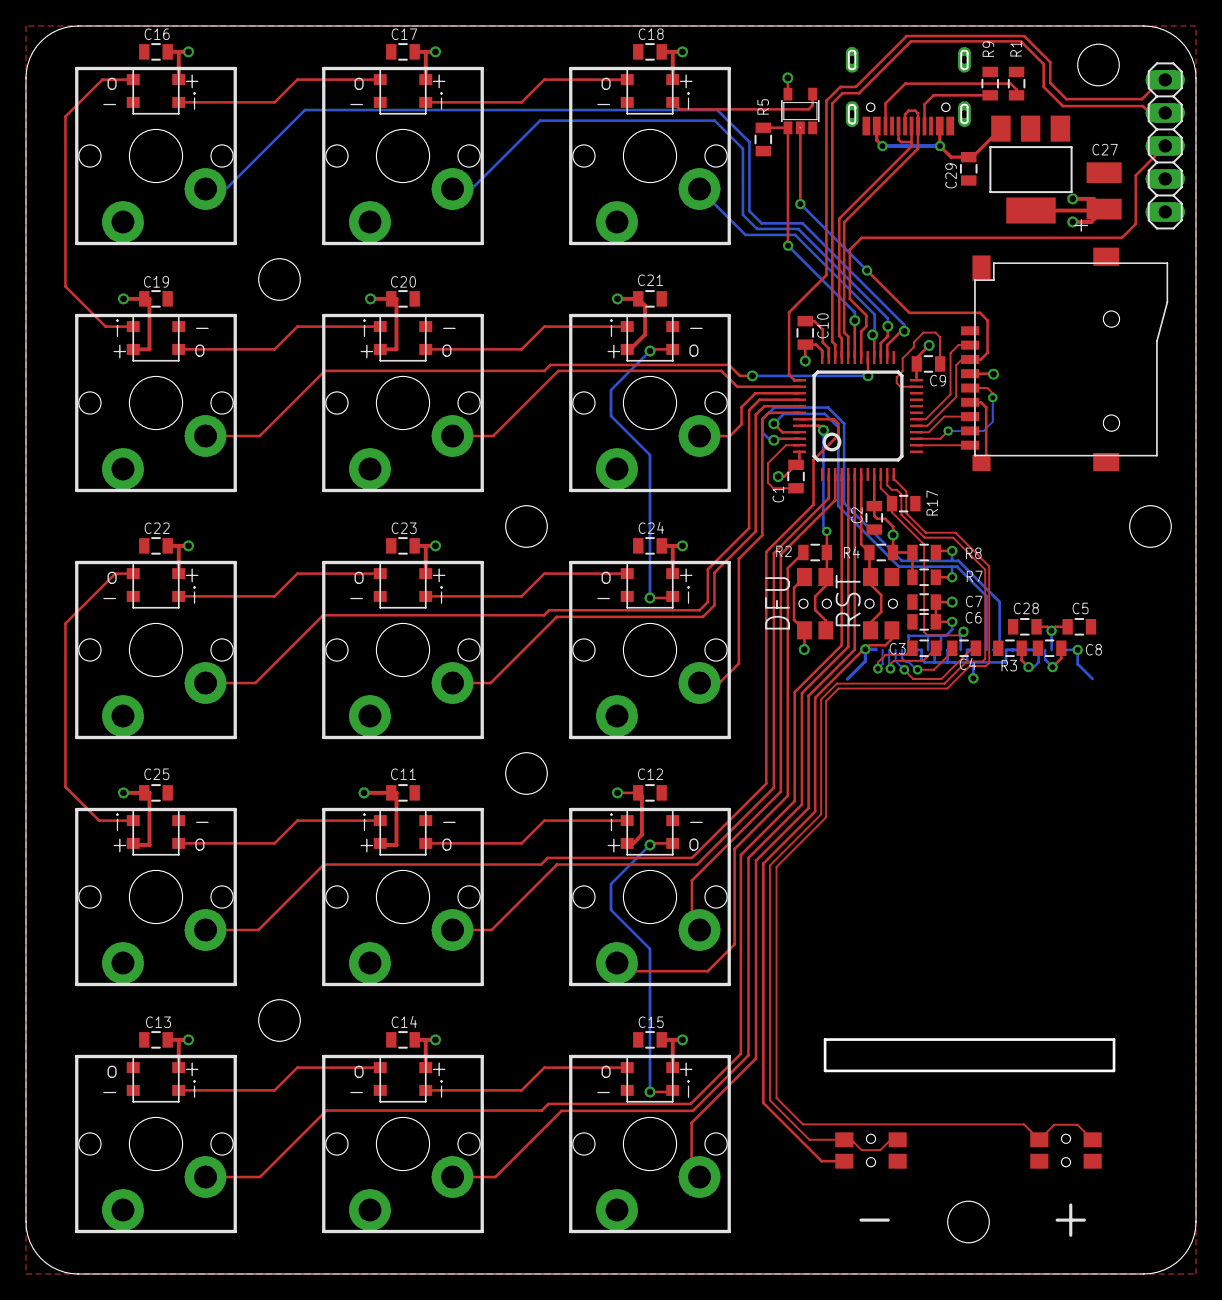
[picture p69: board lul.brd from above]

Board: 2 copper layers, 90.0 x 96.0 mm, 85 parts (0 on the bottom side), 60 nets.

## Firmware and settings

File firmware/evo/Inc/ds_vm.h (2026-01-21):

#ifndef ds_vm_h
#define ds_vm_h

#include <stdint.h>
#include <string.h>

#include "input_task.h"
#include "dsb_cache.h"

#define BUF_PADDING 8
#define EXE_BIN_START_ADDRESS 0x0
#define EXE_BIN_END_ADDRESS_INCLUSIVE 0xDFFF
#define STACK_BASE_ADDR 0xEFFF
#define STACK_BUF_SIZE 512
#define BIN_BUF_SIZE 512

#define USER_VAR_START_ADDRESS 0xF000
#define USER_VAR_END_ADDRESS_INCLUSIVE 0xF0FF
#define USER_VAR_BUF_SIZE (USER_VAR_END_ADDRESS_INCLUSIVE - USER_VAR_START_ADDRESS + BUF_PADDING)

#define SCRATCH_MEM_START_ADDRESS 0xF400
#define SCRATCH_MEM_END_ADDRESS_INCLUSIVE 0xF4FF
#define SCRATCH_MEM_BUF_SIZE (SCRATCH_MEM_END_ADDRESS_INCLUSIVE - SCRATCH_MEM_START_ADDRESS + BUF_PADDING)

#define PGV_START_ADDRESS 0xFC00
#define PGV_COUNT 32
#define PGV_BYTE_WIDTH 4
#define PGV_END_ADDRESS_INCLUSIVE 0xFC7F
#define PGV_BUF_SIZE (PGV_END_ADDRESS_INCLUSIVE - PGV_START_ADDRESS + BUF_PADDING)

#define INTERAL_VAR_START_ADDRESS 0xFE00
#define INTERAL_VAR_BYTE_WIDTH 4
#define INTERAL_VAR_END_ADDRESS_INCLUSIVE 0xFE7F

#define MEM_END_ADDR 0xFFFF

#define MAX_INSTRUCTION_LEN 5
#define HIDTX_PACKET_SIZE 9

#define EXE_OK 0

#define EXE_ACTION_SLEEP 1
#define EXE_ACTION_PREV_PROFILE 2
#define EXE_ACTION_NEXT_PROFILE 3
#define EXE_ACTION_GOTO_PROFILE 4

#define EXE_HALT 10
#define EXE_ABORTED 11

#define EXE_ERROR_CODE_START 20
#define EXE_ILLEGAL_INSTRUCTION (EXE_ERROR_CODE_START + 0)
#define EXE_DSB_INCOMPATIBLE_VERSION (EXE_ERROR_CODE_START + 1)
#define EXE_DSB_FOPEN_FAIL (EXE_ERROR_CODE_START + 2)
#define EXE_DSB_FREAD_ERROR (EXE_ERROR_CODE_START + 3)
#define EXE_STACK_OVERFLOW (EXE_ERROR_CODE_START + 4)
#define EXE_STACK_UNDERFLOW (EXE_ERROR_CODE_START + 5)
#define EXE_DIVISION_BY_ZERO (EXE_ERROR_CODE_START + 6)
#define EXE_ILLEGAL_ADDR (EXE_ERROR_CODE_START + 7)
#define EXE_DSB_FILE_TOO_LARGE (EXE_ERROR_CODE_START + 8)
#define EXE_UNIMPLEMENTED (EXE_ERROR_CODE_START + 9)
#define EXE_UNALIGNED_ACCESS (EXE_ERROR_CODE_START + 10)
#define EXE_PROFILE_NOT_FOUND (EXE_ERROR_CODE_START + 11)
#define EXE_STR_ERROR (EXE_ERROR_CODE_START + 12)

#define _DEFAULTDELAY (INTERAL_VAR_START_ADDRESS + 0 * INTERAL_VAR_BYTE_WIDTH)
#define _DEFAULTCHARDELAY (INTERAL_VAR_START_ADDRESS + 1 * INTERAL_VAR_BYTE_WIDTH)
#define _CHARJITTER (INTERAL_VAR_START_ADDRESS + 2 * INTERAL_VAR_BYTE_WIDTH)
#define _RANDOM_MIN (INTERAL_VAR_START_ADDRESS + 3 * INTERAL_VAR_BYTE_WIDTH)
#define _RANDOM_MAX (INTERAL_VAR_START_ADDRESS + 4 * INTERAL_VAR_BYTE_WIDTH)
#define _RANDOM_INT (INTERAL_VAR_START_ADDRESS + 5 * INTERAL_VAR_BYTE_WIDTH)
#define _TIME_MS (INTERAL_VAR_START_ADDRESS + 6 * INTERAL_VAR_BYTE_WIDTH)
#define _READKEY (INTERAL_VAR_START_ADDRESS + 7 * INTERAL_VAR_BYTE_WIDTH)
#define _LOOP_SIZE (INTERAL_VAR_START_ADDRESS + 8 * INTERAL_VAR_BYTE_WIDTH)
#define _KEYPRESS_COUNT (INTERAL_VAR_START_ADDRESS + 9 * INTERAL_VAR_BYTE_WIDTH)
#define _EPILOGUE_ACTIONS (INTERAL_VAR_START_ADDRESS + 10 * INTERAL_VAR_BYTE_WIDTH)
#define _TIME_S (INTERAL_VAR_START_ADDRESS + 11 * INTERAL_VAR_BYTE_WIDTH)
#define _ALLOW_ABORT (INTERAL_VAR_START_ADDRESS + 12 * INTERAL_VAR_BYTE_WIDTH)
#define _BLOCKING_READKEY (INTERAL_VAR_START_ADDRESS + 13 * INTERAL_VAR_BYTE_WIDTH)
#define _KBLED_BITFIELD (INTERAL_VAR_START_ADDRESS + 14 * INTERAL_VAR_BYTE_WIDTH)
#define _DONT_REPEAT (INTERAL_VAR_START_ADDRESS + 15 * INTERAL_VAR_BYTE_WIDTH)
#define _THIS_KEYID (INTERAL_VAR_START_ADDRESS + 16 * INTERAL_VAR_BYTE_WIDTH)
#define _DP_MODEL (INTERAL_VAR_START_ADDRESS + 17 * INTERAL_VAR_BYTE_WIDTH)
#define _RTC_IS_VALID (INTERAL_VAR_START_ADDRESS + 18 * INTERAL_VAR_BYTE_WIDTH)
#define _RTC_UTC_OFFSET (INTERAL_VAR_START_ADDRESS + 19 * INTERAL_VAR_BYTE_WIDTH)
#define _RTC_YEAR (INTERAL_VAR_START_ADDRESS + 20 * INTERAL_VAR_BYTE_WIDTH)
#define _RTC_MONTH (INTERAL_VAR_START_ADDRESS + 21 * INTERAL_VAR_BYTE_WIDTH)
#define _RTC_DAY (INTERAL_VAR_START_ADDRESS + 22 * INTERAL_VAR_BYTE_WIDTH)
#define _RTC_HOUR (INTERAL_VAR_START_ADDRESS + 23 * INTERAL_VAR_BYTE_WIDTH)
#define _RTC_MINUTE (INTERAL_VAR_START_ADDRESS + 24 * INTERAL_VAR_BYTE_WIDTH)
#define _RTC_SECOND (INTERAL_VAR_START_ADDRESS + 25 * INTERAL_VAR_BYTE_WIDTH)
#define _RTC_WDAY (INTERAL_VAR_START_ADDRESS + 26 * INTERAL_VAR_BYTE_WIDTH)
#define _RTC_YDAY (INTERAL_VAR_START_ADDRESS + 27 * INTERAL_VAR_BYTE_WIDTH)
#define _SW_BITFIELD (INTERAL_VAR_START_ADDRESS + 28 * INTERAL_VAR_BYTE_WIDTH)
#define _UNUSED MEM_END_ADDR

#define DUMMY_DATA_REPLACE_ME 69

typedef struct
{
  uint8_t result;
  uint16_t this_pc;
  uint16_t next_pc;
  uint8_t data;
  uint8_t epilogue_actions;
} exe_context;

#define DEFAULT_NONCHAR_DELAY_MS 20
#define DEFAULT_CHAR_DELAY_MS 20

#define EPILOGUE_SAVE_LOOP_STATE 0x1
#define EPILOGUE_SAVE_COLOR_STATE 0x2
#define EPILOGUE_NEED_OLED_RESTORE 0x4
#define EPILOGUE_DONT_AUTO_REPEAT 0x8
#define EPILOGUE_SAVE_PGV 0x10

#define MYMAX(a, b) ((a) > (b) ? (a) : (b))

extern uint8_t bin_buf[BIN_BUF_SIZE] __attribute__((aligned(4)));
extern uint8_t allow_abort;
extern uint8_t kb_led_status;
extern uint8_t pgv_buf[PGV_BUF_SIZE] __attribute__((aligned(4)));

#define MAKESTR_VAR_BOUNDARY_IMM (0x1f)
#define MAKESTR_VAR_BOUNDARY_REL (0x1e)

/*
  Stack grows from larger address to smaller address
  SP points to next available slot
*/
typedef struct
{
  uint16_t sp;         // Virtual Stack Pointer
  uint16_t fp;         // Virtual Frame Pointer
  uint16_t lower_bound;// Lowest allowed virtual address (Stack Limit)
  uint16_t upper_bound;// Highest allowed virtual address (Stack Base)
  uint8_t* ram_base;   // Host buffer backing the VM stack
} my_stack;

typedef uint32_t (*FUNC_PTR_BINOP)(uint32_t, uint32_t);
typedef uint32_t (*FUNC_PTR_UNARY)(uint32_t);

#define DS_SET_BITS(variable, mask)   ((variable) |= (mask))
#define DS_CLEAR_BITS(variable, mask) ((variable) &= ~(mask))

void run_dsb(exe_context* ctx, uint8_t this_key_id, char* dsb_path, uint8_t* dsb_cache_buf);
uint32_t my_randu32(void);
uint32_t random_uint32_between(uint32_t lower, uint32_t upper);
int32_t random_int32_between(int32_t lower, int32_t upper);
void switch_bank(uint16_t addr);
void read_binexe_bytes_safe(uint32_t vm_addr, void* dest, size_t size);

#define READ_BUF_SIZE (256 * 2)
extern char read_buffer[READ_BUF_SIZE];

#endif

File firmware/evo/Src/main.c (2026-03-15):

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
/* Includes ------------------------------------------------------------------*/
#include "main.h"
#include "fatfs.h"
#include "usb_device.h"

/* USER CODE BEGIN Includes */

// #include <stdio.h>
// #include <string.h>
// #include <stdlib.h>
#include <stdint.h>
#include "fonts.h"
#include "ssd1306.h"
#include "sd_util.h"
#include "cQueue.h"
#include "input_task.h"
#include "shared.h"
#include "neopixel.h"
#include "ui_task.h"
#include "profiles.h"
#include "keypress_task.h"
#include "hid_task.h"
#include "keyboard.h"
#include "dsb_cache.h"

/*
menu bar:
project
manage
runtime environment
compiler
IO
set all to user
check box, press save
add code below
*/

/* USER CODE END Includes */

I2C_HandleTypeDef hi2c1;

RTC_HandleTypeDef hrtc;

SPI_HandleTypeDef hspi1;

TIM_HandleTypeDef htim2;
TIM_HandleTypeDef htim17;

UART_HandleTypeDef huart1;

/* USER CODE BEGIN PV */

/*
  Version History

  Apr 4 2025
  2.0.0
  DPP Backport beta public release

  May 23 2025
  2.1.0
  Added key caching

  June 29 2025
  2.2.0
  Expanded Persistent Global Variables to 32
  Fixed a bug that caused PGV to not work
  Added HID read and write of PGVs

  July 8 2025
  2.3.2
  Fixed a bug where HID buffer was not properly cleared
  reverted to old settings save function to reduce SD card corruption

  Jan 18 2026
  3.0.0
  Porting DSVM2

  Jan 26 2026
  3.0.1
  Fixed Linux empty HID packet bug
  Removed unused USART3 code

  Jan 28 2026
  3.0.2
  fixed RTC update hang
  faster OLED drawing
  only draw rtc icon when not sleeping
  only draws keyboard LED indicator when USB is connected
	
	Mar 1 2026
	3.0.3
	Fixed `GOTO_PROFILE` not working

  Mar 15 2026
  3.0.4
  Increased Anykey-to-Abort check frequency

*/

uint32_t current_tick;

uint8_t fw_version_major = 3;
uint8_t fw_version_minor = 0;
uint8_t fw_version_patch = 4;
uint8_t dsvm_version = 2;

/* USER CODE END PV */

void SystemClock_Config(void);
static void MX_GPIO_Init(void);
static void MX_USART1_UART_Init(void);
static void MX_SPI1_Init(void);
static void MX_I2C1_Init(void);
static void MX_TIM17_Init(void);
static void MX_TIM2_Init(void);
static void MX_RTC_Init(void);
/* USER CODE BEGIN 0 */
int fputc(int ch, FILE *f)
{
  HAL_UART_Transmit(&huart1, (unsigned char *)&ch, 1, 100);
  return ch;
}

// happens every 5ms
void HAL_TIM_PeriodElapsedCallback(TIM_HandleTypeDef *htim)
{
	current_tick++;
  if(current_tick % 2 == 0)
    kb_scan_task();
  if(current_tick % 4 == 0)
    led_animation_handler();
}

// SD card eject interrupt
void HAL_GPIO_EXTI_Callback(uint16_t GPIO_Pin)
{
  NVIC_SystemReset();
}

/* USER CODE END 0 */

/**
  * @brief  The application entry point.
  * @retval int
  */
int main(void)
{
  /* MCU Configuration--------------------------------------------------------*/

  /* Reset of all peripherals, Initializes the Flash interface and the Systick. */
  HAL_Init();

  /* Configure the system clock */
  SystemClock_Config();

  /* Initialize all configured peripherals */
  MX_GPIO_Init();
  MX_USART1_UART_Init();
  MX_SPI1_Init();
  MX_FATFS_Init();
  MX_I2C1_Init();
  MX_USB_DEVICE_Init();
  MX_TIM17_Init();
  MX_TIM2_Init();
  MX_RTC_Init();
  /* USER CODE BEGIN 2 */
	HAL_TIM_Base_Start_IT(&htim17);
  HAL_TIM_Base_Start(&htim2);
  /* USER CODE END 2 */

  /* Infinite loop */
  /* USER CODE BEGIN WHILE */
  oled_reset();
  neopixel_off();
  ssd1306_Init();
  led_animation_init();
  switch_init();
  printf("duckyPad EVO v%d.%d.%d\n", fw_version_major, fw_version_minor, fw_version_patch);

  if(mount_sd())
  {
    draw_nosd();
    idle_loop();
  }

  ensure_new_profile_format();

  if(scan_profiles())
  {
    draw_noprofile();
    idle_loop();
  }
  
  load_settings(&dp_settings);
  load_keymap_by_name(dp_settings.current_kb_layout);
  load_gv();
  profile_init();
  keypress_task();
  
  // we should never get here
  while (1)
  {
    delay_ms(100);
    /* USER CODE END WHILE */

    /* USER CODE BEGIN 3 */
  }
  /* USER CODE END 3 */
}

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


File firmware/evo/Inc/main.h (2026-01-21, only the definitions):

#define SW11_Pin GPIO_PIN_13
#define SW11_GPIO_Port GPIOC
#define SW12_Pin GPIO_PIN_14
#define SW12_GPIO_Port GPIOC
#define SW13_Pin GPIO_PIN_15
#define SW13_GPIO_Port GPIOC
#define SW14_Pin GPIO_PIN_0
#define SW14_GPIO_Port GPIOF
#define SW15_Pin GPIO_PIN_1
#define SW15_GPIO_Port GPIOF
#define OLED_RESET_Pin GPIO_PIN_0
#define OLED_RESET_GPIO_Port GPIOA
#define MINUS_BUTTON_Pin GPIO_PIN_1
#define MINUS_BUTTON_GPIO_Port GPIOA
#define PLUS_BUTTON_Pin GPIO_PIN_2
#define PLUS_BUTTON_GPIO_Port GPIOA
#define CARD_DETECT_Pin GPIO_PIN_4
#define CARD_DETECT_GPIO_Port GPIOA
#define CARD_DETECT_EXTI_IRQn EXTI4_15_IRQn
#define SD_CS_Pin GPIO_PIN_0
#define SD_CS_GPIO_Port GPIOB
#define SW1_Pin GPIO_PIN_13
#define SW1_GPIO_Port GPIOB
#define SW2_Pin GPIO_PIN_14
#define SW2_GPIO_Port GPIOB
#define SW3_Pin GPIO_PIN_15
#define SW3_GPIO_Port GPIOB
#define SW4_Pin GPIO_PIN_8
#define SW4_GPIO_Port GPIOA
#define LED_DATA_EN_Pin GPIO_PIN_10
#define LED_DATA_EN_GPIO_Port GPIOA
#define SW5_Pin GPIO_PIN_15
#define SW5_GPIO_Port GPIOA
#define SW6_Pin GPIO_PIN_3
#define SW6_GPIO_Port GPIOB
#define SW7_Pin GPIO_PIN_4
#define SW7_GPIO_Port GPIOB
#define SW8_Pin GPIO_PIN_5
#define SW8_GPIO_Port GPIOB
#define SW9_Pin GPIO_PIN_6
#define SW9_GPIO_Port GPIOB
#define SW10_Pin GPIO_PIN_7
#define SW10_GPIO_Port GPIOB

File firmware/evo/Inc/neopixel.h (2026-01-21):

#ifndef __NEOPIXEL_H
#define __NEOPIXEL_H

#ifdef __cplusplus
 extern "C" {
#endif 

#include "stm32f0xx_hal.h"

#define NEOPIXEL_PADDING_BUF_SIZE 4
#define NEOPIXEL_COUNT 15

#define WS_SPI_BUF_SIZE 24
#define WS_BIT_0 0xc0
#define WS_BIT_1 0xf8

#define BRIGHTNESS_LEVEL_SIZE 5
#define ANIMATION_NONE 0
#define ANIMATION_CROSS_FADE 1

#define THREE 3
#define RED 0
#define GREEN 1
#define BLUE 2
#define DEFAULT_BG_RED 64
#define DEFAULT_BG_GREEN 16
#define DEFAULT_BG_BLUE 255
#define DEFAULT_KD_RED 255
#define DEFAULT_KD_GREEN 255
#define DEFAULT_KD_BLUE 255

typedef struct
{
	uint32_t animation_start;
	uint8_t animation_type;
	uint8_t animation_duration;
	uint8_t target_color[THREE];
	double current_color[THREE];
	double step[THREE];
} led_animation;

void spi_fastwrite_buf_size_even(uint8_t *pData, int count);
void neopixel_show(uint8_t* red, uint8_t* green, uint8_t* blue, uint8_t brightness);
void set_pixel_3color(uint8_t which, uint8_t r, uint8_t g, uint8_t b);
void set_pixel_3color_update_buffer(uint8_t which, uint8_t r, uint8_t g, uint8_t b);
void set_pixel_color(uint8_t which, uint8_t dest_color[THREE]);
void neopixel_draw_current_buffer(void);
void neopixel_fill(uint8_t rr, uint8_t gg, uint8_t bb);
void neopixel_off(void);
void neopixel_redraw_bg(void);
void reset_key_color(uint8_t which);
void led_start_animation(led_animation* anime_struct, uint8_t dest_color[THREE], uint8_t anime_type, uint8_t durations_frames);
void play_keydown_animation(uint8_t sw_number);
void play_keyup_animation(uint8_t sw_number);
void led_animation_handler(void);
void led_animation_init(void);
void draw_settings_led(void);
void get_current_color(uint8_t which, uint8_t* red, uint8_t* green, uint8_t* blue);
void halt_all_animations(void);

extern const uint8_t brightness_index_to_percent_lookup[BRIGHTNESS_LEVEL_SIZE];
extern volatile uint32_t frame_counter;

#ifdef __cplusplus
}
#endif

#endif

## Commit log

2017-08-10 working on pcb
    [lul.brd, lul.sch]
2017-08-10 routing lulboard
    [lul.brd, lul.sch]
2017-08-10 SLMOST FINISHED
    [lul.brd, lul.sch]
2017-08-10 w2812 working, before changing pcb to ws2812
    [lul.brd, lul.sch]
2017-08-10 74hc125 tested working
    [lul.brd, lul.sch]
2017-08-11 before rotating
    [lul.brd, lul.sch]
2017-08-11 routing finished
    [lul.brd, lul.sch]
2017-08-11 seemingly finished
    [lul.brd, lul.sch]
2017-08-12 adjusted for both 0.96 and 1.3 inch oled
    [lul.brd, lul.sch]
2017-08-13 adjusted position of led cap
    [lul.brd, lul.sch]
2017-08-14 rev0 gerber
    [lul.GBL, lul.GBO, lul.GBP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]
2017-08-16 started working on board firmware
    [lul.GBL, lul.GBO, lul.GBP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]
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2017-08-21 seems like a stack issue
    [temp.c]
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2017-08-21 RTOS working start
    [Adafruit 128x64 Mono OLED PCB v2.brd, Adafruit 128x64 Mono OLED PCB v2.sch, lul.brd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]
2017-08-22 before switching to dash keyname
    [lul.brd, lul.sch]
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2017-08-22 done for today
    [lul.brd]
2017-08-24 before cubing for more stack
    [Adafruit_1.3_128x64_OLED.brd, Adafruit_1.3_128x64_OLED.sch]
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2017-09-03 changed cap values
    [lul.brd, lul.sch]
2017-09-04 light sensor is now oled reset
    [lul.ioc, main.c, main.h]
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2017-09-07 new pcb layout for oled reset
    [lul.brd, lul.sch]
2017-10-04 ribbon cable connection solved
2017-10-16 cleaned up schematics
    [lul.brd, lul.sch]
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2017-10-16 started writing readme
    [config.txt]
2017-10-18 updating README
    [config.txt]
2017-10-19 writing README
    [lul.brd, lul.sch]
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2017-11-22 added bom
    [kbord_bom.xlsx]
2017-11-22 updated bom
    [kbord_bom.xlsx]
2019-06-08 working on v2
    [lul.brd, lul.sch]
2019-06-08 replaced DFU and RST button
    [lul.brd, lul.sch]
2019-06-08 new oled socket
    [lul.brd, lul.sch]
2019-06-09 new buttons
    [lul.brd, lul.sch]
2019-06-09 clean up main folder
    [SparkFun-Cherry-MX-Switch-Breakout.brd, SparkFun-Cherry-MX-Switch-Breakout.sch, lul.brd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]
2019-06-11 adjust components
    [lul.brd]
2019-06-12 new pcb ready for fab
    [lul.brd, lul.sch]
2019-06-15 kbord v2 working
    [lul.brd]
2019-06-15 firmware improvment, new plus/minus buttons
    [config.txt, lul.brd, lul.sch]
2019-06-16 OLED dimming when idle to prevent burn-in
    [my_tasks.c, temp.c]
2019-06-16 v3 changes
    [lul.brd]
2019-06-17 added parse error flashing
    [lul.brd]
2019-06-21 keydown color now stays on while script is executing
    [config.txt, lul.brd]
2019-06-22 adjusted sample profiles
    [config.txt]
2019-06-30 production run 1
    [lul.brd, lul.sch]
2019-10-05 added v2 resources
    [kbord_v1_bom.xlsx, kbord_v2_bom.xlsx]
2020-01-14 updated docs, build details
    [config.txt, kbord_v2_bom.xlsx]
2020-01-15 new pcb photo, fixed a typo in firmware
    [main.c]
2020-01-16 changed name to duckypad
    [duckypad_v2_bom.xlsx, kbord_v2_bom.xlsx]
2020-01-16 updating names
    [lul.brd]
2020-02-04 fixed a crash when holding down unused keys
    [temp.c]
2020-02-07 fixed F12 parsing bug, changed default backlight, general cleanup
    [animations.h, temp.c]
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2020-02-07 a bit unstable now for some reason
    [main.c]
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2020-03-06 updated default keydown colour, fixed minor bug in keydown animation
    [animations.h]
2020-05-03 added hot-swap sockets
    [duckypad_v2_bom.xlsx, lul.brd, lul.sch]
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2020-05-08 changed to reverse-mount RGB LED
    [duckypad_v3_bom.xlsx, duckypad_v4_bom.xlsx, lul.brd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]
2020-05-10 updated sample profiles
    [config.txt]
2020-05-21 modified mounting plate design
    [duckypad_v4_bom.xlsx, duckypad_v5_bom.xlsx, lul.brd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]
2020-05-21 refine new pcb
    [lul.brd]
2020-05-22 updated mounting plate design, refined PCB
    [lul.brd, lul.sch]
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2020-05-30 added save as button, code check fix
2020-06-04 added pixel-shifting OLED burn-in prevention
    [my_tasks.c, parser.h, temp.c]
2020-06-27 before v6
    [duckypad_v5_bom.xlsx, lul.brd, lul.sch]
2020-06-27 worked on v6 pcb
    [lul.brd, lul.sch]
2020-07-05 added demo gif
    [config.txt]
2020-08-03 fixed bom link
2020-08-07 getting ready for a new production run
    [lul.brd, lul.sch]
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2020-09-12 added numpad in sample profile
    [config.txt]
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2020-09-17 fixed UI quirks on macos, updated sample profiles to new format
    [config.txt]
2020-09-21 updated versions and revision numbers
    [duckypad_V3_rev1_bom.xlsx, duckypad_V3_rev2_bom.xlsx, duckypad_V3_rev3_bom.xlsx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]
2020-09-21 added vaporwave colours!
    [config.txt]
2020-09-28 increased max profile to 32, added checks in pc app
    [config.txt]
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2020-09-29 added sample profiles for android, iPadOS, and macOS. updated key description, added info about mac shortcuts
    [config.txt]
2020-10-01 added saving indicator, updated profiles
    [config.txt]
2020-10-19 updated version number, added rainbow color
    [config.txt]
2020-10-31 fixed a few bugs
    [main.c, my_tasks.c]
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2020-11-04 changed sample profile key color
    [config.txt]
2020-11-12 fixed a HOLD command bug
    [main.c, my_tasks.c, parser.h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]
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2020-11-20 new firmware, fixed sample profiles
    [config.txt]
2020-11-21 added english(UK) layout, fixed a small bug firmware bug to allow SHIFT and ALTGR be pressed at same time
    [config.txt]
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2020-11-25 slightly updated pcb design for new production run
    [lul.brd, lul.sch]
2020-12-04 corrected firmware version number, updated sample profiles
    [config.txt]
2020-12-05 fixed a HOLD command bug, updated getting started guide
    [main.c, my_tasks.c, parser.h]
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2020-12-05 fixed sample profile
2020-12-11 added a ASCII duck
    [config.txt]
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2021-01-08 updated silkscreen for new production run
    [lul.brd]
2021-02-08 added Finnish keymap, updated scample script
    [config.txt]
2021-02-10 fixed a bug, F13 to F24 should work now
    [my_tasks.c]
2021-02-14 fixed pyautogui bug in macos, sped up keypad sample profile
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2021-04-04 fixed MENU key, loop counter no longer resets after sleeping
    [main.c, my_tasks.c, parser.h]
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2021-04-28 added mouse sample profile
    [config.txt]
2021-05-17 increased hot swap socket pad size
    [lul.brd, lul.sch]
2021-05-22 dump to file working
    [config.txt]
2021-05-22 updated firmware version number
    [config.txt]
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2021-05-29 working on dir sync
    [config.txt]
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2021-05-29 syncing seems to be working
    [config.txt]
2021-05-29 GUI thread kinda working
    [config.txt]
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2021-06-17 tightened the switch holes
2021-06-17 trying to fix umlautes
    [main.c]
2021-06-23 Fix some issues accessing the HID device on Linux
2021-08-17 updated PCB for new production run
    [lul.brd, lul.sch]
2021-08-17 decreased profile switch animation time, updated and fixed HID comment
    [my_tasks.c]
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2021-12-23 shortened profile switchanimation time
2022-01-28 fixed a sleeping bug with profile autoswitcher
    [main.c, my_tasks.c]
2022-07-27 Fix for python libraries on Linux Mint
    The instructions [here](Running duckyPad Configurator on Linux) do not appear to work for my Linux Mint PC.
    I wanted to post how I was able to fix this. So that maybe we can update the documentation.
    Let me know your thoughts. It seemed that whenever I tried to execute the python script (duckypad_config.py) I got the following:
    sudo python3 duckypad_config.py
    Traceback (most recent call last):
    File "duckypad_config.py", line 13, in <module>
    from tkinter import *
    ModuleNotFoundError: No module named *'tkinter'*
    Once I installed tk, I would then get the error for *appdirs* then for *hid*
2022-08-08 added a fix for the 'Run this script!' button
2022-10-28 fixed the profile switching bug
2022-10-28 added new firmware with bug fix
    [main.c]
2022-11-23 updated sample profiles with EMUK
    [config.txt]
2022-11-23 fixed sample profile script
2022-12-22 fixed a minor bug
    [my_tasks.c]
2022-12-24 fixed power-on LED reset
    [animations.h, main.c]
2023-01-18 fixed a bug where STRING prints an extra space
    [animations.h, buttons.c, keyboard.h]
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2023-01-25 working on a string encoding bug
    [ds3_vm.c, ds3_vm.h]
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2023-01-25 added key repeat, fixed bug about unused keys
    [parser.h]
2023-01-26 updated error printing
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2023-01-27 fixed an animation bug
    [animations.h, ds3_vm.c, ds3_vm.h]
2023-01-27 added colour reset command
    [animations.h, ds3_vm.c, ds3_vm.h]
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2023-01-28 fixed profile change bug
    [my_tasks.c, parser.h]
2023-01-29 added LOOP replacement, working on firguring out colour saving
    [ds3_vm.c, ds3_vm.h, my_tasks.c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]
2023-01-29 fixed HID file check bug
    [config.txt]
2023-02-01 fixed HID delete bug, started duckyscript3 beta test document
    [my_tasks.c]
2023-02-03 added OLED refresh quest, still having a bug
    [main.c, my_tasks.c, parser.h]
2023-02-03 bodged OLED refresh bug
    [ds3_vm.c, ds3_vm.h, my_tasks.c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]
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2023-02-15 fixed a bug where screen doesnt update when exiting keymap selection screen
    [main.c, my_tasks.c]
2023-02-16 fixed keymap selection bug, changed loop break command to LBREAK
    [main.c, my_tasks.c]
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2023-03-29 fixed a RNG bug
    [buttons.c, ds3_vm.c, main.c]
2023-04-09 fixed a SD card timing bug
    [main.c, sd_util.c]
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2023-05-02 rearranged files for duckyscript 3 release
    [config.txt]
2023-05-09 working on pcb plate
    [top.brd, top.sch]
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2023-06-30 fixed EMUK release stuck
    [buttons.c, my_tasks.c]
2023-06-30 trying to fix bug
    [ds3_vm.c, main.c, my_tasks.c]
2023-06-30 hopefully fixed the EMUK bug
    [buttons.c, ds3_vm.c, main.c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]
2023-06-30 changed hole to 13.9mm
    [top.brd]
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2023-07-27 added pdf schematic, cleaned up files
    [duckypad_V3_rev1_bom.xlsx, duckypad_V3_rev2_bom.xlsx, duckypad_V3_rev3_bom.xlsx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]
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2023-11-11 increased max profile to 64, not sure if i want to keep it that way
    [config.txt]
2024-01-22 fixing backlight brightness bug
    [ds3_vm.c, main.c, neopixel.c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]
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2024-10-28 working on 3.1 minor revision
    [lul.brd, lul.sch]
2024-10-28 finished hw socket vias, spare header on BOOT0
    [duckypad2020_v3.1.brd, duckypad2020_v3.1.sch]
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2024-12-02 bug fix fw update
    [ds3_vm.c, main.c]
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2024-12-18 fixed dead key behaviour
    [main.c]
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2025-02-13 sd eject reset, working on profile loading
    [main.c]
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2025-02-22 LED interfering with SD bank switch
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2025-02-23 fixed slow HID speed
    [main.c]
2025-03-09 HID file open for readingh
    [config.txt]
2025-03-09 HID file open for reading
    [config.txt]
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2025-03-11 added spreadsheet, cleanup files
    [duckypad sd walk HID packet.ods]
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2025-05-09 updated sample profiles for latest firmware
    [config.txt]
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2025-06-29 fixed global variable not working, expanded to 32GVs
    [ds_vm.h, hid_task.h]
2025-07-08 fixed HID buffer clear bug
    [main.c]
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2026-01-18 porting dsvm2, compiles but not work
    [ds_vm.h, neopixel.h]
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2026-01-22 utc offset and RTC read works, has drift
    [main.c]
2026-01-26 fixed linux empty HID packet bug
    [keyboard.h]
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2026-03-01 fixed GOTO_PROFILE not working
    [main.c]
2026-03-05 new side-push buttons, new bugfix firmware
    [duckypad_evo.brd, duckypad_evo.sch]

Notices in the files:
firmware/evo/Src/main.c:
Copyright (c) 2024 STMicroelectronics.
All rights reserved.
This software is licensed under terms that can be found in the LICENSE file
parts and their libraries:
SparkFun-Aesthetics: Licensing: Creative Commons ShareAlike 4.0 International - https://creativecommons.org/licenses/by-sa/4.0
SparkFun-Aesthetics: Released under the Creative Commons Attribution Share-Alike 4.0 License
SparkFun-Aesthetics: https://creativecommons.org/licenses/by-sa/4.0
